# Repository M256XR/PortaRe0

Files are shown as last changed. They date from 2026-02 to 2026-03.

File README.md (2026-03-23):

# PortaRe0

Cubie A7Z SBCベースのクラムシェル型ポータブルPC（Cyberdeck）自作プロジェクト。

## 概要

| 項目 | 内容 |
|---|---|
| SBC | Cubie A7Z (Allwinner A733 / 8コア / WiFi6 / BT5.4) |
| ディスプレイ | 5.5" Sharp LS055R1SX04 (1440×2560 / MIPI DSI) |
| キーボード | カスタムPCB + Alps SKRPABE010 × 64キー / RP2040 / QMK |
| 入力 | 3DSスライドパッド（アナログスティック） |
| 電源 | LiPo 606090 (4200mAh) + BQ25895 充電IC + TPS61023 昇圧DC-DC ×2 |
| USBハブ | VL812 (USB 3.0 / 4ポート) |
| ストレージ | M.2 2230 NVMe SSD（PCIe Gen3 x1 / Cubie A7Z F0506-16-BGR経由） |
| オーディオ | MAX98357A × 2 (スピーカー I2S) / PCM5102A + TPA6132A2 (イヤホン DAC+アンプ) |
| MCU | RP2040 × 2（キーボード専用 / オーディオ専用） |
| PCB | 6層基板 / JLCPCB PCBA |
| 筐体 | 3Dプリンター自作（クラムシェル / 139×81mm） |

## 現在のフェーズ

**Phase 3: PCBレイアウト完了 → 発注準備完了（資金準備待ち）**

- [x] power シート（BQ25895 / TPS61023 ×2 / AP2112K）
- [x] usb_hub シート（VL812 / W25Q32 / J_EXT_C / J_EXT_A）
- [x] keyboard シート（RP2040 #1 / キーマトリクス / アナログスティック / LED）
- [x] audio シート（RP2040 #2 / MAX98357A ×2 / PCM5102A / TPA6132A2）
- [x] connectors シート（J_HDMI_CTRL / J_FAN）
- [x] hdmi_adapter シート（別基板 / Micro HDMI → FFC変換）
- [x] usb_adapter シート（別基板 / FPCスティフナー + USB-Cオス ×2）
- [x] m2_ssd シート（M.2 2230 NVMe / PCIe Gen3 x1 / RT9080 LDO）
- [x] ERC（HP系のみ残存 / 想定内）
- [x] ガーバー生成済み / CPL生成済み
- [ ] JLCPCB発注（資金準備後）

## ドキュメント

- [Claude/PROGRESS.md](./Claude/PROGRESS.md) - 現在の進捗・次のタスク
- [Claude/CLAUDE.md](./Claude/CLAUDE.md) - 仕様サマリ・セッション開始手順
- [Claude/specs/](./Claude/specs/) - ハードウェア詳細仕様（電源・キーボード・オーディオ・M.2）
- [bom/cyberdeck_bom.xlsx](./bom/cyberdeck_bom.xlsx) - BOM (Excel)
- [bom/cyberdeck_bom.csv](./bom/cyberdeck_bom.csv) - BOM (CSV)
- [keyboard/matrix.md](./keyboard/matrix.md) - キーマトリクス割り当て表
- [keyboard/info.json](./keyboard/info.json) - QMKレイアウト定義

## リポジトリ構成

```
kicad/PortaRe0/        KiCadプロジェクト（回路図・PCB）
kicad/PortaRe0_lib/    カスタムシンボル・フットプリント・3Dモデル
keyboard/              キーレイアウト・マトリクス定義・QMK設定
cad/                   筐体 3Dデータ（進行中）
docs/                  データシート
bom/                   BOM（xlsx / csv）
Claude/                設計ドキュメント・進捗ログ・セッションログ
```

## 主要部品 C番号一覧

| 部品 | 型番 | C番号 |
|---|---|---|
| 充電IC | BQ25895RTWR | C80200 |
| 昇圧DC-DC | TPS61023DRLR | C919459 |
| LDO 3.3V | AP2112K-3.3TRG1 | C51118 |
| USB HUBチップ | VL812-Q7 | C69417 |
| SPI Flash | W25Q32JVSSIQ | C82344 |
| MCU | RP2040 | C2040 |
| クリスタル（RP2040用 12MHz） | X322512MOB4SI | C70565 |
| クリスタル（VL812用 25MHz） | X322525MOB4SI | C9006 |
| I2Sアンプ | MAX98357AEWL+T | C2682619 |
| イヤホン用DAC | PCM5102APWR | C107671 |
| ヘッドフォンアンプ | TPA6132A2RTER | C69901 |
| USBパワースイッチ | TPS2042BDR | C138720 |
| USB ESD保護 | USBLC6-2SC6 | C7519 |
| キースイッチ | Alps SKRPABE010 | C115360 |
| ダイオード | 1N4148W | C2099 |
| MOSFET（レベル変換 / ファン制御） | BSS138 | C52895 |
| ショットキーダイオード（EN保護） | BAT54 | C466635 |
| FPCコネクタ（スティック用） | Molex 5034800440 | C3170007 |
| ZIF FPCコネクタ 24pin | FPC-05F-24PH20 | C2856805 |
| ZIF FPCコネクタ 16pin（PCIe） | FPC-05F-16PH20 | C2856801 |
| M.2ソケット（M-key 2230） | NASM0-S6701-TP40 | C367029 |
| LDO 3.3V（M.2用） | RT9080-33GJ5 | C841192 |
| USB-C レセプタクル（外部） | USB31-TYPE-C-FSABC | C2880583 |
| USB-A レセプタクル（外部） | HC-USB3.0-L168-WP | C7501850 |
| USB-C オス SMD（SBC接続） | 918-118A2021Y40000 | C168690 |

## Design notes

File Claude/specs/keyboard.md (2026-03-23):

# キーボード・入力・LED 詳細仕様

---

## キーボード・入力

- **RP2040 #1**（キーボード専用）C2040 / QMK対応
- スイッチ：Alps SKRPABE010（SMD タクタイル 4.2×3.2mm）× 62キー（C115360）+ 肩ボタン SKSCLDE010 × 2（C115362）= 計64キー / 手はんだ
- ダイオード：1N4148W（C2099）× 64個（キーマトリクス）
- アナログスティック：3DSスライドパッド / FPC 4ピン 1.0mmピッチ / VCC=3.3V直結OK
- FPCコネクタ：Molex 5034800440（C3170007）/ 4P 1.0mm ZIF ヒンジ式

### RP2040 #1 GPIO割り当て

| GPIO | 役割 |
|---|---|
| GP0〜GP8 | キーマトリクス COL（9本） |
| GP9〜GP16 | キーマトリクス ROW（8本） |
| GP17 | I2C_SCL（BQ25895） |
| GP18 | I2C_SDA（BQ25895） |
| GP19 | BQ_INT |
| GP20 | RP2040_EN（TPS61023 EN制御） |
| GP21 | LED_CHG（橙 / BQ25895 I2C読み） |
| GP22 | LED_FULL（緑 / BQ25895 I2C読み） |
| GP23 | LED_ACT（青 / OS動作表示） |
| GP24 | USB_VBUS_EN（TPS61023 #2 EN制御） |
| GP25 | SW_DET（電源ボタン検出 / 10kΩ分圧でVSYSを3.3V以下に変換） |
| GP26 | J_FAN PWM（BSS138 gate制御） |
| GP27（ADC1） | アナログスティック X |
| GP28（ADC2） | アナログスティック Y |
| GP29 | 予備 |

---

## LED

| LED | GPIO | C番号 | 色 | 役割 |
|-----|---|---|----|---|
| D1 | STAT直結 | C2286（KT-0603R） | 赤 | BQ25895 STAT端子直結 |
| D2 | GP23 | C19171394（YLED0603B） | 青 | LED_ACT（OS動作表示） |
| D3 | GP22 | C19273151（YLED0603G） | 緑 | LED_FULL（満充電） |
| D4 | GP21 | C19273153（YLED0603O） | 橙 | LED_CHG（充電中） |

- D2〜D4: Extended / 手はんだ対象
- 各LED: 330Ω直列抵抗 → GND / パッケージ: 0603

---

## キーマトリクス

- 構成：9COL × 8ROW / 計72セル（使用63 / 空き9）
- COL方向：縦 / ROW方向：横
- ダイオード向き：ROW → [>|] → SW → COL（カソードがSW側）
- 詳細：`keyboard/matrix.md`

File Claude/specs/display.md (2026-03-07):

# ディスプレイ・HDMIコントローラ基板 詳細仕様

---

## パネル

| 項目 | 仕様 |
|---|---|
| 型番 | Sharp LS055R1SX04（動作確認済み / session34） |
| サイズ | 5.5インチ |
| 解像度 | 1440 × 2560（縦向き） / PPI 約535 |
| 厚み | 約1.5mm（実測） |
| インターフェース | MIPI DSI 4レーン |
| 動作確認 | PC接続で正常表示確認済み（session34） |

---

## HDMIコントローラ基板

| 項目 | 仕様 |
|---|---|
### 付属ボード（動作確認済み）

| 項目 | 仕様 |
|---|---|
| 型番 | MIP-1000（Version 1.2） |
| 購入先 | AliExpress（LS055R1SX04とセット） |
| ブリッジチップ | TC358870XBG（Renesas / 旧Toshiba）/ HDMI 1.4 → MIPI DSI 4レーン |
| 映像入力 | HDMI（フルサイズ） |
| 給電 | Micro-B USB 5V |
| 対応解像度 | 1440×2560 固定（他解像度では正常動作しない） |
| リフレッシュレート | 1440×2560 @ 50Hz（60Hzは出力不可） |
| HDR | 非対応 |
| LED動作 | 映像検知時：青点滅 / 待機時：青ゆっくり点滅 / 映像出力時：緑点灯 |
| 明るさ調整 | ハードウェアボタン5〜6段階（明→暗→明のサイクル）/ RP2040制御不可 |
| リセットボタン | あり |
| スマホ接続 | 不可（解像度固定のため） |

### 組み込み候補ボード（VS-CXMIPI / Version 3.2）

| 項目 | 仕様 |
|---|---|
| 型番 | D000118-VS-CXMIPI-V1-50Hz（Version 3.2） |
| サイズ | 70 × 40 × 5mm（付属ボード65×65mmより小型） |
| ブリッジチップ | TC358870XBG（同じ） |
| 映像入力 | HDMI（フルサイズ） |
| 給電① | Mini USB 5V（給電専用・データラインなし） |
| 給電② | Micro USB 5V（給電専用・データラインなし） |
| 給電③ | **5V〜12V スルーホール（直はんだ可・組み込みに最適）** |
| MIPIコネクタ | 60pin ZIF（右上端） |
| テストポイント | RST / DA / CK / G / 3.3V / G / RX / TX / 5V |
| I2C | DA=SDA / CK=SCL（TC358870XBG設定用・RP2040制御の可能性あり） |
| UART | RX / TX（デバッグ用と推定） |
| サブMCU | N76E003A120（Nuvoton 8051コア）/ ボタン処理 + TC358870XBG初期化・輝度制御 |
| DA/CK | ICE_DAT/ICE_CLK（N76E003書き込み/デバッグピン）/ I2CではなくNuvoton専用 |
| RX/TX | UART 3.3Vロジック / 起動ログ・コマンド制御の可能性あり |
| 音声出力 | スピーカー + イヤホン出力あり |

---

## PortaRe0への組み込み方法

- HDMIコネクタを撤去し、24pin FPCコネクタを半田付け
- FFC経由でメインPCBの J_SBC_HDMI（C2856805）に接続
- Micro-B 5V給電 → FPC経由で5V_SYSから供給
- KiCad: hdmi_adapterシートで設計済み

---

## 注意事項

- スマホからのHDMI出力では正常表示不可（解像度固定のため）
- Cubie A7Zで1440×2560出力すれば問題なし
- VS-CXMIPI採用の場合、UART（RX/TX 3.3V）でコマンド制御できる可能性あり → 届いたらESP32-S3でTeraTerm接続してログ確認（ボーレート115200 or 9600）
- DA/CKはI2CではなくN76E003のICEデバッグピン（書き込み用）
- UART制御不可の場合はLEDドライバICのPWMピンを物理ハック（IC型番要確認）
- VS-CXMIPI採用の場合、5V〜12Vスルーホールから5V_SYS直接給電可能（Micro-Bコネクタ不要）
- 付属ボードを使う場合、明るさ調整ボタンを筐体外部に引き出す必要あり

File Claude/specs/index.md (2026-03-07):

# PortaRe0 ハードウェア仕様 索引

> 詳細仕様は各ファイルを参照。信頼優先順位: 原文ログ > specs/* > CLAUDE.md > PROGRESS.md

---

## 詳細ファイル一覧

| ファイル | 内容 |
|---|---|
| [power.md](./power.md) | 電源系・USBハブ・外部USBポート構成 |
| [keyboard.md](./keyboard.md) | キーボード・RP2040 #1 GPIO・アナログスティック・LED |
| [audio.md](./audio.md) | オーディオ・RP2040 #2 GPIO・信号フロー |
| [m2_ssd.md](./m2_ssd.md) | M.2 SSD・PCIe FPC接続・LDO |
| [display.md](./display.md) | ディスプレイ・HDMIコントローラ基板・組み込み方法 |

---

## コンポーネント概要

| カテゴリ | 部品 | 型番 / 備考 |
|---|---|---|
| SBC | Cubie A7Z | Allwinner A733 / 8コア / WiFi6 / BT5.4 |
| ディスプレイ | Sharp LS055R1SX04 | 5.5" / 1440×2560 / MIPI DSI 4レーン |
| 充電IC | BQ25895RTWR | C80200 / USB PD / バッテリー保護内蔵 |
| 昇圧DC-DC | TPS61023DRLR ×2 | C919459 / 5V_SYS / USB_5V_SYS |
| LDO 3.3V | AP2112K-3.3TRG1 | C51118 / RP2040用 |
| バッテリー | LiPo 606090 | 4200mAh / 3.7V |
| バッテリーコネクタ | BM06B-ACHFKS-GACN-ETF | JST ACH 6pin / 実装高1.43mm / 7.5A / DigiKey別途購入・手はんだ |
| USBハブ | VL812-Q7 | C69417 / USB3.0 4ポート |
| MCU | RP2040 ×2 | C2040 / #1=キーボード / #2=オーディオ |
| キースイッチ | Alps SKRPABE010 | C115360 / 63キー |
| アナログスティック | 3DSスライドパッド | FPC 4ピン 1.0mmピッチ |
| I2Sアンプ | MAX98357AEWL+T ×2 | C2682619 / スピーカー用 |
| イヤホンDAC | PCM5102APWR | C107671 |
| HPアンプ | TPA6132A2RTER | C69901 |
| M.2ソケット | NASM0-S6701-TP40 | C367029 / M-key / 2230 |
| M.2 LDO | RT9080-33GJ5 | C841192 / 3V3_M2レール |

---

## 筐体仕様

| 項目 | 仕様 |
|---|---|
| フォームファクタ | クラムシェル（ヒンジ構造） |
| ボトム外形 | 139 × 81 mm |
| PCBボード | 135 × 77 mm（各辺2mmクリアランス） |
| 素材 | 3Dプリンター（FDM or SLA） |
| ディスプレイ向き | 縦向きパネルを縦で使用 |

---

## PCB仕様

| 項目 | 仕様 |
|---|---|
| 層数 | 6層 |
| スタックアップ | F.Cu（COL+スイッチ）/ In1（GND）/ In2（IC配線+ROW）/ In3（電源ゾーン+IC配線）/ In4（GND）/ B.Cu（IC実装+IC配線+高速差動ペア） |
| 製造 | JLCPCB（PCBA込み） |
| HDMI 差動ペア | 90Ω / 等長配線 |
| USB3.0 SS 差動ペア | 90Ω |
| PCIe Gen3 差動ペア（M.2） | 90Ω / 等長配線 |

---

## 冷却

- 方式：パッシブ（ヒートパイプ + 小型ヒートシンク）
- ヒートパイプ：3mm厚フラット銅製 / SoC → 90度曲げ → バッテリー上端の隙間（幅16mm）を通過
- ヒートシンク：14×9×4mm 程度 × 4個
- ファン：RP2040 #1 GP26（FAN_PWM）→ BSS138 → J6（2pin JST PH）

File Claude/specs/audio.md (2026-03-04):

# オーディオ 詳細仕様

---

## 構成部品

- **RP2040 #2**（オーディオ専用）C2040 / VL812 DP4経由
- **MAX98357AEWL+T × 2**（C2682619）スピーカー用ステレオI2Sアンプ
- **PCM5102APWR**（C107671）イヤホン用ステレオDAC / TSSOP-20
- **TPA6132A2RTER**（C69901）イヤホン用ヘッドフォンアンプ / WQFN-16
- スピーカー：Nintendo Switch互換品 8Ω 20×14×4mm × 2個（L/R）
- イヤホンジャック：PJ-307C（C16684 / TH 5pin）

### イヤホンジャック ピン配置

| ピン | 接続 | 備考 |
|---|---|---|
| Pin1 | GND | Sleeve |
| Pin2 | HP_L | L Tip |
| Pin3 | NC | L SW（Pin2ペア） |
| Pin4 | HP_DET（GP6 + 100kΩ pull-up） | 未挿入=LOW / 挿入=HIGH |
| Pin5 | HP_R | R Ring |

---

## RP2040 #2 GPIO割り当て

| GPIO | 役割 |
|---|---|
| GP0 | I2S BCLK |
| GP1 | I2S LRCLK |
| GP2 | I2S SDIN |
| GP3 | SD_MODE制御（MAX98357A × 2 / U8=直結=Left / U15=220kΩ直列=Right） |
| GP4 | XSMT（PCM5102A ミュート制御） |
| GP5 | HP_EN（TPA6132A2 Enable） |
| GP6 | HP_DET（イヤホン挿入検出） |
| GP7〜GP29 | 予備 |

---

## 信号フロー

```
Cubie A7Z USB → VL812 DP4 → RP2040 #2（USB Audio）
RP2040 #2 I2S ─┬─→ MAX98357A × 2 → スピーカー L/R
                └─→ PCM5102A（DAC）→ TPA6132A2 → 3.5mmジャック
GP3: スピーカーON/OFF（SD_MODE）
GP4: DAC ミュート（XSMT）
GP5: HPアンプ Enable
GP6: 挿入検出 → GP3/GP4/GP5をソフト制御
```

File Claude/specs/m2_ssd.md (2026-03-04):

# M.2 SSD 詳細仕様

---

## 構成

- **M.2ソケット**: NASM0-S6701-TP40（C367029）M-key / 2230対応
- **PCIeインターフェース**: Cubie A7Z F0506-16-BGR（16pin 0.5mm FPC / RPi5互換）→ PCIe Gen3 x1
- **FPCコネクタ**: FPC-05F-16PH20（C2856801）16pin 0.5mm ZIF
- **電源**: RT9080-33GJ5（C841192）600mA LDO / 5V_SYS → 3V3_M2（AP2112K とは別レール）

---

## FPC → M.2 ピン接続

| FPC Pin | 信号 | 接続 | M.2 Pin |
|---|---|---|---|
| Pin2 | PCIE_TX_P | → 100nF → | Pin43 (PERp0) |
| Pin3 | PCIE_TX_N | → 100nF → | Pin41 (PERn0) |
| Pin5 | PCIE_RX_P | 直結 | Pin49 (PETp0) |
| Pin6 | PCIE_RX_N | 直結 | Pin47 (PETn0) |
| Pin8 | PCIE_REFCLK_P | 直結 | Pin55 (REFCLKP) |
| Pin9 | PCIE_REFCLK_N | 直結 | Pin53 (REFCLKN) |
| Pin11 | PCIE_PERST_N | 直結 | Pin50 (PERST#) |
| Pin12 | PCIE_CLKREQ_N | + 10kΩ → 3V3_M2 | Pin52 (CLKREQ#) |
| Pin13 | PCIE_WAKE_N | + 10kΩ → 3V3_M2 | Pin54 (PEWAKE#) |

- 3V3_M2 → M.2 Pin: 2, 4, 12, 14, 16, 18, 70, 72, 74
- M.2 Pin 42/44/46/48/56 = NC（SATAピン / PCIe x1では未使用）

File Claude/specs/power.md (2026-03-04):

# 電源・USBハブ 詳細仕様

---

## 電源系

| 部品 | 型番 | C番号 | 役割 |
|---|---|---|---|
| 充電IC | BQ25895RTWR | C80200 | USB PD充電 / バッテリー保護内蔵 |
| 昇圧DC-DC #1 | TPS61023DRLR | C919459 | LiPo → 5V_SYS（システム用） |
| 昇圧DC-DC #2 | TPS61023DRLR | C919459 | LiPo → USB_5V_SYS（外部USBポートVBUS専用） |
| LDO | AP2112K-3.3TRG1 | C51118 | 5V → 3.3V（RP2040用） |
| バッテリー | LiPo 606090 | — | 4200mAh / 3.7V |

### 電源フロー

```
USB-C (充電) → BQ25895 → LiPo 4.2V
LiPo SYS出力 → TPS61023 #1 → 5V_SYS → Cubie A7Z / VL812 / HDMIコントローラ基板
LiPo SYS出力 → TPS61023 #2 → USB_5V_SYS → 外部USBポートVBUS（RP2040 #1 GP24でEN制御）
5V_SYS → AP2112K → 3.3V（RP2040用）
5V_SYS → RT9080 → 3V3_M2（M.2 SSD用）
```

> 注意: BQ25895 SYSラインは最大5〜6A → PCBパターン極太必須

### 電源スイッチ

- 起動：モーメンタリボタン（SKSCLBE010 C115361）→ TPS61023 EN ピン High
- 通常OFF：SBC GPIO → EN Low（shutdown フック）
- 緊急キル：MSK12C02（C431540）スライドSW → EN 強制 Low

---

## USBハブ（VL812）

- **VL812-Q7**（QFN-76-EP 9x9）C69417
- 外付け：W25Q32JVSSIQ SPI Flash（C82344）/ 25MHz水晶 X322525MOB4SI（C9006）/ SSREXT 6.04kΩ

### USB接続構成

```
Cubie A7Z USB-C (USB3.0) → VL812 upstream
VL812 downstream 1 → 外部USB-C レセプタクル（TPS2042BDR / USBLC6-2SC6）
VL812 downstream 2 → 外部USB-A レセプタクル（TPS2042BDR / USBLC6-2SC6）
VL812 downstream 3 → RP2040 #1（キーボード）
VL812 downstream 4 → RP2040 #2（オーディオ）
Cubie A7Z USB-C (USB2.0) → BQ25895（充電入力 / 刻印:PWR）
Cubie A7Z Micro HDMI → HDMIコントローラ基板
```

### 外部USBポート電源構成

- TPS2042BDR（C138720）: VL812 /USBHPE制御 / /USBHOC過電流検知
- USBLC6-2SC6（C7519）: Port1/2各1個 ESD保護
- 外部VBUS専用 TPS61023 #2（USB_5V_SYS）: RP2040 #1 GP24で制御
- 注意: 外部USBポートはデータ転送・小型デバイス用（HDD等大電流機器は非推奨）

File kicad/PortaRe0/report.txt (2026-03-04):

情報: シンボル 'C1:Capacitor_SMD:C_0603_1608Metric' を処理中です。
情報: シンボル 'C2:Capacitor_SMD:C_0603_1608Metric' を処理中です。
情報: シンボル 'C3:Capacitor_SMD:C_0603_1608Metric' を処理中です。
情報: シンボル 'C4:Capacitor_SMD:C_0603_1608Metric' を処理中です。
情報: シンボル 'C5:Capacitor_SMD:C_0603_1608Metric' を処理中です。
情報: シンボル 'C6:Capacitor_SMD:C_0603_1608Metric' を処理中です。
情報: シンボル 'C7:Capacitor_SMD:C_0603_1608Metric' を処理中です。
情報: シンボル 'C8:Capacitor_SMD:C_0603_1608Metric' を処理中です。
情報: シンボル 'C9:Capacitor_SMD:C_0603_1608Metric' を処理中です。
情報: シンボル 'C10:Capacitor_SMD:C_0603_1608Metric' を処理中です。
情報: シンボル 'C11:Capacitor_SMD:C_0603_1608Metric' を処理中です。
情報: シンボル 'C12:Capacitor_SMD:C_0603_1608Metric' を処理中です。
情報: シンボル 'C13:Capacitor_SMD:C_0603_1608Metric' を処理中です。
情報: シンボル 'C14:Capacitor_SMD:C_0603_1608Metric' を処理中です。
情報: シンボル 'C15:Capacitor_SMD:C_0603_1608Metric' を処理中です。
情報: シンボル 'C16:Capacitor_SMD:C_0603_1608Metric' を処理中です。
情報: シンボル 'C17:Capacitor_SMD:C_0603_1608Metric' を処理中です。
情報: シンボル 'C18:Capacitor_SMD:C_0603_1608Metric' を処理中です。
情報: シンボル 'C19:Capacitor_SMD:C_0603_1608Metric' を処理中です。
情報: シンボル 'C20:Capacitor_SMD:C_0603_1608Metric' を処理中です。
情報: シンボル 'C21:Capacitor_SMD:C_0603_1608Metric' を処理中です。
情報: シンボル 'C22:Capacitor_SMD:C_0603_1608Metric' を処理中です。
情報: シンボル 'C23:Capacitor_SMD:C_0603_1608Metric' を処理中です。
情報: シンボル 'C24:Capacitor_SMD:C_0603_1608Metric' を処理中です。
情報: シンボル 'C25:Capacitor_SMD:C_0603_1608Metric' を処理中です。
情報: シンボル 'C26:Capacitor_SMD:C_0603_1608Metric' を処理中です。
情報: シンボル 'C27:Capacitor_SMD:C_0603_1608Metric' を処理中です。
情報: シンボル 'C28:Capacitor_SMD:C_0603_1608Metric' を処理中です。
情報: シンボル 'C29:Capacitor_SMD:C_0603_1608Metric' を処理中です。
情報: シンボル 'C30:Capacitor_SMD:C_0603_1608Metric' を処理中です。
情報: シンボル 'C31:Capacitor_SMD:C_0603_1608Metric' を処理中です。
情報: シンボル 'C32:Capacitor_SMD:C_0603_1608Metric' を処理中です。
情報: シンボル 'C33:Capacitor_SMD:C_0603_1608Metric' を処理中です。
情報: シンボル 'C34:Capacitor_SMD:C_0603_1608Metric' を処理中です。
情報: シンボル 'C36:Capacitor_SMD:C_0603_1608Metric' を処理中です。
情報: シンボル 'C38:Capacitor_SMD:C_0603_1608Metric' を処理中です。
情報: シンボル 'C41:Capacitor_SMD:C_0603_1608Metric' を処理中です。
情報: シンボル 'C42:Capacitor_SMD:C_0603_1608Metric' を処理中です。
情報: シンボル 'C44:Capacitor_SMD:C_0603_1608Metric' を処理中です。
情報: シンボル 'C46:Capacitor_SMD:C_0603_1608Metric' を処理中です。
情報: シンボル 'C47:Capacitor_SMD:C_0603_1608Metric' を処理中です。
情報: シンボル 'C48:Capacitor_SMD:C_0603_1608Metric' を処理中です。
情報: シンボル 'C49:Capacitor_SMD:C_0603_1608Metric' を処理中です。
情報: シンボル 'C50:Capacitor_SMD:C_0603_1608Metric' を処理中です。
情報: シンボル 'C51:Capacitor_SMD:C_0603_1608Metric' を処理中です。
情報: シンボル 'C52:Capacitor_SMD:C_0603_1608Metric' を処理中です。
情報: シンボル 'C53:Capacitor_SMD:C_0603_1608Metric' を処理中です。
情報: シンボル 'C54:Capacitor_SMD:C_0603_1608Metric' を処理中です。
情報: シンボル 'C55:Capacitor_SMD:C_0603_1608Metric' を処理中です。
情報: シンボル 'C56:Capacitor_SMD:C_0603_1608Metric' を処理中です。
情報: シンボル 'C57:Capacitor_SMD:C_0603_1608Metric' を処理中です。
情報: シンボル 'C58:Capacitor_SMD:C_0603_1608Metric' を処理中です。
情報: シンボル 'C59:Capacitor_SMD:C_0603_1608Metric' を処理中です。
情報: シンボル 'C60:Capacitor_SMD:C_0603_1608Metric' を処理中です。
情報: シンボル 'C61:Capacitor_SMD:C_0603_1608Metric' を処理中です。
情報: シンボル 'C62:Capacitor_SMD:C_0603_1608Metric' を処理中です。
情報: シンボル 'C63:Capacitor_SMD:C_0603_1608Metric' を処理中です。
情報: シンボル 'C64:Capacitor_SMD:C_0603_1608Metric' を処理中です。
情報: シンボル 'C65:Capacitor_SMD:C_0603_1608Metric' を処理中です。
情報: シンボル 'C66:Capacitor_SMD:C_0603_1608Metric' を処理中です。
情報: シンボル 'C67:Capacitor_SMD:C_0603_1608Metric' を処理中です。
情報: シンボル 'C68:Capacitor_SMD:C_0603_1608Metric' を処理中です。
情報: シンボル 'C69:Capacitor_SMD:C_0603_1608Metric' を処理中です。
情報: シンボル 'C70:Capacitor_SMD:C_0603_1608Metric' を処理中です。
情報: シンボル 'C71:Capacitor_SMD:C_0603_1608Metric' を処理中です。
情報: シンボル 'C72:Capacitor_SMD:C_0603_1608Metric' を処理中です。
情報: シンボル 'C73:Capacitor_SMD:C_0603_1608Metric' を処理中です。
情報: シンボル 'C74:Capacitor_SMD:C_0603_1608Metric' を処理中です。
情報: シンボル 'C75:Capacitor_SMD:C_0603_1608Metric' を処理中です。
情報: シンボル 'C76:Capacitor_SMD:C_0603_1608Metric' を処理中です。
情報: シンボル 'C77:Capacitor_SMD:C_0603_1608Metric' を処理中です。
情報: シンボル 'C78:Capacitor_SMD:C_0603_1608Metric' を処理中です。
情報: シンボル 'C79:Capacitor_SMD:C_0603_1608Metric' を処理中です。
情報: シンボル 'C80:Capacitor_SMD:C_0603_1608Metric' を処理中です。
情報: シンボル 'C81:Capacitor_SMD:C_0603_1608Metric' を処理中です。
情報: シンボル 'C82:Capacitor_SMD:C_0603_1608Metric' を処理中です。
情報: シンボル 'C83:Capacitor_SMD:C_0603_1608Metric' を処理中です。
情報: シンボル 'C84:Capacitor_SMD:C_0603_1608Metric' を処理中です。
情報: シンボル 'C85:Capacitor_SMD:C_0603_1608Metric' を処理中です。
情報: シンボル 'C86:Capacitor_SMD:C_0603_1608Metric' を処理中です。
情報: シンボル 'C87:Capacitor_SMD:C_0603_1608Metric' を処理中です。
情報: シンボル 'C88:Capacitor_SMD:C_0603_1608Metric' を処理中です。
情報: シンボル 'C89:Capacitor_SMD:C_0603_1608Metric' を処理中です。
情報: シンボル 'C90:Capacitor_SMD:C_0603_1608Metric' を処理中です。
情報: シンボル 'C91:Capacitor_SMD:C_0603_1608Metric' を処理中です。
情報: シンボル 'C92:Capacitor_SMD:C_0603_1608Metric' を処理中です。
情報: シンボル 'C93:Capacitor_SMD:C_0603_1608Metric' を処理中です。
情報: シンボル 'C94:Capacitor_SMD:C_0603_1608Metric' を処理中です。
情報: シンボル 'C95:Capacitor_SMD:C_0603_1608Metric' を処理中です。
情報: シンボル 'C96:Capacitor_SMD:C_0603_1608Metric' を処理中です。
情報: シンボル 'C97:Capacitor_SMD:C_0603_1608Metric' を処理中です。
情報: シンボル 'C98:Capacitor_SMD:C_0603_1608Metric' を処理中です。
情報: シンボル 'C99:Capacitor_SMD:C_0603_1608Metric' を処理中です。
情報: シンボル 'C100:Capacitor_SMD:C_0603_1608Metric' を処理中です。
情報: シンボル 'C101:Capacitor_SMD:C_0603_1608Metric' を処理中です。
情報: シンボル 'C102:Capacitor_SMD:C_0603_1608Metric' を処理中です。
情報: シンボル 'C103:Capacitor_SMD:C_0603_1608Metric' を処理中です。
情報: シンボル 'C104:Capacitor_SMD:C_0603_1608Metric' を処理中です。
情報: シンボル 'C105:Capacitor_SMD:C_0603_1608Metric' を処理中です。
情報: シンボル 'C106:Capacitor_SMD:C_0603_1608Metric' を処理中です。
情報: シンボル 'C107:Capacitor_Tantalum_SMD:CP_EIA-3528-21_Kemet-B_HandSolder' を処理中です。
情報: シンボル 'C108:Capacitor_Tantalum_SMD:CP_EIA-3528-21_Kemet-B_HandSolder' を処理中です。
情報: シンボル 'C109:Capacitor_SMD:C_0603_1608Metric' を処理中です。
情報: シンボル 'C110:Capacitor_SMD:C_0603_1608Metric' を処理中です。
情報: シンボル 'C111:Capacitor_SMD:C_0603_1608Metric' を処理中です。
情報: シンボル 'C112:Capacitor_SMD:C_0603_1608Metric' を処理中です。
情報: シンボル 'C113:Capacitor_SMD:C_0603_1608Metric' を処理中です。
情報: シンボル 'C114:Capacitor_SMD:C_0603_1608Metric' を処理中です。
情報: シンボル 'C115:Capacitor_SMD:C_0603_1608Metric' を処理中です。
情報: シンボル 'C116:Capacitor_SMD:C_0603_1608Metric' を処理中です。
情報: シンボル 'C117:Capacitor_SMD:C_0603_1608Metric' を処理中です。
情報: シンボル 'C118:Capacitor_SMD:C_0603_1608Metric' を処理中です。
情報: シンボル 'C119:Capacitor_SMD:C_0603_1608Metric' を処理中です。
情報: シンボル 'CN1:PortaRe0:CONN-SMD_67P-P0.50-V_NXSM0-S67XX-XX40' を処理中です。
情報: シンボル 'D1:LED_SMD:LED_0603_1608Metric' を処理中です。
情報: シンボル 'D2:LED_SMD:LED_0603_1608Metric' を処理中です。
情報: シンボル 'D3:LED_SMD:LED_0603_1608Metric' を処理中です。
情報: シンボル 'D4:LED_SMD:LED_0603_1608Metric' を処理中です。
情報: シンボル 'D5:PortaRe0:SOT-23-6_L2.9-W1.6-P0.95-LS2.8-BL' を処理中です。
情報: シンボル 'D6:PortaRe0:SOT-23-6_L2.9-W1.6-P0.95-LS2.8-BL' を処理中です。
情報: シンボル 'D7:PortaRe0:SOT-23-3_L2.9-W1.4-P1.90-LS2.6-BR' を処理中です。
情報: シンボル 'D8:PortaRe0:SOT-23-3_L2.9-W1.4-P1.90-LS2.6-BR' を処理中です。
情報: シンボル 'D9:PortaRe0:SOD-123_L2.8-W1.8-LS3.7-RD' を処理中です。
情報: シンボル 'FPC1:PortaRe0:FPC-SMD_24P-P0.50_FPC-05F-24PH20' を処理中です。
情報: シンボル 'FPC2:PortaRe0:FPC-SMD_24P-P0.50_FPC-05F-24PH20' を処理中です。
情報: シンボル 'FPC4:PortaRe0:FPC-SMD_24P-P0.50_FPC-05F-24PH20' を処理中です。
情報: シンボル 'FPC5:PortaRe0:FPC-SMD_24P-P0.50_FPC-05F-24PH20' を処理中です。
情報: シンボル 'FPC6:PortaRe0:FPC-SMD_16P-P0.50_FPC-05F-16PH20' を処理中です。
情報: シンボル 'J1:PortaRe0:FPC-SMD_5034800400' を処理中です。
情報: シンボル 'Y2:PortaRe0:CRYSTAL-SMD_4P-L3.2-W2.5-BL' を処理中です。
情報: シンボル 'Y4:PortaRe0:CRYSTAL-SMD_4P-L3.2-W2.5-BL' を処理中です。
情報: シンボル 'J2:PortaRe0:CONN-TH_S2B-PH-K-S-LF-SN' を処理中です。
情報: シンボル 'J3:PortaRe0:CONN-TH_S2B-PH-K-S-LF-SN' を処理中です。
情報: シンボル 'J4:PortaRe0:CONN-TH_S8B-PH-K-S-LF-SN' を処理中です。
情報: シンボル 'J6:PortaRe0:CONN-TH_S2B-PH-K-S-LF-SN' を処理中です。
情報: シンボル 'J9:PortaRe0:AUDIO-TH_PJ307C' を処理中です。
情報: シンボル 'K_SW1:PortaRe0:KEY-SMD_4P-SKSCLXX010' を処理中です。
情報: シンボル 'K_SW2:PortaRe0:KEY-SMD_4P-SKSCLXX010' を処理中です。
情報: シンボル 'K_SW3:PortaRe0:KEY-SMD_4P-L4.2-W3.2-P2.20-LS4.6' を処理中です。
情報: シンボル 'K_SW4:PortaRe0:KEY-SMD_4P-L4.2-W3.2-P2.20-LS4.6' を処理中です。
情報: シンボル 'K_SW5:PortaRe0:KEY-SMD_4P-L4.2-W3.2-P2.20-LS4.6' を処理中です。
情報: シンボル 'K_SW6:PortaRe0:KEY-SMD_4P-L4.2-W3.2-P2.20-LS4.6' を処理中です。
情報: シンボル 'K_SW7:PortaRe0:KEY-SMD_4P-L4.2-W3.2-P2.20-LS4.6' を処理中です。
情報: シンボル 'K_SW8:PortaRe0:KEY-SMD_4P-L4.2-W3.2-P2.20-LS4.6' を処理中です。
情報: シンボル 'K_SW9:PortaRe0:KEY-SMD_4P-L4.2-W3.2-P2.20-LS4.6' を処理中です。
情報: シンボル 'K_SW10:PortaRe0:KEY-SMD_4P-L4.2-W3.2-P2.20-LS4.6' を処理中です。
情報: シンボル 'K_SW11:PortaRe0:KEY-SMD_4P-L4.2-W3.2-P2.20-LS4.6' を処理中です。
情報: シンボル 'K_SW12:PortaRe0:KEY-SMD_4P-L4.2-W3.2-P2.20-LS4.6' を処理中です。
情報: シンボル 'K_SW13:PortaRe0:KEY-SMD_4P-L4.2-W3.2-P2.20-LS4.6' を処理中です。
情報: シンボル 'K_SW14:PortaRe0:KEY-SMD_4P-L4.2-W3.2-P2.20-LS4.6' を処理中です。
情報: シンボル 'K_SW15:PortaRe0:KEY-SMD_4P-L4.2-W3.2-P2.20-LS4.6' を処理中です。
情報: シンボル 'K_SW16:PortaRe0:KEY-SMD_4P-L4.2-W3.2-P2.20-LS4.6' を処理中です。
情報: シンボル 'K_SW17:PortaRe0:KEY-SMD_4P-L4.2-W3.2-P2.20-LS4.6' を処理中です。
情報: シンボル 'K_SW18:PortaRe0:KEY-SMD_4P-L4.2-W3.2-P2.20-LS4.6' を処理中です。
情報: シンボル 'K_SW19:PortaRe0:KEY-SMD_4P-L4.2-W3.2-P2.20-LS4.6' を処理中です。
情報: シンボル 'K_SW20:PortaRe0:KEY-SMD_4P-L4.2-W3.2-P2.20-LS4.6' を処理中です。
情報: シンボル 'K_SW21:PortaRe0:KEY-SMD_4P-L4.2-W3.2-P2.20-LS4.6' を処理中です。
情報: シンボル 'K_SW22:PortaRe0:KEY-SMD_4P-L4.2-W3.2-P2.20-LS4.6' を処理中です。
情報: シンボル 'K_SW23:PortaRe0:KEY-SMD_4P-L4.2-W3.2-P2.20-LS4.6' を処理中です。
情報: シンボル 'K_SW24:PortaRe0:KEY-SMD_4P-L4.2-W3.2-P2.20-LS4.6' を処理中です。
情報: シンボル 'K_SW25:PortaRe0:KEY-SMD_4P-L4.2-W3.2-P2.20-LS4.6' を処理中です。
情報: シンボル 'K_SW26:PortaRe0:KEY-SMD_4P-L4.2-W3.2-P2.20-LS4.6' を処理中です。
情報: シンボル 'K_SW27:PortaRe0:KEY-SMD_4P-L4.2-W3.2-P2.20-LS4.6' を処理中です。
情報: シンボル 'K_SW28:PortaRe0:KEY-SMD_4P-L4.2-W3.2-P2.20-LS4.6' を処理中です。
情報: シンボル 'K_SW29:PortaRe0:KEY-SMD_4P-L4.2-W3.2-P2.20-LS4.6' を処理中です。
情報: シンボル 'K_SW30:PortaRe0:KEY-SMD_4P-L4.2-W3.2-P2.20-LS4.6' を処理中です。
情報: シンボル 'K_SW31:PortaRe0:KEY-SMD_4P-L4.2-W3.2-P2.20-LS4.6' を処理中です。
情報: シンボル 'K_SW32:PortaRe0:KEY-SMD_4P-L4.2-W3.2-P2.20-LS4.6' を処理中です。
情報: シンボル 'K_SW33:PortaRe0:KEY-SMD_4P-L4.2-W3.2-P2.20-LS4.6' を処理中です。
情報: シンボル 'K_SW34:PortaRe0:KEY-SMD_4P-L4.2-W3.2-P2.20-LS4.6' を処理中です。
情報: シンボル 'K_SW35:PortaRe0:KEY-SMD_4P-L4.2-W3.2-P2.20-LS4.6' を処理中です。
情報: シンボル 'K_SW36:PortaRe0:KEY-SMD_4P-L4.2-W3.2-P2.20-LS4.6' を処理中です。
情報: シンボル 'K_SW37:PortaRe0:KEY-SMD_4P-L4.2-W3.2-P2.20-LS4.6' を処理中です。
情報: シンボル 'K_SW38:PortaRe0:KEY-SMD_4P-L4.2-W3.2-P2.20-LS4.6' を処理中です。
情報: シンボル 'K_SW39:PortaRe0:KEY-SMD_4P-L4.2-W3.2-P2.20-LS4.6' を処理中です。
情報: シンボル 'K_SW40:PortaRe0:KEY-SMD_4P-L4.2-W3.2-P2.20-LS4.6' を処理中です。
情報: シンボル 'K_SW41:PortaRe0:KEY-SMD_4P-L4.2-W3.2-P2.20-LS4.6' を処理中です。
情報: シンボル 'K_SW42:PortaRe0:KEY-SMD_4P-L4.2-W3.2-P2.20-LS4.6' を処理中です。
情報: シンボル 'K_SW43:PortaRe0:KEY-SMD_4P-L4.2-W3.2-P2.20-LS4.6' を処理中です。
情報: シンボル 'K_SW44:PortaRe0:KEY-SMD_4P-L4.2-W3.2-P2.20-LS4.6' を処理中です。
情報: シンボル 'K_SW45:PortaRe0:KEY-SMD_4P-L4.2-W3.2-P2.20-LS4.6' を処理中です。
情報: シンボル 'K_SW46:PortaRe0:KEY-SMD_4P-L4.2-W3.2-P2.20-LS4.6' を処理中です。
情報: シンボル 'K_SW47:PortaRe0:KEY-SMD_4P-L4.2-W3.2-P2.20-LS4.6' を処理中です。
情報: シンボル 'K_SW48:PortaRe0:KEY-SMD_4P-L4.2-W3.2-P2.20-LS4.6' を処理中です。
情報: シンボル 'K_SW49:PortaRe0:KEY-SMD_4P-L4.2-W3.2-P2.20-LS4.6' を処理中です。
情報: シンボル 'K_SW50:PortaRe0:KEY-SMD_4P-L4.2-W3.2-P2.20-LS4.6' を処理中です。
情報: シンボル 'K_SW51:PortaRe0:KEY-SMD_4P-L4.2-W3.2-P2.20-LS4.6' を処理中です。
情報: シンボル 'K_SW52:PortaRe0:KEY-SMD_4P-L4.2-W3.2-P2.20-LS4.6' を処理中です。
情報: シンボル 'K_SW53:PortaRe0:KEY-SMD_4P-L4.2-W3.2-P2.20-LS4.6' を処理中です。
情報: シンボル 'K_SW54:PortaRe0:KEY-SMD_4P-L4.2-W3.2-P2.20-LS4.6' を処理中です。
情報: シンボル 'K_SW55:PortaRe0:KEY-SMD_4P-L4.2-W3.2-P2.20-LS4.6' を処理中です。
情報: シンボル 'K_SW56:PortaRe0:KEY-SMD_4P-L4.2-W3.2-P2.20-LS4.6' を処理中です。
情報: シンボル 'K_SW57:PortaRe0:KEY-SMD_4P-L4.2-W3.2-P2.20-LS4.6' を処理中です。
情報: シンボル 'K_SW58:PortaRe0:KEY-SMD_4P-L4.2-W3.2-P2.20-LS4.6' を処理中です。
情報: シンボル 'K_SW59:PortaRe0:KEY-SMD_4P-L4.2-W3.2-P2.20-LS4.6' を処理中です。
情報: シンボル 'K_SW60:PortaRe0:KEY-SMD_4P-L4.2-W3.2-P2.20-LS4.6' を処理中です。
情報: シンボル 'K_SW61:PortaRe0:KEY-SMD_4P-L4.2-W3.2-P2.20-LS4.6' を処理中です。
情報: シンボル 'K_SW62:PortaRe0:KEY-SMD_4P-L4.2-W3.2-P2.20-LS4.6' を処理中です。
情報: シンボル 'K_SW63:PortaRe0:KEY-SMD_4P-L4.2-W3.2-P2.20-LS4.6' を処理中です。
情報: シンボル 'K_SW64:PortaRe0:KEY-SMD_4P-L4.2-W3.2-P2.20-LS4.6' を処理中です。
情報: シンボル 'K_SW65:PortaRe0:KEY-SMD_4P-L4.2-W3.2-P2.20-LS4.6' を処理中です。
情報: シンボル 'L1:PortaRe0:IND-SMD_L4.4-W4.2' を処理中です。
情報: シンボル 'L2:PortaRe0:IND-SMD_L3.2-W2.5_CKST322512-2.2UH' を処理中です。
情報: シンボル 'L3:PortaRe0:IND-SMD_L4.7-W4.2' を処理中です。
情報: シンボル 'L4:PortaRe0:IND-SMD_L3.2-W2.5_CKST322512-2.2UH' を処理中です。
情報: シンボル 'Q1:PortaRe0:SOT-23-3_L2.9-W1.6-P1.90-LS2.8-BR' を処理中です。
情報: シンボル 'R1:Resistor_SMD:R_0603_1608Metric' を処理中です。
情報: シンボル 'R2:Resistor_SMD:R_0603_1608Metric' を処理中です。
情報: シンボル 'R3:Resistor_SMD:R_0603_1608Metric' を処理中です。
情報: シンボル 'R4:Resistor_SMD:R_0603_1608Metric' を処理中です。
情報: シンボル 'R5:Resistor_SMD:R_0603_1608Metric' を処理中です。
情報: シンボル 'R6:Resistor_SMD:R_0603_1608Metric' を処理中です。
情報: シンボル 'R7:Resistor_SMD:R_0603_1608Metric' を処理中です。
情報: シンボル 'R8:Resistor_SMD:R_0603_1608Metric' を処理中です。
情報: シンボル 'R9:Resistor_SMD:R_0603_1608Metric' を処理中です。
情報: シンボル 'R10:Resistor_SMD:R_0603_1608Metric' を処理中です。
情報: シンボル 'R11:Resistor_SMD:R_0603_1608Metric' を処理中です。
情報: シンボル 'R12:Resistor_SMD:R_0603_1608Metric' を処理中です。
情報: シンボル 'R13:Resistor_SMD:R_0603_1608Metric' を処理中です。
情報: シンボル 'R14:Resistor_SMD:R_0603_1608Metric' を処理中です。
情報: シンボル 'R15:Resistor_SMD:R_0603_1608Metric' を処理中です。
情報: シンボル 'R16:Resistor_SMD:R_0603_1608Metric' を処理中です。
情報: シンボル 'R17:Resistor_SMD:R_0603_1608Metric' を処理中です。
情報: シンボル 'R18:Resistor_SMD:R_0603_1608Metric' を処理中です。
情報: シンボル 'R19:Resistor_SMD:R_0603_1608Metric' を処理中です。
情報: シンボル 'R20:Resistor_SMD:R_0603_1608Metric' を処理中です。
情報: シンボル 'R21:Resistor_SMD:R_0603_1608Metric' を処理中です。
情報: シンボル 'R22:Resistor_SMD:R_0603_1608Metric' を処理中です。
情報: シンボル 'R23:Resistor_SMD:R_0603_1608Metric' を処理中です。
情報: シンボル 'R24:Resistor_SMD:R_0603_1608Metric' を処理中です。
情報: シンボル 'R25:Resistor_SMD:R_0603_1608Metric' を処理中です。
情報: シンボル 'R26:Resistor_SMD:R_0603_1608Metric' を処理中です。
情報: シンボル 'R27:Resistor_SMD:R_0603_1608Metric' を処理中です。
情報: シンボル 'R28:Resistor_SMD:R_0603_1608Metric' を処理中です。
情報: シンボル 'R29:Resistor_SMD:R_0603_1608Metric' を処理中です。
情報: シンボル 'R30:Resistor_SMD:R_0603_1608Metric' を処理中です。
情報: シンボル 'R31:Resistor_SMD:R_0603_1608Metric' を処理中です。
情報: シンボル 'R32:Resistor_SMD:R_0603_1608Metric' を処理中です。
情報: シンボル 'R33:Resistor_SMD:R_0603_1608Metric' を処理中です。
情報: シンボル 'R34:Resistor_SMD:R_0603_1608Metric' を処理中です。
情報: シンボル 'R35:Resistor_SMD:R_0603_1608Metric' を処理中です。
情報: シンボル 'R36:Resistor_SMD:R_0603_1608Metric' を処理中です。
情報: シンボル 'R37:Resistor_SMD:R_0603_1608Metric' を処理中です。
情報: シンボル 'R38:Resistor_SMD:R_0603_1608Metric' を処理中です。
情報: シンボル 'R39:Resistor_SMD:R_0603_1608Metric' を処理中です。
情報: シンボル 'R40:Resistor_SMD:R_0603_1608Metric' を処理中です。
情報: シンボル 'R41:Resistor_SMD:R_0603_1608Metric' を処理中です。
情報: シンボル 'R42:Resistor_SMD:R_0603_1608Metric' を処理中です。
情報: シンボル 'R43:Resistor_SMD:R_0603_1608Metric' を処理中です。
情報: シンボル 'R44:Resistor_SMD:R_0603_1608Metric' を処理中です。
情報: シンボル 'R45:Resistor_SMD:R_0603_1608Metric' を処理中です。
情報: シンボル 'R46:Resistor_SMD:R_0603_1608Metric' を処理中です。
情報: シンボル 'R47:Resistor_SMD:R_0603_1608Metric' を処理中です。
情報: シンボル 'R48:Resistor_SMD:R_0603_1608Metric' を処理中です。
情報: シンボル 'R49:Resistor_SMD:R_0603_1608Metric' を処理中です。
情報: シンボル 'R50:Resistor_SMD:R_0603_1608Metric' を処理中です。
情報: シンボル 'R51:Resistor_SMD:R_0603_1608Metric' を処理中です。
情報: シンボル 'R52:Resistor_SMD:R_0603_1608Metric' を処理中です。
情報: シンボル 'R53:Resistor_SMD:R_0603_1608Metric' を処理中です。
情報: シンボル 'R54:Resistor_SMD:R_0603_1608Metric' を処理中です。
情報: シンボル 'R55:Resistor_SMD:R_0603_1608Metric' を処理中です。
情報: シンボル 'R56:Resistor_SMD:R_0603_1608Metric' を処理中です。
情報: シンボル 'R57:Resistor_SMD:R_0603_1608Metric' を処理中です。
情報: シンボル 'R58:Resistor_SMD:R_0603_1608Metric' を処理中です。
情報: シンボル 'R59:Resistor_SMD:R_0603_1608Metric' を処理中です。
情報: シンボル 'R60:Resistor_SMD:R_0603_1608Metric' を処理中です。
情報: シンボル 'R61:Resistor_SMD:R_0603_1608Metric' を処理中です。
情報: シンボル 'R62:Resistor_SMD:R_0603_1608Metric' を処理中です。
情報: シンボル 'R63:Resistor_SMD:R_0603_1608Metric' を処理中です。
情報: シンボル 'R64:Resistor_SMD:R_0603_1608Metric' を処理中です。
情報: シンボル 'RP2040#1:PortaRe0:SOIC-8_L5.3-W5.3-P1.27-LS8.0-BL' を処理中です。
情報: シンボル 'RP2040#2:PortaRe0:SOIC-8_L5.3-W5.3-P1.27-LS8.0-BL' を処理中です。
情報: シンボル 'SW1:PortaRe0:KEY-SMD_4P-SKSCLXX010' を処理中です。
情報: シンボル 'SW_D44:PortaRe0:SOD-123_L2.8-W1.8-LS3.7-RD' を処理中です。
情報: シンボル 'SW2:PortaRe0:SW-TH_MSK12C02' を処理中です。
情報: シンボル 'SW_D1:PortaRe0:SOD-123_L2.8-W1.8-LS3.7-RD' を処理中です。
情報: シンボル 'SW_D2:PortaRe0:SOD-123_L2.8-W1.8-LS3.7-RD' を処理中です。
情報: シンボル 'SW_D3:PortaRe0:SOD-123_L2.8-W1.8-LS3.7-RD' を処理中です。
情報: シンボル 'SW_D4:PortaRe0:SOD-123_L2.8-W1.8-LS3.7-RD' を処理中です。
情報: シンボル 'SW_D5:PortaRe0:SOD-123_L2.8-W1.8-LS3.7-RD' を処理中です。
情報: シンボル 'SW_D6:PortaRe0:SOD-123_L2.8-W1.8-LS3.7-RD' を処理中です。
情報: シンボル 'SW_D7:PortaRe0:SOD-123_L2.8-W1.8-LS3.7-RD' を処理中です。
情報: シンボル 'SW_D8:PortaRe0:SOD-123_L2.8-W1.8-LS3.7-RD' を処理中です。
情報: シンボル 'SW_D9:PortaRe0:SOD-123_L2.8-W1.8-LS3.7-RD' を処理中です。
情報: シンボル 'SW_D10:PortaRe0:SOD-123_L2.8-W1.8-LS3.7-RD' を処理中です。
情報: シンボル 'SW_D11:PortaRe0:SOD-123_L2.8-W1.8-LS3.7-RD' を処理中です。
情報: シンボル 'SW_D12:PortaRe0:SOD-123_L2.8-W1.8-LS3.7-RD' を処理中です。
情報: シンボル 'SW_D13:PortaRe0:SOD-123_L2.8-W1.8-LS3.7-RD' を処理中です。
情報: シンボル 'SW_D14:PortaRe0:SOD-123_L2.8-W1.8-LS3.7-RD' を処理中です。
情報: シンボル 'SW_D15:PortaRe0:SOD-123_L2.8-W1.8-LS3.7-RD' を処理中です。
情報: シンボル 'SW_D16:PortaRe0:SOD-123_L2.8-W1.8-LS3.7-RD' を処理中です。
情報: シンボル 'SW_D17:PortaRe0:SOD-123_L2.8-W1.8-LS3.7-RD' を処理中です。
情報: シンボル 'SW_D18:PortaRe0:SOD-123_L2.8-W1.8-LS3.7-RD' を処理中です。
情報: シンボル 'SW_D19:PortaRe0:SOD-123_L2.8-W1.8-LS3.7-RD' を処理中です。
情報: シンボル 'SW_D20:PortaRe0:SOD-123_L2.8-W1.8-LS3.7-RD' を処理中です。
情報: シンボル 'SW_D21:PortaRe0:SOD-123_L2.8-W1.8-LS3.7-RD' を処理中です。
情報: シンボル 'SW_D22:PortaRe0:SOD-123_L2.8-W1.8-LS3.7-RD' を処理中です。
情報: シンボル 'SW_D23:PortaRe0:SOD-123_L2.8-W1.8-LS3.7-RD' を処理中です。
情報: シンボル 'SW_D24:PortaRe0:SOD-123_L2.8-W1.8-LS3.7-RD' を処理中です。
情報: シンボル 'SW_D25:PortaRe0:SOD-123_L2.8-W1.8-LS3.7-RD' を処理中です。
情報: シンボル 'SW_D26:PortaRe0:SOD-123_L2.8-W1.8-LS3.7-RD' を処理中です。
情報: シンボル 'SW_D27:PortaRe0:SOD-123_L2.8-W1.8-LS3.7-RD' を処理中です。
情報: シンボル 'SW_D28:PortaRe0:SOD-123_L2.8-W1.8-LS3.7-RD' を処理中です。
情報: シンボル 'SW_D29:PortaRe0:SOD-123_L2.8-W1.8-LS3.7-RD' を処理中です。
情報: シンボル 'SW_D30:PortaRe0:SOD-123_L2.8-W1.8-LS3.7-RD' を処理中です。
情報: シンボル 'SW_D31:PortaRe0:SOD-123_L2.8-W1.8-LS3.7-RD' を処理中です。
情報: シンボル 'SW_D32:PortaRe0:SOD-123_L2.8-W1.8-LS3.7-RD' を処理中です。
情報: シンボル 'SW_D33:PortaRe0:SOD-123_L2.8-W1.8-LS3.7-RD' を処理中です。
情報: シンボル 'SW_D34:PortaRe0:SOD-123_L2.8-W1.8-LS3.7-RD' を処理中です。
情報: シンボル 'SW_D35:PortaRe0:SOD-123_L2.8-W1.8-LS3.7-RD' を処理中です。
情報: シンボル 'SW_D36:PortaRe0:SOD-123_L2.8-W1.8-LS3.7-RD' を処理中です。
情報: シンボル 'SW_D37:PortaRe0:SOD-123_L2.8-W1.8-LS3.7-RD' を処理中です。
情報: シンボル 'SW_D38:PortaRe0:SOD-123_L2.8-W1.8-LS3.7-RD' を処理中です。
情報: シンボル 'SW_D39:PortaRe0:SOD-123_L2.8-W1.8-LS3.7-RD' を処理中です。
情報: シンボル 'SW_D40:PortaRe0:SOD-123_L2.8-W1.8-LS3.7-RD' を処理中です。
情報: シンボル 'SW_D41:PortaRe0:SOD-123_L2.8-W1.8-LS3.7-RD' を処理中です。
情報: シンボル 'SW_D42:PortaRe0:SOD-123_L2.8-W1.8-LS3.7-RD' を処理中です。
情報: シンボル 'SW_D43:PortaRe0:SOD-123_L2.8-W1.8-LS3.7-RD' を処理中です。
情報: 合計警告数: 10、エラー数: 2.
情報: シンボル 'SW_D45:PortaRe0:SOD-123_L2.8-W1.8-LS3.7-RD' を処理中です。
情報: シンボル 'SW_D46:PortaRe0:SOD-123_L2.8-W1.8-LS3.7-RD' を処理中です。
情報: シンボル 'SW_D47:PortaRe0:SOD-123_L2.8-W1.8-LS3.7-RD' を処理中です。
情報: シンボル 'SW_D48:PortaRe0:SOD-123_L2.8-W1.8-LS3.7-RD' を処理中です。
情報: シンボル 'SW_D49:PortaRe0:SOD-123_L2.8-W1.8-LS3.7-RD' を処理中です。
情報: シンボル 'SW_D50:PortaRe0:SOD-123_L2.8-W1.8-LS3.7-RD' を処理中です。
情報: シンボル 'SW_D51:PortaRe0:SOD-123_L2.8-W1.8-LS3.7-RD' を処理中です。
情報: シンボル 'SW_D52:PortaRe0:SOD-123_L2.8-W1.8-LS3.7-RD' を処理中です。
情報: シンボル 'SW_D53:PortaRe0:SOD-123_L2.8-W1.8-LS3.7-RD' を処理中です。
情報: シンボル 'SW_D54:PortaRe0:SOD-123_L2.8-W1.8-LS3.7-RD' を処理中です。
情報: シンボル 'SW_D55:PortaRe0:SOD-123_L2.8-W1.8-LS3.7-RD' を処理中です。
情報: シンボル 'SW_D56:PortaRe0:SOD-123_L2.8-W1.8-LS3.7-RD' を処理中です。
情報: シンボル 'SW_D57:PortaRe0:SOD-123_L2.8-W1.8-LS3.7-RD' を処理中です。
情報: シンボル 'SW_D58:PortaRe0:SOD-123_L2.8-W1.8-LS3.7-RD' を処理中です。
情報: シンボル 'SW_D59:PortaRe0:SOD-123_L2.8-W1.8-LS3.7-RD' を処理中です。
情報: シンボル 'SW_D60:PortaRe0:SOD-123_L2.8-W1.8-LS3.7-RD' を処理中です。
情報: シンボル 'SW_D61:PortaRe0:SOD-123_L2.8-W1.8-LS3.7-RD' を処理中です。
情報: シンボル 'SW_D62:PortaRe0:SOD-123_L2.8-W1.8-LS3.7-RD' を処理中です。
情報: シンボル 'SW_D63:PortaRe0:SOD-123_L2.8-W1.8-LS3.7-RD' を処理中です。
情報: シンボル 'U1:PortaRe0:QFN-24_L4.0-W4.0-P0.50-TL-EP2.7' を処理中です。
情報: シンボル 'U2:PortaRe0:SOT-563_L1.6-W1.2-P0.50-LS1.6-BR' を処理中です。
情報: シンボル 'U3:PortaRe0:SOT-25-5_L2.9-W1.6-P0.95-LS2.8-BL' を処理中です。
情報: シンボル 'U4:PortaRe0:QFN-76_L9.0-W9.0-P0.40-BL-EP' を処理中です。
情報: シンボル 'U5:PortaRe0:SOIC-8_L5.3-W5.3-P1.27-LS8.0-BL' を処理中です。
情報: シンボル 'U6:PortaRe0:LQFN-56_L7.0-W7.0-P0.4-EP' を処理中です。
情報: シンボル 'U7:PortaRe0:SOT-563_L1.6-W1.2-P0.50-LS1.6-BR' を処理中です。
情報: シンボル 'U8:PortaRe0:USB-C-SMD_USB31-TYPE-C-FSABC' を処理中です。
情報: シンボル 'U9:PortaRe0:WLP-9_L1.4-W1.3-P0.40-R3-C3-BR' を処理中です。
情報: シンボル 'U10:PortaRe0:SOIC-8_L4.9-W3.9-P1.27-LS6.0-BL' を処理中です。
情報: シンボル 'U11:PortaRe0:LQFN-56_L7.0-W7.0-P0.4-EP' を処理中です。
情報: シンボル 'U12:PortaRe0:USB-TH_USB3.0-A' を処理中です。
情報: シンボル 'U13:PortaRe0:TSSOP-20_L6.5-W4.4-P0.65-LS6.4-BL' を処理中です。
情報: シンボル 'U14:PortaRe0:WQFN-16_L3.0-W3.0-P0.50-TL-EP1.6' を処理中です。
情報: シンボル 'U15:PortaRe0:WLP-9_L1.4-W1.3-P0.40-R3-C3-BR' を処理中です。
情報: シンボル 'U16:PortaRe0:TSOT-23-5_L2.9-W1.6-P0.95-LS2.8-BL' を処理中です。
情報: シンボル 'USBC1:PortaRe0:USB-C_SMD-TYPE-C-31-M-12_1' を処理中です。
情報: シンボル 'Y1:PortaRe0:CRYSTAL-SMD_4P-L3.2-W2.5-BL' を処理中です。

警告: コンポーネント J1 パッド 6 に対するネットが見つかりません（ピン 6 がシンボルにありません）。
警告: コンポーネント J1 パッド 5 に対するネットが見つかりません（ピン 5 がシンボルにありません）。
警告: コンポーネント U9 パッド A1 に対するネットが見つかりません（ピン A1 がシンボルにありません）。
警告: コンポーネント U15 パッド A1 に対するネットが見つかりません（ピン A1 がシンボルにありません）。
警告: コンポーネント K_SW64 パッド 4 に対するネットが見つかりません（ピン 4 がシンボルにありません）。
警告: コンポーネント SW1 パッド 4 に対するネットが見つかりません（ピン 4 がシンボルにありません）。
警告: コンポーネント K_SW64 パッド 3 に対するネットが見つかりません（ピン 3 がシンボルにありません）。
警告: コンポーネント K_SW65 パッド 3 に対するネットが見つかりません（ピン 3 がシンボルにありません）。
警告: コンポーネント K_SW65 パッド 4 に対するネットが見つかりません（ピン 4 がシンボルにありません）。
警告: コンポーネント SW1 パッド 3 に対するネットが見つかりません（ピン 3 がシンボルにありません）。
エラー: U9 パッド 1 が PortaRe0:WLP-9_L1.4-W1.3-P0.40-R3-C3-BR に見つかりません。
エラー: U15 パッド 1 が PortaRe0:WLP-9_L1.4-W1.3-P0.40-R3-C3-BR に見つかりません。

情報: 合計警告数: 10、エラー数: 2.

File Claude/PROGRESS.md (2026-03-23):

# PortaRe0 進捗ログ

## 現在のフェーズ
**Phase 3: PCBレイアウト完了 → 発注準備完了（資金準備待ち）**

## 現在の作業箇所
- **次のタスク**: JLCPCBにてPCBA見積もり確認（サーバーエラーで未確認）→ 発注
  - hdmi_adapter・usb_adapterのガーバー生成はまだ
  - Session41現在: 肩ボタン配置・配線・DRC完了 / ガーバー・CPL生成完了 / BOM確定
  - Session40現在: メインPCB完了・hdmi_adapter完了・usb_adapter（FPC基板）完了
  - Session39現在: MAX98357A I2S・BOOTSELスイッチ・M.2 PCIe配線完了
  - Session38現在: 電源幹線・HUB系・HDMI・USB・SPI Flash・RP2040 Flash・TPS2042・LED配線完了
  - J7/J8（usb_adapter FPCエッジ）: PCBエッジ設計・コンポーネント不要（変更なし）
  - Session33での主な確定事項:
    - J4（バッテリー）: BM06B-ACHFKS-GACN-ETF（JST ACH 6pin）/ 実装高1.43mm / 幅9.1mm / VBAT×3+GND×3 / 7.5A容量
      - DigiKey別途購入・手はんだ / シンボル+フットプリントをPortaRe0ライブラリに追加済み
      - バッテリー側: ACHFR-06V-H + SACHF-003GAC-P0.2×6 / リード線AWG #28に交換必要
      - KiCad J4シンボル差し替え・Pin1-3=VBAT / Pin4-6=GND
    - pcb_layout_notes.txt 新規作成（配置方針・発熱量・近接配置ペア・電源フロー）
    - specs/index.md PCB層数を6層に更新
  - Session32での主な作業: ドキュメント構成整理（下記参照）
  - Session31での主な確定事項:
    - SW2（キルスイッチ）: MSK12C02（C431540）EN制御方式 / KiCad配線完了
    - J9（ヘッドフォンジャック）: PJ-307C（C16684）/ KiCad配線完了 / 100kΩ pull-up追加
    - BOM Y4フットプリント修正: CONN-TH_B2B-PH-K-S → CRYSTAL-SMD_4P-L3.2-W2.5-BL
- KiCad 修正済み（session24-27で実施）:
  - BQ25895: C5(4.7nF→4.7µF) / CE(3V3→GND) / QON(GND→NC)
  - TPS61023: R_TOP(910kΩ→750kΩ, 5.1V出力) / SW2をVSYS直列に移動 / usb_hubのSW4削除
  - AP2112K: バイパスキャップ1µF→10µF
  - VL812: W25Q32 /CS GNDプルダウン→3V3_HUBプルアップ修正
  - RP2040 #1/#2: クリスタルシンボル GND23→GND24 修正 / GP24・GP25接続追加
  - PCM5102A: バイパスキャップ全修正（CAPP/CAPM→2.2µF / VNEG/AVDD/DVDD/CPVDD/LDOO→10µF）
  - TPA6132A2: 入力ピン接続逆転修正（INL+/INR+→GND / INL−/INR−へ信号） / ACカップリング2.2µF+470Ω+2.2nF追加 / G0=+3V3(0dBゲイン) / HPVDD→2.2µF / VDD→100nF+2.2µF

---

## フェーズ完了状況

### Phase 1: 部品選定 ✅ 完了
- 主要IC 全部の JLCPCB 在庫確認済み
- BOMファイル確定: `bom/cyberdeck_bom.xlsx` / `bom/cyberdeck_bom.csv`
- GitHubリポジトリ作成: https://github.com/M256XR/PortaRe0
- KiCadプロジェクト・ライブラリ設定済み
- easyeda2kicad で全ICのシンボル/フットプリント取得済み（`kicad/PortaRe0_lib/`）

### Phase 2: 回路設計 🔄 進行中
- [x] KiCadプロジェクト作成、階層シート構成（power / usb_hub / keyboard / audio）
- [x] BQ25895 powerシート完成・修正済み（TS分圧固定 / インダクタ1.5µH / 全ピン配線済み）
- [x] TPS61023 回路（EN回路・モーメンタリボタン含む）・修正済み
- [x] AP2112K 回路（5V→3.3V / 常時ON）
- [x] VL812 usb_hub シート（W25Q32 SPI Flash / 25MHz水晶 / デカップリング全完）
- [x] RP2040 keyboard シート完成
  - RP2040本体・電源デカップリング・クリスタル・QSPI Flash・USB・SWD
  - キーマトリクス 63キー（9COL×8ROW / Net Label）
  - 3DSスライドパッド（Molex 5034800440 FPCコネクタ / GP27,GP28）
  - LED × 3（GP21=CHG橙 / GP22=FULL緑 / GP23=ACT緑 / 330Ω）
- [x] audio シート（RP2040 #2 + MAX98357A×2 + PCM5102A + TPA6132A2構成）
  - PJ-307C（C16684 / TH）確定・KiCad配線完了（Pin1=GND / Pin2=HP_L / Pin4=HP_DET+100kΩpull-up / Pin5=HP_R）
- [x] power シートにJ_BAT（汎用2pin）・J_USB_PWR（TYPE-C-31-M-12）追加完了
  - J_BAT: Conn_01x02プレースホルダー / Pin1=+BATT / Pin2=GND
  - J_USB_PWR: VBUS/GND/CC1-CC2(5.1kΩ→GND)/DP1-DN1-DP2-DN2(USB_DP/USB_DM)/SBU=NC/EH=GND
  - ENノード修正: BAT54(D1)をSW→EN間に追加 / PW_SW_DET分圧をD1のSW側に移動（RP2040_EN干渉防止 + τ167ms→1秒改善）
- [x] usb_hub シートに J_EXT_C・J_EXT_A 追加完了 → usb_hub シート完成
  - J_EXT_C: USB31-TYPE-C-FSABC（C2880583）/ CC1/CC2=56kΩ Rp / SS両サイド直結
  - J_EXT_A: HC-USB3.0-L168-WP（C7501850）/ USB3.0 SS対応 / 右角TH
- [x] usb_adapter シート新設（session22）
  - [x] J_SBC_USB1/J_SBC_USB2をconnectorsから移動
  - [x] FPCテール直挿し方式採用（中間コネクタなし）
  - [x] FPC 24pin ピン割り当て確定（差動ペア間GND配置）
  - [x] connectorsシートにC2856805（ZIF）×2追加
  - [x] ERC再実行 → HP系のみ（想定内）
- [x] connectors シート完成（session21）
  - [x] J_HDMI_CTRL: C2856805（24pin 0.5mm FPC）配置・配線完了
  - [x] J_SBC_USB1: C168690（USB-Cオス Vertical SMD）配置・配線完了
  - [x] J_SBC_USB2: C168690（USB-Cオス Vertical SMD）配置・配線完了
  - [x] J_SBC_HDMI: C2856805（24pin / Pin1-19=HDMI信号 / Pin20-21=GND / Pin22-24=NC）配置完了
  - [x] J_FAN: Conn_01x02 + BSS138 + 1kΩ + 10kΩ + 1N4148W / FAN_PWM Global Label
- [x] hdmi_adapter シート新設（別基板・session21）
  - J_MICROHDMI: Conn_02x08（20pin / HDMI信号14本+GND×2+NC×4）
  - FFC側: C2856805（24pin / J_SBC_HDMIと同Net Label）
  - Micro HDMIベアコネクタ → ジャンパワイヤー → 変換基板 → FFC → メインPCB
- [x] m2_ssd シート新設（session31）
  - [x] FPC-05F-16PH20（C2856801）16pin ZIF + RT9080（C841192）LDO + NASM0-S6701-TP40（C367029）M.2ソケット
  - [x] FPC→M.2 全ピン接続確定（TX AC結合100nF / RX直結 / REFCLK直結 / PERST#/CLKREQ#/WAKE#）
  - [x] 3V3_M2レール（5V_SYS→RT9080→M.2 3.3Vピン群）
- [x] 全シートERC実施・主要エラー対処完了（session21）
  - SWCLK/SWDIO × 4 → No Connect（SWD未使用）
  - VL812: SSTX3/SSRX3/SSTX4/SSRX4 → No Connect（RP2040はUSB2.0のみ）
  - VL812: COREPWRDN/TESTEN → GND / SMDAT/SMCLK → 4.7kΩプルアップ→3V3_HUB / EP → GND / DC10FB → 10µF+100nF
  - HP_DET/HP_L/HP_R → No Connect（イヤホンジャック未確定）
  - USB2_DP1_DP 双方向誤報 → ERC除外

### Phase 3: PCBレイアウト ← 次のフェーズ
### Phase 4: 試作・検証 ⏳ 未着手
### Phase 5: 筐体設計・組み立て ⏳ 未着手

---

## 未解決の TBD 事項

| 項目 | 解決タイミング |
|---|---|
| インダクタ値 | ✅ 確定（L1=C408335 / L2,L4=C3002557 / L3=C19274352） |
| VL812用 25MHz水晶 C番号 | ✅ C9006確定（負荷C=18pF×2） |
| FPCケーブル長さ（SBC接続用 30ピン 0.5mmピッチ） | 筐体CAD後 |
| キルスイッチ型番 | ✅ 確定（C431540 MSK12C02 / EN制御方式・KiCad完了） |
| モーメンタリスイッチ型番 | ✅ 確定（C115361 SKSCLBE010 / session29確定） |
| LED C番号（緑・橙） | connectors/audioシート時 |
| イヤホンジャック型番 | ✅ 確定（C16684 PJ-307C / TH 5pin / KiCad完了） |
| キーキャップ型番 | スイッチ嵌合確認後 |
| ヒンジ機構 | 筐体CAD後 |
| RTCバッテリー有無 | A7Z実機届いたら確認 |
| ヒートパイプ取り回し経路 | 筐体CAD後 |
| WiFiアンテナ配置 | 筐体CAD後 |

---

## 参照回路図・リファレンス

| 用途 | 資料名 | URL |
|---|---|-----|
| VL812 実装例（usb_hubシート検証に使用） | DragonBoard 820c Schematics | https://www.96boards.org/documentation/consumer/dragonboard/dragonboard820c/hardware-docs/files/db820c-schematics.pdf |

---

## 購入済み・発注済み

- Cubie A7Z 8GB → AliExpress 注文済み ✅
- LS055R1SX04 + HDMIコントローラ基板セット → AliExpress 注文済み ✅
- LiPo 606090（4200mAh）→ 要発注（6060100から変更）
- VS-CXMIPI-V1（D000118-VS-CXMIPI-V1-50Hz）→ AliExpress 注文済み ✅（5,731円 / UART輝度制御確認用）
- フラットヒートパイプ 3mm厚 → AliExpress 注文済み ✅
- 3DSスライドパッド → 別途購入予定

## 購入待ちリスト

- 3DSスライドパッド（AliExpress or 中古）
- 秋月 マイクロスピーカー 8Ω 23×16×4.6mm（P-12494 or P-12495）
- FPCケーブル 30ピン 0.5mmピッチ（筐体CAD後に長さ確定）
- 小型ヒートシンク 14×9×4mm程度 × 4個

---

## 直近の決定事項ログ

### 2026-03-23（session41）
- 肩ボタン（K_SW1/K_SW2）配置・配線・DRC完了（ROW0-COL0 / ROW0-COL8）
- キースイッチ変更: SKRPAKE010(C19724062) → **SKRPABE010(C115360)** / 62個 / 手はんだ
- 肩ボタン2種類購入して実機で選ぶ方針: SKSCLDE010(163gf・C115362) / SKSCLBE010(224gf・C115361)
- キー数確定: **64キー**（通常62 + 肩2 / Win=ROW7-COL7含む）/ ダイオード65個（64+FAN1）
- BOM更新: cyberdeck_bom.csv反映済み / specs/keyboard.md更新済み
- ガーバー生成完了: `gerber/`（6層・ENIG）
- CPL生成完了: `pos/PortaRe0-all-pos.csv`
- JLCPCB価格確認:
  - 基板単体5枚: **13,000円**（0.2/0.35mmビア・ENIG・6層）
  - デフォルト(0.3/0.4mm)なら7,000円だが0.2/0.35mmビアを526個中266個使用のため変更困難
  - PCBAはJLCPCBサーバーエラーで見積もり未確認（後日）
- Extended/在庫状況確認:
  - VL812(C69417) / M.2ソケット(C367029): 在庫ゼロ → プレオーダーで対応可
  - LED橙(C19273153): JLCPCBパーツライブラリ未確認 → 手はんだなので実害なし
  - BasicはAP2112K/RP2040/C9006/KT-0603Rの4点のみ・他全Extended
- **残り**: hdmi_adapter・usb_adapterのガーバー生成 / PCBAの見積もり → 発注（資金準備後）

### 2026-03-17〜18（session40）
- メインPCB DRC完了・各種制約値をJLCPCBスペックに合わせて修正
  - Defaultネットクラス: クリアランス0.1mm / ビアサイズ0.35mm / ビア穴0.2mm
  - 最小アニュラー幅0.075mm / 最小スルーホール0.2mm / 基板端クリアランス0.25mm
  - EPサーマルビア追加（各IC）/ スポーク最小数1に変更
- キーマトリクス（63キー）配線完了（肩ボタン2個のみ未配線・筐体CAD後）
  - 配線層: F.Cu/In2/In3混在（全体に広がるため層を選ばず使用）
- GNDベタ・Teardrops完了
- hdmi_adapter 新規プロジェクト作成・PCBレイアウト完了
  - 2層基板（Micro HDMIオス + 24pin FFCコネクタのみ）
- usb_adapter FPC基板 新規プロジェクト作成・PCBレイアウト完了
  - JLCPCBフレキシブル基板で発注予定
  - FPCエッジパッドフットプリント: mikeWShef/Kicad_FPC_board_ends から FPC-24P-0.5mm.kicad_mod を取得
  - スティフナー: USB-Cコネクタ部分・FPCエッジ挿入部分に必要（発注時に手動指定）
  - DRC設定: クリアランス0.1mm / アニュラー0.18mm / ビアドリル0.2mm・外径0.56mm / 基板端0.2mm
- software/ フォルダ作成（Claude/・スクリプト・PROGRESS.md等）
- **残り**: 肩ボタン（筐体CAD後）→ JLCPCB発注

### 2026-03-15（session39）
- MAX98357A I2S配線完了（BCLK/LRCLK/SDIN/SD_MODE）
  - B.CuはM.2 PCIeで塞がれており、In2経由（via→In2→via）でM.2エリアを通過
  - U15(R)→U9(L)のL字デイジーチェーン（RP2040 #2が右寄り・L/Rが下左右）
  - SD_MODE: U15エリアで220kΩ経由（Rch）とU9への直結（Lch）に分岐
- RP2040 BOOTSELスイッチ配置・配線完了（#1/#2両方）
  - QSPI_SS信号は低速なので30〜40mm離れた配置でも問題なし
  - #1はバッテリー裏を避けてアクセスしやすい場所に配置
- M.2 PCIe FPC配線完了
  - ACカップリング100nFはFPCコネクタ側（送信元近く）に配置
  - ペア内等長のみ必要・ペア間長さ違いはCDRで吸収されるためOK
- FPC全ピン逆順の懸念確認
  - PCIe FPC: 電源はPCB内（RT9080）生成のためピン逆順でも壊れない・最悪リンク不可のみ
  - HDMI FPC: 実機のHDMIコントローラ基板のHDMIコネクタを外してFPC化するため、はんだ付け時にピン順を合わせれば問題なし
- **残り**: キーマトリクス（63キー）・GNDベタ・Teardrops

### 2026-03-13（session38）
- ルーティング大幅進捗（電源幹線〜USB差動ペアまで完了）
- 電源ルーティング方針: 5V_SYS/VSYS/BATTはIn3ベタ+ビア / B.Cuトレース最小化
  - ビア6個並列でVSYS層間接続（6個×0.3mmドリル≒6A対応）
  - パッド根元0.3mm短区間は許容・Teardrops後で一括補強
- USB-C SS配線: TH側ピンが物理的障害で15mmスタブになるためSMD側のみ接続・TH側NC
  - USB3.0はケーブル挿し方向によりUSB2.0フォールバックあり（許容）
- HDMI（In2）・USB3.0 SS（In2）・USB2.0 HS差動ペアルーターで配線
  - SCL/SDAはI2C（差動ペアではない）→ 個別トレースで配線
  - ACカップリングキャップ前後でネット名変わる箇所は手動2本引き
- VL812 SPI Flash: In3電源ベタ隙間を通して配線・等長11〜12mm・誤差1mm
- RP2040 QSPI Flash: 等長11〜12mm・誤差1mm以内
- TPS2042配線: HUB_1V2をベタ化してIn3スペース確保→大回りルートで完了
- ビアサイズ: JLCPCBスペック確認（最小ドリル0.15mm/外径0.25mm・推奨ドリル0.2mm/外径0.35mm）
- 信号線トレース幅: 0.2mm（JLCPCBルール最小0.1mm）
- **残り**: 電源系IC細かい配線・オーディオ系・RP2040信号線・キーマトリクス・GNDベタ・Teardrops

## JLCPCB C番号確定リスト

### IC・半導体

| 部品 | 型番 | C番号 |
|---|---|---|
| 充電IC | BQ25895RTWR | C80200 |
| 昇圧DC-DC | TPS61023DRLR | C919459 |
| LDO 3.3V | AP2112K-3.3TRG1 | C51118 |
| M.2 LDO | RT9080-33GJ5 | C841192 |
| USB HUBチップ | VL812-Q7 | C69417 |
| SPI Flash | W25Q32JVSSIQ | C82344 |
| キーボードMCU | RP2040 | C2040 |
| I2Sアンプ | MAX98357AEWL+T | C2682619 |
| イヤホン用DAC | PCM5102APWR | C107671 |
| ヘッドフォンアンプ | TPA6132A2RTER | C69901 |
| USBパワースイッチ | TPS2042BDR | C138720 |
| USB ESD保護 | USBLC6-2SC6 | C7519 |
| MOSFET（FAN/audio） | BSS138 | C52895 |
| Schottkyダイオード（電源保護） | BAT54 | C466635 |
| ダイオード（キーマトリクス） | 1N4148W | C2099 |

### 水晶・インダクタ

| 部品 | 型番 | C番号 |
|---|---|---|
| クリスタル（RP2040用） | X322512MOB4SI | C70565 |
| クリスタル（VL812用） | X322525MOB4SI | C9006 |
| インダクタ L1（BQ25895 2.2µH） | MWSA0402S-2R2MT | C408335 |
| インダクタ L2/L4（TPS61023 1µH） | CKST322512 | C3002557 |
| インダクタ L3（VL812 10µH） | CYA0420 | C19274352 |

### スイッチ・LED

| 部品 | 型番 | C番号 |
|---|---|---|
| キースイッチ（63キー） | Alps SKRPAKE010 | C19724062 |
| タクトSW（電源ボタン/肩ボタン×2） | Alps SKSCLDE010 | C115362 |
| キルスイッチ | MSK12C02 | C431540 |
| LED 赤（STAT直結） | KT-0603R | C2286 |
| LED 青（LED_ACT） | YLED0603B | C19171394 |
| LED 緑（LED_FULL） | YLED0603G | C19273151 |
| LED 橙（LED_CHG） | YLED0603O | C19273153 |

### コネクタ

| 部品 | 型番 | C番号 |
|---|---|---|
| バッテリーコネクタ J4（JST ACH 6pin / VBAT×3+GND×3） | BM06B-ACHFKS-GACN-ETF | DigiKey別途購入 |
| スピーカー/FAN J2/J3/J6（2pin JST PH） | B2B-PH-K-S | C131337 |
| イヤホンジャック J9 | PJ-307C | C16684 |
| M.2ソケット | NASM0-S6701-TP40 | C367029 |
| FPCコネクタ 24pin ZIF（HDMI/SBC用） | FPC-05F-24PH20 | C2856805 |
| FPCコネクタ 16pin ZIF（M.2用） | FPC-05F-16PH20 | C2856801 |
| FPCコネクタ 4pin ZIF（スティック用） | Molex 5034800440 | C3170007 |
| USB-Cオス Vertical（SBC接続） | 918-118A2021Y40000 | C168690 |
| 外部USB-C レセプタクル | USB31-TYPE-C-FSABC | C2880583 |
| 外部USB-A レセプタクル | HC-USB3.0-L168-WP | C7501850 |

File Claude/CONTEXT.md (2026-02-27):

# PortaRe0 Claude コンテキストファイル

Claudeがこのプロジェクトを引き継ぐ際に最初に読むファイル。

---

## セッション開始時の手順

1. **GitHubから差分確認** - 別PCでの作業が入っている可能性があるため必ず確認
   ```
   git fetch && git status
   ```

2. **このファイル（CONTEXT.md）** - 全体像・読み込み順の把握

3. **PROGRESS.md** - 現在どこまで進んでいるか・次のタスク・最新の決定事項

4. **Claude.md** - 確定済み仕様の詳細（信頼の源泉）

5. **chat_logs/原文/index.md** - 疑問が生じたら索引で原文の場所を特定

6. **chat_logs/原文/SessionXX.txt** - 索引で場所を特定してから該当部分を読む

> **重要**: 仕様の正確性は Claude.md > PROGRESS.md > 原文 の順で信頼すること。
> PROJECT_PLAN.md は初期計画書（凍結）なので参照のみ・仕様変更の追跡には使わないこと。
> chat_logs/要約_archive/ は廃止済み。どうしても必要な場合のみ参照し、原文を優先すること。

---

## プロジェクト概要

Cubie A7Z SBCベースのクラムシェル型ポータブルPC（Cyberdeck）自作プロジェクト。

- オーナー：M256XR
- GitHubリポジトリ：https://github.com/M256XR/PortaRe0
- ローカルパス：D:\Projects\PortaRe0\
- KiCadプロジェクト：D:\Projects\PortaRe0\kicad\PortaRe0\

---

## ファイル構成と役割

| ファイル | 役割 | 更新タイミング |
|---|---|---|
| Claude.md | 確定済み仕様の真実（最優先） | 仕様変更のたびに更新 |
| PROGRESS.md | 進捗・直近の決定事項ログ | セッションごとに更新 |
| CONTEXT.md | このファイル・案内のみ | 運用方式変更時のみ |
| PROJECT_PLAN.md | 初期計画書（凍結・参照のみ） | 更新しない |
| chat_logs/原文/index.md | 原文ログの索引 | 原文ファイル追加時に更新 |
| chat_logs/原文/SessionXX.txt | セッション原文ログ | セッション終了後に手動保存 |
| chat_logs/要約_archive/ | 旧要約（廃止） | 参照しない |

---

## 原文ログの保存ルール

- ファイル名形式：`YYYY-MM-DD_SessionNN.txt`
- 保存先：`chat_logs/原文/`
- 内容：チャットの原文をそのまま保存（要約・加工しない）
- 索引追記：`chat_logs/原文/index.md` のセッション別・トピック別に追記する

---

## 作業スタイルの注意点

- KiCadの回路図作業はClaude Codeでの直接操作不可。コマンドや手順を示す形でサポート
- easyeda2kicadはコマンドラインで動く（Claude Codeから実行可能）
- BOM更新・計算・ドキュメント生成はClaude Codeで自動化できる
- チャット内容は手動で chat_logs/原文/ に保存する運用

---

## 各フェーズの担当ツール目安

| 作業 | ツール |
|---|---|
| 回路図作成・PCBレイアウト | KiCad（手動） |
| ライブラリ取得（easyeda2kicad） | Claude Code / ターミナル |
| BOM更新・整合チェック | 手動　Claude Code |
| インダクタ値計算・電源計算 | Claude（チャット） |
| データシート調査 | Claude（チャット）/ Gemini|
| 筐体モデリング | Fusion 360 |
| PROGRESS.md・Claude.md更新 | Claude Code or 手動 |

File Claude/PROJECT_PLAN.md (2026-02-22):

# Cyberdeck プロジェクト計画書
Cubie A7Z ベース モバイルコンピューター
作成日: 2026-02-19

> **⚠️ このファイルは初期計画書（凍結）です。**
> 仕様変更・最新の決定事項は **Claude.md** および **PROGRESS.md** を参照してください。
> このファイルは経緯確認用として保存しており、内容は session04 時点のままです。

---

## 1. プロジェクト概要

Cubie A7Z SBCをベースに、5.5インチディスプレイ・フルキーボード・バッテリーを搭載したクラムシェル型のポータブルコンピューター（Cyberdeck）を自作する。PCBはJLCPCBで製造・実装（PCBA）し、筐体は3Dプリンターで自作する。

| 項目 | 内容 |
|---|---|
| コンセプト | クラムシェル型ポータブルPC（Cyberdeckスタイル） |
| メインSBC | Cubie A7Z（Allwinner A733 / 8コア / 3TOPS NPU） |
| ディスプレイ | 5.5" Sharp LS055R1SX04（1440×2560） |
| キーボード | カスタムPCB + Alps SMDスイッチ 60キー |
| 筐体 | 3Dプリンター自作（クラムシェル・ヒンジ構造） |
| PCB製造 | JLCPCB（4層基板 + PCBA） |

---

## 2. 確定済みコンポーネント

### 2.1 主要IC・モジュール

| カテゴリ | 部品名 | 型番 | JLCPCB C番号 | 備考 |
|---|---|---|---|---|
| SBC | Cubie A7Z | Cubie A7Z | — | メインコンピュータ / Micro HDMI + USB-C出力 |
| ディスプレイ | LCDパネル | LS055R1SX04 | — | 5.5" 1440x2560 / 縦向きパネル |
| ディスプレイ | HDMIコントローラ基板 | 汎用品 | — | HDMI → MIPI DSI変換 |
| 充電管理 | 充電IC | BQ25895RTWR | C80200 | USB PD対応 / バッテリー保護内蔵 |
| 電源変換 | 昇圧DC-DC | TPS61023DRLR | C919459 | LiPo 3.7V → 5V / 最大3.7A |
| 電源変換 | LDO 3.3V | AP2112K-3.3TRG1 | C51118 | 5V → 3.3V（RP2040用） |
| USBハブ | USB 3.0 HUBチップ | VL812-Q7 | C69417 | 1 upstream / 4 downstream |
| USBハブ | SPI Flash | W25Q32JVSSIQ | C82344 | VL812用ファームウェア |
| キーボードMCU | マイコン | RP2040 | C2040 | QMK対応 / ADCでアナログスティック |
| キーボードMCU | SPI Flash | W25Q32JVSSIQ | C82344 | RP2040用プログラム保存（QSPI接続・必須） |
| キーボードMCU | クリスタル | X322512MOB4SI | C70565 | 12MHz 12pF ±10ppm SMD3225-4P / 外付けC 15pF×2 |
| キースイッチ | SMDタクタイル | Alps SKRPABE010 | — | 66キー + ショルダー2個 ※マトリクスに含む |
| ダイオード | スイッチングダイオード | 1N4148W | C2099 | 66個（キーマトリクス用） |
| オーディオ | I2Sアンプ | MAX98357AEWL+T | C2682619 | ×2（ステレオ） |
| バッテリー | LiPoセル | 6060100 | — | 約3500mAh / 3.7V |
| 汎用MOSFET | Nch MOSFET | BSS138 | C52895 | レベルシフト等 |

### 2.2 電源ライン構成

電源フロー:
```
USB-C (充電) → BQ25895 → LiPo 4.2V
LiPo SYS出力 (3.7〜4.2V) → TPS61023 → 5V
5V → AP2112K → 3.3V（RP2040用）
5V → Cubie A7Z / VL812 / HDMIコントローラ基板
```

| 段階 | 入力 | 出力 | 担当部品 |
|---|---|---|---|
| 充電 | USB-C (5V PD) | LiPo充電 4.2V | BQ25895 |
| 昇圧 | LiPo SYS出力 3.7〜4.2V | 5V（システム電源） | TPS61023 |
| 降圧（3.3V） | 5V | 3.3V（RP2040用） | AP2112K |
| バッテリー保護 | — | 過充電・過放電・過電流保護 | BQ25895内蔵（BMSモジュール不要） |

電源スイッチ:
- 起動：モーメンタリボタン → TPS61023 EN ピン High
- 通常OFF：SBC GPIO → EN Low（shutdown フック）
- 緊急キル：ロック式スイッチ → EN 強制 Low

### 2.3 USBポート割り当て

| SBC側ポート | 接続先 | 用途 |
|---|---|---|
| USB-C (USB 3.0) | VL812 (upstream) | USBハブ経由で3系統に分岐 |
| USB-C (USB 2.0) | BQ25895 | 充電入力ポート（刻印:PWR） |
| Micro HDMI | HDMIコントローラ基板 | ディスプレイ信号 |
| VL812 downstream 1 | 外部USB-Cレセプタクル | データポート（刻印:DATA） |
| VL812 downstream 2 | 外部USB-Aレセプタクル | 汎用USBポート |
| VL812 downstream 3 | RP2040 | キーボード接続 |

### 2.4 オーディオ

- MAX98357AEWL+T × 2（ステレオ構成）
- スピーカー：秋月 マイクロスピーカー 8Ω 23×16×4.6mm × 1個（片チャンネル）
- イヤホンジャック：3.5mm TRRS SMT（挿入時スピーカーミュート）
- I2S接続：Cubie A7Z GPIO → ジャンパ3本（BCLK / LRCLK / SDIN）

### 2.5 LED

| LED | 制御 | 役割 |
|-----|---|---|
| 電源LED（緑） | TPS61023 出力（5V） | 電源ON中点灯 |
| 充電中LED（橙） | RP2040（BQ25895 I2C読み） | 充電中点灯 |
| 充電完了LED（緑） | RP2040（BQ25895 I2C読み） | 満充電点灯 |
| ACT LED | RP2040（USB経由でSBCから制御） | OS動作表示 |

### 2.6 冷却

- 方式：パッシブ（ヒートパイプ + 小型ヒートシンク）
- ヒートパイプ：3mm厚フラット銅製、SoC → 90度曲げ → バッテリー上端の隙間（幅16mm）を通過
- ヒートシンク：14×9×4mm 程度 × 4個（サーマルパッドで密着）
- ファン：スペース確保のみ（Cubie A7Z 内蔵ファンコネクタ経由で後付け可）

---

## 3. 設計上の決定事項

### 3.1 PCB構成

- メインキーボードPCB：4層基板（信号 / GND / 電源 / 信号）
- サブ基板（SBC接続用）：メインPCBのスロット穴に垂直挿入する形式
- 実装：JLCPCB PCBAを活用（QFNパッケージICはPCBA必須）
- HDMI差動ペア：90Ω / 等長配線
- USB3.0 SS差動ペア：90Ω

### 3.2 筐体

- クラムシェル構造（ボトム：SBC・バッテリー収納 / リッド：ディスプレイ収納）
- 素材：3Dプリンター（FDM or SLA）で自作
- ボトム外形目安：139×81mm
- ヒンジ：3Dプリント or 市販品流用（要検討）

### 3.3 入力デバイス

- キースイッチ：Alps SKRPABE010（SMD タクタイル 4.2×3.2mm）× 63キー（C115360）
- アナログスティック：3DSスライドパッド（カーソル操作用）/ FPC 4ピン 1.0mmピッチ / VCC=3.3V直結OK
- FPCコネクタ：Molex 5034800440（C3170007）/ 4P 1.0mm ZIF ヒンジ式
- ショルダーボタン：SKRPABE010 × 2（L/Rボタン）※マトリクスに含む

### 3.4 キーレイアウト（KLE形式）

```
["Left",{x:13},"Right"],
["esc","1","2","3","4","5","6","7","8","9","0","-","^","\\","BS"],
[{w:1.5},"h/z","Q","W","E","R","T","Y","U","I","O","P","@","[",{x:0.25,a:7,w:1.25,h:2,w2:1.5,h2:1,x2:-0.25},""],
[{a:4,w:1.75},"Tab","A","S","D","F","G","H","J","K","L",";",":","]"],
[{w:2},"Shift","Z","X","C","V","B","N","M",",",".","/","\\",{w:2},"RShift"],
[{x:4.5,w:4.5},"Space",{x:0.5},"Back","Next",{x:0.5},"Ctrl","Fn","Alt"]
```

- 合計66キー / 9×8マトリクス（COL9本 + ROW8本 = 17本）

### 3.5 RP2040 GPIO割り当て

| 用途 | GPIO | 本数 |
|---|---|---|
| キーマトリクス COL | GP0〜GP8 | 9本 |
| キーマトリクス ROW | GP9〜GP16 | 8本 |
| I2C SCL（BQ25895） | GP17 | 1本 |
| I2C SDA（BQ25895） | GP18 | 1本 |
| BQ_INT | GP19 | 1本 |
| RP2040_EN | GP20 | 1本 |
| I2S BCLK | GP21 | 1本 |
| I2S LRCLK | GP22 | 1本 |
| I2S SDIN | GP23 | 1本 |
| LED_CHG（充電中・橙） | GP24 | 1本 |
| LED_FULL（充電完了・緑） | GP25 | 1本 |
| LED_ACT（ACT） | GP26（ADC0兼用） | 1本 |
| アナログスティック X | GP27（ADC1） | 1本 |
| アナログスティック Y | GP28（ADC2） | 1本 |
| 予備 | GP29（ADC3） | 1本 |
| **合計** | | **29本（30本中）** |

### 3.6 RP2040 クリスタル

| 項目 | 値 |
|---|----|
| 型番 | X322512MOB4SI（C70565） |
| 周波数 | 12MHz |
| 負荷容量 | 12pF |
| 精度 | ±10ppm |
| パッケージ | SMD3225-4P |
| 外付けC | 15pF × 2（XIN/XOUT各1個） |
| 接続 | XIN(Pin20) / XOUT(Pin21) |

### 3.7 RP2040 外部SPI Flash接続

RP2040は内蔵Flashを持たないため、外部W25Q32（QSPI接続）が必須。

| W25Q32ピン | RP2040ピン | 処理 |
|---|---|---|
| 1 /CS | QSPI_SS (Pin56) | 10kΩ → +3V3 プルアップ |
| 2 DO (IO1) | QSPI_SD1 (Pin55) | 直結 |
| 3 /WP (IO2) | QSPI_SD2 (Pin54) | 直結（Quad SPI時はIO2として使用） |
| 4 GND | GND | GND |
| 5 DI (IO0) | QSPI_SD0 (Pin53) | 直結 |
| 6 CLK | QSPI_SCLK (Pin52) | 直結 |
| 7 /HOLD (IO3) | QSPI_SD3 (Pin51) | 直結（Quad SPI時はIO3として使用） |
| 8 VCC | +3V3 | 100nF デカップリング |

※VL812用W25Q32とは別部品（合計2個必要）

---

## 4. 実装難易度評価

| 部品 | 難易度 | 理由 | 対策 |
|---|---|---|---|
| BQ25895 | 高 | QFN 24ピン・露出パッド | JLCPCB PCBA必須 |
| VL812 | 高 | QFN 76ピン・9×9mm | JLCPCB PCBA必須 |
| RP2040 | 中〜高 | QFN 56ピン | JLCPCB PCBA |
| HDMI差動ペア配線 | 高 | 90Ω差動・等長配線が必要 | KiCad 4層構成で対応 |
| USB 3.0 SS配線 | 中〜高 | VL812〜SBC間 90Ω差動 | 同上 |
| TPS61023 | 低〜中 | SOT563 6ピン・外付け部品少ない | PCBAで対応 |

---

## 5. 未決事項（TBD）

| 項目 | 現状 | 決定に必要なこと |
|---|---|---|
| インダクタ（BQ25895用） | TBD | スイッチング周波数・電流値から計算 |
| インダクタ（TPS61023用） | 1µH前後 | JLCPCB在庫確認 |
| FPCコネクタ/ケーブル | ピン数・長さ未定 | HDMIコントローラ基板のコネクタ仕様確認 |
| キルスイッチ型番 | TBD | KiCad フットプリント決める時 |
| アナログスティック最終選定 | **3DSスライドパッド確定** | FPCコネクタ C3170007（Molex 5034800440）/ VCC=3.3V直結確定 |
| キーキャップ | 薄型対応品 | スイッチとの嵌合確認 |
| ヒンジ機構 | 3Dプリント or 市販品 | 筐体設計と並行検討 |
| RTCバッテリー有無 | 未確認 | A7Z実機届いたら確認 |
| ヒートパイプ取り回し経路 | 未確認 | 筐体CAD後 |
| WiFiアンテナ配置 | 未確認 | 筐体CAD後 |

---

## 6. 今後の進め方

### Phase 1：部品選定 ✅ 完了
- 主要IC 全部の JLCPCB 在庫確認済み
- BOMファイル確定: `bom/cyberdeck_bom.xlsx`
- GitHubリポジトリ作成: https://github.com/M256XR/PortaRe0
- KiCadプロジェクト・ライブラリ設定済み

### Phase 2：回路設計 🔄 進行中
- KiCad 階層シート構成：メイン + power / usb_hub / keyboard / audio
- [ ] BQ25895 powerシート完成（TS修正 + 右側・上側ピン）
- [ ] TPS61023 昇圧回路（インダクタ値計算が必要）
- [ ] AP2112K LDO 回路
- [ ] VL812 usb_hub シート
- [ ] RP2040 keyboard シート
- [ ] MAX98357A × 2 audio シート
- [ ] コネクタ類（SBC接続・外部ポート・FPC 30ピン）

### Phase 3：PCBレイアウト ⏳ 未着手
- 4層スタックアップの設定（信号・GND・電源・信号）
- HDMI差動ペアの等長配線（90Ω）
- USB 3.0 SuperSpeed差動ペアの配線（90Ω）
- 電源プレーンの整備・デカップリングコンデンサ配置
- サブ基板のスロット穴とカードエッジ設計

### Phase 4：試作・検証 ⏳ 未着手
- JLCPCBへ発注（PCBA込み）
- 電源系の動作確認（BQ25895 → TPS61023 → 5V）
- SBC起動確認・ディスプレイ表示確認
- キーボード・USB HUBの動作確認

### Phase 5：筐体設計・組み立て ⏳ 未着手
- PCB寸法確定後にFusion 360 or OpenSCADで筐体モデリング
- 3Dプリント・試作フィット確認
- ヒンジ・ボタン・コネクタ穴の調整
- 最終組み立て

---

## 7. 参考情報

| 部品 | 型番 | 参考先 |
|---|---|---|
| SBC | Cubie A7Z | Radxa 公式 |
| 充電IC | BQ25895 | Texas Instruments |
| 昇圧DC-DC | TPS61023 | Texas Instruments |
| USBハブ | VL812-Q7 | VIA Labs |
| キーボードMCU | RP2040 | Raspberry Pi / QMK |
| PCB製造 | — | JLCPCB (jlcpcb.com) |

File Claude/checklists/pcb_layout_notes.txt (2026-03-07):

================================================================================
PortaRe0 PCBレイアウト 配置・配線メモ
作成日: 2026-03-06
================================================================================

================================================================================
層構成（6層確定）
================================================================================

F.Cu  : COL線 + キースイッチ（表面全体）→ IC配線NG
In1   : GND ベタ（配線なし・ビア貫通のみ）
In2   : ROW線 + IC配線 1層目 + USB3.0 SS差動ペア + HDMI差動ペア
In3   : 電源ゾーン（VSYS/5V_SYS/3V3 ゾーン分割）+ IC配線 2層目（隙間）
In4   : GND ベタ（配線なし・B.Cuの参照面）
B.Cu  : IC実装面 + IC配線 + PCIe Gen3差動ペア（右上エリア限定・IC少）

※ In3は電源ゾーン銅塗りつつ隙間に信号を通す共用層
※ USB3.0 SS・HDMIをIn2に逃がした理由: B.CuはIC密集でインピーダンス管理困難
※ PCIeはM.2ソケット+FPCコネクタのみで周辺IC少 → B.Cuでも問題なし
※ In2はIn1 GNDが直上参照面 / B.CuはIn4 GNDが直上参照面（両層ともインピーダンス制御成立）

================================================================================
大まかな配置方針
================================================================================

[上端エッジ]
  肩L | SW1(PowerSW) | J4(Battery) | J_USB_PWR | SW2(KillSW)
  | J_EXT_A(USB-A) | J_EXT_C(USB-C ext) | J9(AudioJack) | 肩R
  ※ J_HDMI_CTRL はF.Cu表側（HDMIコントローラ基板が表側に来るため）

[左上エリア]
  BQ25895(U1) + L1 + TPS61023 #1(U2) + L2 + AP2112K(U3)
  → VSYS極太パターンを最短に
  → J_USB_PWRの真下付近

[右上エリア]
  TPS61023 #2(U7) + L4（J_EXT_C/A の近く）
  M.2ソケット(CN1) 横向き配置 + RT9080(U16) + FPC6(SBC_PCIE)
  → PCIe FFC 10cm以内で接続可能（Gen3 x1 は10cmで問題なし）

[上中央エリア]
  FPC類（FPC2:J_SBC_HDMI / FPC4:J_SBC_USB_2.0 / FPC5:J_SBC_USB_3.1）
  → バッテリー上エリア・発熱ほぼゼロなので問題なし

[中央エリア]
  VL812(U4) + W25Q32(U5) + TPS2042BDR(U10) + USBLC6×2(D5/D6)
  RP2040 #1(U6) → キーマトリクス中心付近（中央やや左寄り）
  RP2040 #2(U11) → 右寄り（オーディオICと近く）

[右側エリア]
  PCM5102A(U13) + TPA6132A2(U14) ← 近接配置
  RP2040 #2(U11) + W25Q32(QSPI Flash)

[右下エリア]
  MAX98357A L/R(U9/U15) → J2/J3スピーカーコネクタの近く
  アナログスティック(Stick1)

[左下エリア]
  バッテリー（606090 / 90mm×60mm）
  J4(Battery) は上端に配置・左端をケーブルが縦走

================================================================================
発熱量まとめ（バッテリー上配置可否）
================================================================================

--- バッテリー上NG（0.5W以上 または 高電流経路） ---

部品          発熱概算   理由
----------    --------   ----------------------------------------
BQ25895(U1)   0.5〜1W    充電時スイッチング損失（効率92%、5V×2A入力）
TPS61023 #1   0.3〜0.5W  昇圧スイッチング損失
L1(2.2µH)     0.23W      I²×DCR = (2A)²×0.058Ω
L2(1µH) #1    0.42W      I²×DCR = (3.75A)²×0.030Ω
VL812(U4)     0.5〜1W    USB3.0ハブ動作時

--- 許容範囲（バッテリー上OK） ---

部品              発熱概算    備考
--------------    --------    ----------------------------------------
AP2112K(U3)       0.34W       (5-3.3V)×200mA・ギリギリ許容
TPS61023 #2       0.05W       軽負荷（外部USB小型デバイス想定）
L4(1µH) #2        0.02W       軽負荷
L3(10µH) VL812用  0.07W       1.2V出力側電流が小さい
RP2040 ×2         各0.1〜0.2W アイドル時低消費
オーディオIC群     合計0.2〜0.3W PCM5102A/TPA6132A2/MAX98357A
抵抗・コンデンサ  極小         問題なし

--- バッテリー熱保護対策 ---
1. カプトンテープ（ポリイミド）をバッテリー表面に貼る（熱伝導率0.12W/mK）
2. エアギャップ確保（スタンドオフで1〜2mm）
3. BQ25895/TPS61023 #1/L1/L2 をバッテリーエリア外（左上端）に固定

================================================================================
近接配置が必要な部品ペア
================================================================================

--- 最短必須（数mm以内） ---

ペア                                  理由
------------------------------------  ----------------------------------------
L1 ↔ BQ25895 [SWピン]                スイッチングノードのループ最小化（EMI対策）
L2 ↔ TPS61023 #1 [SWピン]           同上
L4 ↔ TPS61023 #2 [SWピン]           同上
L3 ↔ VL812 [LXピン]                 同上
Y1(25MHz) ↔ VL812                   発振ループ面積最小化
Y2/Y4(12MHz) ↔ RP2040 #1/#2         同上
クリスタル負荷キャップ ↔ クリスタル   発振ループに入らないよう直近に
W25Q32(U5) ↔ VL812                  SPI高速配線
W25Q32(QSPI) ↔ RP2040 #1/#2         QSPI高速配線（各RP2040用Flash）
デカップリングキャップ ↔ 各IC電源ピン  電源ピンの真横0.5〜1mm以内

--- 近い方がいい（1cm以内目安） ---

ペア                          理由
----------------------------  ----------------------------------------
USBLC6(D5) ↔ J_EXT_C         ESD保護はコネクタ入口直後
USBLC6(D6) ↔ J_EXT_A         同上
TPS2042BDR(U10) ↔ VL812(U4)  USBHPE/USBHOC制御線を短く
PCM5102A(U13) ↔ TPA6132A2(U14) アナログ音声信号を短く
MAX98357A(U9/U15) ↔ J2/J3    スピーカー出力電流を短い経路で
SSREXT抵抗(R18) ↔ VL812 Pin1  アナログ基準抵抗
RT9080(U16) ↔ CN1(M.2ソケット) 3V3_M2配線を短く

--- 高速差動ペア（別途等長配線ルール適用） ---

信号           規格    層       インピーダンス
-----------    ------  ------   --------------
USB3.0 SS      5Gbps   B.Cu     90Ω差動
HDMI           1.65G   B.Cu     90Ω差動・等長
PCIe Gen3 x1   8Gbps   B.Cu     85〜90Ω差動・等長
               ↑ いずれもIn4 GNDを参照面とする

================================================================================
IC間距離目安（JLCPCBルール: 最小トレース0.1mm/クリアランス0.1mm）
================================================================================

VL812（QFN-76 / 0.4mmピッチ）周囲  : 4〜5mm確保推奨
RP2040（QFN-56 / 0.4mmピッチ）周囲 : 3〜4mm確保推奨
小型IC同士                          : 3mm程度
デカップリングキャップのみ           : 0.5〜1mm（IC電源ピン直近）

================================================================================
電源フロー（左→右）
================================================================================

バッテリー(左下) → J4(左上) → BQ25895(U1) → TPS61023 #1(U2)
                                              → 5V_SYS(In3プレーン) ──→ VL812(中央)
                                              → 3V3(AP2112K U3)  ──→ RP2040×2
                                              → 3V3_M2(RT9080 U16) → M.2(右上)
                             ↘ TPS61023 #2(U7) → USB_5V_SYS → J_EXT_C/A(右上)

================================================================================

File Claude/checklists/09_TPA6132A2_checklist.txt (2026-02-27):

================================================================================
TPA6132A2RTER  ヘッドフォンアンプ チェックシート
データシート: https://www.ti.com/lit/ds/symlink/tpa6132a2.pdf
JLCPCB C番号: C69901
パッケージ: WQFN-16 (2mm × 2mm)
シート: audio.kicad_sch / U14
================================================================================

■ TPA6132A2 ピン配置 (WQFN-16):
  Pin 1:  INL−   — L チャンネル 反転入力
  Pin 2:  INL+   — L チャンネル 非反転入力
  Pin 3:  INR+   — R チャンネル 非反転入力
  Pin 4:  INR−   — R チャンネル 反転入力
  Pin 5:  OUTR   — R チャンネル 出力
  Pin 6:  G0     — ゲイン設定ビット 0
  Pin 7:  G1     — ゲイン設定ビット 1
  Pin 8:  HPVSS  — チャージポンプ出力 (負電圧)
  Pin 9:  CPN    — チャージポンプ − キャップ端子
  Pin 10: PGND   — パワーグランド
  Pin 11: CPP    — チャージポンプ + キャップ端子
  Pin 12: HPVDD  — ヘッドフォン供給電圧 (チャージポンプ出力)
  Pin 13: EN     — イネーブル (アクティブ High)
  Pin 14: VDD    — 電源 (1.8〜5.5V)
  Pin 15: SGND   — シグナルグランド
  Pin 16: OUTL   — L チャンネル出力
  EP:     露出パッド → SGND or PGND

■ ゲイン設定 (G0/G1):
  G0=0, G1=0: 6dB  (GND, GND)
  G0=1, G1=0: 12dB (VDD, GND)
  G0=0, G1=1: 18dB (GND, VDD) ← デフォルト
  G0=1, G1=1: 24dB (VDD, VDD)
  ※ フローティングは NG。必ず GND か VDD に接続。

━━━━━━━━━━━━━━━━━━━━━━━━━━━━━━━━━━━━━━━━━━━━━━━━━━
PIN CHECK
━━━━━━━━━━━━━━━━━━━━━━━━━━━━━━━━━━━━━━━━━━━━━━━━━━

[ok] Pin 1 : INL− (L 反転入力) ← シングルエンド信号入力ピン
    正しい接続: HP_OUTL → 2.2µF(ACカップリング) → 470Ω → INL−
               INL− と GND 間に 2.2nF (EMIフィルタ LPF fc≈154kHz)
    修正済み ✅

[ok] Pin 2 : INL+ (L 非反転入力) ← シングルエンド時はGND
    正しい接続: GND
    注意: データシート明記「Connect to ground for single-ended input applications」
    修正済み ✅

[ok] Pin 3 : INR+ (R 非反転入力) ← シングルエンド時はGND
    正しい接続: GND
    注意: データシート明記「Connect to ground for single-ended input applications」
    修正済み ✅

[ok] Pin 4 : INR− (R 反転入力) ← シングルエンド信号入力ピン
    正しい接続: HP_OUTR → 2.2µF(ACカップリング) → 470Ω → INR−
               INR− と GND 間に 2.2nF (EMIフィルタ)
    修正済み ✅

[ok ] Pin 5 : OUTR (R 出力)
    期待: HP_R ネット → 3.5mm ジャック R 端子
    確認: HPジャック未定

[ok] Pin 6 : G0 (ゲインビット 0)
    接続: +3V3 (修正済み: GND→+3V3)
    ゲイン設定: G0=VDD, G1=GND → 0dB
    修正済み ✅

[ok] Pin 7 : G1 (ゲインビット 1)
    接続: GND
    ゲイン設定: G0=VDD, G1=GND → 0dB ✅

⚠️ Pin 8 : HPVSS (チャージポンプ出力 ≈ −VDD)
    期待: 1µF キャップ → PGND (session11 で修正済み)
    注意: HPVSS は出力。直接 GND に接続してはいけない!
          GND 直結だとチャージポンプが機能せず、ヘッドフォン出力に DC オフセットが発生。
    ⚠️ 要確認: HPVSS が 1µF キャップ経由で GND に接続されているか?
               直接 GND に接続されていないか?
    現在の接続: 1µF->GND
    確認: ________

[ok ] Pin 9 : CPN (チャージポンプ − キャップ)
    期待: Pin 11 (CPP) との間に 1µF キャップ接続
          TI 推奨: 1µF セラミック (フライングキャップ)
    現在値: ________
    確認: ________

[ok ] Pin 10 : PGND
    期待: GNDPWR に接続
    確認: ________

[ok ] Pin 11 : CPP (チャージポンプ + キャップ)
    期待: Pin 9 (CPN) との間に 1µF キャップ (C79/C95 等)
    現在値: ________
    確認: ________

[ok] Pin 12 : HPVDD (チャージポンプ正電圧出力)
    正しい接続: 2.2µF → GND のみ (VDD接続NG / "Do not connect to VDD")
    修正済み: 100nF → 2.2µF ✅

[ok ] Pin 13 : EN (イネーブル)
    期待: HP_EN ネット → RP2040 #2 GP5
          GP5 HIGH = ヘッドフォンアンプ ON
          GP5 LOW  = シャットダウン
    確認: ________

[ok] Pin 14 : VDD (電源)
    接続: +3V3 + 100nF + 2.2µF → GND
    修正済み: 100nF → 100nF + 2.2µF追加 ✅

[ok ] Pin 15 : SGND (シグナルグランド)
    期待: GND/AGND に接続
    確認: ________

[ok ] Pin 16 : OUTL (L 出力)
    期待: HP_L ネット → 3.5mm ジャック L 端子
    確認: ________

[ok ] EP (露出パッド)
    期待: GNDPWR に接続 (サーマルビア推奨)
    確認: ________

━━━━━━━━━━━━━━━━━━━━━━━━━━━━━━━━━━━━━━━━━━━━━━━━━━
イヤホンジャック接続 (HP_L, HP_R, HP_DET)
━━━━━━━━━━━━━━━━━━━━━━━━━━━━━━━━━━━━━━━━━━━━━━━━━━

注意: イヤホンジャックの型番は TBD のため現在 No Connect (HP_L/HP_R/HP_DET)
      ERC では HP 系は「想定内の未接続」として処理済み。

[ok ] HP_L (OUTL): イヤホンジャック L 端子 (型番確定後に配線)
[ok ] HP_R (OUTR): イヤホンジャック R 端子
[ok ] HP_DET (RP2040 #2 GP6): イヤホン挿入検出スイッチ
    挿入時: スイッチが閉じて GP6 → GND (またはプルアップ解除)
    検出後: GP3(SD_MODE) LOW でスピーカーミュート、GP5(HP_EN) HIGH でアンプ ON
[ok ] イヤホン GND 端子: アンプの SGND に接続 (ステレオジャックの共通 GND)

━━━━━━━━━━━━━━━━━━━━━━━━━━━━━━━━━━━━━━━━━━━━━━━━━━
全体動作フロー確認
━━━━━━━━━━━━━━━━━━━━━━━━━━━━━━━━━━━━━━━━━━━━━━━━━━

通常動作 (スピーカーのみ):
  GP3=High (SD_MODE) → スピーカー ON
  GP5=Low (HP_EN) → TPA6132A2 OFF
  GP4=High (XSMT) → PCM5102A ミュート解除

イヤホン挿入時:
  GP6 がトリガー (HP_DET) → RP2040 検出
  GP3=Low → スピーカー OFF
  GP5=High → TPA6132A2 ON
  GP4=High → PCM5102A ミュート解除

備考:
________________________________________________________________________________
________________________________________________________________________________

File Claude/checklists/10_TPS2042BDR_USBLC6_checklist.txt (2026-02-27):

================================================================================
TPS2042BDR  USB パワースイッチ / USBLC6-2SC6  ESD 保護 チェックシート
TPS2042: C138720  /  USBLC6: C7519
シート: usb_hub.kicad_sch
================================================================================

■ TPS2042BDR 概要:
  デュアルチャンネル USB パワースイッチ (0.5A/ch)
  入力: USB_5V_SYS (TPS61023 #2 出力)
  出力: 外部 USB-C / USB-A ポートの VBUS
  制御: VL812 /USBHPE (アクティブ Low)
  過電流フラグ: /OCx → VL812 /USBHOC# フィードバック

■ USBLC6-2SC6 概要:
  USB ESD 保護ダイオード (USB2.0 / USB3.0 対応)
  低容量 (0.35pF typ) で USB SS 差動ペアに適合

━━━━━━━━━━━━━━━━━━━━━━━━━━━━━━━━━━━━━━━━━━━━━━━━━━
TPS2042BDR 確認
━━━━━━━━━━━━━━━━━━━━━━━━━━━━━━━━━━━━━━━━━━━━━━━━━━

[ok ] VIN: USB_5V_SYS (TPS61023 #2 出力) に接続
    100nF バイパスキャップ → GND
    確認: ________

[ok ] OUT1: 外部 USB-C ポート (J_EXT_C) VBUS → USBLC6 経由
[ok ] OUT2: 外部 USB-A ポート (J_EXT_A) VBUS → USBLC6 経由
    確認: ________

[ok ] /EN1, /EN2 (アクティブ Low イネーブル):
    期待: VL812 /USBHPE 出力に接続
    確認: ________

[ok ] /OC1, /OC2 (過電流フラグ出力):
    期待: VL812 /USBHOC# に接続 + 10kΩ → 3V3_HUB (プルアップ)
    確認: ________

[ok ] GND: GND に接続
    確認: ________

━━━━━━━━━━━━━━━━━━━━━━━━━━━━━━━━━━━━━━━━━━━━━━━━━━
USBLC6-2SC6 ESD 保護確認
━━━━━━━━━━━━━━━━━━━━━━━━━━━━━━━━━━━━━━━━━━━━━━━━━━

配置: USB-C / USB-A コネクタ直後 (できるだけコネクタに近く配置)

[ok ] J_EXT_C 用 USBLC6:
    I/O1 → USB2.0 D+
    I/O2 → USB2.0 D-
    I/O3 → (必要に応じて SS 差動ペア保護)
    GND → GND
    確認: ________

[ok ] J_EXT_A 用 USBLC6:
    I/O1 → USB2.0 D+
    I/O2 → USB2.0 D-
    GND → GND
    確認: ________

[ok ] USBLC6 はコネクタと VL812 の間に配置されているか
    (VL812 → USBLC6 → コネクタ の順でなく、コネクタ側に近い方が効果的)
    確認: ________

━━━━━━━━━━━━━━━━━━━━━━━━━━━━━━━━━━━━━━━━━━━━━━━━━━
外部 USB-C コネクタ (J_EXT_C, C2880583)
━━━━━━━━━━━━━━━━━━━━━━━━━━━━━━━━━━━━━━━━━━━━━━━━━━

[ok ] VBUS (A4/B4/A9/B9): → TPS2042BDR OUT1 経由
[ok ] CC1/CC2: 56kΩ × 2 → VBUS (Rp = Default Current = ≈900mA アドバタイズ)
    注意: ホスト側なので Rp (プルアップ) を VBUS に接続
    現在値: ________
    確認: ________
[ok ] D+ / D- (A6/B6): USBLC6 経由 → VL812 DP1 USB2.0 DP/DM
[ok ] SS TX+ / SS TX- (A10/B10): VL812 DP1 SS TX
[ok ] SS RX+ / SS RX- (A3/B3): VL812 DP1 SS RX
[ok ] SBU1/SBU2: NC (USB DP/AltMode 未使用)
[ok ] SHELL: GND (シールド)

━━━━━━━━━━━━━━━━━━━━━━━━━━━━━━━━━━━━━━━━━━━━━━━━━━
外部 USB-A コネクタ (J_EXT_A, C7501850)
━━━━━━━━━━━━━━━━━━━━━━━━━━━━━━━━━━━━━━━━━━━━━━━━━━

[ok ] VBUS: → TPS2042BDR OUT2 経由
[ok ] D+ / D-: USBLC6 経由 → VL812 DP2 USB2.0 DP/DM
[ok ] SS+ / SS-: VL812 DP2 SS TX/RX
[ok ] SHELL: GND

備考:
________________________________________________________________________________
________________________________________________________________________________

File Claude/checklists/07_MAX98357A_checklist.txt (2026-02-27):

================================================================================
MAX98357AEWL+T  I2S スピーカーアンプ チェックシート (×2個)
データシート: https://www.analog.com/media/en/technical-documentation/data-sheets/MAX98357A-MAX98357B.pdf
JLCPCB C番号: C2682619
パッケージ: WLP-9 (1.5mm×1.7mm)
シート: audio.kicad_sch / U9 (Left, L ch), U15 (Right, R ch)
================================================================================

■ MAX98357A ピン配置 (WLP-9):
  A1: ~SD_MODE~ (シャットダウン/チャンネル選択)
  A2: VDD (電源)
  A3: OUTP (スピーカー+)
  B1: DIN (I2S データ入力)
  B2: GAIN_SLOT (ゲイン/タイムスロット設定)
  B3: OUTN (スピーカー−)
  C1: BCLK (I2S ビットクロック)
  C2: GND
  C3: LRCLK (I2S L/R クロック)

■ SD_MODE 設定値 (データシートより):
  フローティング: 左チャンネル出力 (Left)
  GND〜220kΩ経由VDD間の電圧: 右チャンネル出力 (Right) ← 典型値: 220kΩをGND側へ
  GND 直結: シャットダウン
  VDD 直結: シャットダウン

■ GAIN_SLOT 設定値:
  フローティング: 9dB ゲイン / スロット0
  GND 直結: 3dB ゲイン / スロット0
  VDD 直結: 12dB ゲイン / スロット0
  100kΩ → GND: 6dB ゲイン
  その他: データシート Table 2 参照

━━━━━━━━━━━━━━━━━━━━━━━━━━━━━━━━━━━━━━━━━━━━━━━━━━
U9 (Left Channel) 確認
━━━━━━━━━━━━━━━━━━━━━━━━━━━━━━━━━━━━━━━━━━━━━━━━━━

[? ] Pin A1 : ~SD_MODE~
    期待: GP3 (RP2040 #2) → SD_MODE ネット → A1
          U9 はフローティング経由 = 左チャンネル
          注意: SD_MODE が HIGH (VDD) だとシャットダウン!
    現在の接続: SD_MODE ネット → A1
    フローティングか、GND 経由かを確認: ________
    確認: ________

[ok ] Pin A2 : VDD
    期待: 5V_SYS (MAX98357A は 2.5〜5.5V 対応、5Vで使用)
    ⚠️ 要確認: 3.3V ではなく 5V_SYS に接続されているか
    バイパスキャップ: 100nF + 10µF → GNDPWR (ピン近傍)
    現在の電源接続: ________
    確認: ________

[ok ] Pin A3 / B3 : OUTP / OUTN (スピーカー差動出力)
    期待: SPK_L+ / SPK_L- ネット → スピーカー L チャンネル
    スピーカー: 8Ω (Nintendo Switch互換品 20×14×4mm)
    注意: OUTP/OUTN は BTL 差動出力。DC バイアスあり。
          スピーカーと直結 (結合コンデンサ不要)
    確認: ________

[ok ] Pin B1 / C1 / C3 : DIN / BCLK / LRCLK
    期待: I2S_SDIN / I2S_BCLK / I2S_LRCLK → RP2040 #2 GP2/GP0/GP1
    確認: ________

[? ] Pin B2 : GAIN_SLOT
    期待: 設定値を確認 (C番号 R36/R37 等が接続されているはず)
    現在の設定: 未接続  計算ゲイン: ________
    確認: ________

[ok ] Pin C2 : GND
    期待: GNDPWR (パワーグランド)
    確認: ________

━━━━━━━━━━━━━━━━━━━━━━━━━━━━━━━━━━━━━━━━━━━━━━━━━━
U15 (Right Channel) 確認
━━━━━━━━━━━━━━━━━━━━━━━━━━━━━━━━━━━━━━━━━━━━━━━━━━

[? ] Pin A1 : ~SD_MODE~
    期待: GP3 (RP2040 #2) → SD_MODE ネット → 220kΩ (R35) → A1
          220kΩ は SD_MODE ピンと GP3 の間に直列挿入
          → GP3 HIGH/フローティング時に SD_MODE ≈ 0V → Right ch
    ⚠️ 要確認: R35 (220kΩ) が SD_MODE ピンに接続されているか
               GAIN_SLOT ではなく SD_MODE ピンにあることを確認!
    現在の R35 接続先: SD_MODE
    確認: 抵抗値が間違っていないか

[ok ] Pin A2 : VDD
    期待: 5V_SYS + 100nF + 10µF バイパス
    確認: ________

[ok ] Pin A3 / B3 : OUTP / OUTN
    期待: SPK_R+ / SPK_R- → スピーカー R チャンネル
    確認: ________

[ok ] Pin B1 / C1 / C3 : DIN / BCLK / LRCLK
    期待: U9 と共有 (I2S_SDIN / I2S_BCLK / I2S_LRCLK)
    確認: ________

[? ] Pin B2 : GAIN_SLOT
    期待: 設定値確認
    現在の設定: 未接続  計算ゲイン: ________
    確認: ________

━━━━━━━━━━━━━━━━━━━━━━━━━━━━━━━━━━━━━━━━━━━━━━━━━━
共通確認
━━━━━━━━━━━━━━━━━━━━━━━━━━━━━━━━━━━━━━━━━━━━━━━━━━

[ok ] I2S バス: BCLK/LRCLK は U9 と U15 で共有 (並列接続)
[ok ] SDIN: U9 と U15 で共有 (同じ I2S データバス)
    注意: LRCLKの極性によりL/Rが自動割り当てされる
    SD_MODE が機能しているか + LRCLK がどちらの ch を先に出力するかが重要
[? ] SD_MODE GP3 が LOW の時: 両方シャットダウン?
    → GP3 は「スピーカー ON/OFF 制御」として使用。
       U9: SD_MODE = GP3 (フローティングに近い = Left)
       U15: SD_MODE = GP3 経由 220kΩ = Right
       GP3 LOW → U9: GND直結 = シャットダウン, U15: 220kΩ経由 ≈ GND = シャットダウン? → OK
[ok ] バイパスキャップが U9 と U15 それぞれに配置されているか
[ok ] スピーカー極性: OUTP=+, OUTN=- を一致させること (2個とも同じ向き)

備考:
________________________________________________________________________________
________________________________________________________________________________

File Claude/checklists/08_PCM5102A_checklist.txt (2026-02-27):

================================================================================
PCM5102APWR  イヤホン用ステレオ DAC チェックシート
データシート: https://www.ti.com/lit/ds/symlink/pcm5102a.pdf
JLCPCB C番号: C107671
パッケージ: TSSOP-20
シート: audio.kicad_sch / U13
================================================================================

■ PCM5102A ピン配置 (TSSOP-20):
  Pin 1:  CPVDD   — チャージポンプ VDD (= DVDD)
  Pin 2:  CAPP    — チャージポンプ + キャップ
  Pin 3:  CPGND   — チャージポンプ GND
  Pin 4:  CAPM    — チャージポンプ − キャップ
  Pin 5:  VNEG    — 負電圧出力 (チャージポンプ出力)
  Pin 6:  OUTL    — アナログ L チャンネル出力
  Pin 7:  OUTR    — アナログ R チャンネル出力
  Pin 8:  AVDD    — アナログ電源 (3.3V)
  Pin 9:  AGND    — アナログ GND
  Pin 10: DEMP    — デエンファシス制御
  Pin 11: FLT     — フィルタロールオフ選択
  Pin 12: SCK     — システムクロック (SCK-less モード時 GND or NC)
  Pin 13: BCK     — I2S ビットクロック
  Pin 14: DIN     — I2S データ入力
  Pin 15: LRCK    — I2S L/R クロック
  Pin 16: FMT     — データフォーマット選択
  Pin 17: XSMT    — ソフトミュート (LOW = ミュート)
  Pin 18: LDOO    — 内部 LDO 出力 (バイパスキャップのみ)
  Pin 19: DGND    — デジタル GND
  Pin 20: DVDD    — デジタル電源 (3.3V)

━━━━━━━━━━━━━━━━━━━━━━━━━━━━━━━━━━━━━━━━━━━━━━━━━━
PIN CHECK
━━━━━━━━━━━━━━━━━━━━━━━━━━━━━━━━━━━━━━━━━━━━━━━━━━

[ok ] Pin 1 : CPVDD
    期待: DVDD (3.3V) に接続、100nF バイパス → GND
    確認: 100nF + 10µF (MLCC) に変更済み

[ok ] Pin 2 : CAPP (チャージポンプ + キャップ)
    期待: Pin 4 (CAPM) との間に 100nF キャップ接続
          または 1µF キャップ (TI 推奨 100nF)
    現在値: 2.2µF (TI example に合わせて変更済み)
    確認: OK

[ok ] Pin 3 : CPGND
    期待: AGND に接続
    確認: ________

[ok ] Pin 4 : CAPM (チャージポンプ − キャップ)
    期待: Pin 2 (CAPP) との間に 100nF キャップ接続
    確認: 2.2µF (TI example に合わせて変更済み)

[ok ] Pin 5 : VNEG (負電圧出力 ≈ −3.3V)
    期待: 1µF バイパスキャップ → AGND
    注意: VNEG は出力。外部回路に接続する必要なし (バイパスのみ)
    現在値: 10µF (MLCC) に変更済み
    確認: OK

[ok ] Pin 6 : OUTL (左アナログ出力)
    期待: HP_OUTL ネット → TPA6132A2 INL+ (Pin 2)
    確認: ________

[ok ] Pin 7 : OUTR (右アナログ出力)
    期待: HP_OUTR ネット → TPA6132A2 INR+ (Pin 3)
    確認: ________

[ok ] Pin 8 : AVDD (アナログ電源)
    期待: +3V3 に接続
          100nF + 1µF バイパスキャップ → AGND
    確認: 100nF + 10µF (MLCC) に変更済み

[ok ] Pin 9 : AGND
    期待: AGND (アナログ GND)
    注意: PCB上でデジタルGNDと近くで合流させる (スター接続推奨)
    確認: ________

[ok ] Pin 10 : DEMP (デエンファシス)
    期待: GND に接続 (デエンファシス無効)
    確認: ________

[ok ] Pin 11 : FLT (フィルタロールオフ)
    期待: GND に接続 (Normal latency = 急峻ロールオフ)
    確認: ________

[ok ] Pin 12 : SCK (システムクロック)
    期待: GND に接続 (SCK-less モード)
          → PCM5102A は BCK/LRCK から内部クロック生成
    注意: フローティングは NG。SCK-less 時は GND に接続。
    確認: GND 接続済み (SCK-less モード)

[ok ] Pin 13 : BCK (I2S ビットクロック)
    期待: I2S_BCLK ネット → RP2040 #2 GP0
    確認: ________

[ok ] Pin 14 : DIN (I2S データ)
    期待: I2S_SDIN ネット → RP2040 #2 GP2
    確認: ________

[ok ] Pin 15 : LRCK (I2S L/R クロック)
    期待: I2S_LRCLK ネット → RP2040 #2 GP1
    確認: ________

[ok ] Pin 16 : FMT (フォーマット選択)
    期待: GND に接続 (I2S フォーマット)
    または: LRCK に接続 (Left-Justified フォーマット)
    現在の接続: GND
    確認: ________

[ok ] Pin 17 : XSMT (ソフトミュート)
    期待: XSMT ネット → RP2040 #2 GP4
          GP4 HIGH = 通常動作 (ミュート解除)
          GP4 LOW  = ミュート
    確認: ________

[ok ] Pin 18 : LDOO (内部 LDO 出力)
    期待: C94 = 1µF バイパスキャップ → GND (エージェント確認済み)
    注意: LDOO は出力。外部電源に接続不可。バイパスキャップのみ。
    C94値: 100nF + 10µF (MLCC) に変更済み
    確認: OK

[ok ] Pin 19 : DGND
    期待: GND (デジタルグランド)
    確認: ________

[ok ] Pin 20 : DVDD (デジタル電源)
    期待: +3V3 + 100nF バイパスキャップ → GND
    確認: 100nF + 10µF (MLCC) に変更済み

━━━━━━━━━━━━━━━━━━━━━━━━━━━━━━━━━━━━━━━━━━━━━━━━━━
追加確認
━━━━━━━━━━━━━━━━━━━━━━━━━━━━━━━━━━━━━━━━━━━━━━━━━━

[ok ] チャージポンプキャップ (CAPP-CAPM 間): 2.2µF (TI example に合わせて変更済み)
    値: 2.2µF
    確認: OK

[ok ] VNEG バイパス: 10µF (MLCC) → AGND に変更済み
    値: 10µF
    確認: OK

[ok ] 全バイパスキャップの AGND / DGND への配線が適切か
[ok ] AVDD と DVDD は同じ 3.3V 電源から取っているか (OK: 同電源でよい)
[ok ] PCM5102A OUTL/OUTR から TPA6132A2 への経路に余分な抵抗がないか
    (27Ω の入力直列抵抗は TPA6132A2 側 R40/R41)
[ok ] SCK が GND に接続されていることを必ず確認 → GND 接続済み

備考:
________________________________________________________________________________
________________________________________________________________________________

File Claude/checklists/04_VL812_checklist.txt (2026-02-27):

================================================================================
VL812-Q7  USB 3.0 Hub チェックシート
データシート: VL812 Application Note / DragonBoard 820c 参考回路
JLCPCB C番号: C69417
パッケージ: QFN-76-EP (9mm × 9mm)
シート: usb_hub.kicad_sch / U5
================================================================================

■ 参考設計決定事項 (PROGRESS.md session12より):
  - SSREXT: 6.04kΩ (200Ω は NG → DragonBoard 実績値に修正済み)
  - VBUSDET 分圧: 4.7kΩ + 10kΩ (約3.4V)
  - EXTPWRON: 3V3_HUB に 10kΩ プルアップのみ
  - RESET#: 1µF キャップ → GND + 100kΩ プルアップ → 3V3_HUB
  - SMDAT/SMCLK: 4.7kΩ プルアップ → 3V3_HUB
  - LX インダクタ (内部昇圧): 10µH (DragonBoard 実績値)
  - DC33FB: 4.7µF
  - DC12FB: 10µF + 100nF
  - 水晶: 25MHz, 負荷C = 18pF × 2 (C9006, CL=12pF → 外付け18pF×2)
  - VL812 DP3: RP2040 #1 (keyboard)
  - VL812 DP4: RP2040 #2 (audio)
  - COREPWRDN: GND
  - TESTEN: GND
  - USBHOC#: 10kΩ → 3V3_HUB

━━━━━━━━━━━━━━━━━━━━━━━━━━━━━━━━━━━━━━━━━━━━━━━━━━
主要ピン確認
━━━━━━━━━━━━━━━━━━━━━━━━━━━━━━━━━━━━━━━━━━━━━━━━━━

[ok ] SSREXT ピン
    期待: 6.04kΩ (±1%) → GND
    ⚠️ 200Ω は NG (既に修正済みのはず)
    現在値: ________
    確認: ________

[ok ] EXTPWRON ピン
    期待: 10kΩ プルアップ → 3V3_HUB
    注意: 3V3_HUB はキルスイッチ前の電源から取ること
    確認: ________

[? ] RESET# ピン (アクティムLow)
    期待: 100kΩ → 3V3_HUB (プルアップ) + 1µF → GND (RC 遅延)
    注意: パワーオン時に RC 遅延でリセット解除が行われる
    R値: 10k  C値: 1μ
    確認: 同時に100kでgndに落ちている

[? ] SMDAT / SMCLK (SMBus)
    期待: それぞれ 4.7kΩ → 3V3_HUB
    注意: VL812 の SMBus は設定読み込みに使用。未接続でも起動するが推奨配線
    確認: 10kで3v3にDragonと同じ

[ok ] COREPWRDN
    期待: GND に接続
    確認: ________

[ok ] TESTEN
    期待: GND に接続
    確認: ________

[ok ] USBHOC# (過電流検出フラグ)
    期待: 10kΩ → 3V3_HUB (プルアップ)
          TPS2042BDR の /OCx 出力と接続
    確認: ________

[ok ] USBHPE (USB ポート電源許可)
    期待: TPS2042BDR の /EN1, /EN2 に接続
    確認: ________

[ok ] VBUSDET (VBUS 検出)
    期待: 分圧回路 Upstream VBUS → 4.7kΩ → VBUSDET → 10kΩ → GND
          検出電圧 ≈ 3.4V (VL812 の検出閾値以上を確保)
    R1値: ________  R2値: ________
    確認: ________

━━━━━━━━━━━━━━━━━━━━━━━━━━━━━━━━━━━━━━━━━━━━━━━━━━
水晶 (Y1, 25MHz)  C番号: C9006
━━━━━━━━━━━━━━━━━━━━━━━━━━━━━━━━━━━━━━━━━━━━━━━━━━

[ok ] 水晶: X322525MOB4SI (25MHz, CL=12pF)
    期待周波数: 25.000 MHz
    確認: ________

ok[ ] 負荷キャップ CL1, CL2
    期待: それぞれ 18pF → GND
    注意: CL = (C1 × C2) / (C1 + C2) + Cstray ≈ 9pF + 3pF = 12pF ≒ CL(12pF) OK
    CL1値: ________  CL2値: ________
    確認: ________

[ok ] 水晶のシンボル: Crystal_GND24_Small (4端子、GNDピン2本がGNDに接続)
    確認: ________

━━━━━━━━━━━━━━━━━━━━━━━━━━━━━━━━━━━━━━━━━━━━━━━━━━
W25Q32JVSSIQ  SPI Flash (C82344)
━━━━━━━━━━━━━━━━━━━━━━━━━━━━━━━━━━━━━━━━━━━━━━━━━━

[? ] /CS (Pin 1): 10kΩ プルアップ → 3V3_HUB (アイドル時 CS HIGH を保持)
    確認: GNDにプルダウン

[ok ] DO/IO1 (Pin 2): VL812 の SPI MISO に接続
    確認: ________

[ok ] IO2 (Pin 3): 10kΩ → VCC (Write Protect, 通常 HIGH = WP 無効)
    確認: ________

[ok ] GND (Pin 4): GND に接続
    確認: ________

[ok ] DI/IO0 (Pin 5): VL812 の SPI MOSI に接続
    確認: ________

[ok ] CLK (Pin 6): VL812 の SPI CLK に接続
    確認: ________

⚠️ IO2 (Pin 3): 10kΩ → VCC (WP#, HIGH = 書き込み保護 無効)
    注意: エージェント解析で floating の可能性あり! フローティングは NG。
    現在の接続: 10k->3v3
    確認: ________

⚠️ IO3 (Pin 7): 10kΩ → VCC (HOLD#, HIGH = 通常動作)
    注意: エージェント解析で floating の可能性あり! フローティングは NG。
    現在の接続: 10k->3v3
    確認: ________

[ok ] VCC (Pin 8): 3V3_HUB + 100nF バイパスキャップ → GND
    確認: ________

━━━━━━━━━━━━━━━━━━━━━━━━━━━━━━━━━━━━━━━━━━━━━━━━━━
電源バイパスキャップ
━━━━━━━━━━━━━━━━━━━━━━━━━━━━━━━━━━━━━━━━━━━━━━━━━━

[ok ] DC33FB (3.3V コア電源): 4.7µF → GND
    値: ________
    確認: ________

[ok ] DC12FB (1.2V コア電源): 10µF + 100nF → GND
    値: ________
    確認: ________

[ok ] LX インダクタ (内部DC-DC用): 10µH
    値: ________
    確認: ________

[ok ] VBUS / VDD 各ピンのデカップリング
    期待: 各 VBUS ピンに 100nF 配置 (合計8ピン分)
    確認: ________

━━━━━━━━━━━━━━━━━━━━━━━━━━━━━━━━━━━━━━━━━━━━━━━━━━
⚠️ 重大確認: LX ピン / SSTX ピン (エージェント解析で未接続の疑い)
━━━━━━━━━━━━━━━━━━━━━━━━━━━━━━━━━━━━━━━━━━━━━━━━━━

⚠️ LX ピン (Pin 39) — 内部 1.2V 昇圧コンバータ スイッチングノード
    期待: L3 (10µH) のインダクタを LX と 1V2_HUB 出力の間に接続必須
    注意: LX が未接続だと内部1.2Vレギュレータが機能せず VL812 動作不可
    ⚠️ 解析では LX が floating として見えた → 手動で接続を確認すること
    現在の接続: 19μH->1v2
    確認: ________

⚠️ SSTX0+/− (Pins 22, 23) — Upstream SuperSpeed TX
    期待: USB3_UP_TX_P / USB3_UP_TX_N ネット → Cubie A7Z USB3.0
    注意: SSRX0 は接続確認できたが SSTX0 が floating の可能性あり
          SSTX0 未接続だと Upstream USB 3.0 (HOST→HUB) が機能しない
          (RX のみ接続 = USB3.0 のアップリンクが片方向のみ = 動作不可)
    ⚠️ 現在の接続を KiCad で確認: [22,23]->100nF->TX
    確認: ________

⚠️ SSTX1+/− (Pins 59, 60) — DP1 (外部USB-C) SuperSpeed TX
    期待: USB3_DP1_TX_P / USB3_DP1_TX_N → J_EXT_C
    注意: SSRX1 は接続確認済み。SSTX1 も接続が必要。
    ⚠️ 現在の接続: SSTX0と同じ
    確認: ________

⚠️ SSTX2+/− (Pins 66, 67) — DP2 (外部USB-A) SuperSpeed TX
    期待: USB3_DP2_TX_P / USB3_DP2_TX_N → J_EXT_A
    ⚠️ 現在の接続: SSTX0と同じ
    確認: ________

━━━━━━━━━━━━━━━━━━━━━━━━━━━━━━━━━━━━━━━━━━━━━━━━━━
USB 接続確認
━━━━━━━━━━━━━━━━━━━━━━━━━━━━━━━━━━━━━━━━━━━━━━━━━━

[ok ] Upstream (UP): Cubie A7Z USB3.0 (USB-C) → VL812
    SSRX0+/− (確認済) + SSTX0+/− (要確認) + USB2_UP_DP/DM (確認済)
[ok ] DP1 (Downstream 1): → J_EXT_C (外部USB-C) via TPS2042BDR / USBLC6
    USB2_DP1+/− + USB3_DP1_RX+/− (確認済) + SSTX1+/− (要確認)
[ok ] DP2 (Downstream 2): → J_EXT_A (外部USB-A) via TPS2042BDR / USBLC6
    USB2_DP2+/− + USB3_DP2_RX+/− (確認済) + SSTX2+/− (要確認)
[ok ] DP3 (Downstream 3): → RP2040 #1 USB2_RP_DP / USB2_RP_DM (USB2.0のみ)
[ok ] DP4 (Downstream 4): → RP2040 #2 USB2_RP_DP2 / USB2_RP_DM2 (USB2.0のみ)
[ok ] DP3/DP4: SSTX3/SSRX3/SSTX4/SSRX4 → No Connect (ERC 済み) ✓

[ok ] CC RP 抵抗 (外部USB-C ホスト側): 56kΩ × 2 (CC1/CC2 → VBUS_EXT)
    値: ________
    確認: ________

備考:
________________________________________________________________________________
________________________________________________________________________________

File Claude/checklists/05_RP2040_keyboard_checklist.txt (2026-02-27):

================================================================================
RP2040  キーボード専用 (#1) チェックシート
データシート: https://datasheets.raspberrypi.com/rp2040/rp2040-datasheet.pdf
JLCPCB C番号: C2040
パッケージ: LQFN-56 (7mm × 7mm)
シート: keyboard.kicad_sch / U6
================================================================================

■ 参考設計 (PROGRESS.md / Claude.md):
  USB: VL812 DP3 → RP2040 #1 (USB2.0)
  クリスタル: X322512MOB4SI (C70565), 12MHz, CL=12pF, 外付け15pF×2

━━━━━━━━━━━━━━━━━━━━━━━━━━━━━━━━━━━━━━━━━━━━━━━━━━
⚠️ GPIO 割り当て 確認 (最優先)
━━━━━━━━━━━━━━━━━━━━━━━━━━━━━━━━━━━━━━━━━━━━━━━━━━

以下は Claude.md の仕様。実際のシート配線と一致しているか確認すること。
エージェントが解析した結果と Claude.md に差異が見られた。要確認。

| GPIO | Claude.md 仕様 | 実際の接続 | 一致? |
|---|---|---|---|
| GP0  | COL0 (キーマトリクス) | ________ | [ok ] |
| GP1  | COL1 | ________ | [ok ] |
| GP2  | COL2 | ________ | [ok ] |
| GP3  | COL3 | ________ | [ok ] |
| GP4  | COL4 | ________ | [ok ] |
| GP5  | COL5 | ________ | [ok ] |
| GP6  | COL6 | ________ | [ok ] |
| GP7  | COL7 | ________ | [ok ] |
| GP8  | COL8 | ________ | [ok ] |
| GP9  | ROW0 | ________ | [ok ] |
| GP10 | ROW1 | ________ | [ok ] |
| GP11 | ROW2 | ________ | [ok ] |
| GP12 | ROW3 | ________ | [ok ] |
| GP13 | ROW4 | ________ | [ok ] |
| GP14 | ROW5 | ________ | [ok ] |
| GP15 | ROW6 | ________ | [ok ] |
| GP16 | ROW7 | ________ | [ok ] |
| GP17 | I2C_SCL (BQ25895) | ________ | [ok ] |
| GP18 | I2C_SDA (BQ25895) | ________ | [ok ] |
| GP19 | BQ_INT | ________ | [ ok] |
| GP20 | RP2040_EN (TPS61023 EN) | ________ | [ok ] |
| GP21 | LED_CHG (橙) | ________ | [ok ] |
| GP22 | LED_FULL (緑)  | ________ | [ok ] |
| GP23 | LED_ACT (緑) | ________ | [ok ] |
| GP24 | USB_VBUS_EN (TPS61023 #2 EN) | 前回セッションにて未修正 | [? ] |
| GP25 | SW_DET (電源ボタン検出) | 未接続 | [? ] |
| GP26 | J_FAN PWM (FAN_PWM) | ________ | [ok ] |
| GP27 | アナログスティック X (ADC1) | ________ | [ok ] |
| GP28 | アナログスティック Y (ADC2) | ________ | [ok ] |
| GP29 | 予備 | ________ | [ok ] |

━━━━━━━━━━━━━━━━━━━━━━━━━━━━━━━━━━━━━━━━━━━━━━━━━━
電源デカップリング
━━━━━━━━━━━━━━━━━━━━━━━━━━━━━━━━━━━━━━━━━━━━━━━━━━

RP2040 は DVDD, IOVDD, USB_VDD 等に複数の電源ピンあり。
各電源ピンの近傍に 100nF を配置する必要がある。

[ok ] IOVDD (3.3V) ピン: 各ピンに 100nF バイパスキャップ配置
    IOVDD ピン数: ________  使用バイパスキャップ総数: ________
    確認: ________

[ok ] DVDD (1.1V 内部 LDO 出力): 100nF バイパスキャップ配置
    VREG_VIN: 3.3V から内部 LDO へ (100nF バイパス)
    VREG_VOUT: 内部 LDO 出力 ≈1.1V (100nF バイパス, RP2040 外側)
    確認: ________

[ok ] USB_VDD: 3.3V + 100nF バイパス
    確認: ________

[ok ] ADC_AVDD: 3.3V + 100nF バイパス (アナログ電源)
    確認: ________

━━━━━━━━━━━━━━━━━━━━━━━━━━━━━━━━━━━━━━━━━━━━━━━━━━
クリスタル (Y2, 12MHz)  C70565
━━━━━━━━━━━━━━━━━━━━━━━━━━━━━━━━━━━━━━━━━━━━━━━━━━

[? ] Y2: X322512MOB4SI (12MHz, CL=12pF, SMD3225-4P)
    確認: シンボルが間違っている可能性あり

[ok ] 負荷キャップ C65, C68: それぞれ 15pF → GND
    検証: CL実効 = (15 × 15) / (15 + 15) + Cstray ≈ 7.5 + 3-4pF ≈ 11-12pF ≒ OK
    C65値: ________  C68値: ________
    確認: ________

[ok ] クリスタル接続: XIN (RP2040 pin 20) と XOUT (pin 21) に接続
    確認: ________

━━━━━━━━━━━━━━━━━━━━━━━━━━━━━━━━━━━━━━━━━━━━━━━━━━
QSPI Flash W25Q32JVSSIQ (C82344)
━━━━━━━━━━━━━━━━━━━━━━━━━━━━━━━━━━━━━━━━━━━━━━━━━━

[ok ] QSPI_SS (/CS): RP2040 QSPI_SS → W25Q32 /CS (Pin 1)
    プルアップ: 10kΩ → 3.3V (起動前の CS HIGH 維持)
    確認: ________

[ok ] QSPI_SD0 (IO0/DI): RP2040 QSPI_SD0 ↔ W25Q32 DI/IO0 (Pin 5)
[ok ] QSPI_SD1 (IO1/DO): RP2040 QSPI_SD1 ↔ W25Q32 DO/IO1 (Pin 2)
[ok ] QSPI_SD2 (IO2/WP#): RP2040 QSPI_SD2 ↔ W25Q32 IO2 (Pin 3)
[ok ] QSPI_SD3 (IO3/HOLD#): RP2040 QSPI_SD3 ↔ W25Q32 IO3 (Pin 7)
[ok ] QSPI_SCLK: RP2040 QSPI_SCLK ↔ W25Q32 CLK (Pin 6)
[ok ] W25Q32 VCC (Pin 8): 3.3V + 100nF バイパス
[ok ] W25Q32 GND (Pin 4): GND
    確認: ________

━━━━━━━━━━━━━━━━━━━━━━━━━━━━━━━━━━━━━━━━━━━━━━━━━━
USB 接続
━━━━━━━━━━━━━━━━━━━━━━━━━━━━━━━━━━━━━━━━━━━━━━━━━━

[ok ] USB_DP (pin 47): USB2_RP_DP ネット → VL812 DP3
    直列抵抗 R27=27Ω: USB_DP → R27 → VL812
    確認: ________

[? ] USB_DM (pin 46): USB2_RP_DM ネット → VL812 DP3
    直列抵抗 R28=27Ω: USB_DM → R28 → VL812
    ⚠️ 注意: RP2040 は内部に 27Ω 直列抵抗を内蔵している。
       外部 27Ω を追加すると合計 ≈54Ω となり USB 規格(45Ω)を超過する。
       Raspberry Pi Pico の回路図では外部抵抗なし。
       → 外部 27Ω は削除した方が安全かもしれない。要検討。
    現状: R27/R28 = 27
    確認: ________

━━━━━━━━━━━━━━━━━━━━━━━━━━━━━━━━━━━━━━━━━━━━━━━━━━
RUN ピン (リセット)
━━━━━━━━━━━━━━━━━━━━━━━━━━━━━━━━━━━━━━━━━━━━━━━━━━

[ok ] RUN ピン (pin 30): 10kΩ プルアップ → 3.3V
    注意: RUN が LOW になると RP2040 はリセット。フローティング NG。
    プルアップ値: ________
    確認: ________

━━━━━━━━━━━━━━━━━━━━━━━━━━━━━━━━━━━━━━━━━━━━━━━━━━
SWD (デバッグ)
━━━━━━━━━━━━━━━━━━━━━━━━━━━━━━━━━━━━━━━━━━━━━━━━━━

[ok ] SWCLK, SWDIO: No Connect (SWD 未使用として ERC 対処済み)
    確認: ________

[ok ] TESTEN ピン: GND に接続
    確認: ________

━━━━━━━━━━━━━━━━━━━━━━━━━━━━━━━━━━━━━━━━━━━━━━━━━━
キーマトリクス
━━━━━━━━━━━━━━━━━━━━━━━━━━━━━━━━━━━━━━━━━━━━━━━━━━

[ok ] キー数: 63個 (K_SW1 〜 K_SW63)
[ok ] ダイオード数: 63個 (1N4148W, SOD-323)
[ok ] ダイオード方向: カソード → COL 側 (アノード → SW → ROW 側)
    注意: COL が出力 (High/Low), ROW が入力 (Pull-up してスキャン)
    ダイオード方向確認: ________
[ok ] COL9本 × ROW8本 = 72 マトリクス → 63キー配置で空き9セル存在
    → 空きセルのデフォルト状態確認不要 (実際のスイッチが接続されていないだけ)

━━━━━━━━━━━━━━━━━━━━━━━━━━━━━━━━━━━━━━━━━━━━━━━━━━
3DS アナログスティック FPC (J1, Molex 5034800440, C3170007)
━━━━━━━━━━━━━━━━━━━━━━━━━━━━━━━━━━━━━━━━━━━━━━━━━━

[? ] Pin 1: VCC → +3V3 (RP2040 IOVDD と同電圧で OK)
[ok ] Pin 2: X 軸 → STICK_X → GP27 (ADC1)
[? ] Pin 3: Y 軸 → STICK_Y → GP28 (ADC2)
[? ] Pin 4: GND
    確認: gnd x 3v3 yになっているはず

━━━━━━━━━━━━━━━━━━━━━━━━━━━━━━━━━━━━━━━━━━━━━━━━━━
LED 回路 (GP21, GP22, GP23)
━━━━━━━━━━━━━━━━━━━━━━━━━━━━━━━━━━━━━━━━━━━━━━━━━━

[ ] LED_CHG (橙): GPIO → 330Ω → LED アノード → LED カソード → GND
    抵抗値: ________
    確認: ________

[ ] LED_FULL (緑): GPIO → 330Ω → LED アノード → LED カソード → GND
    抵抗値: ________
    確認: ________

[ ] LED_ACT (緑): GPIO → 330Ω → LED アノード → LED カソード → GND
    抵抗値: ________
    確認: ________

注意: LED C番号 (緑・橙) は TBD のまま。PCBレイアウト前に確定必要。

━━━━━━━━━━━━━━━━━━━━━━━━━━━━━━━━━━━━━━━━━━━━━━━━━━
I2C + 電源ボタン 検出
━━━━━━━━━━━━━━━━━━━━━━━━━━━━━━━━━━━━━━━━━━━━━━━━━━

[ ] I2C_SCL (GP17): R26=10kΩ → 3.3V (プルアップ) 確認
[ ] I2C_SDA (GP18): R29=10kΩ → 3.3V (プルアップ) 確認
[ ] BQ_INT (GP19): BQ25895 INTピン → 10kΩ → 3.3V、GP19 に接続
[ ] SW_DET (GP25): 電源ボタン検出
    回路: VSYS → 10kΩ → SW1_OUT → 10kΩ → GND → GP25 (分圧で約2.1V → 3.3V 入力OK)
    注意: VSYS(4.2V) を直接 GPIO に入れると破損。分圧で 3.3V 以下にすること。
    現在の分圧比: ________
    確認: ________

備考:
________________________________________________________________________________
________________________________________________________________________________

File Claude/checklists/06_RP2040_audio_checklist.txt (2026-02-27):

================================================================================
RP2040  オーディオ専用 (#2) チェックシート
JLCPCB C番号: C2040
パッケージ: LQFN-56
シート: audio.kicad_sch / U11
================================================================================

■ 参考情報:
  USB: VL812 DP4 → RP2040 #2 (USB2.0 Audio)
  クリスタル: Y3 = 12MHz (C74/C75 = 15pF×2)
  エージェント解析: U11, Crystal=Y3, USB=USB2_RP_DP2/USB2_RP_DM2

━━━━━━━━━━━━━━━━━━━━━━━━━━━━━━━━━━━━━━━━━━━━━━━━━━
GPIO 割り当て確認
━━━━━━━━━━━━━━━━━━━━━━━━━━━━━━━━━━━━━━━━━━━━━━━━━━

| GPIO | 期待値 | 実際の接続 | 一致? |
|---|---|---|---|
| GP0  | I2S BCLK → I2S_BCLK ネット | ________ | [ok ] |
| GP1  | I2S LRCLK → I2S_LRCLK ネット | ________ | [ok ] |
| GP2  | I2S SDIN → I2S_SDIN ネット | ________ | [ok ] |
| GP3  | SD_MODE (MAX98357A スピーカー制御) | ________ | [ok ] |
| GP4  | XSMT (PCM5102A ミュート) | ________ | [ok ] |
| GP5  | HP_EN (TPA6132A2 Enable) | ________ | [ok ] |
| GP6  | HP_DET (イヤホン挿入検出) | ________ | [ok ] |
| GP7〜GP29 | 未使用/予備 | — | — |

━━━━━━━━━━━━━━━━━━━━━━━━━━━━━━━━━━━━━━━━━━━━━━━━━━
電源デカップリング
━━━━━━━━━━━━━━━━━━━━━━━━━━━━━━━━━━━━━━━━━━━━━━━━━━

(#1 と同じ構成)
[ok ] IOVDD 各ピン: 100nF バイパスキャップ
[ok ] VREG_VIN: 100nF バイパス
[ok ] VREG_VOUT: 100nF バイパス (≈1.1V)
[ok ] USB_VDD: 100nF バイパス
[ok ] ADC_AVDD: 100nF バイパス
    確認: ________

━━━━━━━━━━━━━━━━━━━━━━━━━━━━━━━━━━━━━━━━━━━━━━━━━━
クリスタル (Y3, 12MHz)
━━━━━━━━━━━━━━━━━━━━━━━━━━━━━━━━━━━━━━━━━━━━━━━━━━
修正済み
[ ] Y3 = 12MHz (X322512MOB4SI, CL=12pF)
[ ] C74 = 15pF → GND
[ ] C75 = 15pF → GND
    確認: ________

━━━━━━━━━━━━━━━━━━━━━━━━━━━━━━━━━━━━━━━━━━━━━━━━━━
QSPI Flash W25Q32 (RP2040 #2 用)
━━━━━━━━━━━━━━━━━━━━━━━━━━━━━━━━━━━━━━━━━━━━━━━━━━

[ ] QSPI_SS: 10kΩ プルアップ → 3.3V
[ ] QSPI_SD0〜SD3, SCLK: RP2040 QSPI ↔ W25Q32 接続
[ ] W25Q32 VCC: 3.3V + 100nF バイパス
    確認: ________

━━━━━━━━━━━━━━━━━━━━━━━━━━━━━━━━━━━━━━━━━━━━━━━━━━
USB 接続
━━━━━━━━━━━━━━━━━━━━━━━━━━━━━━━━━━━━━━━━━━━━━━━━━━
#1と同じく
[ ] USB_DP: USB2_RP_DP2 ネット → VL812 DP4
[ ] USB_DM: USB2_RP_DM2 ネット → VL812 DP4
    ⚠️ #1 と同様: 外部 27Ω 直列抵抗の有無を確認
       (RP2040 内蔵 27Ω + 外部 27Ω = 54Ω > USB規格 45Ω の恐れ)
    確認: ________

━━━━━━━━━━━━━━━━━━━━━━━━━━━━━━━━━━━━━━━━━━━━━━━━━━
RUN / TESTEN / SWD
━━━━━━━━━━━━━━━━━━━━━━━━━━━━━━━━━━━━━━━━━━━━━━━━━━
#1と同じ
[ ] RUN ピン: 10kΩ → 3.3V
[ ] TESTEN: GND
[ ] SWCLK/SWDIO: No Connect
    確認: ________

備考:
________________________________________________________________________________

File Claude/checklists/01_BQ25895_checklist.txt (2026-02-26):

================================================================================
BQ25895RTWR 充電IC チェックシート
データシート: https://www.ti.com/lit/ds/symlink/bq25895.pdf
JLCPCB C番号: C80200
パッケージ: QFN-24 (4mm × 4mm, 0.5mmピッチ)
シート: power.kicad_sch / U1
================================================================================

■ 参考設計決定事項 (PROGRESS.md session15より):
  - L1: SW → SYS 接続の NVDC トポロジー (L1接続変更 +BATT→SYS修正済み)
  - C5: 100nF → 4.7µF (REGN bypass) に変更済み
  - C6: 4.7µF → 10µF (PMID cap) に変更済み
  - SYS cap: 10µF追加 (合計20µF / TI推奨値)
  - TS: 分圧固定 (NTC不使用、温度センシング無効化)
  - STAT LED: 330Ω + LED (アノード=3V3, カソード=STATピン)
  - D1(STAT LED)極性修正済み

━━━━━━━━━━━━━━━━━━━━━━━━━━━━━━━━━━━━━━━━━━━━━━━━━━
PIN CHECK
━━━━━━━━━━━━━━━━━━━━━━━━━━━━━━━━━━━━━━━━━━━━━━━━━━

[ok] Pin 1 : VBUS
    期待: J_USB_PWR の VBUS に接続
          100nF + 1µF バイパスキャップ → AGND (ピン近傍に配置)
    確認: ________

[ok ] Pin 2 : D+ (USB_DP)
    期待: J_USB_PWR の DP1/DP2 → BQ25895 D+ (BC1.2充電検出用)
    確認: ________

[ok ] Pin 3 : D- (USB_DM)
    期待: J_USB_PWR の DN1/DN2 → BQ25895 D- (BC1.2充電検出用)
    確認: ________

[ok ] Pin 4 : STAT (充電ステータス、オープンドレイン出力)
    期待: 3V3 → R3(330Ω) → LED_CHG(アノード) → LED_CHG(カソード) → STATピン
          STAT は電流シンク (LOW=充電中で点灯)
    注意: STATピン自体はオープンドレイン。外部プルアップは R3+LED で兼用。
    確認: ________

[? ] Pin 5 : SCL (I2C クロック)
    期待: I2C_SCL ネット → RP2040 #1 GP17
          4.7kΩ プルアップ → 3.3V (keyboard シートに配置)
    確認: 10kΩでプルアップされている なおTIのデータシートのSystem Examplesは10kΩでプルアップ

[? ] Pin 6 : SDA (I2C データ)
    期待: I2C_SDA ネット → RP2040 #1 GP18
          4.7kΩ プルアップ → 3.3V (keyboard シートに配置)
    確認: 10kΩでプルアップされている なおTIのデータシートのSystem Examplesは10kΩでプルアップ

[ok ] Pin 7 : INT (割り込み出力、オープンドレイン)
    期待: BQ_INT ネット → RP2040 #1 GP19
          10kΩ プルアップ → 3.3V
    確認: ________

[ok ] Pin 8 : OTG (OTG 有効化)
    期待: OTG 未使用のため GND に接続 (またはNCで内部プルダウン)
    注意: フローティングにしないこと
    確認: ________

⚠️ Pin 9 : CE (充電許可、アクティブLow)
    エージェント解析結果: CE ピンが +3V3 に接続されている可能性
    ・CE = HIGH (+3V3) の場合: ハードウェア充電は無効化される
      → ただし I2C レジスタ (REG03 bit4=1) で充電 ON にすることは可能
    ・CE = LOW (GND) の場合: 常時ハードウェア充電許可

    どちらが意図か確認:
    [〇 ] GND 接続 (常時充電許可、I2C での OFF 制御は可能)
    [ ] +3V3 接続 (I2C での明示的な有効化が必要)
    ⚠️ CE が 3V3 の場合: 起動時に I2C で充電を有効にするコードが必要
    現在の接続: 3V3にプルアップされている TIのExamではHostにつながっているのみ
    確認: ________

[? ] Pin 10 : ILIM (入力電流制限設定)
    期待: 抵抗 → AGND (入力電流上限設定用)
          推奨値: 53.6kΩ (≈2A制限) または 40kΩ (≈2.5A制限)
          BQ25895 ILIM式: I_ILIM_HW = 1660 / R_ILIM[kΩ] [mA]
    現在の抵抗値: 270Ω  計算電流: ________
    確認: Tiのexamは260Ω
備考：TIのDescription
Input current limit Input. ILIM pin sets the maximum input current and can be used to monitor input current
ILIM pin sets the maximum input current limit by regulating the ILIM voltage at 0.8 V. A resistor is connected
from ILIM pin to ground to set the maximum limit as IINMAX = KILIM/RILIM . The actual input current limit is the
lower limit set by ILIM pin (when EN_ILIM bit is high) or IIINLIM register bits. Input current limit of less than 500
mA is not support on ILIM pin.
ILIM pin can also be used to monitor input current when the voltage is below 0.8V. The input current is
proportional to the voltage on ILIM pin and can be calculated by IIN = (KILIM x VILIM) / (RILIM x 0.8)
The ILIM pin function can be disabled when EN_ILIM bit is 0.

[? ] Pin 11 : TS (温度センシング)
    期待: 分圧固定で温度OK範囲を維持
          推奨回路: REGN(4.5V) → 5.23kΩ → TS → 3kΩ → AGND
          (V_TS ≈ 0.37×VREGN = 正常温度範囲内)
          または REGN → 2kΩ → TS → 2kΩ → GND (V_TS = 0.5×VREGN)
    現在の接続: 10kΩと10kΩの接続
    注意: REGN を使う場合、REGNのバイパスキャップが先に決まること
    確認: TIのexamは10kΩずつの分圧

[? ] Pin 12 : QON (シップモード制御、アクティブLow)
    期待: 10kΩ プルアップ → REGN または 3.3V (シップモード無効)
          またはNCでもよい (内部プルアップあり)
    確認: TiのexamはGNDに落ちている

[ok ] Pin 13-14 : BAT (バッテリー接続)
    期待: +BATT ネット → バッテリー正極 (J_BAT Pin1)
          10µF バイパスキャップ → PGND
    注意: 2本のピン両方が接続されていること
    確認: 最大5Aが流れる部分なので複数pinに分けなくても大丈夫か

[ok ] Pin 15-16 : SYS (システム出力)
    期待: VSYS/5V_SYS ネット → TPS61023 #1/#2 の VIN
          合計 20µF バイパスキャップ → PGND (TI推奨)
    注意: 2本のピン両方が接続されていること
          SYS ライン最大 5〜6A → PCB パターン極太必須
    確認: 100nFのコンデンサーもついている

[ok ] Pin 17-18 : PGND (パワーグランド)
    期待: GNDPWR/PGND プレーンに接続
          2本のピン両方が接続されていること
    確認: ________

[ok ] Pin 19-20 : SW (スイッチングノード)
    期待: インダクタ L1 の一端に接続
          L1 他端 → SYS (NVDC トポロジー)
          L1 値: 2.2µH, 電流定格 ≥4A, DCR 低め推奨
    注意: SW ノードには AC バイパスキャップ不要 (スイッチングノード!)
    確認: ________

[? ] Pin 21 : BTST (ブートストラップ)
    期待: 100nF キャップ → SW (BTST と SW を 100nF で接続)
    確認: TIのexamは47nF

⚠️ Pin 22 : REGN (内部 LDO 出力 ≈4.5V)
    期待: 4.7µF バイパスキャップ → GND のみ!
    注意: REGN は BQ25895 内部の LDO 出力。外部電源(3.3V等)に接続してはいけない。
          外部電源に接続するとデバイス破損の恐れがある。
    ⚠️ 要確認: REGN が 3.3V や 5V 電源ネットに接続されていないこと!
    ⚠️ 要確認: C5 の値が 4.7µF であること (4.7nF は NG)
    現在の接続: 特に問題なし  C5値: 4.7nF
    確認: コンデンサーの値が低すぎる修正必須

[? ] Pin 23 : PMID (内部 MOSFET 中間ノード)
    期待: 4.7µF バイパスキャップ → AGND
    ⚠️ C6 が 10µF であること確認 (PROGRESS.md で 4.7µF→10µF に修正)
    C6値: 10µF
    確認: 10or4.7? TIのexamはOTGを使う影響か60µF

[ok ] Pin 24 : DSEL (USB データ送受信方向選択)
    期待: GND (標準 USB BC1.2 検出モード)
          または REGN に接続 (CDP/DCP 優先モード)
    確認: GNDに落ちている

[ok ] EP (露出パッド)
    期待: PGND (パワーグランド) に接続
          サーマルビア推奨
    確認: ________

━━━━━━━━━━━━━━━━━━━━━━━━━━━━━━━━━━━━━━━━━━━━━━━━━━
バイパスキャップ まとめ確認
━━━━━━━━━━━━━━━━━━━━━━━━━━━━━━━━━━━━━━━━━━━━━━━━━━

[? ] VBUS バイパス: 100nF + 1µF → AGND   値: 10µF+100nF
[ok ] PMID バイパス (C6): 10µF → AGND     値: ________
[NG ] REGN バイパス (C5): 4.7µF → GND    値: 4.7nF ⚠️ 4.7nFは NG!
[? ] SYS バイパス: 合計 20µF → PGND     値: 追加で100nF
[? ] BAT バイパス: 10µF → PGND          値: 追加で100nF
[ok ] BTST キャップ: 100nF (SW-BTST間)   値: ________

━━━━━━━━━━━━━━━━━━━━━━━━━━━━━━━━━━━━━━━━━━━━━━━━━━
その他確認
━━━━━━━━━━━━━━━━━━━━━━━━━━━━━━━━━━━━━━━━━━━━━━━━━━

[? ] I2C_SCL/SDA プルアップ: 4.7kΩ → 3.3V (keyboard シートに配置か確認)
[ok ] BQ_INT プルアップ: 10kΩ → 3.3V
[ok ] STAT LED 接続方向: アノード側→3V3→R3(330Ω)、カソード→STATピン
[? ] TS 分圧固定値: 正常温度範囲内に設定されているか
    (V_TS / V_REGN が 0.19 〜 0.60 の範囲内であること)
[ok ] J_BAT コネクタ: Pin1=+BATT, Pin2=GND (極性間違いは危険!)

備考:
________________________________________________________________________________
________________________________________________________________________________

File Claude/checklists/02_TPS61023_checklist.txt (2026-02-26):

================================================================================
TPS61023DRLR 昇圧DC-DC チェックシート (×2個)
データシート: https://www.ti.com/lit/ds/symlink/tps61023.pdf
JLCPCB C番号: C919459
パッケージ: SOT-563 (6ピン, 1.6mm×1.2mm)
シート: power.kicad_sch / U2 (#1: 5V_SYS用), U3 (#2: USB_5V_SYS用)
================================================================================

■ TPS61023 ピン配置 (SOT-563):
  Pin 1: GND
  Pin 2: SW (スイッチングノード)
  Pin 3: FB (フィードバック)
  Pin 4: VIN (入力)
  Pin 5: EN (イネーブル, アクティブHigh)
  Pin 6: PS/SYNC (パワーセーブ/同期)

■ 5V出力設定用 FB 抵抗値:
  Vout = 0.5 × (1 + R_TOP / R_BOT)
  5V = 0.5 × (1 + R_TOP / R_BOT)  →  R_TOP / R_BOT = 9
  推奨: R_BOT = 100kΩ, R_TOP = 910kΩ  (R9 = 910kΩ は power シートで確認済み)

━━━━━━━━━━━━━━━━━━━━━━━━━━━━━━━━━━━━━━━━━━━━━━━━━━
TPS61023 #1 (U2) — 5V_SYS 出力 (Cubie A7Z / VL812 / HDMI コントローラ)
━━━━━━━━━━━━━━━━━━━━━━━━━━━━━━━━━━━━━━━━━━━━━━━━━━

[ok ] Pin 1 : GND
    期待: GND/GNDPWR プレーンに接続
    確認: ________

[? ] Pin 2 : SW (スイッチングノード)
    期待: インダクタ L2 の一端
          L2 他端 → 5V_SYS 出力
    インダクタ値: 1µH (推奨: 1µH, 電流定格 ≥2A, DCR低め)
    注意: TPS61023 のインダクタは 1µH 推奨 (BQ25895 用の 2.2µH とは別)
    確認: TIデータシートではVSYS(VINにつながっている)、現在の回路図もそうなっている

[ ] Pin 3 : FB (フィードバック)
    期待: FB に R_TOP (910kΩ) と R_BOT (100kΩ) の分圧接続
          R_TOP: FB → 5V_SYS 出力
          R_BOT: FB → GND
          → Vout = 0.5 × (1 + 910k/100k) = 5.05V ≒ 5V ✓
    R_TOP値: 910k  R_BOT値: 100k
    計算出力電圧: ________
    確認: TI ExamはR_TOPが732k

[? ] Pin 4 : VIN
    期待: VSYS (+BATT ≈ 3.7〜4.2V) に接続
          100nF バイパスキャップ → GND (VIN 近傍)
    確認: 100nF+10µF

[ok ] Pin 5 : EN (イネーブル)
    期待: BAT54 ダイオード経由で GP20 (RP2040_EN) に接続
          BAT54: アノード→GP20, カソード→ENノード
          ENノード: 10µF キャップ → GND (τ = RC ≈ 1秒 の起動ラッチ)
          モーメンタリボタン SW1: ENノード → 3V3または+BATT 経由 (押したとき HIGH)
          キルスイッチ SW2: EN → GND 経由 (緊急停止)
    ⚠️ 要確認: BAT54 の向き (アノード→GP20側, カソード→EN側)
    ⚠️ 要確認: ENノードの 10µF キャップが接続されているか
    確認: Enable logic input. Logic high voltage enables the device. Logic low voltage disables the
device and turns it into shutdown mode.

[?????????? ] Pin 6 : PS/SYNC
    期待: GND に接続 (パワーセーブ PFM モード)
          または VIN に接続 (強制 PWM モード、EMI 低減)
    現在の接続: ________
    確認: Pin6はVOUT PS/SYNCは存在しない

[ok ] 出力バイパスキャップ (5V_SYS)
    期待: 10µF (セラミック) → GND (出力ノード近傍)
    値: 22µF+100nF
    確認: ________

━━━━━━━━━━━━━━━━━━━━━━━━━━━━━━━━━━━━━━━━━━━━━━━━━━
TPS61023 #2 (U3) — USB_5V_SYS 出力 (外部USBポート VBUS専用)
━━━━━━━━━━━━━━━━━━━━━━━━━━━━━━━━━━━━━━━━━━━━━━━━━━

#1同様

[ ] Pin 1 : GND
    期待: GND/GNDPWR プレーンに接続
    確認: ________

[ ] Pin 2 : SW
    期待: インダクタ L3 の一端 → USB_5V_SYS 出力
    インダクタ値: ________ (推奨: 1µH, ≥2A)
    確認: ________

[ ] Pin 3 : FB
    期待: #1 と同じ分圧回路 (910kΩ / 100kΩ で 5V 設定)
    R_TOP値: ________  R_BOT値: ________
    確認: ________

[ ] Pin 4 : VIN
    期待: VSYS に接続 + 100nF バイパスキャップ
    確認: ________

[ ] Pin 5 : EN (イネーブル)
    期待: USB_VBUS_EN ネット → RP2040 #1 GP24 で制御
          GP24 HIGH = USB ポートに電源供給
          GP24 LOW  = USB ポート電源オフ
    注意: GP24 は 3.3V 出力。TPS61023 EN の VIH(min) = 1.1V → OK
    確認: ________

[ ] Pin 6 : PS/SYNC
    期待: GND (PFM モード)
    確認: ________

[ ] 出力バイパスキャップ (USB_5V_SYS)
    期待: 10µF (セラミック) → GND
    値: ________
    確認: ________

━━━━━━━━━━━━━━━━━━━━━━━━━━━━━━━━━━━━━━━━━━━━━━━━━━
共通確認事項
━━━━━━━━━━━━━━━━━━━━━━━━━━━━━━━━━━━━━━━━━━━━━━━━━━

[? ] VIN バイパスキャップ: U2, U3 それぞれ 100nF → GND
[ok ] SW ノードに AC バイパスキャップが接続されていない (スイッチングノードなので不要)
[ok ] FB ピンに直接電源やGNDが接続されていない (分圧のみ)
[ok ] VSYS ネット配線: BQ25895 SYS → TPS61023 #1/#2 VIN 経路が正しいか
[? ] キルスイッチ SW2 の接続先確認
    - SPDT: SW2のスロー側 (C端子) → EN ノード
             SW2のNA端子 → GND (キル状態)
             SW2のNB端子 → NC または 上位接続

電源スイッチ回路全体の動作確認:
  [ok ] SW1 押下: EN HIGH → TPS61023 起動 → 3V3 生成 → RP2040 起動
  [ok ] SW1 離す: ENノード の 10µF キャップが電荷保持 → RP2040 が GP20 で EN を HIGH 維持
  [ok ] RP2040 GP20 LOW: EN LOW → TPS61023 停止 (通常 shutdown)
  [? ] SW2 キル: EN 強制 GND → TPS61023 即時停止

備考:
キルスイッチはVSYS自体を物理的に遮断するもの
KillSWとEN_SWが#1と#2でそれぞれ存在する共通化する必要あり

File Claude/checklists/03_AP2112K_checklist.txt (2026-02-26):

================================================================================
AP2112K-3.3TRG1  3.3V LDO チェックシート
データシート: https://www.diodes.com/assets/Datasheets/AP2112.pdf
JLCPCB C番号: C51118
パッケージ: SOT-25-5 (5ピン)
シート: power.kicad_sch / U4
================================================================================

■ AP2112K ピン配置 (SOT-25-5):
  Pin 1: GND
  Pin 2: VOUT (出力)
  Pin 3: EN (イネーブル, アクティブHigh, CMOS)
  Pin 4: NC または SNS (固定電圧版では NC でよい)
  Pin 5: VIN (入力)

■ 仕様:
  入力電圧: 2.0V ~ 6.0V
  出力電圧: 3.3V 固定 (AP2112K-3.3 版)
  最大出力電流: 600mA
  ドロップアウト電圧: 250mV typ @ 600mA
  EN 閾値: VIH=1.6V (min), VIL=0.4V (max)

■ 電流計算:
  消費先: RP2040 #1 + #2 (各~45mA typ, max~120mA)
          LED ×3 (各~3mA @ 330Ω / 3.3V-Vf)
          アナログスティック (~2mA)
          PCM5102A (~8mA), TPA6132A2 (~10mA typ)
  合計 max ≈ 300mA 程度 → 600mA 定格で余裕あり

━━━━━━━━━━━━━━━━━━━━━━━━━━━━━━━━━━━━━━━━━━━━━━━━━━
PIN CHECK
━━━━━━━━━━━━━━━━━━━━━━━━━━━━━━━━━━━━━━━━━━━━━━━━━━

[ok ] Pin 1 : VOUT
    期待: +3V3 ネットに接続
          出力バイパスキャップ 1µF (以上) → GND
    注意: データシートでは VOUT に 1µF 以上必要。10µF でも可。
    バイパス値: 10µF
    確認: ________

[ok ] Pin 2 : GND
    期待: GND プレーンに接続
    確認: 

[ok ] Pin 3 : EN (イネーブル)
    期待: 常時 ON = 5V_SYS または VIN に直接接続 (またはプルアップのみ)
          または 10kΩ → VIN (プルアップで常時 ON)
    注意: フローティングにしない。VIN 直結で常時 ON が最も単純。
    現在の接続: 5V_SYS
    確認: ________

[ok ] Pin 4 : NC
    期待: 未接続 (固定電圧版 AP2112K-3.3 では SNS は VOUT に内部接続済み)
    確認: ________

[ok ] Pin 5 : VIN
    期待: 5V_SYS に接続
          入力バイパスキャップ 1µF → GND (VIN ピン近傍)
    注意: 5V_SYS がない状態では LDO は動作しない。
          TPS61023 #1 が起動した後に 3.3V が生成される。
    バイパス値: 10µF
    確認: ________

━━━━━━━━━━━━━━━━━━━━━━━━━━━━━━━━━━━━━━━━━━━━━━━━━━
全体確認
━━━━━━━━━━━━━━━━━━━━━━━━━━━━━━━━━━━━━━━━━━━━━━━━━━

[ok ] VIN = 5V_SYS → VOUT = +3V3 の電源フロー確認
[ok ] EN ピンが適切にプルアップされている (フローティング NG)
[ok ] 入力・出力バイパスキャップが両方配置されている
[ok ] VOUT (+3V3) はどのネットに接続されているか確認
    接続先: RP2040 #1 / #2 VDD, PCM5102A VCC/VDD, TPA6132A2 VDD,
            BQ25895 の I2C プルアップ, 各種ロジック電源

備考:
+3V3は未確認各ICセクションで確認

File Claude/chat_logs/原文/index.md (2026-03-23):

# PortaRe0 原文チャットログ索引

> 参照形式: SセッションNN LおよそN行目（例: S07 L180）
> ファイル: chat_logs/原文/YYYY-MM-DD_SessionNN.txt
> Session08・Session09は原文ファイルなし（session10内・要約_archive内で内容確認可能）

---

## セッション別索引

### Session01 (2026-02-19) - 2026-02-19_Session01.txt
- L1: プロジェクト概要・クラムシェル型Cyberdeckの構想開始
- L50: Cubie A7Z SBC選定・スペック確認
- L100: ディスプレイ選定（LS055R1SX04 5.5インチ）
- L200: 電源設計・BQ25895充電IC選定
- L300: USBポート割り当て（USB-C USB3.0→ハブ、USB-C USB2.0→充電、Micro HDMI→ディスプレイ）
- L400: VL812 USBハブチップ選定
- L500: 筐体フォームファクタ検討（クラムシェル・ボトム139×81mm）
- L700: キーボードスイッチ選定（Alps SKRPABE010）・アナログスティック検討
- L900: RP2040選定（QMK対応）
- L1100: PCB構成（4層・JLCPCB PCBA）
- L1300: バッテリー選定（LiPo 6060100 / 3500mAh）
- L1500: サブ基板設計（メイン基板スロット穴への垂直挿入方式）
- L1647: コの字構造・PCB to PCB接続方式の確定
- L1800: パッシブ冷却方針（ヒートパイプ＋小型ヒートシンク）

### Session02 (2026-02-19) - 2026-02-19_Session02.txt
- L1: スピーカー選定（秋月 23×16mm 8Ω）・MAX98357Aモノラル→ステレオ変更
- L90: MAX98357A × 2（ステレオ構成）確定
- L150: I2S SD_MODEピンのL/R切り替え方法最初の議論
- L350: AliExpress購入リスト整理（Cubie A7Z・LiPo・ヒートパイプ等）
- L500: 冷却設計（ヒートパイプ経路・ヒートシンク配置）
- L600: BQ25895周辺回路の設計開始・datasheet確認

### Session03 (2026-02-19) - 2026-02-19_Session03.txt
- L1: 前セッション継続確認・KiCad BQ25895配置から再開
- L26: BQ25895ピン配置・全ピン接続指示（VBUS/D+/D-/SCL/SDA/INT/OTG/CE/ILIM/TS/QON）
- L64: STATピン・LEDおよびプルアップ接続
- L87: TS（Pin11）→ REGN分圧方式（10kΩ×2）に修正
- L109: KiCadネットラベル・グローバルラベルの使い分け説明
- L165: TS処理の最終確定：REGN→R6(10kΩ)→TS→R7(10kΩ)→GND
- L198: BQ25895 TSピン接続方法の最終決定

### Session04 (2026-02-19) - 2026-02-19_Session04.txt
- L1: プロジェクト計画書（PROJECT_PLAN.md）保存・電源フロー確定
- L85: BQ25895右側ピン（BAT/SYS/PGND/PAD）接続
- L133: BQ25895上側ピン（SW/BTST/REGN/PMID/DSEL）接続・インダクタ1.5µH
- L165: BQ25895 インダクタ値1.5µH（スイッチング周波数1.5MHz時）確定
- L190: TS分圧接続の最終確定（REGN→R6→TS→R7→GND）
- L260: BQ25895完成・グローバルラベル（I2C_SCL/I2C_SDA）確定
- L400: I2CバスはRP2040経由でBQ25895を読む設計確認
- L500: GNDPWRと通常GNDの使い分け・一点接続

### Session05 (2026-02-20) - 2026-02-20_Session05.txt
- L1: 別PCからpull・power/usb_hubシート完成の状態から継続
- L65: BQ25895 SCL/SDA・USB_DP/USB_DM のグローバルラベル化
- L100: connectors.kicad_schシート新設の決定
- L168: パワーシンボル名（5V_SYS/VSYS）カスタム作成
- L264: +3V3パワーシンボル統一（AP2112K VOUT = +3V3）
- L308: キルスイッチ設計（BQ25895とTPS61023の間・SPDT・充電継続可能）
- L345: 電源フロー確定：+BATT→BQ25895→VSYS→キルスイッチ→TPS61023/AP2112K
- L435: powerシート完了確認・TPS61023 ENピン（モーメンタリ起動）設計
- L500: TPS61023 FB分圧（R9=910kΩ/R10=100kΩ → 5.05V）・インダクタ1µH
- L660: GPIO足りるか確認開始
- L688: KLEレイアウト初回（60キー版）・9×8マトリクス（17本）確定
- L772: ショルダーボタン・Back/Next/RShift追加（66キー版）
- L838: RP2040 GPIO割り当て確定版（GP0-GP28、29本使用）
- L875: keyboard-layout.json保存

### Session06 (2026-02-20) - 2026-02-20_Session06.txt
※Session05と同内容・別デバイスから同じ状態で開始した重複セッション
- L65: BQ25895 SCL/SDA グローバルラベル化
- L168: 5V_SYS/VSYS カスタムパワーシンボル作成
- L308: キルスイッチ設計（SPDT・VSYS後段配置）
- L500: Geminiによる回路図レビュー（TPS61023/AP2112K/BQ25895）
- L549: キルスイッチ位置・AP2112K VIN接続先の確認
- L906: VL812 usb_hubシート作業開始
- L1013: VL812 電源ピン・デカップリング・SPI Flash・ストラップ全配線手順
- L1049: SSREXT→200Ω(1%)確定
- L1051: VBUSDET当初設計（5V_SYS直結・後に修正）
- L1059: EXTPWRON分圧値（22kΩ+47kΩ → 3.41V・後に簡略化）
- L1086: カスタムパワーシンボル（+3V3_HUB/+1V2_HUB）作成
- L1187: Pin40 NC確定
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

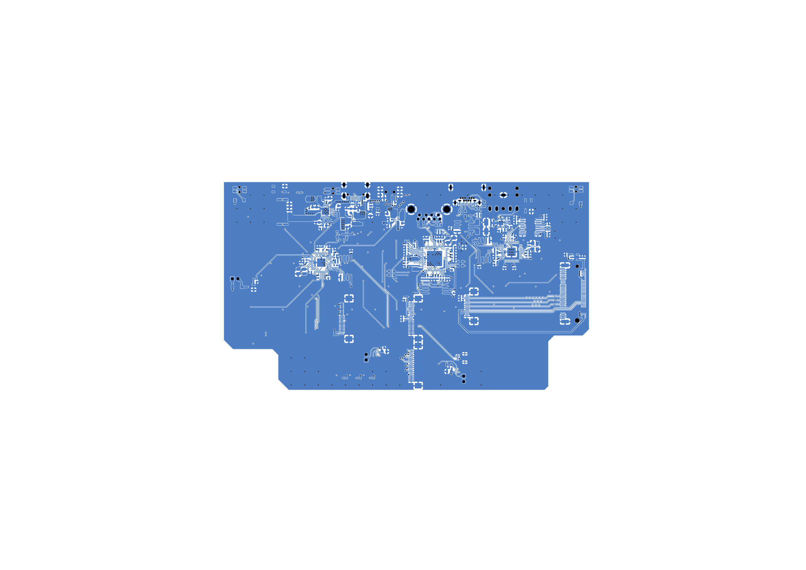
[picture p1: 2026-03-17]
kicad/PortaRe0/main.png

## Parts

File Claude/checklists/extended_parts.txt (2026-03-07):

================================================================================
PortaRe0 Extended / 手はんだ部品リスト
更新日: 2026-03-05
================================================================================

方針:
- Basic部品: JLCPCBのPCBAに任せる
- Extended部品: 自前で手はんだ（PCBA外注コスト削減）
- TH/特殊部品: 手はんだ確定

================================================================================
【A】手はんだ確定（PCBA対象外）
================================================================================

--- LED (0603) ---
C19171394  YLED0603B  青LED  ×1  LED_ACT（GP23）           Extended
C19273151  YLED0603G  緑LED  ×1  LED_FULL（GP22）           Extended
C19273153  YLED0603O  橙LED  ×1  LED_CHG（GP21）           Extended

--- スイッチ ---
C115361    SKSCLBE010  横押しSMD  ×3  電源ボタン×1 + 肩ボタン×2  Extended

--- スルーホール部品 ---
C16684     PJ-307C    イヤホンジャック 3.5mm  ×1  TH 5pin
C157915    S8B-PH-K-S-LF-SN  バッテリーコネクタ  ×1  水平型 JST PH 8pin TH

================================================================================
【B】Extended（PCBA可だが $3/種 追加料金）→ 手はんだで節約候補
================================================================================

--- 抵抗 (0603) ---
C137753    27Ω        ×4   RP2040 USB D+/D- 終端
C141680    6.04kΩ     ×1   VL812 SSREXT
C144680    22kΩ       ×2   CC Rp（J_SBC_USB2 CC1/CC2）
C863934    750kΩ      ×2   TPS61023 R_TOP（5.1V出力設定）

--- コンデンサ ---
C156458    150µF 6.3V タンタルポリマー 3528  ×2  VL812 C107/C108

--- インダクタ（要確認：おそらくExtended）---
C408335    2.2µH Sunlord MWSA0402S-2R2MT  ×1  L1 BQ25895用   要JLCPCB確認
C3002557   1µH   CENKER CKST322512        ×2  L2,L4 TPS61023用 要JLCPCB確認
C19274352  10µH  SHOU HAN CYA0420         ×1  L3 VL812用     要JLCPCB確認

================================================================================
【C】IC類（Extended確定 / JLCPCB PCBA対象 / 2026-03-08確認済み）
================================================================================

C番号     型番              役割             数  在庫       備考
--------  ----------------  ---------------  --  ---------  --------------------
C919459   TPS61023DRLR      昇圧DC-DC        ×2  18,758     Extended
C69417    VL812-Q7          USB Hubチップ    ×1  0          Extended・要Pre-order
C2682619  MAX98357AEWL+T    I2Sアンプ        ×2  7,114      Extended
C69901    TPA6132A2RTER     HPアンプ         ×1  504        Extended
C138720   TPS2042BDR        USBパワースイッチ ×1  1,214      Extended
C3170007  Molex 5034800440  FPCコネクタ      ×1  893        Extended
C431540   MSK12C02          スライドSW       ×1  149,059    Extended

================================================================================
【D】Basic確認済み（PCBA任せ）
================================================================================

C80200     BQ25895RTWR       充電IC
C51118     AP2112K-3.3TRG1   LDO
C82344     W25Q32JVSSIQ      SPI Flash ×2
C2040      RP2040            MCU ×2
C70565     X322512MOB4SI     12MHz水晶 ×2
C9006      X322525MOB4SI     25MHz水晶 ×1
C7519      USBLC6-2SC6       ESD保護 ×2
C52895     BSS138            MOSFET
C2099      1N4148W           ダイオード ×64
C2286      KT-0603R          赤LED ×1
C466635    BAT54             ショットキー ×1
C23138     330Ω              LED抵抗 等（各種Basic抵抗）

================================================================================
備考
================================================================================
- 【C】のIC類はJLCPCBの部品検索でBasic/Extendedを要確認
- Extendedは1種類$3追加なので、手はんだで対応できるなら除外を検討
- インダクタは大電流品のためJLCPCB在庫・対応可否を要確認
================================================================================

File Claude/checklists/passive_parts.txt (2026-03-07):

================================================================================
PortaRe0 パッシブ部品 C番号リスト
作成日: 2026-02-28
================================================================================

【パッケージ方針】
- 抵抗: 0402（全値）
- コンデンサ（~4.7µF）: 0402
- コンデンサ 10µF以上: 0603維持（耐圧・容量の都合）
- コンデンサ 22µF: 0603
- コンデンサ 150µF: 3528 タンタルポリマー

================================================================================
抵抗（Basic=0402 / Extended=0603 / ±1% / 100mW）※ 2026-03-08 更新
================================================================================

値          C番号     Basic/Extended  パッケージ  備考
----------  --------  --------------  ----------  ----------------------------------------
27Ω         C137753   Extended        0603        RP2040 USB D+/D- 終端（4本）★手はんだ
100Ω        C25076    Basic           0402        R34(keyboard), R38(audio)
270Ω        C22966    Basic           0603        BQ25895 ILIM（0402はExtendedのため0603維持）
330Ω        C25104    Basic           0402        LED直列抵抗（3本）
470Ω        C25117    Basic           0402        TPA6132A2 EMIフィルタ（2本）
1kΩ         C11702    Basic           0402        BSS138 gate（FAN/audio 計3本）
4.7kΩ       C25900    Basic           0402        VL812 SMDAT/SMCLK プルアップ（2本）
5.1kΩ       C25905    Basic           0402        CC1/CC2 Rd（J_USB_PWR / J_SBC_USB1 計4本）
6.04kΩ      C141680   Extended        0603        VL812 SSREXT（1本）★手はんだ
10kΩ        C25744    Basic           0402        プルアップ/プルダウン多数
22kΩ        C25768    Basic           0402        CC Rp（J_SBC_USB2 CC1/CC2 計2本）
56kΩ        C23206    Basic           0603        J_EXT_C CC1/CC2 Rp（2本）（0402はExtendedのため0603維持）
100kΩ       C25741    Basic           0402        VL812 RESET#プルダウン、TPS61023 R_BOT等
220kΩ       C22961    Basic           0603        MAX98357A SD_MODE Right ch（1本）（0402はExtendedのため0603維持）
750kΩ       C863934   Extended        0603        TPS61023 R_TOP（5.1V設定 / 計2本）★手はんだ

================================================================================
コンデンサ（0402 / ~4.7µF）※ 2026-03-08 0603→0402 変更
================================================================================

値          C番号     Basic/Extended  備考
----------  --------  --------------  ----------------------------------------
15pF C0G    C1548     Basic           RP2040 クリスタル負荷C（4本）
18pF C0G    C1549     Basic           VL812 クリスタル負荷C（2本）
100nF X7R   C307331   Basic           デカップリング（最多・全シート）
1µF X5R     C52923    Basic           各種デカップリング
2.2µF X5R   C12530    Basic           PCM5102A CAPP/CAPM / TPA6132A2 各種
4.7µF X5R   C23733    Basic           BQ25895 REGN（C5）等

================================================================================
コンデンサ（0603 / 10µF以上）※ 耐圧・容量の都合で0603維持
================================================================================

値          C番号     Basic/Extended  パッケージ  備考
----------  --------  --------------  ----------  ----------------------------------------
10µF 6.3V   C15525    Basic           0402        3.3Vライン用（C12,C16,C18,C19,C21,C93,C99,C111,C115,C116）
10µF 25V    C96446    Basic           0603        5V/VSYS/BATTライン・C6（PMID）統一（C1,C3,C6,C8,C13,C70,C73,C102,C109,C110,C113）
22µF        C59461    Basic           0603        TPS61023入出力バルク等

================================================================================
インダクタ
================================================================================

値      C番号     Idc   Isat  DCR    パッケージ  備考
------  --------  ----  ----  -----  ----------  ----------------------------------------
2.2µH   C408335   4.5A  5A    58mΩ   4.4×4.2mm   L1: BQ25895用 / Sunlord MWSA0402S-2R2MT
1µH     C3002557  5A    5.7A  30mΩ   1210        L2,L4: TPS61023用×2 / CENKER CKST322512
10µH    C19274352 1.6A  2A    294mΩ  4.7×4.2mm   L3: VL812内部DC-DC用 / SHOU HAN CYA0420

================================================================================
LED（0603）
================================================================================

部品  色  C番号     型番        Vf          備考
----  --  --------  ----------  ----------  ----------------------------------------
D1    赤  C2286     KT-0603R    2.4V        BQ25895 STAT直結（充電中点灯）Basic
D2    青  C19171394 YLED0603B   2.6〜3.2V   LED_ACT（GP23 / OS動作）Extended
D3    緑  C19273151 YLED0603G   2.7〜3.2V   LED_FULL（GP22 / 満充電）Extended
D4    橙  C19273153 YLED0603O   1.8〜2.4V   LED_CHG（GP21 / 充電中）Extended

※ 青・緑は 3.3V/330Ω で ~1.5mA（暗めだが視認可能）
※ Extended LEDは自前購入・手はんだ予定（JLCPCB PCBA外）

================================================================================
特殊（0603以外）
================================================================================

値              C番号     パッケージ          Basic/Extended  備考
--------------  --------  ------------------  --------------  ----------------
150µF 6.3V      C156458   3528 タンタルポリマー  Extended        usb_hub C107/C108

================================================================================
Extended部品（手はんだ / PCBA対象外）
================================================================================
★手はんだ確定:
- C137753: 27Ω 0603
- C141680: 6.04kΩ 0603
- C863934: 750kΩ 0603
- C156458: 150µF タンタル
※ LED（C19171394/C19273151/C19273153）は手はんだ予定なのでPCBA対象外

※ 270Ω・56kΩ・220kΩ: 0402はExtendedだが0603はBasic → 0603のままPCBA任せ
※ 22kΩ: 0603はExtendedだが0402はBasic → 0402でPCBA任せ

================================================================================
スイッチ
================================================================================

部品      C番号     型番          仕様                        備考
--------  --------  ------------  --------------------------  ----------------------------------------
SW1       C115361   SKSCLBE010    SPST / 横押し / 2.24N       電源ボタン（側面）/ Extended / 手はんだ
肩L,肩R   C115361   SKSCLBE010    SPST / 横押し / 2.24N       ROW0 COL0/COL8 / keyboard matrix
SW2       未定      -             SPDT / ロック式 / 5A+        VSYS物理カット / スルーホール / 筐体設計後

★ KiCad要作業:
  - keyboard.kicad_sch: 肩ボタン2個のフットプリントを SKRPABE010 → SKSCLBE010 に変更
  - power.kicad_sch: SW1のフットプリントを SKSCLBE010 に設定

================================================================================
コネクタ（JST PH 2.0mm）
================================================================================

部品          C番号     型番              ピン数  仕様
------------  --------  ----------------  ------  ----------------------------------------
J4（バッテリ）  -         BM06B-ACHFKS-GACN-ETF  6pin    VBAT×3 / GND×3 / 7.5A / JST ACH SMT / 実装高1.43mm / 幅9.1mm
                           ※基板側 PCBヘッダー : BM06B-ACHFKS-GACN-ETF  $0.95（DigiKey 在庫9,492 / 手はんだ）
                           ※バッテリー側ハウジング: ACHFR-06V-H           $0.26（DigiKey 在庫2,963）
                           ※コンタクト          : SACHF-003GAC-P0.2      $0.12×6本（DigiKey 在庫72,930）
                           ※フットプリント: ネット上にあり（自作不要）
                           ※バッテリー側リード線: AWG #28に交換必要
J2/J3（SPK）   C131337   B2B-PH-K-S        2pin    各スピーカー×2個 / SMD垂直
J6（FAN）      C131337   B2B-PH-K-S        2pin    FAN 2線（5V+GND）/ SMD垂直

バッテリー側: リード線をPHR-8ハウジング + SPH-002T-P0.5Sコンタクトに後付け

================================================================================
要対応・未解決事項
================================================================================

1. ✅ BQ25895 PMID キャップ（C6）→ 解決済み（2026-03-02）
   - Value: 10µF 25V（power.kicad_sch 変更済み）
   - C番号: C91606（Murata GRM188R61E106MA73D / 10µF X5R 25V 0603 / 在庫70万）
   - ※ C19702（10V品）は他の10µFに引き続き使用、C6のみC91606

2. ✅ TPA6132A2 EMIフィルタ 2.2nF キャップ → 解決済み（2026-03-02）
   - audio.kicad_sch に追加済み（R8/R54出力→GND 各1本 計2本）
   - C番号: C1604（FH 0603B222K500NT / 2.2nF X7R 50V 0603 Basic）

3. ✅ usb_hub 10pF キャップ → 削除済み（2026-02-28）
   - C27,C29,C31,C33,C35,C37,C39,C40,C43,C45 を削除
   - 100nFが同一ネットに既存のため不要と判断

================================================================================

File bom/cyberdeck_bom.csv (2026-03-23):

カテゴリ | 用途 | 部品名 | 型番 | JLCPCB C番号 | 数量 | 備考
SBC | メインコンピュータ | Cubie A7Z | Cubie A7Z | — | 1 | Allwinner A733 / 8コア / WiFi6 / BT5.4 / 別途購入（AliExpress）
ディスプレイ | LCDパネル | Sharp 5.5インチ液晶 | LS055R1SX04 | — | 1 | 1440x2560 / MIPI DSI 4レーン / 別途購入（AliExpress）
ディスプレイ | HDMIコントローラ基板 | HDMI→MIPI DSI変換基板 | VS-CXMIPI-V1 | — | 1 | 別途購入（AliExpress）
電源 | 充電IC | BQ25895RTWR | BQ25895RTWR | C80200 | 1 | USB PD対応 / バッテリー保護内蔵 / QFN-24
電源 | 昇圧DC-DC | TPS61023DRLR | TPS61023DRLR | C919459 | 2 | #1=5V_SYS / #2=USB_5V_SYS
電源 | LDO 3.3V | AP2112K-3.3TRG1 | AP2112K-3.3TRG1 | C51118 | 1 | 5V → 3.3V / 600mA / RP2040用
電源 | M.2 LDO | RT9080-33GJ5 | RT9080-33GJ5 | C841192 | 1 | 5V → 3.3V / M.2 SSD用
電源 | USBパワースイッチ | TPS2042BDR | TPS2042BDR | C138720 | 1 | HUB downstream電源制御
電源 | Schottkyダイオード | BAT54 | BAT54 | C466635 | 1 | 電源保護（ENライン）
電源 | インダクタ L1（BQ25895用） | MWSA0402S-2R2MT | MWSA0402S-2R2MT | C408335 | 1 | 2.2µH / スイッチング用
電源 | インダクタ L2/L4（TPS61023用） | CKST322512 | CKST322512 | C3002557 | 2 | 1µH / 各TPS61023用
電源 | インダクタ L3（VL812用） | CYA0420 | CYA0420 | C19274352 | 1 | 10µH / VL812電源用
電源 | バッテリー | LiPo 606090 | 606090 | — | 1 | 4200mAh / 3.7V / 要発注
電源 | バッテリーコネクタ | JST ACH 6pin | BM06B-ACHFKS-GACN-ETF | DigiKey別途購入 | 1 | VBAT×3+GND×3 / 実装高1.43mm / 手はんだ
電源 | 電源ボタン | Alps SKSCLDE010 | SKSCLDE010 | C115362 | 1 | モーメンタリ / 手はんだ
電源 | キルスイッチ | MSK12C02 | MSK12C02 | C431540 | 1 | EN制御方式 / 手はんだ
USBハブ | USB 3.0 HUBチップ | VL812-Q7 | VL812-Q7 | C69417 | 1 | QFN-76-EP 9x9mm
USBハブ | SPI Flash（VL812用） | W25Q32JVSSIQ | W25Q32JVSSIQ | C82344 | 1 | VL812ファームウェア用
USBハブ | クリスタル（VL812用） | X322525MOB4SI | X322525MOB4SI | C9006 | 1 | 25MHz / 負荷容量18pF / SMD3225-4P
USBハブ | USB ESD保護 | USBLC6-2SC6 | USBLC6-2SC6 | C7519 | 2 | USB-C ESD保護
MCU | キーボード/オーディオMCU | RP2040 | RP2040 | C2040 | 2 | #1=キーボード / #2=オーディオ / QFN-56
MCU | SPI Flash（RP2040用） | W25Q32JVSSIQ | W25Q32JVSSIQ | C82344 | 2 | 各RP2040のQSPIフラッシュ
MCU | クリスタル（RP2040用） | X322512MOB4SI | X322512MOB4SI | C70565 | 2 | 12MHz / 負荷容量15pF / 各RP2040用
キースイッチ | SMDタクタイルスイッチ | Alps SKRPABE010 | SKRPABE010 | C115360 | 62 | 62キー（肩ボタン除く）/ 4.2×3.2mm SMD / 手はんだ
キースイッチ | 肩ボタン | Alps SKSCLDE010 | SKSCLDE010 | C115362 | 2 | L/R肩ボタン / サイドプッシュ / 手はんだ
ダイオード | スイッチングダイオード | 1N4148W | 1N4148W | C2099 | 65 | 64=キーマトリクス / 1=J_FAN フライバック保護
入力 | アナログスティック | 3DSスライドパッド | — | — | 1 | FPC 4ピン 1.0mmピッチ / 別途購入
入力 | FPCコネクタ（スティック用） | Molex 5034800440 | 5034800440 | C3170007 | 1 | 4P 1.0mmピッチ ZIF ヒンジ式
オーディオ | I2Sアンプ | MAX98357AEWL+T | MAX98357AEWL+T | C2682619 | 2 | ステレオ構成（L/R）/ I2S入力
オーディオ | イヤホン用DAC | PCM5102APWR | PCM5102APWR | C107671 | 1 | I2S DAC
オーディオ | ヘッドフォンアンプ | TPA6132A2RTER | TPA6132A2RTER | C69901 | 1 | ヘッドフォン出力
オーディオ | イヤホンジャック | PJ-307C | PJ-307C | C16684 | 1 | 5pin TH / 手はんだ
オーディオ | スピーカー | マイクロスピーカー 8Ω | 秋月P-12494 or P-12495 | — | 1 | 23×16×4.6mm / 別途購入（秋月）
M.2 SSD | M.2ソケット | NASM0-S6701-TP40 | NASM0-S6701-TP40 | C367029 | 1 | M-key / 2230
M.2 SSD | FPCコネクタ（M.2用） | FPC-05F-16PH20 | FPC-05F-16PH20 | C2856801 | 1 | 16pin ZIF
汎用 | NchMOSFET | BSS138 | BSS138 | C52895 | 適宜 | FAN制御・オーディオ等
LED | STAT LED（赤） | KT-0603R | KT-0603R | C2286 | 1 | BQ25895 STAT端子直結
LED | ACT LED（青） | YLED0603B | YLED0603B | C19171394 | 1 | GP23 / OS動作表示 / 手はんだ
LED | 充電完了LED（緑） | YLED0603G | YLED0603G | C19273151 | 1 | GP22 / 満充電 / 手はんだ
LED | 充電中LED（橙） | YLED0603O | YLED0603O | C19273153 | 1 | GP21 / 充電中 / 手はんだ
コネクタ | スピーカー/FANコネクタ | B2B-PH-K-S | B2B-PH-K-S | C131337 | 3 | J2/J3（スピーカーL/R）/ J6（FAN）
コネクタ | HDMI/SBC用FPCコネクタ | FPC-05F-24PH20 | FPC-05F-24PH20 | C2856805 | 4 | 24pin ZIF / J_HDMI_CTRL/J_SBC_HDMI + usb_adapter接続×2
コネクタ | SBC接続 USB-Cオス | 918-118A2021Y40000 | 918-118A2021Y40000 | C168690 | 2 | USB-C Vertical SMD / J_SBC_USB1/2
コネクタ | 外部USB-Cレセプタクル | USB31-TYPE-C-FSABC | USB31-TYPE-C-FSABC | C2880583 | 1 | CC1/CC2=56kΩ Rp / SS両サイド直結
コネクタ | 外部USB-Aレセプタクル | HC-USB3.0-L168-WP | HC-USB3.0-L168-WP | C7501850 | 1 | USB3.0 SS対応
冷却 | フラットヒートパイプ | 3mm厚フラット銅製 | — | — | 1 | 別途購入（AliExpress）
冷却 | ヒートシンク | 小型ヒートシンク | — | — | 4 | 14×9×4mm程度 / 別途購入
パッシブ | コンデンサ・抵抗 各種 | — | — | — | 多数 | 回路設計に従い適宜

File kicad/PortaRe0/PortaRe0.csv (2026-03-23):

Reference | Qty | Value | DNP | Exclude from BOM | Exclude from Board | Footprint | Datasheet
C65,C68,C74,C75 | 4 | 15pF |  |  |  | Capacitor_SMD:C_0402_1005Metric | ~
C100,C101 | 2 | 18pF |  |  |  | Capacitor_SMD:C_0402_1005Metric | ~
C118,C119 | 2 | 2.2nF |  |  |  | Capacitor_SMD:C_0402_1005Metric | ~
C2,C4,C7,C9,C11,C14,C15,C17,C20,C22,C23,C24,C25,C26,C27,C28,C30,C31,C32,C33,C34,C36,C38,C41,C42,C44,C46,C47,C49,C50,C51,C52,C53,C54,C55,C56,C57,C58,C59,C61,C62,C63,C64,C66,C69,C71,C72,C76,C77,C78,C80,C81,C82,C83,C84,C85,C86,C87,C88,C89,C90,C91,C97,C103,C105,C106,C112,C114 | 68 | 100nF |  |  |  | Capacitor_SMD:C_0402_1005Metric | ~
C29,C60,C67,C79,C94,C95,C98 | 7 | 1μF |  |  |  | Capacitor_SMD:C_0402_1005Metric | ~
L1 | 1 | 2.2μH |  |  |  | PortaRe0:IND-SMD_L4.4-W4.2 | ~
C92,C96,C117 | 3 | 2.2μF |  |  |  | Capacitor_SMD:C_0402_1005Metric | ~
C5,C48 | 2 | 4.7μF |  |  |  | Capacitor_SMD:C_0402_1005Metric | ~
C1,C3,C8,C13,C70,C73,C102,C109,C110,C113 | 10 | 10μF |  |  |  | Capacitor_SMD:C_0603_1608Metric | ~
C12,C16,C18,C19,C21,C93,C99,C111,C115,C116 | 10 | 10μF |  |  |  | Capacitor_SMD:C_0402_1005Metric | ~
L3 | 1 | 10μH |  |  |  | PortaRe0:IND-SMD_L4.7-W4.2 | ~
C10,C104 | 2 | 22μF |  |  |  | Capacitor_SMD:C_0603_1608Metric | ~
C107,C108 | 2 | 150μF |  |  |  | Capacitor_Tantalum_SMD:CP_EIA-3528-21_Kemet-B_HandSolder | ~
R30,R37,R56 | 3 | 1kΩ |  |  |  | Resistor_SMD:R_0402_1005Metric | ~
R46,R58,R59 | 3 | 4.7kΩ |  |  |  | Resistor_SMD:R_0402_1005Metric | ~
R48,R49,R52,R60 | 4 | 5.1kΩ |  |  |  | Resistor_SMD:R_0402_1005Metric | ~
R18 | 1 | 6.04kΩ |  |  |  | Resistor_SMD:R_0603_1608Metric | ~
R1,R2,R4,R6,R7,R12,R14,R16,R17,R19,R20,R21,R25,R26,R29,R36,R39,R42,R47,R53,R55,R57,R61,R62,R64 | 25 | 10kΩ |  |  |  | Resistor_SMD:R_0402_1005Metric | ~
R27,R28,R40,R41 | 4 | 27Ω |  |  |  | Resistor_SMD:R_0603_1608Metric | ~
R50,R51 | 2 | 56kΩ |  |  |  | Resistor_SMD:R_0603_1608Metric | ~
R10,R11,R13,R15,R22,R23,R24,R43,R44,R63 | 10 | 100kΩ |  |  |  | Resistor_SMD:R_0402_1005Metric | ~
R34,R38 | 2 | 100Ω |  |  |  | Resistor_SMD:R_0402_1005Metric | ~
R35 | 1 | 220kΩ |  |  |  | Resistor_SMD:R_0603_1608Metric | ~
R5 | 1 | 270Ω |  |  |  | Resistor_SMD:R_0603_1608Metric | ~
R3,R31,R32,R33 | 4 | 330Ω |  |  |  | Resistor_SMD:R_0402_1005Metric | ~
R8,R54 | 2 | 470Ω |  |  |  | Resistor_SMD:R_0402_1005Metric | ~
R9,R45 | 2 | 750kΩ |  |  |  | Resistor_SMD:R_0603_1608Metric | ~
Stick1 | 1 | 5034800440 |  |  |  | PortaRe0:FPC-SMD_5034800400
C6 | 1 | 10μF 25V |  |  |  | Capacitor_SMD:C_0603_1608Metric | ~
D9,SW_D1,SW_D2,SW_D3,SW_D4,SW_D5,SW_D6,SW_D7,SW_D8,SW_D9,SW_D10,SW_D11,SW_D12,SW_D13,SW_D14,SW_D15,SW_D16,SW_D17,SW_D18,SW_D19,SW_D20,SW_D21,SW_D22,SW_D23,SW_D24,SW_D25,SW_D26,SW_D27,SW_D28,SW_D29,SW_D30,SW_D31,SW_D32,SW_D33,SW_D34,SW_D35,SW_D36,SW_D37,SW_D38,SW_D39,SW_D40,SW_D41,SW_D42,SW_D43,SW_D44,SW_D45,SW_D46,SW_D47,SW_D48,SW_D49,SW_D50,SW_D51,SW_D52,SW_D53,SW_D54,SW_D55,SW_D56,SW_D57,SW_D58,SW_D59,SW_D60,SW_D61,SW_D62,SW_D63,SW_D64 | 65 | 1N4148W |  |  |  | PortaRe0:SOD-123_L2.8-W1.8-LS3.7-RD | https://lcsc.com/product-detail/Switching-Diode_1N4148W-T4_C2099.html,~
L2,L4 | 2 | 1µH / 3A |  |  |  | PortaRe0:IND-SMD_L3.2-W2.5_CKST322512-2.2UH | ~
U3 | 1 | AP2112K-3.3TRG1 |  |  |  | PortaRe0:SOT-25-5_L2.9-W1.6-P0.95-LS2.8-BL | https://lcsc.com/product-detail/Low-Dropout-Regulators-LDO_DIODES_AP2112K-3-3TRG1_AP2112K-3-3TRG1_C51118.html
D7,D8 | 2 | BAT54 |  |  |  | PortaRe0:SOT-23-3_L2.9-W1.4-P1.90-LS2.6-BR | https://lcsc.com/product-detail/Schottky-Barrier-Diodes-SBD_High-Diode-BAT54_C466635.html
J1 | 1 | Battery |  |  |  | PortaRe0:CONN_BM06B-ACHFKS-GACN-ETF_JST | BM06B-ACHFKS-GACN-ETFLFSN
B_SW1,B_SW2 | 2 | BOOTSEL_SW |  |  |  | PortaRe0:KEY-SMD_4P-L4.2-W3.2-P2.20-LS4.6 | https://lcsc.com/product-detail/Tactile-Switches_ALPS_SKRPABE010_3-2-4-2-2-5-1-57N_C115360.html
U1 | 1 | BQ25895RTWR |  |  |  | PortaRe0:QFN-24_L4.0-W4.0-P0.50-TL-EP2.7 | https://lcsc.com/product-detail/PMIC-Battery-Management_TI_BQ25895RTWR_BQ25895RTWR_C80200.html
Q1 | 1 | BSS138 |  |  |  | PortaRe0:SOT-23-3_L2.9-W1.6-P1.90-LS2.8-BR | https://lcsc.com/product-detail/MOSFET_FAIRCHILD_BSS138_BSS138_C52895.html
Y1 | 1 | C9006 |  |  |  | PortaRe0:CRYSTAL-SMD_4P-L3.2-W2.5-BL | ~
Y2,Y4 | 2 | C70565 |  |  |  | PortaRe0:CRYSTAL-SMD_4P-L3.2-W2.5-BL | ~
J6 | 1 | Fan |  |  |  | PortaRe0:CONN-TH_S2B-PH-K-S-LF-SN | ~
J8 | 1 | FPC_USB_2.0 |  |  | 基板から除外 | PortaRe0:FPC-24P-0.5mm | ~
J7 | 1 | FPC_USB_3.1 |  |  | 基板から除外 |  | ~
U12 | 1 | HC-USB3.0-L168-WP |  |  |  | PortaRe0:USB-TH_USB3.0-A
J5 | 1 | HDMI_Jamp |  |  | 基板から除外 | Connector_PinHeader_2.00mm:PinHeader_2x08_P2.00mm_Vertical | ~
FPC1 | 1 | J_HDMI_CTRL |  |  |  | PortaRe0:FPC-SMD_24P-P0.50_FPC-05F-24PH20
FPC3 | 1 | J_MICROHDMI |  |  | 基板から除外 | PortaRe0:FPC-SMD_24P-P0.50_FPC-05F-24PH20
FPC2 | 1 | J_SBC_HDMI |  |  |  | PortaRe0:FPC-SMD_24P-P0.50_FPC-05F-24PH20
USBC2 | 1 | J_SBC_USB1 |  |  | 基板から除外 | PortaRe0:USB-C-SMD_TYPE-C-USB-3 | https://lcsc.com/product-detail/USB-Type-C_TYPE-C-3-1-Male-head-3-High-temperature_C168690.html
USBC3 | 1 | J_SBC_USB2 |  |  | 基板から除外 | PortaRe0:USB-C-SMD_TYPE-C-USB-3 | https://lcsc.com/product-detail/USB-Type-C_TYPE-C-3-1-Male-head-3-High-temperature_C168690.html
FPC4 | 1 | J_SBC_USB_2.0 |  |  |  | PortaRe0:FPC-SMD_24P-P0.50_FPC-05F-24PH20
FPC5 | 1 | J_SBC_USB_3.1 |  |  |  | PortaRe0:FPC-SMD_24P-P0.50_FPC-05F-24PH20
USBC1 | 1 | J_USB_PWR |  |  |  | PortaRe0:USB-C_SMD-TYPE-C-31-M-12_1 | https://lcsc.com/product-detail/USB-Type-C_Korean-Hroparts-Elec-TYPE-C-31-M-12_C165948.html
K_SW1,K_SW2 | 2 | KeyBoard |  |  |  | PortaRe0:KEY-SMD_4P-SKSCLXX010 | https://lcsc.com/product-detail/Tactile-Switches_ALPS_SKSCLBE010_3-3-5-1-1-Side-press-1-6N_C115361.html
K_SW3,K_SW4,K_SW5,K_SW6,K_SW7,K_SW8,K_SW9,K_SW10,K_SW11,K_SW12,K_SW13,K_SW14,K_SW15,K_SW16,K_SW17,K_SW18,K_SW19,K_SW20,K_SW21,K_SW22,K_SW23,K_SW24,K_SW25,K_SW26,K_SW27,K_SW28,K_SW29,K_SW30,K_SW31,K_SW32,K_SW33,K_SW34,K_SW35,K_SW36,K_SW37,K_SW38,K_SW39,K_SW40,K_SW41,K_SW42,K_SW43,K_SW44,K_SW45,K_SW46,K_SW47,K_SW48,K_SW49,K_SW50,K_SW51,K_SW52,K_SW53,K_SW54,K_SW55,K_SW56,K_SW57,K_SW58,K_SW59,K_SW60,K_SW61,K_SW62,K_SW63,K_SW64 | 62 | KeyBoard |  |  |  | PortaRe0:KEY-SMD_4P-L4.2-W3.2-P2.20-LS4.6 | https://lcsc.com/product-detail/Tactile-Switches_ALPS_SKRPABE010_3-2-4-2-2-5-1-57N_C115360.html
SW2 | 1 | KillSW |  |  |  | PortaRe0:SW-TH_MSK12C02 | https://lcsc.com/product-detail/Toggle-Switches_SHOU-HAN-MSK12C02_C431540.html
D2 | 1 | LED_ACT |  |  |  | LED_SMD:LED_0603_1608Metric | ~
D4 | 1 | LED_CHG |  |  |  | LED_SMD:LED_0603_1608Metric | ~
D3 | 1 | LED_FULL |  |  |  | LED_SMD:LED_0603_1608Metric | ~
D1 | 1 | LED_Small |  |  |  | LED_SMD:LED_0603_1608Metric | ~
CN1 | 1 | M.2 |  |  |  | PortaRe0:CONN-SMD_67P-P0.50-V_NXSM0-S67XX-XX40 | https://lcsc.com/product-detail/Card-Edge-Connectors_Argosy-Research-Inc-NASM0-S6701-TP40_C367029.html
U9 | 1 | MAX98357AEWL+T_L |  |  |  | PortaRe0:WLP-9_L1.4-W1.3-P0.40-R3-C3-BR
U15 | 1 | MAX98357AEWL+T_R |  |  |  | PortaRe0:WLP-9_L1.4-W1.3-P0.40-R3-C3-BR
U13 | 1 | PCM5102APWR |  |  |  | PortaRe0:TSSOP-20_L6.5-W4.4-P0.65-LS6.4-BL | https://lcsc.com/product-detail/Audio-A-D-Converter-ICs_TI_PCM5102APWR_PCM5102APWR_C107671.html
J9 | 1 | PJ-307C |  |  |  | PortaRe0:AUDIO-TH_PJ307C | https://lcsc.com/product-detail/Audio-Connectors_Headphone-interface_C16684.html
U6 | 1 | RP2040#1 |  |  |  | PortaRe0:LQFN-56_L7.0-W7.0-P0.4-EP
U11 | 1 | RP2040#2 |  |  |  | PortaRe0:LQFN-56_L7.0-W7.0-P0.4-EP
U16 | 1 | RT9080-33GJ5 |  |  |  | PortaRe0:TSOT-23-5_L2.9-W1.6-P0.95-LS2.8-BL | https://lcsc.com/product-detail/Dropout-Regulators-LDO_Richtek-Tech-RT9080-33GJ5_C841192.html
FPC6 | 1 | SBC_PCIE |  |  |  | PortaRe0:FPC-SMD_16P-P0.50_FPC-05F-16PH20
J3 | 1 | SPK_L |  |  |  | PortaRe0:CONN-TH_S2B-PH-K-S-LF-SN | ~
J2 | 1 | SPK_R |  |  |  | PortaRe0:CONN-TH_S2B-PH-K-S-LF-SN | ~
SW1 | 1 | SW_START |  |  |  | PortaRe0:KEY-SMD_4P-SKSCLXX010 | https://lcsc.com/product-detail/Tactile-Switches_ALPS_SKSCLBE010_3-3-5-1-1-Side-press-1-6N_C115361.html
U14 | 1 | TPA6132A2RTER |  |  |  | PortaRe0:WQFN-16_L3.0-W3.0-P0.50-TL-EP1.6 | https://lcsc.com/product-detail/Audio-OpAmps_TI_TPA6132A2RTER_TPA6132A2RTER_C69901.html
U10 | 1 | TPS2042BDR |  |  |  | PortaRe0:SOIC-8_L4.9-W3.9-P1.27-LS6.0-BL | https://lcsc.com/product-detail/PMIC-Power-Distribution-Switches_TI_TPS2042BDR_TPS2042BDR_C138720.html
U2,U7 | 2 | TPS61023DRLR |  |  |  | PortaRe0:SOT-563_L1.6-W1.2-P0.50-LS1.6-BR
U8 | 1 | USB31-TYPE-C-FSABC |  |  |  | PortaRe0:USB-C-SMD_USB31-TYPE-C-FSABC
D6 | 1 | USB_HUB_A |  |  |  | PortaRe0:SOT-23-6_L2.9-W1.6-P0.95-LS2.8-BL | https://lcsc.com/product-detail/Diodes-ESD_STMicroelectronics_USBLC6-2SC6_USBLC6-2SC6_C7519.html
D5 | 1 | USB_HUB_C |  |  |  | PortaRe0:SOT-23-6_L2.9-W1.6-P0.95-LS2.8-BL | https://lcsc.com/product-detail/Diodes-ESD_STMicroelectronics_USBLC6-2SC6_USBLC6-2SC6_C7519.html
U4 | 1 | VL812 |  |  |  | PortaRe0:QFN-76_L9.0-W9.0-P0.40-BL-EP | https://lcsc.com/product-detail/USB_VL812-Q7_C69417.html
RP2040#1,RP2040#2,U5 | 3 | W25Q32JVSSIQ |  |  |  | PortaRe0:SOIC-8_L5.3-W5.3-P1.27-LS8.0-BL | https://lcsc.com/product-detail/FLASH_W25Q32JVSSIQ_C82344.html

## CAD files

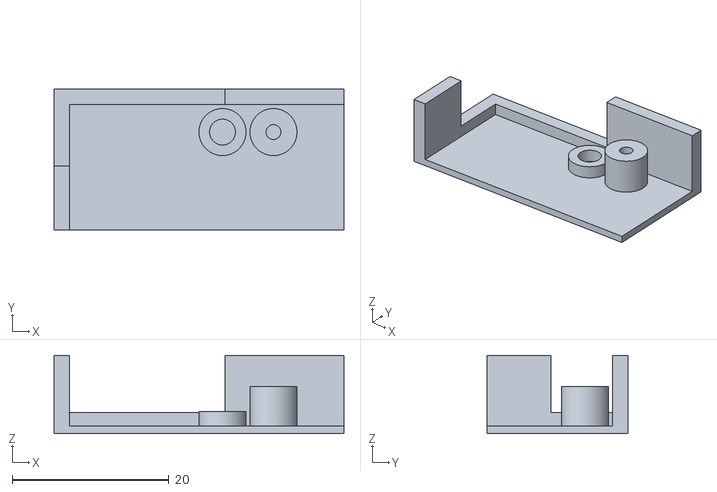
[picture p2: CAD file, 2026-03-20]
cad/stl/main1 (1).stl
37.0 x 18.0 x 10.0

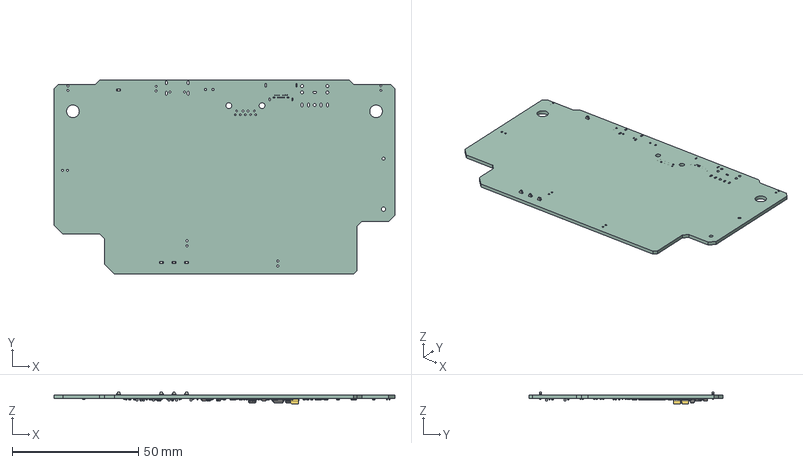
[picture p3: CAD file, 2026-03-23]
cad/PortaRe0_PCB.step
135.0 x 77.0 x 4.88 mm
LED_0603_1608Metric x 4
C_0402_1005Metric x 98
R_0402_1005Metric x 53
R_0603_1608Metric x 11
C_0603_1608Metric x 13
SOT-23-6_L2.9-W1.6-H1.5-LS2.8-P0.95 x 2
SOIC-8_L4.9-W3.9-H1.7-LS6.0-P1.27
CP_EIA-3528-21_Kemet-B x 2
PortaRe0_PCB

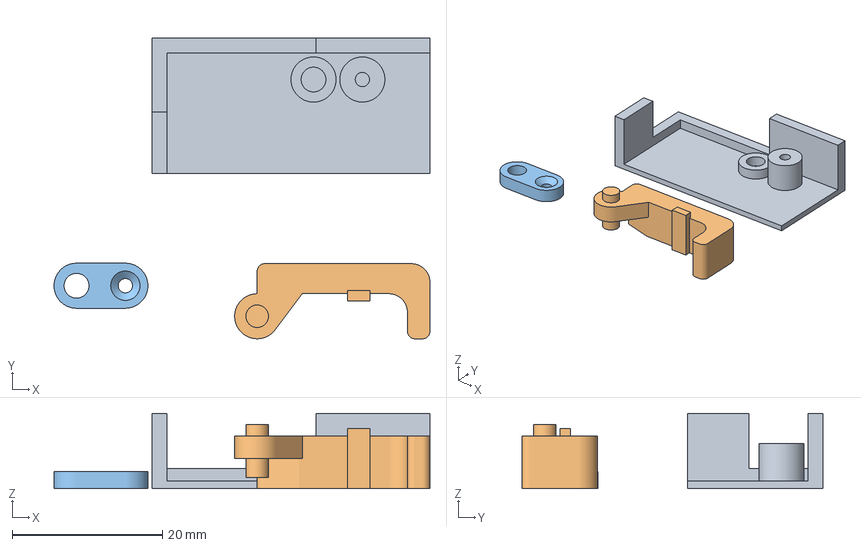
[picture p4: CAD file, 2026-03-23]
cad/stl/L.3mf
50.0 x 40.0 x 10.0 mm
main1 (1).stl
L.stl
ボディ11.stl

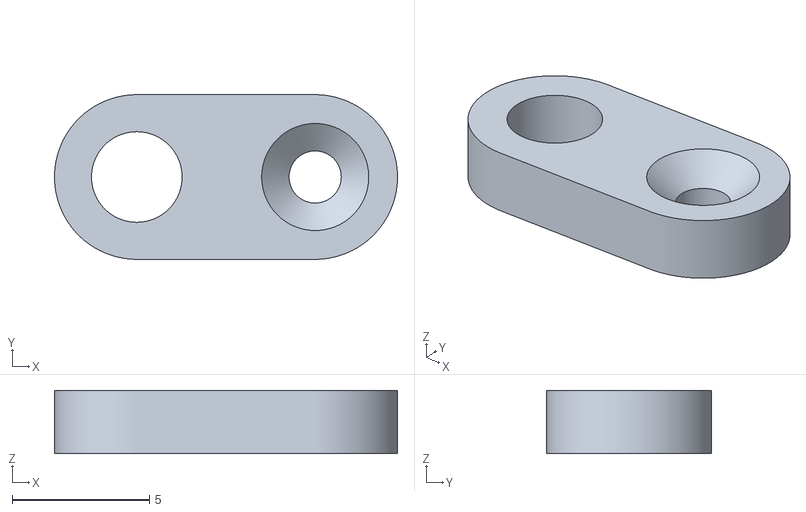
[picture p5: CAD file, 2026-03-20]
cad/stl/ボディ11.stl
12.5 x 6.00 x 2.30

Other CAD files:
kicad/PortaRe0/PortaRe0.step
cad/stl/L.stl
kicad/PortaRe0/PortaRe0.stl

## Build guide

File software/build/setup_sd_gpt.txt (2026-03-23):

rem PortaRe0 SD Card GPT Setup
rem Target: Disk 3 (PhysicalDrive3 / Generic STORAGE DEVICE USB Device ~119GB)
rem WARNING: All data on Disk 3 will be erased.

select disk 3
clean
convert gpt
create partition efi size=260
format fs=fat32 quick label="ESP"
assign letter=S
exit

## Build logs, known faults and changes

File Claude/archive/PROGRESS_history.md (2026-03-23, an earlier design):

# PROGRESS 決定事項ログ アーカイブ

### 2026-02-28（session28）
- パッシブ部品C番号を全確定 → `Claude/checklists/passive_parts.txt` 作成
  - 抵抗15種類（0603 ±1% 100mW）/ コンデンサ8種類（0603）/ 150µFタンタル1種類
  - Extended Parts: 5種類（27Ω/6.04kΩ/22kΩ/750kΩ/150µFタンタル）→ 追加料金$15
- usb_hub 10pFキャップ削除（KiCad済み）:
  - C27,C29,C31,C33,C35,C37,C39,C40,C43,C45（10本）削除
  - 3V3_HUB/1V2_HUBに100nFが同一ネットに既存のため不要と判断
- インダクタ3種類C番号確定（passive_parts.txtに記録）:
  - L1 (BQ25895 2.2µH): **C408335**（Sunlord MWSA0402S-2R2MT / Idc=4.5A / DCR=58mΩ / 4.4×4.2mm）
  - L2,L4 (TPS61023 1µH ×2): **C3002557**（CENKER CKST322512 / Idc=5A / DCR=30mΩ / 1210）
  - L3 (VL812 10µH): **C19274352**（SHOU HAN CYA0420 / Idc=1.6A / DCR=294mΩ / 4.7×4.2mm）
- 未対応確認事項（次セッションへ）:
  - TPA6132A2 EMIフィルタ 2.2nFキャップ: audio.kicad_sch に未追加（C1604 / INL−/INR−→GND 計2本）
  - BQ25895 C6（PMID）: 10V品 → 25V品への変更要検討
  - LED C番号（D1〜D4）・スイッチ型番（SW1/SW2）未確定

### 2026-02-27（session24）
- IC設計レビュー用チェックシート作成（`Claude/checklists/` 01〜10）
- BQ25895 修正（KiCad済み）:
  - C5: 4.7nF → **4.7µF**（REGN バイパス / 1000倍違いを修正）
  - CE: 3V3 → **GND**（常時充電許可 / I2C制御で無効化可能）
  - QON: GND → **NC**（内部プルアップでHIGH維持・GNDだとシップモードループ）
- TPS61023 修正（KiCad済み）:
  - VREF = 0.6V と判明（チェックシートの0.5Vは誤り）
  - R_TOP: 910kΩ → **750kΩ**（VOUT = 5.1V / VREF=0.6V × (1+7.5) = 5.1V）
  - SW2: ENピン制御 → **VSYS直列物理カット**（5A定格スイッチ必要）
  - usb_hub シートの SW4（#2用キルスイッチ）削除（VSYS共通カットで両方止まる）
- AP2112K: 全ピン問題なし / バイパスキャップ 1µF → **10µF**

### 2026-02-28（session27）
- チェックシート照合 09_TPA6132A2 完了（修正多数）:
  - 入力ピン接続が逆だった → INL−/INR−が信号入力（データシート明記）/ INL+/INR+→GND
  - ACカップリングコンデンサ追加: 2.2µF（ポップノイズ防止）
  - EMIフィルタ追加: 470Ω直列 + 2.2nF(INL−/INR−→GND) → fc≈154kHz
  - G0: GND→+3V3（ゲイン: −6dB→0dB）
  - HPVDD: チャージポンプ出力ピン（VDD接続NG）→ 2.2µFのみ（100nFから変更）
  - VDD: 100nF→100nF+2.2µF追加
  - EP（露出パッド）: GNDPWR接続（VDDへの接続はデータシートで明示NG）
- チェックシート照合 10_TPS2042BDR_USBLC6 完了: 全ピン問題なし
- **IC設計レビュー（チェックシート照合）全10IC完了 → Phase 3 PCBレイアウトへ**

### 2026-02-27（session26）
- チェックシート照合 08_PCM5102A 完了
  - SCK(Pin12): GND接続確認（SCK-lessモード）
  - バイパスキャップ値修正（KiCad済み）:
    - CAPP/CAPM(Pin2/4): 1µF → **2.2µF**（TI example準拠）
    - VNEG(Pin5): 1µF → **10µF** (MLCC)
    - AVDD(Pin8): 100nF+1µF → 100nF+**10µF** (MLCC)
    - DVDD(Pin20): 100nF → 100nF+**10µF** (MLCC) 追加
    - CPVDD(Pin1): 100nF → 100nF+**10µF** (MLCC) 追加
    - LDOO(Pin18): 1µF → 100nF+**10µF** (MLCC)
  - 音質劣化への影響: ほぼ聴こえない範囲（SNR差5〜10dB程度・聴覚限界以下）

### 2026-02-27（session25）
- チェックシート照合 04〜07 完了
  - 04_VL812: W25Q32 /CS GNDプルダウン→3V3_HUBプルアップ修正 / RESET# DragonBoard準拠確認 / LX 10µH確認 / SSTX 100nF ACカップリング正常
  - 05_RP2040_kbd: クリスタルシンボル GND23→GND24修正 / GP24・GP25接続追加 / USB 27Ω外付け正しい（データシート「必須」と明記）/ 3DS VCC 3.3V OK確認
  - 06_RP2040_audio: #1と同じ修正適用 / GPIO GP0〜GP6全OK
  - 07_MAX98357A: SD_MODE回路正常確認（U9=直結=Left / U15=220kΩ直列=Right/RSMALL）/ GAIN_SLOT浮き=9dB OK
- 3DSサークルパッド実物ピン配置確認: Pin1=GND / Pin2=X / Pin3=VCC(1.8V→3.3V使用) / Pin4=Y

### 2026-02-26（session23）
- usb_adapterシート新設（hdmi_adapterと同じ方針）
  - J_SBC_USB1/J_SBC_USB2をconnectorsシートから移動
  - FPCテール直挿し方式採用（中間コネクタなし → スティフナー側にコネクタ不要）
  - FPC 24pinピン割り当て確定（差動ペア間GND配置）
    - USB3.0用: GND/TX+/TX-/GND/RX+/RX-/GND/D+/D-/GND/VBUS/CC1/CC2/GND×11
    - USB2.0用: GND/VBUS/GND/CC1/CC2/GND×19
  - connectorsシートにC2856805（24pin ZIF）×2追加
  - CC抵抗（USB3用5.1kΩ・USB2用22kΩ）はメインPCB側に実装
  - ERC再実行: HP系のみ残存（想定内・イヤホンジャック未確定）
- BQ25895インダクタ値: TI System Examples参考に2.2µHへ変更検討中（C番号はJLCPCB確認後）
- データシート照合は次回セッション（大画面環境）で実施予定

### 2026-02-25（session21）
- J_SBC_HDMI方針最終確定: Micro HDMIベアコネクタ → ジャンパワイヤー → 自作変換基板（hdmi_adapter）→ FFC → ZIF（メインPCB）
  - FFC: C2856805（24pin 0.5mm）をJ_HDMI_CTRLと共通化
  - J_MICROHDMI: Conn_02x08（20pin / GNDまとめて2pin / NC×4）
  - hdmi_adapterを別基板として独立シート新設
- J_FAN: F16FB（SUNON 16×16×4.5mm 5V 0.04A ブロワー型 $8.76）選定確定
  - 回路: GP26(FAN_PWM) → 1kΩ → BSS138 gate / 10kΩプルダウン / 1N4148Wフライバック
  - connectorsシートに配置完了
- GP26割り当て: FAN_PWMとしてGlobal Label追加（keyboardシート・connectorsシート）
- 全シートERC実施・対処完了（詳細はフェーズ完了状況参照）

### 2026-02-25（session20）
- 別PCからgit pull（session19の変更取得）・Claude.mdロール追加コミット
- J_HDMI_CTRL 配置・配線完了
  - ピン順修正: Pin20-21=GND×2（バッファ）/ Pin22-24=5V_SYS×3（EMI低減のためGNDをHDMI信号と電源の間に配置）
- J_SBC_USB1（C168690 USB3.0）配置・配線完了
  - A7Z直結のためTX/RX逆転: A2/B2→USB3_UP_RX_P / A10/B10→USB3_UP_TX_N等
  - CC1/CC2: 5.1kΩ→GND（Rd / UFP識別）
  - VBUS（A4/B4/A9/B9）→USB2_UP_VBUS（VBUSDET分圧へ）
- J_SBC_USB2（C168690 USB2.0）配置・配線完了
  - VBUS→5V_SYS（A7Zへ給電）/ CC1/CC2: 22kΩ→5V_SYS（Rp 3A / DFP/SRC）
  - D+/D- = NC（データ不要 / USB_DP/USB_DMはBQ25895の充電検出用であり無関係）
- J_FAN設計方針確定: RP2040 #1 GP26 → BSS138 gate → ファンGND / 5V_SYS→ファンVCC
- J_SBC_HDMI方針転換: FPVケーブル水平型（出っ張り2cm）は14mmスペースに収まらず断念
  → Micro HDMIケーブル自作用端子（オス+20pin FFC変換）手はんだ方式に決定

### 2026-02-24（session19）
- バッテリー変更: 6060100(5000mAh) → **606090(4200mAh)**
  - サイズ: 6×60×100mm → 6×60×90mm（10mm短縮）
  - SBCポート周辺の空き: 4.3mm → +10mm = 約14mmに改善
  - 稼働時間: 通常使用(8W)で約1.6時間（差分24分・許容範囲）
- J_SBC接続方針確定（FPC2本構成）
  - J_SBC_HDMI: 市販FPVケーブル（Micro HDMIオス+FFC）→テスターでPIN調査→ZIFコネクタ
  - J_SBC_USB: FPCスティフナー + USB-Cオス Vertical SMD（C168690）×2
  - ストラドルコネクタ: PCB厚制約あり・今回は不採用
  - USB-Cオス Vertical SMD（918-118A2021Y40000 / C168690 / USB3.1 / 24P）採用確定
    - Clamping plate不要・スティフナー厚自由・USB 3.0 SuperSpeed対応
    - KiCadライブラリ取得済み（シンボル: TYPE-C 3.1_C168690 / フットプリント: USB-C-SMD_TYPE-C-USB-3）
- extract_session.py のJSONLパスをLinux環境に対応（自動検出に修正）
- 調査待ち: 手持ちFPVケーブルの出っ張り寸法実測・Micro HDMI ZIFコネクタ選定

### 2026-02-24（session18）
- connectors シート設計方針確定
  - J_HDMI_CTRL: 24pin FPC 0.5mm（C2856805 XUNPU FPC-05F-24PH20）に決定
    - Pin1-19: HDMI Type A 19信号（Pin18=+5V for HPD）
    - Pin20-22: 5V_SYS×3（並列 / HDMIコントローラメイン電源）
    - Pin23-24: GND×2
    - HDMIコントローラ基板のHDMI端子（標準タイプ）・Micro-USB端子を外してFPC変換
    - easyeda2kicadでC2856805ライブラリ取得済み
  - SBC接続方式: サブ基板→FPCに変更
    - Cubie A7Zの全ポート（Micro HDMI・USB3.0・USB2.0）は同じ面に集中していることを確認
    - FPCスティフナーにMicro HDMIオス + USB-Cオス×2を直付けする方針
    - 信号構成: Micro HDMI 19本 + USB3.0 SS + USB2.0 + CC + GND = 約40pin FPC
    - PCBマウントオス型コネクタ（Micro HDMI男/USB-C男）はLCSCになし
    - AliExpress/Alibaba経由で調達・手はんだ実装の方針
  - J_SBC_PWR/J_SBC_USB3: USB-C女（USB31-TYPE-C-FSABC）は内部接続に不適と判明
  - J_FAN: Cubie A7Z直結のためメインPCBには不要の可能性あり

### 2026-02-23（session17）
- usb_hub シート完成
  - J_EXT_C: USB31-TYPE-C-FSABC（C2880583）配置・接続完了
    - VBUS×4 → USB1_VBUS / CC1/CC2 → 56kΩ Rp → USB1_VBUS（ホスト側）
    - DP1/DP2・DN1/DN2 A/B両側束ね → USBLC6経由 → USB2_DP1_DP/DM
    - SS A/B両サイド直結（muxなし）→ USB3_DP1_TX/RX
    - SBU=NC / SHELL=GND
  - J_EXT_A: HC-USB3.0-L168-WP（C7501850）配置・接続完了
    - Vbus→USB2_VBUS / D+/D-→USBLC6経由 / SS→USB3_DP2_TX/RX / SHELL=GND
  - コネクタ選定変更: 在庫なし(C319140)→C2880583 / 横向き(C7501850)に変更
  - CC Rp 56kΩ × 2 追加（Default Current / ~900mA アドバタイズ）

### 2026-02-23（session15）
- powerシートのGemini AI評価9点を実スキーマと照合して検証
  - 正真の問題: Point4(D1極性逆)・Point6(SW1→GPIO電圧)・Point9(L1→BAT→SYS誤り)・C5/C6/SYS cap不足
  - Gemini誤報: Point1(TS→REGN正しい)・Point3(ILIM誤認)・Point5(TPS61023 FB計算誤り)・Point8(誤認)
- **powerシート修正完了:**
  - L1接続変更: +BATT → VSYS（NVDC正しいトポロジー）
  - D1極性修正: rotation 180° → 0°（アノード→+3V3/R3、カソード→STAT）
  - R3変更: 10kΩ → 330Ω（LED輝度改善）
  - SW1/RP2040_EN保護回路追加: BAT54ダイオード(C466635)をGP20→ENノード間に挿入
  - ENノードに10µFキャップ追加（起動ラッチ用 τ=1s）
  - SW_DET回路追加: SW1出力→10kΩ分圧→GP25（電源ボタン長押し/短押し検出用）
  - C5変更: 100nF → 4.7µF（REGN cap）
  - C6変更: 4.7µF → 10µF（PMID cap）
  - SYS capに10µF追加（合計20µF / TI推奨値）
- GP25割り当て変更: 予備 → SW_DET（10kΩ分圧でVSYS→2.1V変換）
- BAT54（C466635, SOT-23）をBOMに追加
- ファームウェア設計方針: 短押し=スリープ、長押し=シャットダウン、超長押し=緊急停止

### 2026-02-22（session14）
- Claude Code CLI移行後の最初の動作確認セッション
- PowerShell `Start-Transcript` は Claude Code TUI の出力を取れないことを確認・廃止
- `launch_claude_utf16.ps1` / `chat_logs/raw/` を `.gitignore` に追加
- `Claude/extract_session.py` を新規作成: `~/.claude/projects/` の JSONL → 読みやすい原文テキストに変換
  - ユーザー発言（str）と Claude テキスト応答のみ抽出、tool_result / thinking / tool_use は除外
  - `chat_logs/原文/SessionNN.txt` に自動採番して保存
  - Windows / Linux 両対応
- セッション終了処理の手順1に `python Claude/extract_session.py` を追加（Claude.md 更新済み）
- 今後はターミナルで `claude` を直接起動するだけでOK（ラッパースクリプト不要）

### 2026-02-22（session13）
- Claude Desktop → Claude Code CLI移行の検討・方針決定
- launch_claude.ps1（Windows用）作成: セッション番号自動採番＋Start-Transcriptでチャット原文を自動保存
- launch_claude.sh（Linux用）作成: scriptコマンドで同様のログ取得
- launch_claude.ps1 / launch_claude.sh を .gitignore に追加（git push対象外）
- Claude.mdに「終了処理して」コマンドのセクションを追加（PROGRESS.md更新→index.md更新→git commitを自動化）
- index.mdにSession13を追記・ファイル名 `New session.txt` → `2026-02-22_Session13.txt` にリネーム

### 2026-02-22（session12）
- DragonBoard 820c公式回路図（VL812採用）との照合によりusb_hubシートを修正・検証完了
- SSREXT: 200Ω → **6.04kΩ ±1%**（DragonBoard/VL805/VL815/VL817全て6.04kΩ）
- VBUSDET分圧: 56kΩ+100kΩ → **4.7kΩ+10kΩ**（約3.4V）
- EXTPWRON: +3V3 → **3V3_HUB** に修正（キルスイッチ前の電源から取る）
- RESET#: 100nF → **1µF** に変更 / **100kΩ→GND** 追加
- LX インダクタ: 4.7µH → **10µH**（DragonBoard実績値）
- 水晶シンボル: Device:Crystal_Small（2端子）→ **Device:Crystal_GND24_Small**（4端子）に変更
- 以下はDragonBoardと一致確認済み ✅
  - 水晶負荷C 18pF×2 / DC33FB 4.7µF / DC12FB 10µF+100nF / USBHOC# 10kΩ→3V3_HUB

### 2026-02-22（session11）
- 外部USBポート電源・保護回路確定
  - TPS2042BDR（C138720）: VL812 /USBHPE制御のパワースイッチ（Active-Low）
  - USBLC6-2SC6（C7519）: Port1/2各1個ESD保護
  - TPS61023 #2追加: 外部USBポートVBUS専用昇圧（USB_5V_SYS）
  - RP2040 #1 GP24 → USB_VBUS_EN（TPS61023 #2 EN制御）
  - 注意: 外部USBポートは小型デバイス用（HDD等大電流機器非推奨）
  - 注意: BQ25895 SYSライン最大5〜6A → PCBパターン極太必須
- VL812 downstream割り当て確定
  - Port1 → USB-C外部（TPS2042BDR / USBLC6-2SC6）
  - Port2 → USB-A外部（TPS2042BDR / USBLC6-2SC6）
  - Port3 → RP2040 #1
  - Port4 → RP2040 #2
- VBUSDET修正方針: Upstream VBUSから56kΩ+100kΩ分圧（約3.2V）
- EXTPWRON修正方針: 3V3_HUBへ10kΩプルアップのみ
- MAX98357A SD_MODE修正: U8（Right ch）に220kΩ直列追加
- TPA6132A2 HPVSS修正: GND直結→1µFコンデンサ経由
- LED回路修正: 向きと接続方式修正済み
- RP2040 #1/#2 TESTEN→GND接続修正

### 2026-02-21（session10）
- RP2040を#1（キーボード）/ #2（オーディオ）の2個構成に変更
  - USB Audio + HID Compositeの実装難易度が高いため分離
  - VL812 DP4（空きポート）にRP2040 #2を接続
- LED：個別LED×3のまま変更なし（GP21=CHG橙 / GP22=FULL緑 / GP23=ACT緑 / 330Ω）
- イヤホン構成確定：PCM5102APWR（C107671）+ TPA6132A2RTER（C69901）
  - PCM5102A: I2S→ステレオアナログDAC
  - TPA6132A2: ヘッドフォンアンプ（Enable端子でRP2040制御）
- スピーカー変更：秋月品 → Nintendo Switch互換品 8Ω 20×14×4mm × 2個（L/R独立）
- GPIO再割り当て：
  - RP2040 #1: GP21=LED_CHG / GP22=LED_FULL / GP23=LED_ACT、GP24=USB_VBUS_EN、GP25〜26=予備
  - RP2040 #2: GP0=BCLK, GP1=LRCLK, GP2=SDIN, GP3=SD_MODE, GP4=XSMT, GP5=HP_EN, GP6=HP_DET

### 2026-02-21（session09）
- キー数確定: 63キー（KLEパースにより確定 / 従来の66は誤り）
- ダイオード数確定: 63個
- アナログスティック確定: 3DSスライドパッド / FPC 4ピン 1.0mmピッチ
- FPCコネクタ確定: Molex 5034800440（C3170007）/ 4P 1.0mm ZIF / VCC=3.3V直結OK
- キーマトリクス物理配置ベース割り当て確定（keyboard/matrix.md）
- QMK info.json作成（keyboard/info.json）
- ダイオード向き: ROW→[>|]→SW→COL（カソードがSW側）
- keyboard.kicad_sch: RP2040完全完成

### 2026-02-21（session08）
- RP2040外部SPI Flash（W25Q32）必須と確認・BOM追加（VL812用と合わせて計2個）
- RP2040用W25Q32接続方法確定（QSPI 4ビット / /CS 10kΩプルアップのみ）
- LED割り当て詳細確定：GP24=LED_CHG(橙) / GP25=LED_FULL(緑) / GP26=LED_ACT
- クリスタル確定：X322512MOB4SI（C70565）/ 12MHz / 12pF / SMD3225-4P / 外付けC 15pF×2

### 2026-02-21（session07）
- キルスイッチ：VSYS→SW→TPS61023/AP2112K VIN に配置確定
- キーレイアウト確定（63キー / 9×8マトリクス）
- RP2040 GPIO割り当て確定（29本/30本）
- パワーシンボル：VSYS / 5V_SYS / +BATT をカスタムパワーシンボルで作成確定
- VL812 usb_hub シート完成

### 2026-02-19〜20
- 主要IC全部のJLCPCB C番号確定（下記参照）

---

### 2026-03-02（session29）
- LED C番号確定（passive_parts.txtに追記）:
  - D1（赤/BQ25895 STAT直結）: **C2286**（KT-0603R / Basic）
  - D2（青/LED_ACT GP23）: **C19171394**（YLED0603B / Extended / 手はんだ）
  - D3（緑/LED_FULL GP22）: **C19273151**（YLED0603G / Extended / 手はんだ）
  - D4（橙/LED_CHG GP21）: **C19273153**（YLED0603O / Extended / 手はんだ）
- タクトスイッチ確定: 肩ボタン（Left/Right）・SW1（電源ボタン）すべて側面押しに変更
  - **C115361**（Alps SKSCLBE010 / 横押しSMD / 3.6×3.5mm / 2.24N）に統一
  - 旧: SKRPABE010（上押し）→ 新: SKSCLBE010（横押し）
  - KiCad要作業: keyboard.kicad_schの肩ボタン2個 + power.kicad_schのSW1 フットプリント変更
  - SW2（キルスイッチ / VSYS物理カット / 5A+スルーホール）: 筐体設計後に確定
- TPA6132A2 EMIフィルタ 2.2nFキャップ追加: **audio.kicad_sch完了**（R8/R54出力→GND / C番号C1604）
- BQ25895 C6（PMID）電圧変更: **power.kicad_sch完了**（10µF 25V / C番号C91606 / Murata GRM188R61E106MA73D）
  - C19702（10V品）は他の10µFに引き続き使用、C6のみC91606

### 2026-03-02（session30）
- フットプリント割り当て調査・確定:
  - easyeda2kicad取得: C115361(SKSCLBE010) / C115360(SKRPABE010) / C9006 / C70565 / C408335 / C3002557 / C19274352 / C157974 / C131337
  - 全シート316個のフットプリント割り当て完了（SW2・J7/J8のみTBD）
  - DNS問題(/etc/hostsにeasyeda.com追加で解決)
- コネクタ確定:
  - J4（バッテリー）: C157974（B8B-PH-K-S / JST PH 8pin / VBAT×4+GND×4）
  - J2/J3（スピーカー）・J6（FAN）: C131337（B2B-PH-K-S / JST PH 2pin）
  - J5（hdmi_adapter）: PinHeader_2x08_P2.00mm_Vertical（ジャンパワイヤー受けパッド）
- Claude.md冷却セクション更新: ファンはRP2040 #1 GP26→BSS138制御（A7Z内蔵コネクタ不使用）
- passive_parts.txtにコネクタセクション追加
- 4層基板の構造・差動ペアとキーマトリクスの干渉対策を検討

### 2026-03-03（session31）
- M.2 SSD追加設計:
  - Cubie A7Z PCIe Gen3 x1 / F0506-16-BGR（16pin 0.5mm FPC / RPi5互換）
  - M.2 2230 NVMe採用 / ソケット: NASM0-S6701-TP40（C367029）
  - FPCコネクタ: FPC-05F-16PH20（C2856801）/ LDO: RT9080-33GJ5（C841192）
  - m2_ssdシート新設・全ピン接続確定・ライブラリ取得済み
  - 注意: M.2 Pin42/44/46/48/56 = NC（SATAピン / PCIe x1では未使用）
- キルスイッチ確定: MSK12C02（C431540）EN制御方式
  - 当初: DMP3010LK3-13（TO-252 P-ch MOSFET）でVSYS直列カット → 発熱問題（1.6W@8A）で断念
  - 変更: MSK12C02でTPS61023 EN pin直接制御（COM→ENノード / NO→GND）
  - MOSFETは不要（ENピンはµA級 → 発熱ゼロ）
  - GP20→10kΩ→BAT54→ENノード の既存保護回路はそのまま流用
  - KiCad power.kicad_sch: SW2配線完了
- バッテリーコネクタ確定: S8B-PH-K-S-LF-SN（C157915）水平型8pin JST PH
  - B8B-PH-K-S（垂直）からS8B-PH-K-S（水平・サイドエントリー）に変更
  - フットプリント: PortaRe0:CONN-TH_S8B-PH-K-S-LF-SN
- ヘッドフォンジャック確定: PJ-307C（C16684）TH 5pin
  - PJ-393-8P（SMD Extended 8pin）から変更（ExtendedかつSMDで不利）
  - ピン配置（データシート確認）:
    - Pin1=GND(Sleeve) / Pin2=L Tip / Pin3=L SW(Pin2ペア) / Pin4=R SW(Pin5ペア) / Pin5=R Ring
  - 接続: Pin1→GND / Pin2→HP_L / Pin3→NC / Pin4→HP_DET(GP6+100kΩpull-up) / Pin5→HP_R
  - HP_DET動作: プラグ未挿入=Pin4-Pin5導通→LOW / 挿入=Pin4開放+pull-up→HIGH
  - KiCad audio.kicad_sch: 配線完了
- 新規ライブラリ取得（easyeda2kicad）:
  - C431540（MSK12C02 スライドスイッチ）/ C157915（S8B-PH-K-S-LF-SN）
  - C16684（PJ-307C）/ C154730（DMP3010LK3-13 / 未使用）
- BOM確認・修正:
  - Y4フットプリント誤り修正（CONN-TH_B2B-PH-K-S → CRYSTAL-SMD_4P-L3.2-W2.5-BL）
  - J7/J8フットプリント空欄: 意図的（PCBエッジ設計・コンポーネント不要）
- **Phase 2 回路設計 全シート完了 → Phase 3 PCBレイアウトへ**

### 2026-03-04（session32）
- ドキュメント構成を整理・スリム化:
  - CONTEXT.md → `archive/` に移動（廃止）
  - CLAUDE.md 冒頭にセッション開始手順を統合（CONTEXT.md参照不要に）
  - CLOSING.md 新規作成（終了処理手順を独立ファイルに）
  - CLAUDE.md のハードウェア仕様を `specs/` に分割
    - specs/index.md（コンポーネント一覧・筐体・PCB仕様）
    - specs/power.md / keyboard.md / audio.md / m2_ssd.md
  - CLAUDE.md: 10.4KB → 2.3KB に削減
  - 信頼優先順位変更: 原文ログ > specs/* > CLAUDE.md > PROGRESS.md
  - PROJECT_PLAN.md・要約_archive/ → `archive/` に移動（ユーザーが手動）
- session_close.py 新規作成（`Claude/session_close.py`）
  - PROGRESS.md の古いセッションログを `archive/PROGRESS_history.md` に自動移動（直近4件残す）
  - git add -A + commit + push を自動実行
  - 使い方: `python Claude/session_close.py "コミットメッセージ"`
- 終了処理フロー確定:
  1. `python Claude/extract_session.py`（原文保存）
  2. Claude: PROGRESS.md・index.md 更新
  3. Claude: README等確認・更新
  4. `python Claude/session_close.py "..."`（archive + git）

### 2026-03-06（session34）
- LS055R1SX04 + MIP-1000 動作確認（PC接続で正常表示 / スマホは解像度固定のため不可）
- MIP-1000確定: STM32（VID_0483/PID_5750 HID）+ N76E003A120 + LP3320B6F（LEDドライバ）
  - LP3320B6F: ENピンPWM調光対応（1%〜100%）/ ただし実装断念（XIAO ESP32-S3破損）
  - 明るさ: 手動6段階・バウンス式（6→5→...→1→2→...→6）・電源オフ後値保持
  - **確定: 明るさ調整は手動運用（RP2040制御不要）**
  - 明るさ調整ボタンはヒンジ経由で下筐体に信号線1本引き出し予定（GNDは下筐体から取る）
- VS-CXMIPI-V1（D000118-VS-CXMIPI-V1-50Hz）購入（5,731円）
  - 届いたらUART（RX/TX 3.3V / N76E003A120）で輝度制御コマンド確認予定
- 受動部品 0603→0402 化（スペース節約）
  - 抵抗: Basic品は全0402化 / Extended品（27Ω/6.04kΩ/750kΩ）は0603維持
  - 特例: 270Ω/56kΩ/220kΩは0402がExtended→0603 Basicのまま
  - コンデンサ 〜4.7µF: 0402化（100nF=C307331 / 1µF=C52923 / 2.2µF=C12530 / 4.7µF=C23733）
  - コンデンサ 10µF: 3.3Vライン→C15525(0402 6.3V) / 5V/VSYS/BATT/PMID→C96446(0603 25V)
  - コンデンサ 22µF（C59461 / 0603）・150µF（C156458 タンタル）: 0603維持
  - KiCadフットプリント修正完了（C6 10µF 25V → 0603 / C104 22µF → 0603）
  - passive_parts.txt・extended_parts.txt 更新済み
- PCBレイアウト: 受動部品以外の配置ほぼ確定（受動部品配置中）
- display.md 新規作成・specs/index.md 更新（LS055R1SX04 / MIP-1000 / VS-CXMIPI-V1 仕様）
- pcb_layout_notes.txt 更新: USB3.0 SS・HDMIをIn2へ移動 / PCIeのみB.Cuに残す

### 2026-03-09（session35）
- TPS61023 FB R_TOP（750kΩ）の接続先ミス確認: `5V_SYS` → `HUB_5V` に修正必要
  - FBピンは出力電圧フィードバック用 → R_TOP上側はTPS61023出力（HUB_5V）に接続すべき
- M.2ソケット（NASM0-S6701-TP40）下クリアランス: **1.1mm**
  - 0402部品（実装高~0.5mm）のみ配置可 / 0603はギリギリ / SOT-23系は厳しい
- PCBレイアウト: 受動部品配置が進行中

### 2026-03-10（session36）
- VL812周辺の受動部品配置方針確定:
  - L3（インダクタ）: VL812から4mm → OK
  - W25Q32 SPI最遠パッド: 6〜7mm → OK
  - SMDAT/SMCLK 4.7kΩ: 5〜6mm → I2C低速なのでOK
  - 水晶（C9006）負荷キャップ（18pF×2）: 水晶の外側→VL812とのXIN/XOUT間に修正済み
  - VBUSDET分圧: 低速アナログなので数mm〜10mm許容
- デカップリングキャップ距離の原則: 1mm以内が理想、2mmまで許容
- PCBレイアウト: 受動部品配置継続中

### 2026-03-12（session37）
- 部品配置完了・ルーティング開始
- RP2040水晶: 3mm以内 → OK / QSPI Flash: 10mm以内 → OK / VL812水晶: 3mm以内 → OK
- ルーティング推奨順: GNDベタ → 電源幹線 → 電源プレーン → スイッチングノード → 高速差動ペア → IC間信号 → 一般信号
- FPC給電（SBCへの電源供給）ピン割り当て修正:
  - SBC給電FPC（24pin）: Pin1〜10=5V / Pin11〜22=GND / Pin23=CC1 / Pin24=CC2
  - CC Rp抵抗: 22kΩ → **10kΩ**に変更（Cubie A7Z 5V/2A → 3A広告が安全）
  - UP_VBUS（SBC→VL812 upstream）: 1pinでOK（検出用のみ）
  - HDMIコントローラ給電FPC: Pin20〜21=GND / Pin22〜24=5V（3pin・1A対応）
  - HDMI 5V（Pin18）: 基板側5V_SYSから供給でOK（DDC/HPD用・50mA以下）
- トレース幅目安: 一般信号0.1〜0.15mm / 3.3V/5V 0.3〜0.5mm / VSYS/5V_SYS 1.5〜2.0mm以上
- デカップリングキャップ距離: 1mm以内理想・2mmまで許容（前回確認）
- GNDベタ: KiCad Fill Zone（Net=GND / Solid / Direct connect）でOK
- B.Cu電源ルーティング: J4（バッテリー）〜BQ25895間は短距離・障害物なしのためB.Cuで直結OK
- パッド根元で0.5mm程度に細くなるのは短区間なら許容
- Teardrops: 全配線完了後にEdit→Teardrops...で一括適用推奨
- ビア vs マイクロビア: このプロジェクトは通常ビアのみ（マイクロビアはHDI基板が必要）

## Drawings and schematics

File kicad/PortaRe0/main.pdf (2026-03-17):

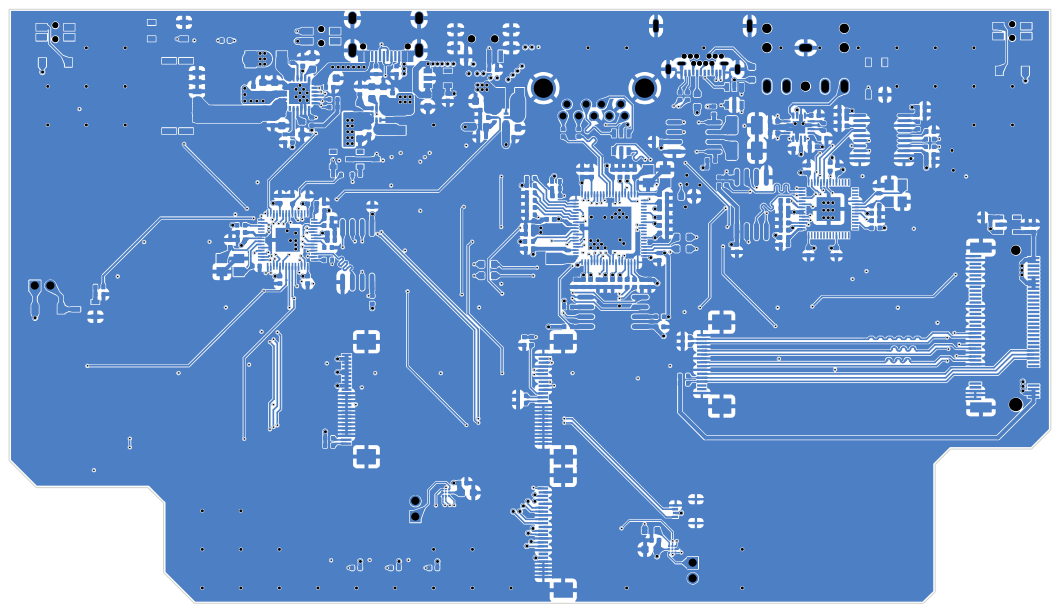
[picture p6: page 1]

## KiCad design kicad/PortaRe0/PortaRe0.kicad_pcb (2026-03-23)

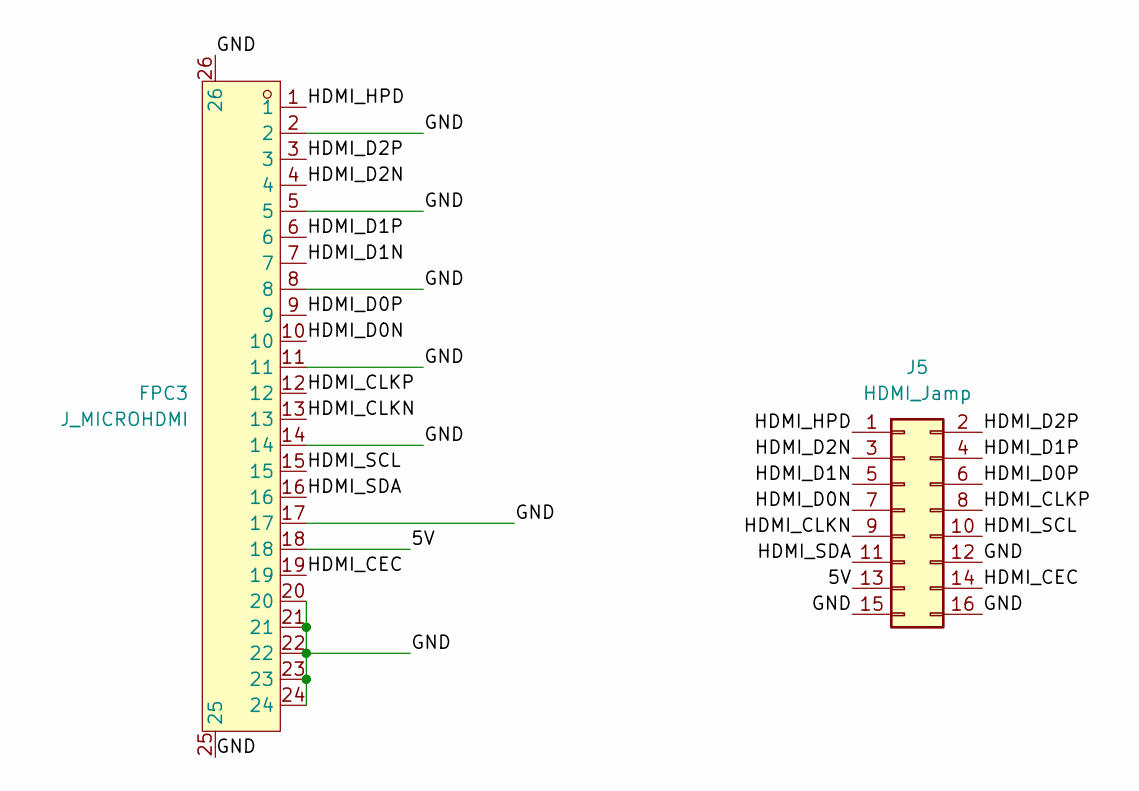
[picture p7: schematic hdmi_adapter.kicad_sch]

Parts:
FPC3: J_MICROHDMI; FPC-SMD_24P-P0.50_FPC-05F-24PH20; LCSC Part C2856805
J5: HDMI_Jamp; PinHeader_2x08_P2.00mm_Vertical

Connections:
unnamed: FPC3.1, J5.1
unnamed: FPC3.3, J5.2
unnamed: FPC3.4, J5.3
unnamed: FPC3.6, J5.4
unnamed: FPC3.7, J5.5
unnamed: FPC3.9, J5.6
unnamed: FPC3.10, J5.7
unnamed: FPC3.2, FPC3.5, FPC3.8, FPC3.11, FPC3.14, FPC3.17, FPC3.20, FPC3.21, FPC3.22, FPC3.23, FPC3.24, FPC3.25, FPC3.26, J5.12, J5.15, J5.16
unnamed: FPC3.12, J5.8
unnamed: FPC3.13, J5.9
unnamed: FPC3.15, J5.10
unnamed: FPC3.16, J5.11
unnamed: FPC3.18, J5.13
unnamed: FPC3.19, J5.14

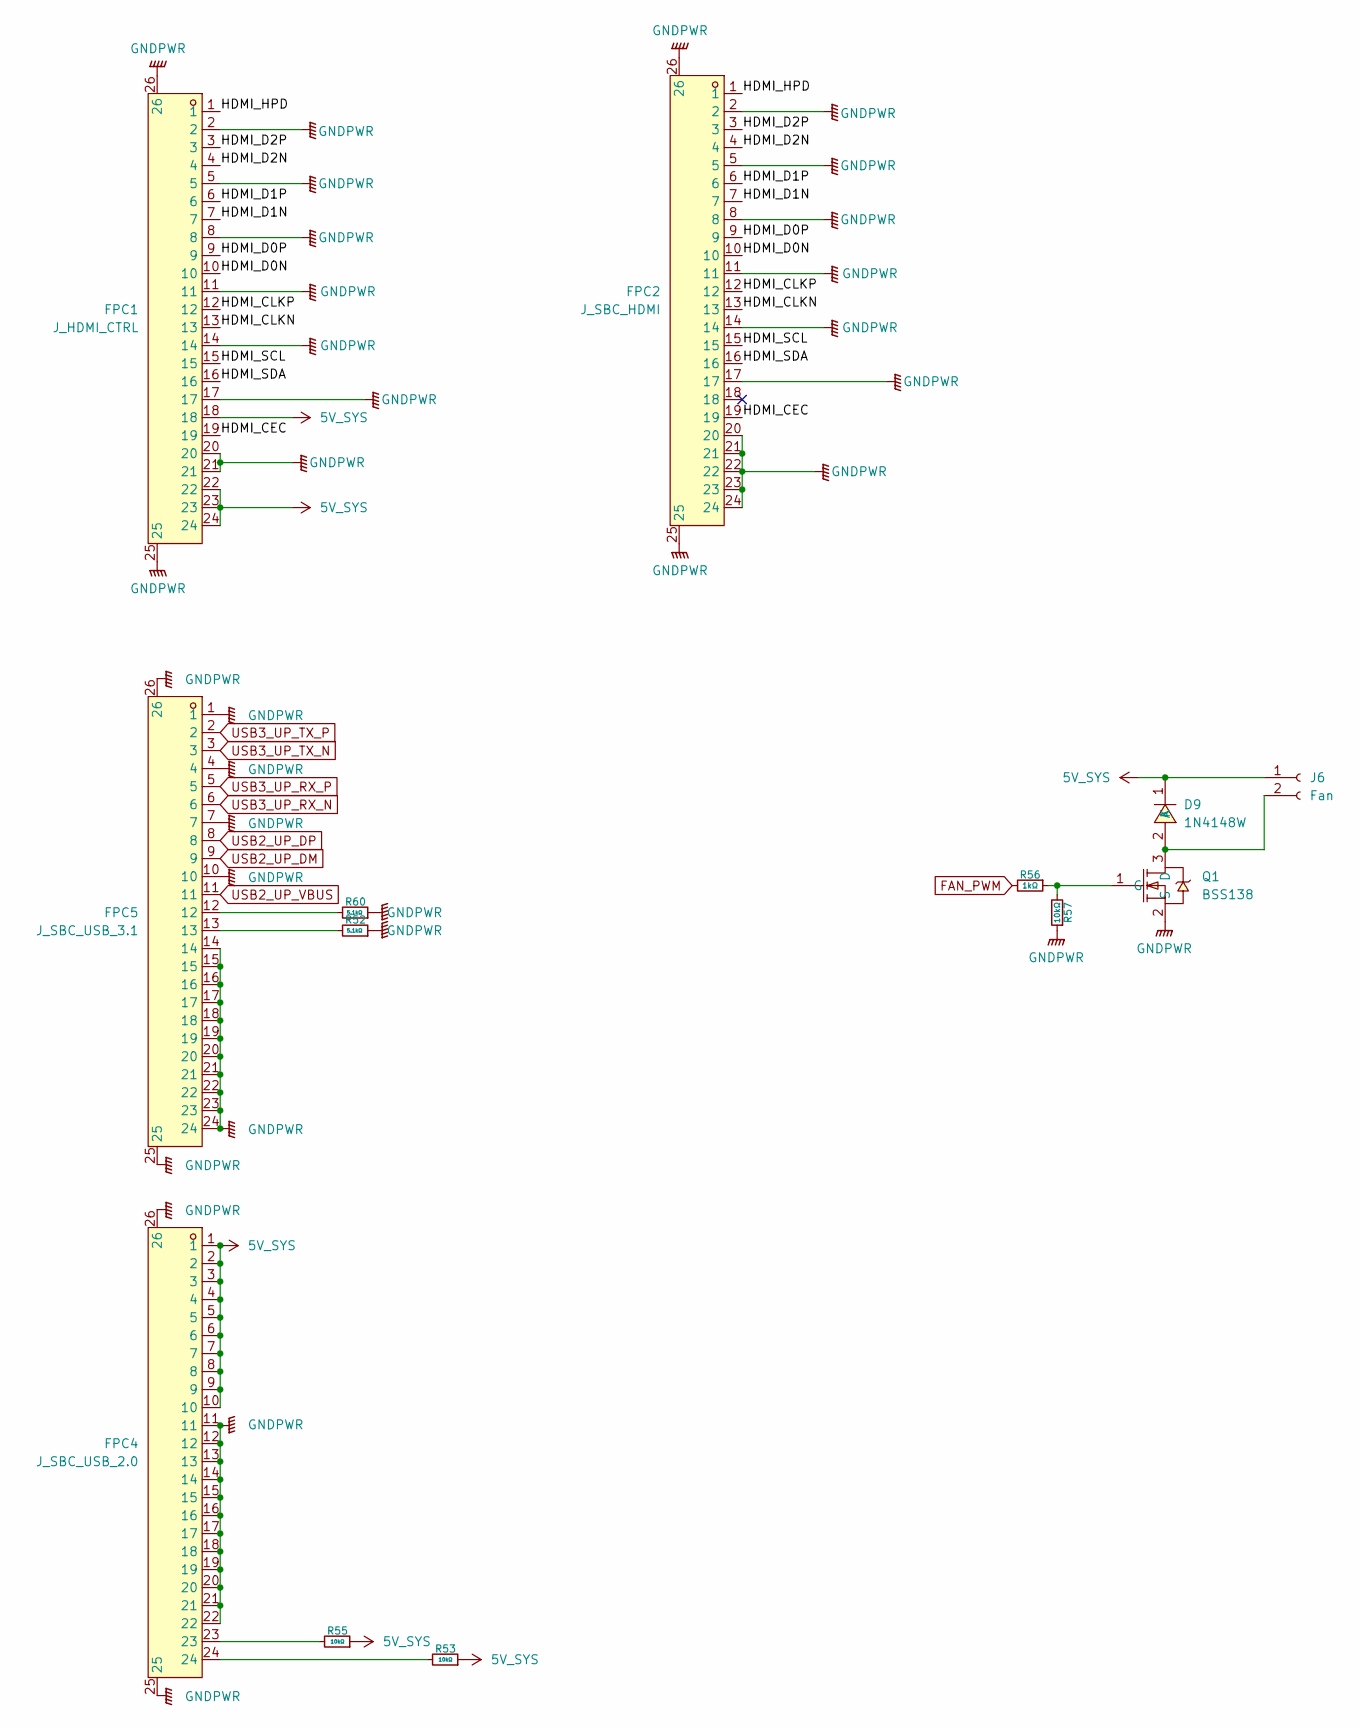
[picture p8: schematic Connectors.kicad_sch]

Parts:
D9: 1N4148W; SOD-123_L2.8-W1.8-LS3.7-RD; LCSC Part C2099
FPC1: J_HDMI_CTRL; FPC-SMD_24P-P0.50_FPC-05F-24PH20; LCSC Part C2856805
FPC2: J_SBC_HDMI; FPC-SMD_24P-P0.50_FPC-05F-24PH20; LCSC Part C2856805
FPC4: J_SBC_USB_2.0; FPC-SMD_24P-P0.50_FPC-05F-24PH20; LCSC Part C2856805
FPC5: J_SBC_USB_3.1; FPC-SMD_24P-P0.50_FPC-05F-24PH20; LCSC Part C2856805
J6: Fan; CONN-TH_S2B-PH-K-S-LF-SN
Q1: BSS138; SOT-23-3_L2.9-W1.6-P1.90-LS2.8-BR; LCSC Part C52895
R52, R60: 5.1kΩ; R_0402_1005Metric
R53, R55, R57: 10kΩ; R_0402_1005Metric
R56: 1kΩ; R_0402_1005Metric

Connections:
5V_SYS: D9.1 (K), FPC1.18, FPC1.22, FPC1.23, FPC1.24, FPC4.1, FPC4.2, FPC4.3, FPC4.4, FPC4.5, FPC4.6, FPC4.7, FPC4.8, FPC4.9, FPC4.10, J6.1, R53.1, R55.1; also elsewhere on the board
FAN_PWM: R56.2; also elsewhere on the board
GND: FPC1.2, FPC1.5, FPC1.8, FPC1.11, FPC1.14, FPC1.17, FPC1.20, FPC1.21, FPC1.25, FPC1.26, FPC2.2, FPC2.5, FPC2.8, FPC2.11, FPC2.14, FPC2.17, FPC2.20, FPC2.21, FPC2.22, FPC2.23, FPC2.24, FPC2.25, FPC2.26, FPC4.11, FPC4.12, FPC4.13, FPC4.14, FPC4.15, FPC4.16, FPC4.17, FPC4.18, FPC4.19, FPC4.20, FPC4.21, FPC4.22, FPC4.25, FPC4.26, FPC5.1, FPC5.4, FPC5.7, FPC5.10, FPC5.14, FPC5.15, FPC5.16, FPC5.17, FPC5.18, FPC5.19, FPC5.20, FPC5.21, FPC5.22, FPC5.23, FPC5.24, FPC5.25, FPC5.26, Q1.2 (S), R52.1, R57.1, R60.1; also elsewhere on the board
unnamed 109: D9.2 (A), J6.2, Q1.3 (D); also elsewhere on the board
unnamed: FPC1.1, FPC2.1
unnamed: FPC1.3, FPC2.3
unnamed: FPC1.4, FPC2.4
unnamed: FPC1.6, FPC2.6
unnamed: FPC1.7, FPC2.7
unnamed: FPC1.9, FPC2.9
unnamed: FPC1.10, FPC2.10
unnamed: FPC1.12, FPC2.12
unnamed: FPC1.13, FPC2.13
unnamed: FPC1.15, FPC2.15
unnamed: FPC1.16, FPC2.16
unnamed: FPC1.19, FPC2.19
unnamed 136: FPC4.23, R55.2; also elsewhere on the board
unnamed 137: FPC4.24, R53.2; also elsewhere on the board
unnamed 138: FPC5.12, R60.2; also elsewhere on the board
unnamed 139: FPC5.13, R52.2; also elsewhere on the board
unnamed: Q1.1 (G), R56.1, R57.2

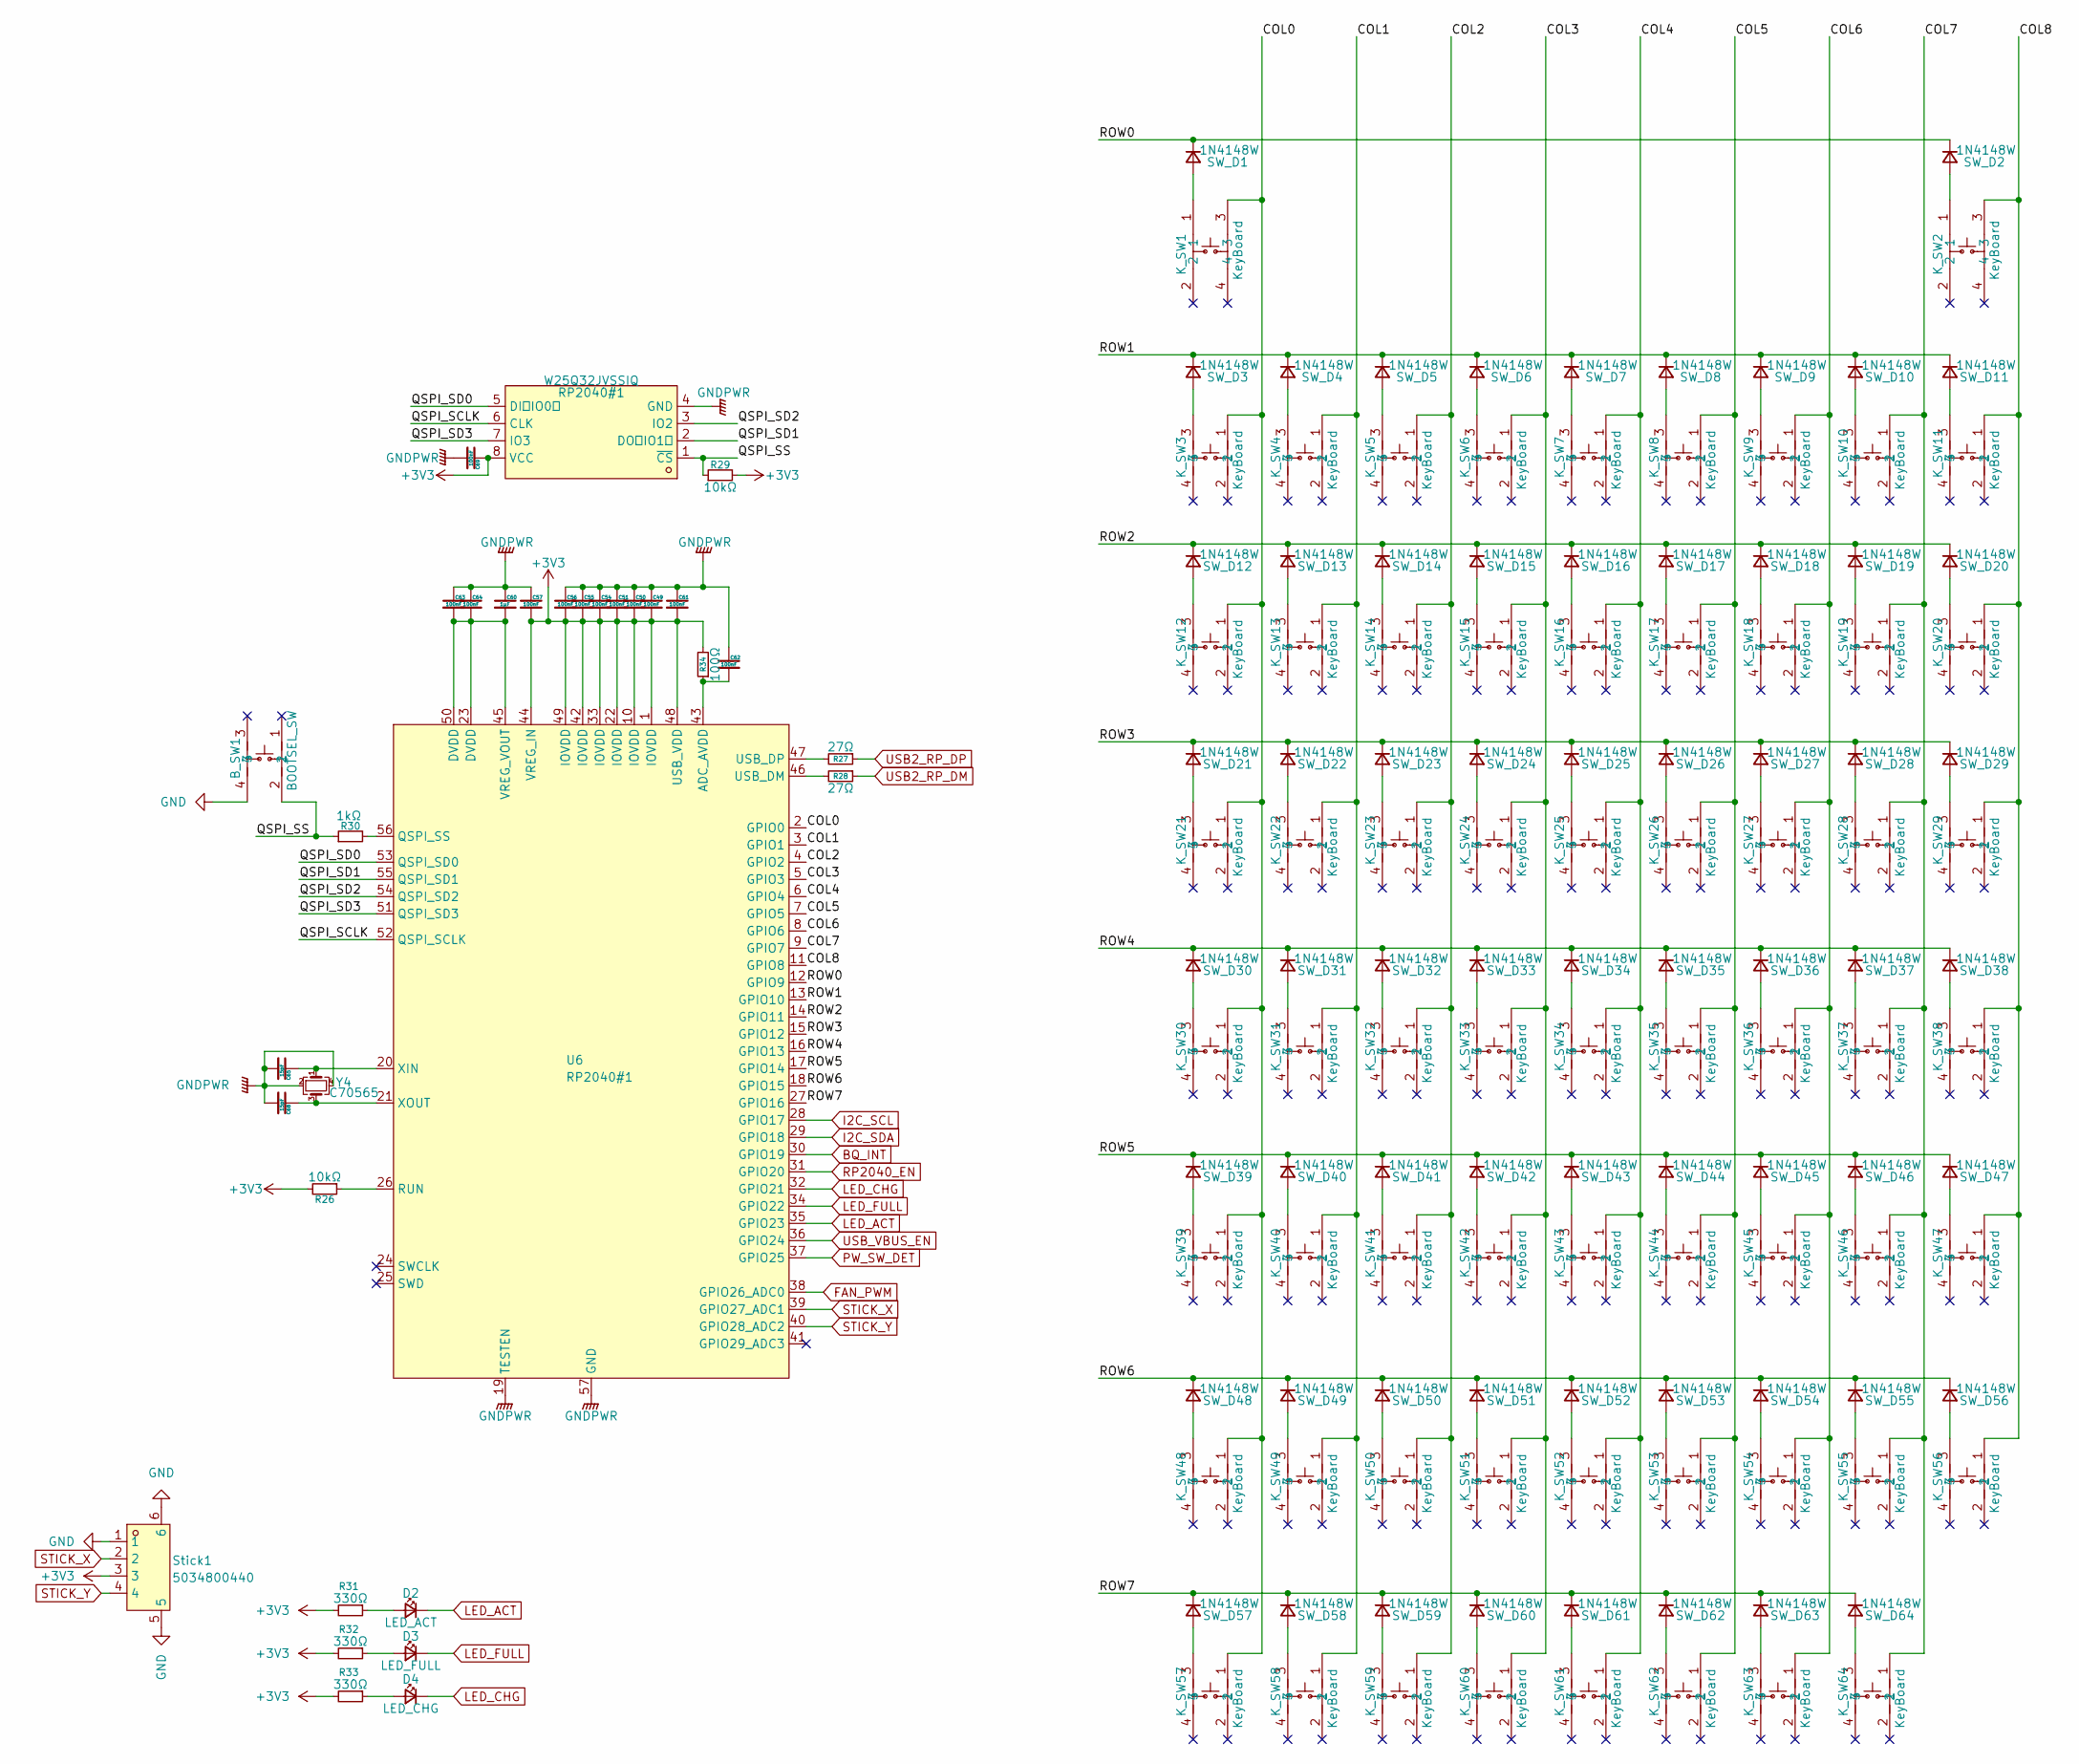
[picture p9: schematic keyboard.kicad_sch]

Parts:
B_SW1: BOOTSEL_SW; KEY-SMD_4P-L4.2-W3.2-P2.20-LS4.6; LCSC Part C115360
C49, C50, C51, C54, C55, C56, C57, C61, C62, C63, C64, C69: 100nF; C_0402_1005Metric
C60: 1μF; C_0402_1005Metric
C65, C68: 15pF; C_0402_1005Metric
D2: LED_ACT; LED_0603_1608Metric
D3: LED_FULL; LED_0603_1608Metric
D4: LED_CHG; LED_0603_1608Metric
K_SW1, K_SW2: KeyBoard; KEY-SMD_4P-SKSCLXX010; LCSC Part C115361
K_SW3, K_SW4, K_SW5, K_SW6, K_SW7, K_SW8, K_SW9, K_SW10, K_SW11, K_SW12, K_SW13, K_SW14, K_SW15, K_SW16, K_SW17, K_SW18, K_SW19, K_SW20, K_SW21, K_SW22, K_SW23, K_SW24, K_SW25, K_SW26, K_SW27, K_SW28, K_SW29, K_SW30, K_SW31, K_SW32, K_SW33, K_SW34, K_SW35, K_SW36, K_SW37, K_SW38, K_SW39, K_SW40, K_SW41, K_SW42, K_SW43, K_SW44, K_SW45, K_SW46, K_SW47, K_SW48, K_SW49, K_SW50, K_SW51, K_SW52, K_SW53, K_SW54, K_SW55, K_SW56, K_SW57, K_SW58, K_SW59, K_SW60, K_SW61, K_SW62, K_SW63, K_SW64: KeyBoard; KEY-SMD_4P-L4.2-W3.2-P2.20-LS4.6; LCSC Part C115360
R26, R29: 10kΩ; R_0402_1005Metric
R27, R28: 27Ω; R_0603_1608Metric
R30: 1kΩ; R_0402_1005Metric
R31, R32, R33: 330Ω; R_0402_1005Metric
R34: 100Ω; R_0402_1005Metric
RP2040#1: W25Q32JVSSIQ; SOIC-8_L5.3-W5.3-P1.27-LS8.0-BL; LCSC Part C82344
SW_D1, SW_D2, SW_D3, SW_D4, SW_D5, SW_D6, SW_D7, SW_D8, SW_D9, SW_D10, SW_D11, SW_D12, SW_D13, SW_D14, SW_D15, SW_D16, SW_D17, SW_D18, SW_D19, SW_D20, SW_D21, SW_D22, SW_D23, SW_D24, SW_D25, SW_D26, SW_D27, SW_D28, SW_D29, SW_D30, SW_D31, SW_D32, SW_D33, SW_D34, SW_D35, SW_D36, SW_D37, SW_D38, SW_D39, SW_D40, SW_D41, SW_D42, SW_D43, SW_D44, SW_D45, SW_D46, SW_D47, SW_D48, SW_D49, SW_D50, SW_D51, SW_D52, SW_D53, SW_D54, SW_D55, SW_D56, SW_D57, SW_D58, SW_D59, SW_D60, SW_D61, SW_D62, SW_D63, SW_D64: 1N4148W; SOD-123_L2.8-W1.8-LS3.7-RD
Stick1: 5034800440; FPC-SMD_5034800400; LCSC Part C3170007
U6: RP2040#1; LQFN-56_L7.0-W7.0-P0.4-EP; LCSC Part C2040
Y4: C70565; CRYSTAL-SMD_4P-L3.2-W2.5-BL

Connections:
+3V3: C49.2, C50.2, C51.2, C54.2, C55.2, C56.2, C57.2, C61.2, C69.1, R26.2, R29.2, R31.2, R32.2, R33.2, R34.2, RP2040#1.8 (VCC), Stick1.3, U6.1 (IOVDD), U6.10 (IOVDD), U6.22 (IOVDD), U6.33 (IOVDD), U6.42 (IOVDD), U6.44 (VREG_IN), U6.48 (USB_VDD), U6.49 (IOVDD); also elsewhere on the board
/keyboard/COL0: K_SW1.3, K_SW3.1, K_SW12.1, K_SW21.1, K_SW30.1, K_SW39.1, K_SW48.1, K_SW57.1, U6.2 (GPIO0)
/keyboard/COL1: K_SW4.1, K_SW13.1, K_SW22.1, K_SW31.1, K_SW40.1, K_SW49.1, K_SW58.1, U6.3 (GPIO1)
/keyboard/COL2: K_SW5.1, K_SW14.1, K_SW23.1, K_SW32.1, K_SW41.1, K_SW50.1, K_SW59.1, U6.4 (GPIO2)
/keyboard/COL3: K_SW6.1, K_SW15.1, K_SW24.1, K_SW33.1, K_SW42.1, K_SW51.1, K_SW60.1, U6.5 (GPIO3)
/keyboard/COL4: K_SW7.1, K_SW16.1, K_SW25.1, K_SW34.1, K_SW43.1, K_SW52.1, K_SW61.1, U6.6 (GPIO4)
/keyboard/COL5: K_SW8.1, K_SW17.1, K_SW26.1, K_SW35.1, K_SW44.1, K_SW53.1, K_SW62.1, U6.7 (GPIO5)
/keyboard/COL6: K_SW9.1, K_SW18.1, K_SW27.1, K_SW36.1, K_SW45.1, K_SW54.1, K_SW63.1, U6.8 (GPIO6)
/keyboard/COL7: K_SW10.1, K_SW19.1, K_SW28.1, K_SW37.1, K_SW46.1, K_SW55.1, K_SW64.1, U6.9 (GPIO7)
/keyboard/COL8: K_SW2.3, K_SW11.1, K_SW20.1, K_SW29.1, K_SW38.1, K_SW47.1, K_SW56.1, U6.11 (GPIO8)
/keyboard/QSPI_SCLK: RP2040#1.6 (CLK), U6.52 (QSPI_SCLK)
/keyboard/QSPI_SD0: RP2040#1.5 (DI（IO0）), U6.53 (QSPI_SD0)
/keyboard/QSPI_SD1: RP2040#1.2 (DO（IO1）), U6.55 (QSPI_SD1)
/keyboard/QSPI_SD2: RP2040#1.3 (IO2), U6.54 (QSPI_SD2)
/keyboard/QSPI_SD3: RP2040#1.7 (IO3), U6.51 (QSPI_SD3)
/keyboard/QSPI_SS: B_SW1.2, R29.1, R30.1, RP2040#1.1 (~CS)
/keyboard/ROW0: SW_D1.1 (K), SW_D2.1 (K), U6.12 (GPIO9)
/keyboard/ROW1: SW_D3.1 (K), SW_D4.1 (K), SW_D5.1 (K), SW_D6.1 (K), SW_D7.1 (K), SW_D8.1 (K), SW_D9.1 (K), SW_D10.1 (K), SW_D11.1 (K), U6.13 (GPIO10)
/keyboard/ROW2: SW_D12.1 (K), SW_D13.1 (K), SW_D14.1 (K), SW_D15.1 (K), SW_D16.1 (K), SW_D17.1 (K), SW_D18.1 (K), SW_D19.1 (K), SW_D20.1 (K), U6.14 (GPIO11)
/keyboard/ROW3: SW_D21.1 (K), SW_D22.1 (K), SW_D23.1 (K), SW_D24.1 (K), SW_D25.1 (K), SW_D26.1 (K), SW_D27.1 (K), SW_D28.1 (K), SW_D29.1 (K), U6.15 (GPIO12)
/keyboard/ROW4: SW_D30.1 (K), SW_D31.1 (K), SW_D32.1 (K), SW_D33.1 (K), SW_D34.1 (K), SW_D35.1 (K), SW_D36.1 (K), SW_D37.1 (K), SW_D38.1 (K), U6.16 (GPIO13)
/keyboard/ROW5: SW_D39.1 (K), SW_D40.1 (K), SW_D41.1 (K), SW_D42.1 (K), SW_D43.1 (K), SW_D44.1 (K), SW_D45.1 (K), SW_D46.1 (K), SW_D47.1 (K), U6.17 (GPIO14)
/keyboard/ROW6: SW_D48.1 (K), SW_D49.1 (K), SW_D50.1 (K), SW_D51.1 (K), SW_D52.1 (K), SW_D53.1 (K), SW_D54.1 (K), SW_D55.1 (K), SW_D56.1 (K), U6.18 (GPIO15)
/keyboard/ROW7: SW_D57.1 (K), SW_D58.1 (K), SW_D59.1 (K), SW_D60.1 (K), SW_D61.1 (K), SW_D62.1 (K), SW_D63.1 (K), SW_D64.1 (K), U6.27 (GPIO16)
BQ_INT: U6.30 (GPIO19); also elsewhere on the board
FAN_PWM: U6.38 (GPIO26_ADC0); also elsewhere on the board
GND: B_SW1.4, C49.1, C50.1, C51.1, C54.1, C55.1, C56.1, C57.1, C60.1, C61.1, C62.1, C63.1, C64.1, C65.2, C68.2, C69.2, RP2040#1.4 (GND), Stick1.1, Stick1.5, Stick1.6, U6.19 (TESTEN), U6.57 (GND), Y4.2, Y4.4; also elsewhere on the board
I2C_SCL: U6.28 (GPIO17); also elsewhere on the board
I2C_SDA: U6.29 (GPIO18); also elsewhere on the board
LED_ACT: D2.1 (K), U6.35 (GPIO23)
LED_CHG: D4.1 (K), U6.32 (GPIO21)
LED_FULL: D3.1 (K), U6.34 (GPIO22)
unnamed: D2.2 (A), R31.1
unnamed: D3.2 (A), R32.1
unnamed: D4.2 (A), R33.1
unnamed: K_SW1.1, SW_D1.2 (A)
unnamed: K_SW2.1, SW_D2.2 (A)
unnamed: K_SW3.3, SW_D3.2 (A)
unnamed: K_SW4.3, SW_D4.2 (A)
unnamed: K_SW5.3, SW_D5.2 (A)
unnamed: K_SW6.3, SW_D6.2 (A)
unnamed: K_SW7.3, SW_D7.2 (A)
unnamed: K_SW8.3, SW_D8.2 (A)
unnamed: K_SW9.3, SW_D9.2 (A)
unnamed: K_SW10.3, SW_D10.2 (A)
unnamed: K_SW11.3, SW_D11.2 (A)
unnamed: K_SW12.3, SW_D12.2 (A)
unnamed: K_SW13.3, SW_D13.2 (A)
unnamed: K_SW14.3, SW_D14.2 (A)
unnamed: K_SW15.3, SW_D15.2 (A)
unnamed: K_SW16.3, SW_D16.2 (A)
unnamed: K_SW17.3, SW_D17.2 (A)
unnamed: K_SW18.3, SW_D18.2 (A)
unnamed: K_SW19.3, SW_D19.2 (A)
unnamed: K_SW20.3, SW_D20.2 (A)
unnamed: K_SW21.3, SW_D21.2 (A)
unnamed: K_SW22.3, SW_D22.2 (A)
unnamed: K_SW23.3, SW_D23.2 (A)
unnamed: K_SW24.3, SW_D24.2 (A)
unnamed: K_SW25.3, SW_D25.2 (A)
unnamed: K_SW26.3, SW_D26.2 (A)
unnamed: K_SW27.3, SW_D27.2 (A)
unnamed: K_SW28.3, SW_D28.2 (A)
unnamed: K_SW29.3, SW_D29.2 (A)
unnamed: K_SW30.3, SW_D30.2 (A)
unnamed: K_SW31.3, SW_D31.2 (A)
unnamed: K_SW32.3, SW_D32.2 (A)
unnamed: K_SW33.3, SW_D33.2 (A)
unnamed: K_SW34.3, SW_D34.2 (A)
unnamed: K_SW35.3, SW_D35.2 (A)
unnamed: K_SW36.3, SW_D36.2 (A)
unnamed: K_SW37.3, SW_D37.2 (A)
unnamed: K_SW38.3, SW_D38.2 (A)
unnamed: K_SW39.3, SW_D39.2 (A)
unnamed: K_SW40.3, SW_D40.2 (A)
unnamed: K_SW41.3, SW_D41.2 (A)
unnamed: K_SW42.3, SW_D42.2 (A)
unnamed: K_SW43.3, SW_D43.2 (A)
unnamed: K_SW44.3, SW_D44.2 (A)
unnamed: K_SW45.3, SW_D45.2 (A)
unnamed: K_SW46.3, SW_D46.2 (A)
unnamed: K_SW47.3, SW_D47.2 (A)
unnamed: K_SW48.3, SW_D48.2 (A)
unnamed: K_SW49.3, SW_D49.2 (A)
unnamed: K_SW50.3, SW_D50.2 (A)
unnamed: K_SW51.3, SW_D51.2 (A)
unnamed: K_SW52.3, SW_D52.2 (A)
unnamed: K_SW53.3, SW_D53.2 (A)
unnamed: K_SW54.3, SW_D54.2 (A)
unnamed: K_SW55.3, SW_D55.2 (A)
unnamed: K_SW56.3, SW_D56.2 (A)
unnamed: K_SW57.3, SW_D57.2 (A)
unnamed: K_SW58.3, SW_D58.2 (A)
unnamed: K_SW59.3, SW_D59.2 (A)
unnamed: K_SW60.3, SW_D60.2 (A)
unnamed: K_SW61.3, SW_D61.2 (A)
unnamed: K_SW62.3, SW_D62.2 (A)
unnamed: K_SW63.3, SW_D63.2 (A)
unnamed: K_SW64.3, SW_D64.2 (A)
unnamed: C62.2, R34.1, U6.43 (ADC_AVDD)
unnamed: R30.2, U6.56 (QSPI_SS)
unnamed: R26.1, U6.26 (RUN)
unnamed: R28.2, U6.46 (USB_DM)
unnamed: R27.2, U6.47 (USB_DP)
unnamed: C60.2, C63.2, C64.2, U6.23 (DVDD), U6.45 (VREG_VOUT), U6.50 (DVDD)
unnamed: C65.1, U6.20 (XIN), Y4.1
unnamed: C68.1, U6.21 (XOUT), Y4.3
PW_SW_DET: U6.37 (GPIO25); also elsewhere on the board
RP2040_EN: U6.31 (GPIO20); also elsewhere on the board
STICK_X: Stick1.2, U6.39 (GPIO27_ADC1); also elsewhere on the board
STICK_Y: Stick1.4, U6.40 (GPIO28_ADC2); also elsewhere on the board
USB2_RP_DM: R28.1; also elsewhere on the board
USB2_RP_DP: R27.1; also elsewhere on the board
USB_VBUS_EN: U6.36 (GPIO24); also elsewhere on the board

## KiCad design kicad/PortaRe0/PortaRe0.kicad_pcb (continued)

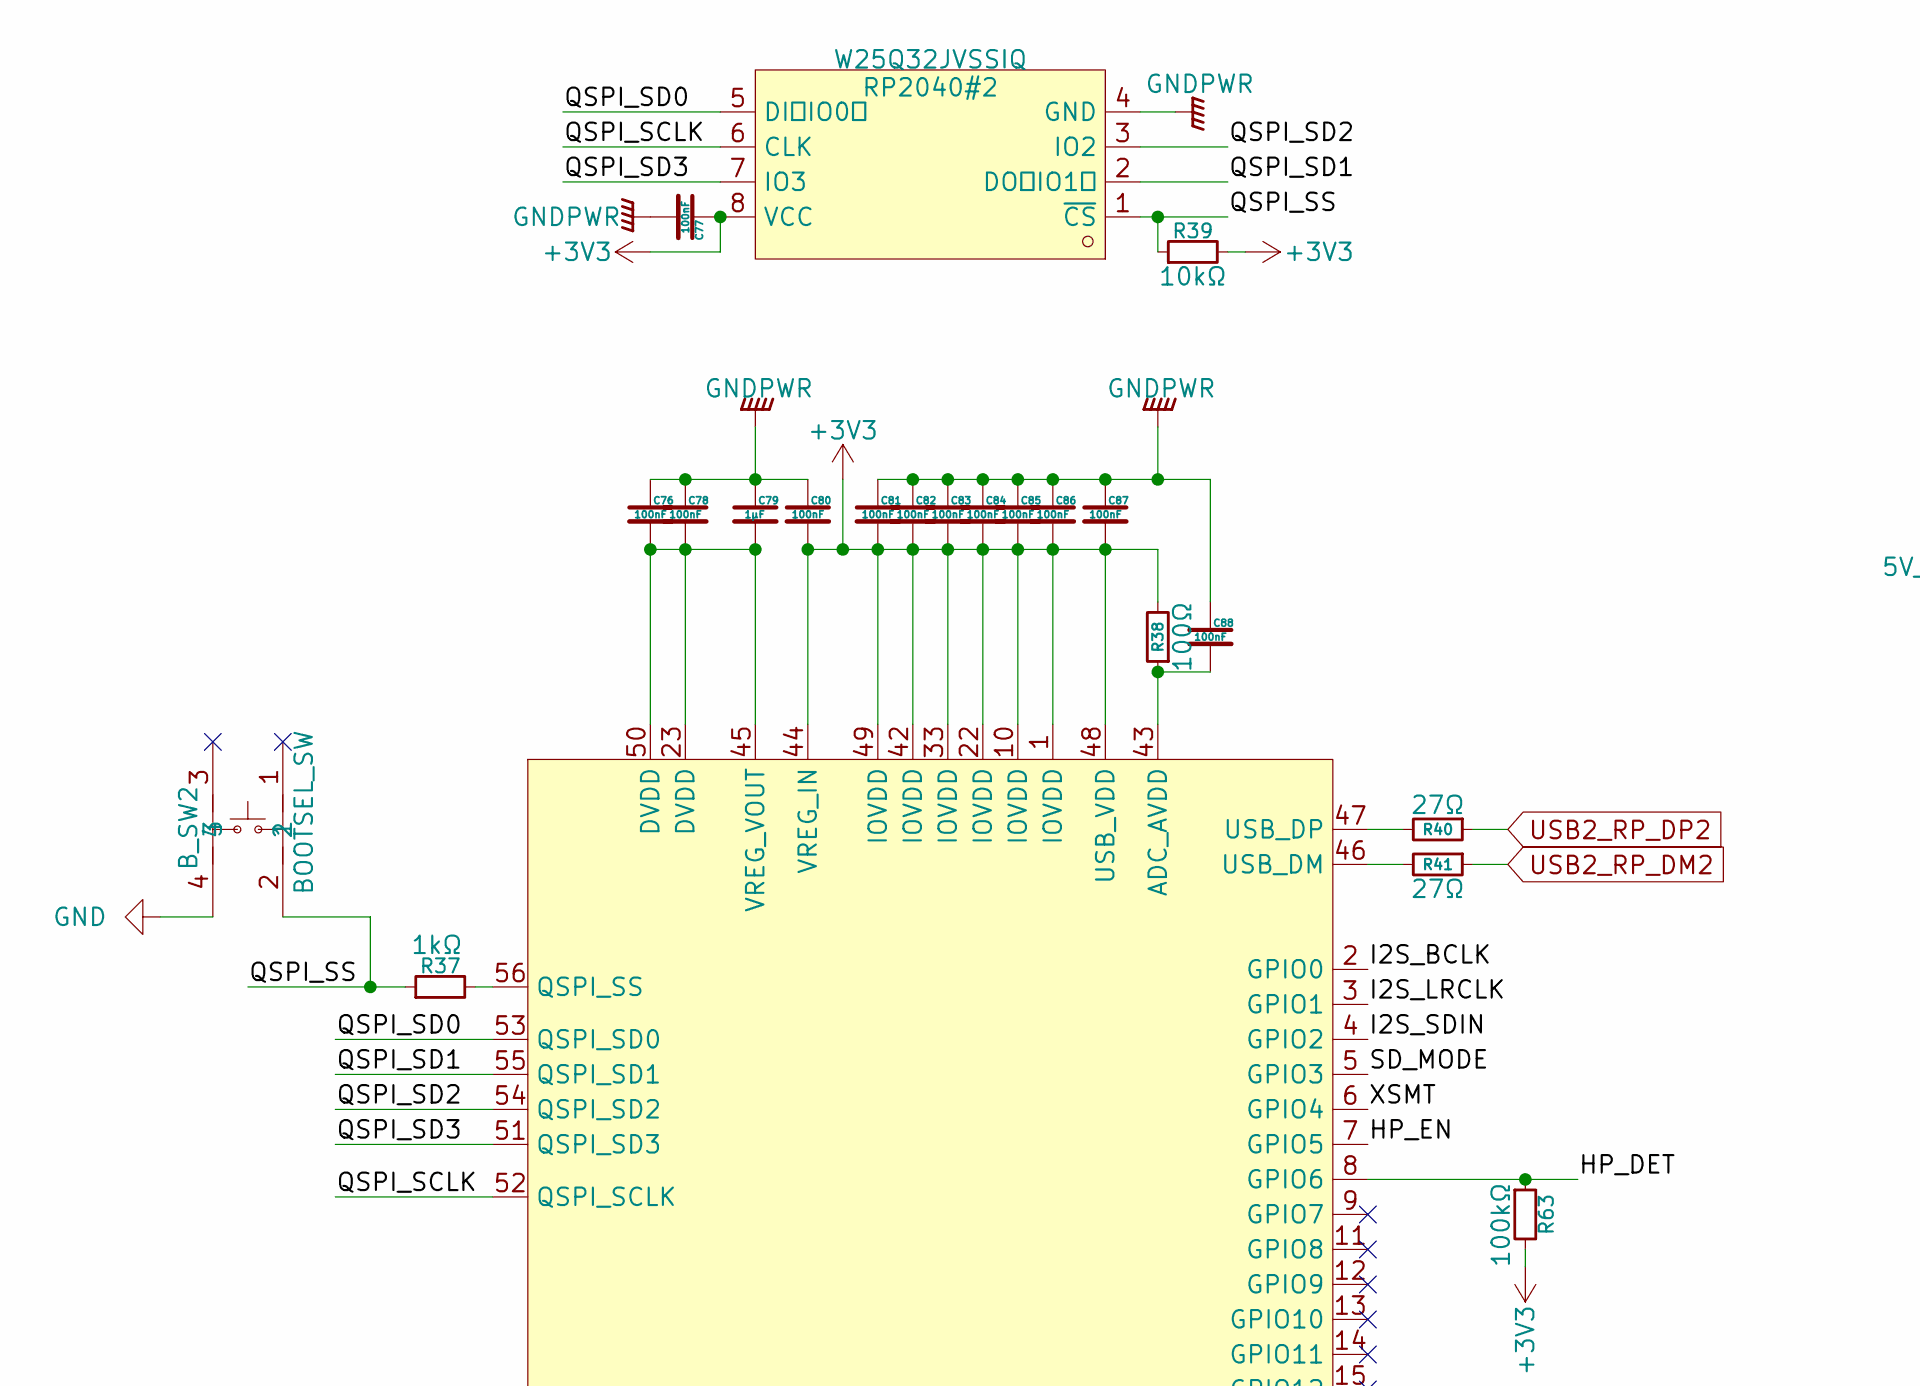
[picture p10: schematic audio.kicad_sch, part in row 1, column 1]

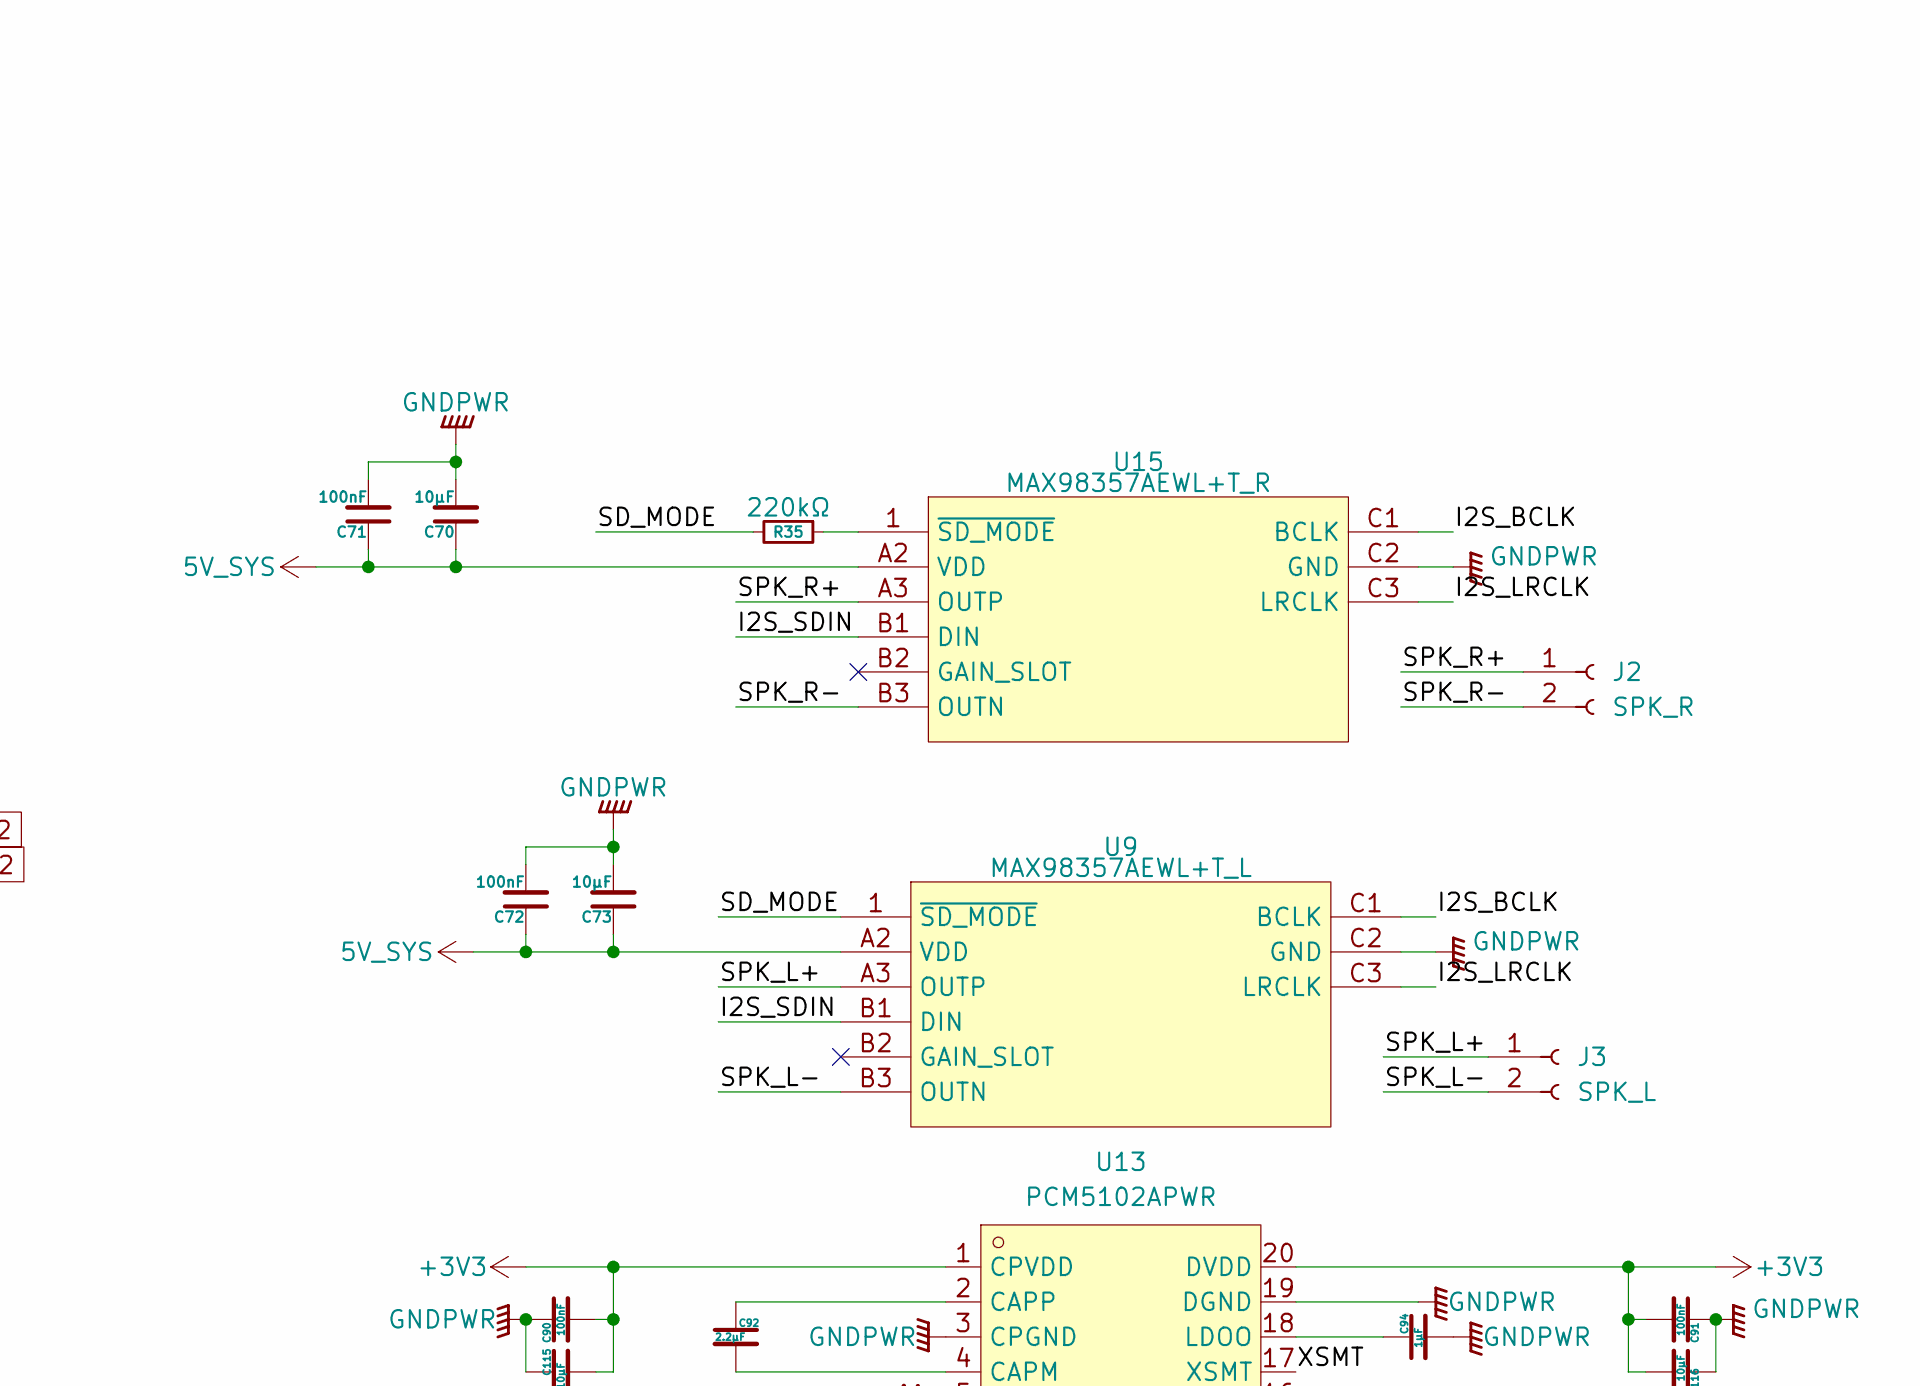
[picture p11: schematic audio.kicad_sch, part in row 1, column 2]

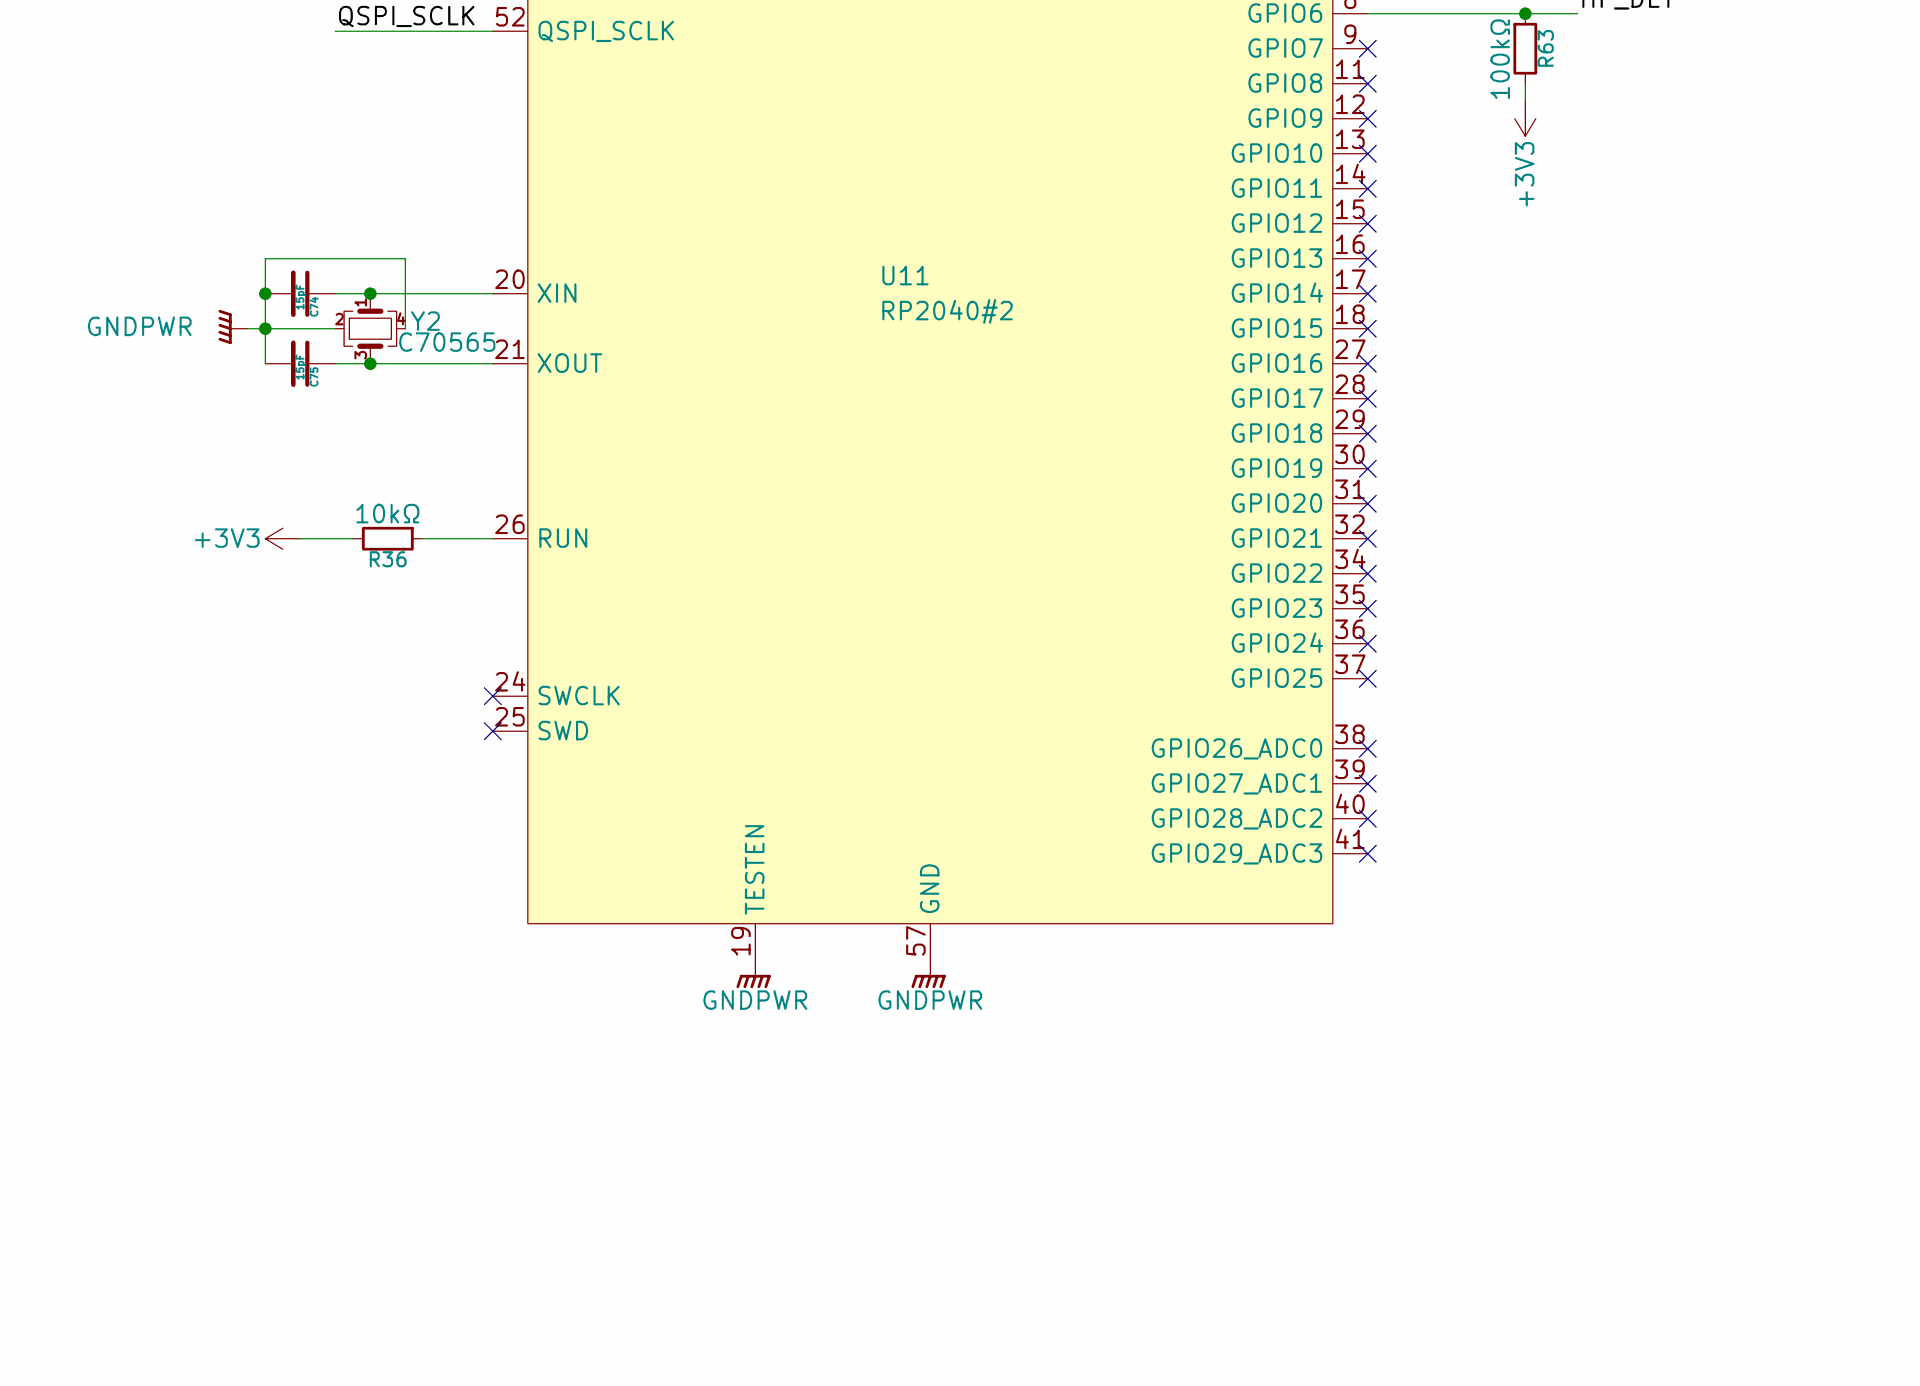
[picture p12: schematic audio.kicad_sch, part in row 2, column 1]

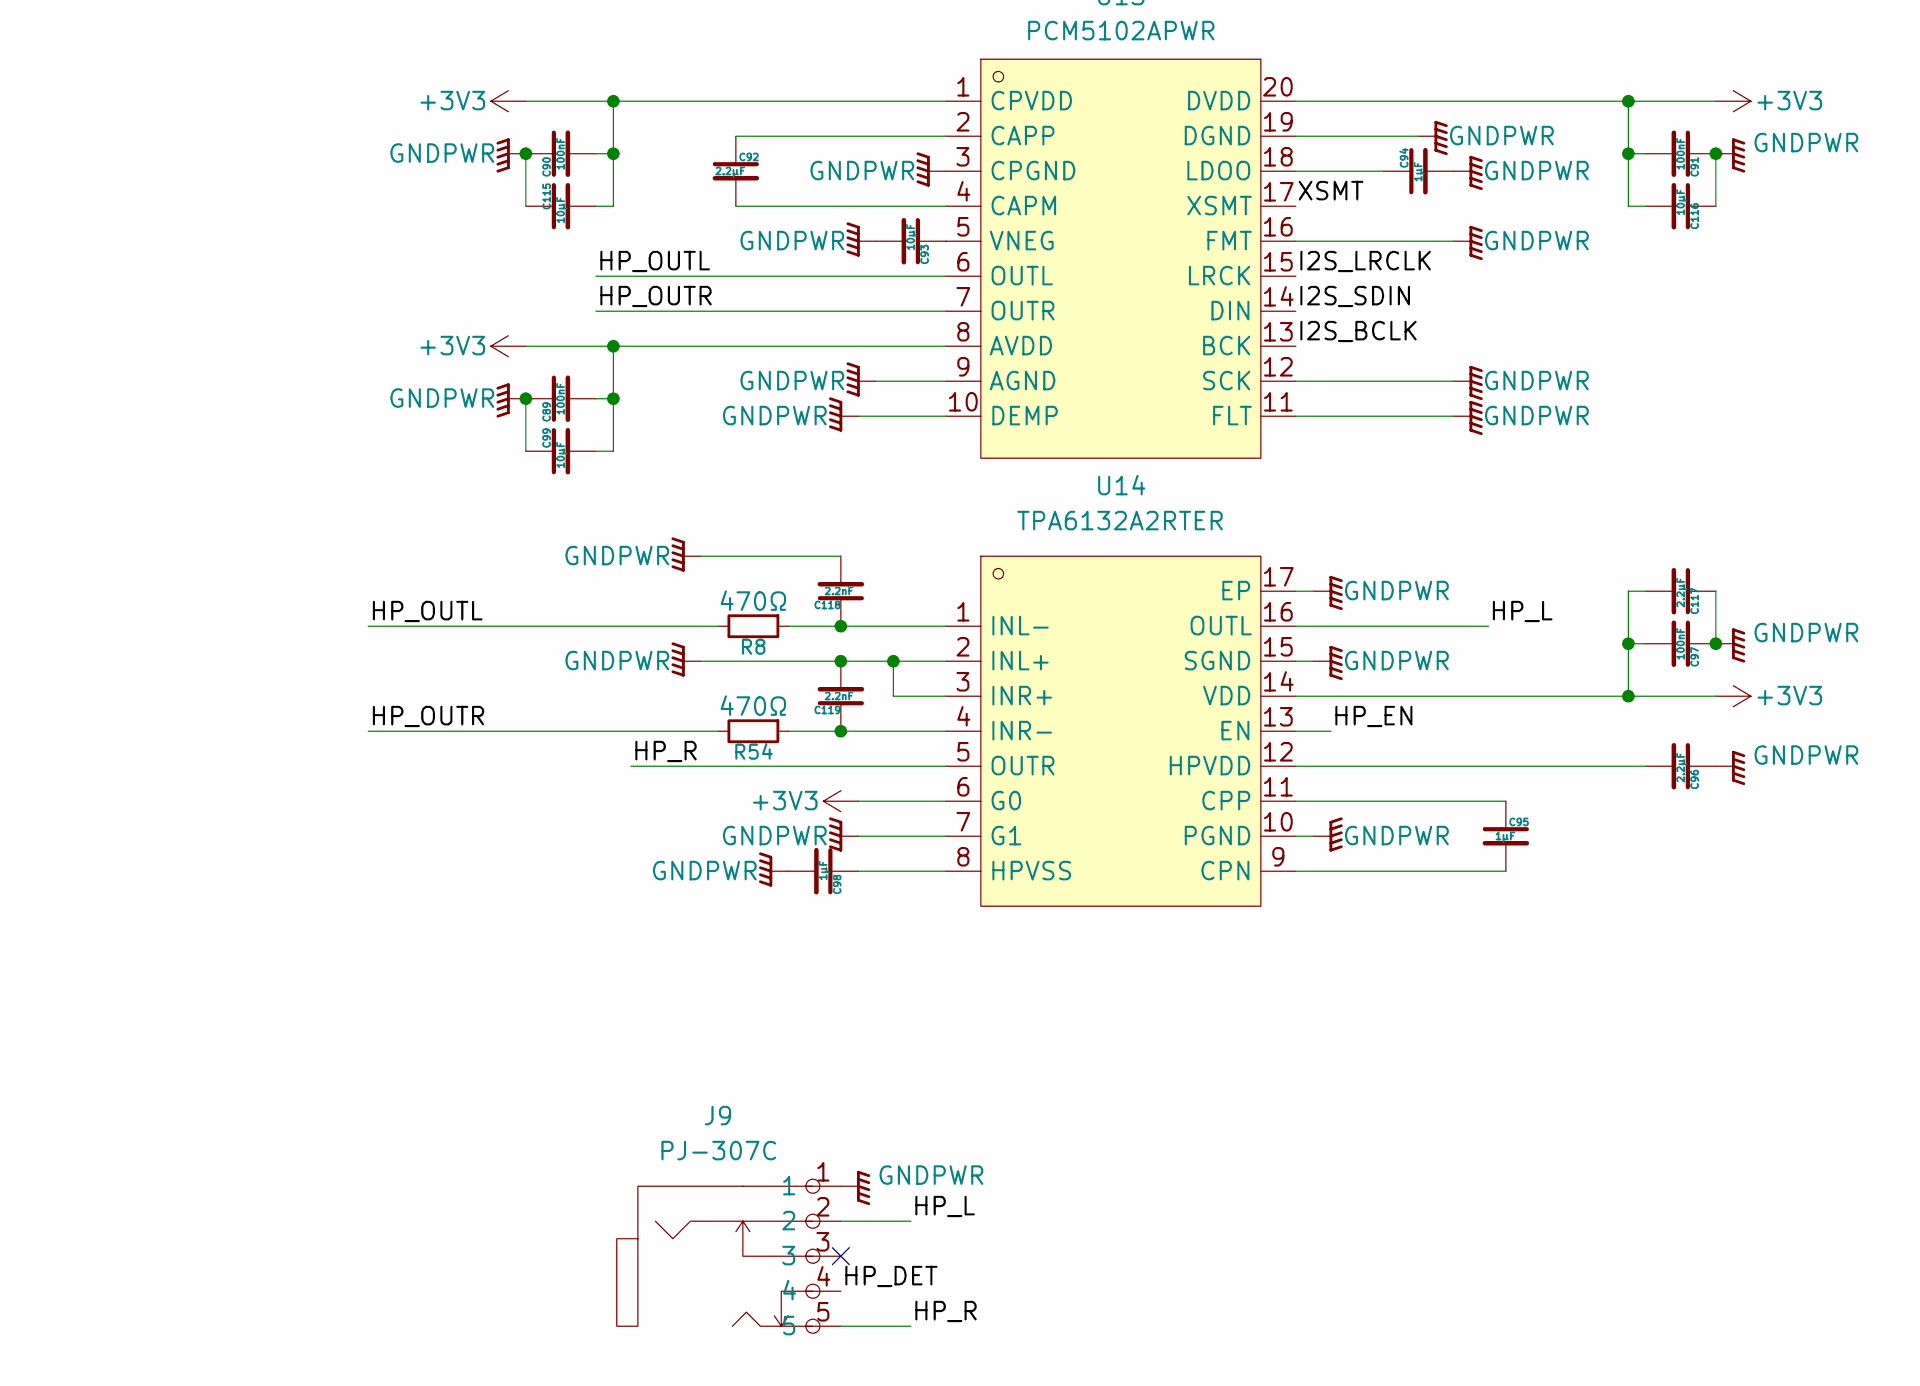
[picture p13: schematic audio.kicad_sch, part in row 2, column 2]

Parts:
B_SW2: BOOTSEL_SW; KEY-SMD_4P-L4.2-W3.2-P2.20-LS4.6; LCSC Part C115360
C70, C73: 10μF; C_0603_1608Metric
C71, C72, C76, C77, C78, C80, C81, C82, C83, C84, C85, C86, C87, C88, C89, C90, C91, C97: 100nF; C_0402_1005Metric
C74, C75: 15pF; C_0402_1005Metric
C79, C94, C95, C98: 1μF; C_0402_1005Metric
C92, C96, C117: 2.2μF; C_0402_1005Metric
C93, C99, C115, C116: 10μF; C_0402_1005Metric
C118, C119: 2.2nF; C_0402_1005Metric
J2: SPK_R; CONN-TH_S2B-PH-K-S-LF-SN
J3: SPK_L; CONN-TH_S2B-PH-K-S-LF-SN
J9: PJ-307C; AUDIO-TH_PJ307C; LCSC Part C16684
R8, R54: 470Ω; R_0402_1005Metric
R35: 220kΩ; R_0603_1608Metric
R36, R39: 10kΩ; R_0402_1005Metric
R37: 1kΩ; R_0402_1005Metric
R38: 100Ω; R_0402_1005Metric
R40, R41: 27Ω; R_0603_1608Metric
R63: 100kΩ; R_0402_1005Metric
RP2040#2: W25Q32JVSSIQ; SOIC-8_L5.3-W5.3-P1.27-LS8.0-BL; LCSC Part C82344
U9: MAX98357AEWL+T_L; WLP-9_L1.4-W1.3-P0.40-R3-C3-BR; LCSC Part C2682619
U11: RP2040#2; LQFN-56_L7.0-W7.0-P0.4-EP; LCSC Part C2040
U13: PCM5102APWR; TSSOP-20_L6.5-W4.4-P0.65-LS6.4-BL; LCSC Part C107671
U14: TPA6132A2RTER; WQFN-16_L3.0-W3.0-P0.50-TL-EP1.6; LCSC Part C69901
U15: MAX98357AEWL+T_R; WLP-9_L1.4-W1.3-P0.40-R3-C3-BR; LCSC Part C2682619
Y2: C70565; CRYSTAL-SMD_4P-L3.2-W2.5-BL

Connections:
5V_SYS: C70.1, C71.1, C72.1, C73.1, U9.A2 (VDD), U15.A2 (VDD); also elsewhere on the board
+3V3: C77.1, C80.2, C81.2, C82.2, C83.2, C84.2, C85.2, C86.2, C87.2, C89.2, C90.2, C91.2, C97.2, C99.2, C115.2, C116.2, C117.2, R36.2, R38.2, R39.2, R63.2, RP2040#2.8 (VCC), U11.1 (IOVDD), U11.10 (IOVDD), U11.22 (IOVDD), U11.33 (IOVDD), U11.42 (IOVDD), U11.44 (VREG_IN), U11.48 (USB_VDD), U11.49 (IOVDD), U13.1 (CPVDD), U13.8 (AVDD), U13.20 (DVDD), U14.6 (G0), U14.14 (VDD); also elsewhere on the board
/audio/HP_DET: J9.4, R63.1, U11.8 (GPIO6)
/audio/HP_EN: U11.7 (GPIO5), U14.13 (EN)
/audio/HP_L: J9.2, U14.16 (OUTL)
/audio/HP_OUTL: R8.2, U13.6 (OUTL)
/audio/HP_OUTR: R54.2, U13.7 (OUTR)
/audio/HP_R: J9.5, U14.5 (OUTR)
/audio/I2S_BCLK: U9.C1 (BCLK), U11.2 (GPIO0), U13.13 (BCK), U15.C1 (BCLK)
/audio/I2S_LRCLK: U9.C3 (LRCLK), U11.3 (GPIO1), U13.15 (LRCK), U15.C3 (LRCLK)
/audio/I2S_SDIN: U9.B1 (DIN), U11.4 (GPIO2), U13.14 (DIN), U15.B1 (DIN)
/audio/QSPI_SCLK: RP2040#2.6 (CLK), U11.52 (QSPI_SCLK)
/audio/QSPI_SD0: RP2040#2.5 (DI（IO0）), U11.53 (QSPI_SD0)
/audio/QSPI_SD1: RP2040#2.2 (DO（IO1）), U11.55 (QSPI_SD1)
/audio/QSPI_SD2: RP2040#2.3 (IO2), U11.54 (QSPI_SD2)
/audio/QSPI_SD3: RP2040#2.7 (IO3), U11.51 (QSPI_SD3)
/audio/QSPI_SS: B_SW2.2, R37.1, R39.1, RP2040#2.1 (~CS)
/audio/SD_MODE: R35.2, U9.1 (~SD_MODE), U11.5 (GPIO3)
/audio/SPK_L+: J3.1, U9.A3 (OUTP); also elsewhere on the board
/audio/SPK_L-: J3.2, U9.B3 (OUTN); also elsewhere on the board
/audio/SPK_R+: J2.1, U15.A3 (OUTP); also elsewhere on the board
/audio/SPK_R-: J2.2, U15.B3 (OUTN); also elsewhere on the board
/audio/XSMT: U11.6 (GPIO4), U13.17 (XSMT)
GND: B_SW2.4, C70.2, C71.2, C72.2, C73.2, C74.2, C75.2, C76.1, C77.2, C78.1, C79.1, C80.1, C81.1, C82.1, C83.1, C84.1, C85.1, C86.1, C87.1, C88.1, C89.1, C90.1, C91.1, C93.2, C94.2, C96.1, C97.1, C98.2, C99.1, C115.1, C116.1, C117.1, C118.2, C119.2, J9.1, RP2040#2.4 (GND), U9.C2 (GND), U11.19 (TESTEN), U11.57 (GND), U13.3 (CPGND), U13.9 (AGND), U13.10 (DEMP), U13.11 (FLT), U13.12 (SCK), U13.16 (FMT), U13.19 (DGND), U14.2 (INL+), U14.3 (INR+), U14.7 (G1), U14.10 (PGND), U14.15 (SGND), U14.17 (EP), U15.C2 (GND), Y2.2, Y2.4; also elsewhere on the board
unnamed: C88.2, R38.1, U11.43 (ADC_AVDD)
unnamed: R37.2, U11.56 (QSPI_SS)
unnamed: R36.1, U11.26 (RUN)
unnamed: R41.2, U11.46 (USB_DM)
unnamed: R40.2, U11.47 (USB_DP)
unnamed: C76.2, C78.2, C79.2, U11.23 (DVDD), U11.45 (VREG_VOUT), U11.50 (DVDD)
unnamed: C74.1, U11.20 (XIN), Y2.1
unnamed: C75.1, U11.21 (XOUT), Y2.3
unnamed: C92.2, U13.4 (CAPM)
unnamed: C92.1, U13.2 (CAPP)
unnamed: C94.1, U13.18 (LDOO)
unnamed: C93.1, U13.5 (VNEG)
unnamed: C95.2, U14.9 (CPN)
unnamed: C95.1, U14.11 (CPP)
unnamed: C96.2, U14.12 (HPVDD)
unnamed: C98.1, U14.8 (HPVSS)
unnamed: C118.1, R8.1, U14.1 (INL-)
unnamed: C119.1, R54.1, U14.4 (INR-)
unnamed: R35.1, U15.1 (~SD_MODE)
USB2_RP_DM2: R41.1; also elsewhere on the board
USB2_RP_DP2: R40.1; also elsewhere on the board

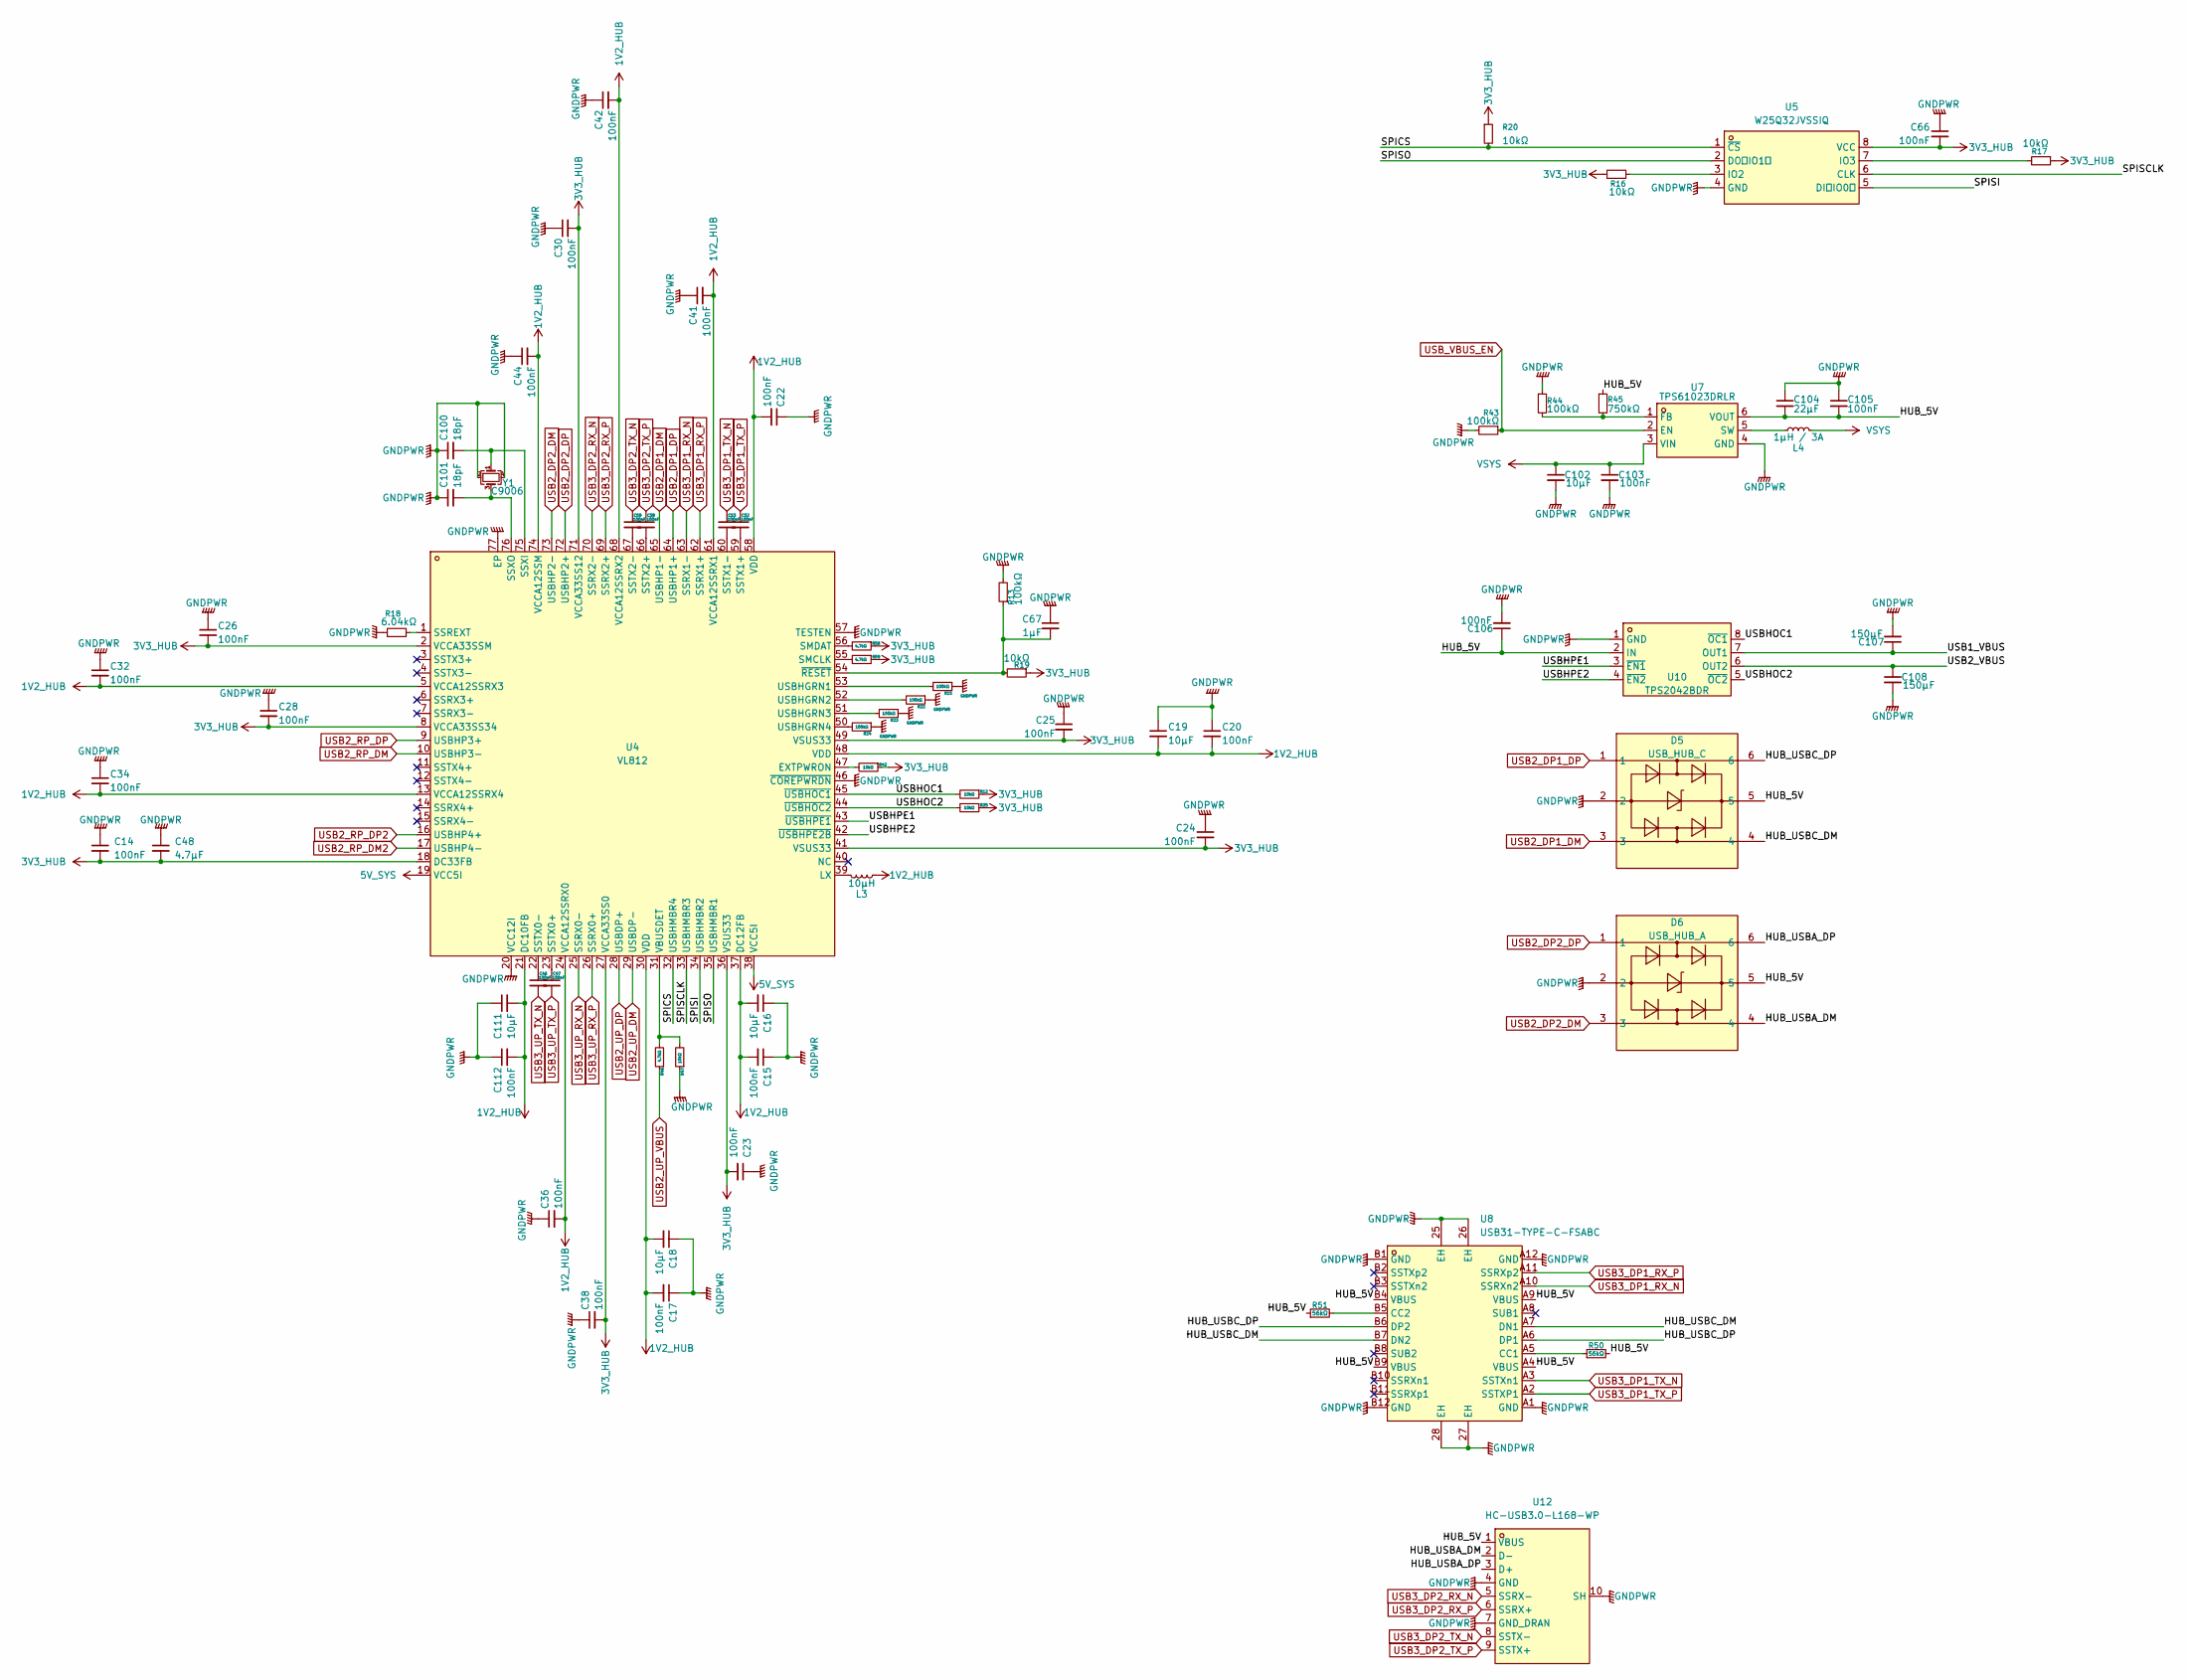
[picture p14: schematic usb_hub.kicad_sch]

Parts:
C14, C15, C17, C20, C22, C23, C24, C25, C26, C28, C30, C32, C34, C36, C38, C41, C42, C44, C46, C47, C52, C53, C58, C59, C66, C103, C105, C106, C112: 100nF; C_0402_1005Metric
C16, C18, C19, C111: 10μF; C_0402_1005Metric
C48: 4.7μF; C_0402_1005Metric
C67: 1μF; C_0402_1005Metric
C100, C101: 18pF; C_0402_1005Metric
C102: 10μF; C_0603_1608Metric
C104: 22μF; C_0603_1608Metric
C107, C108: 150μF; CP_EIA-3528-21_Kemet-B_HandSolder
D5: USB_HUB_C; SOT-23-6_L2.9-W1.6-P0.95-LS2.8-BL; LCSC Part C7519
D6: USB_HUB_A; SOT-23-6_L2.9-W1.6-P0.95-LS2.8-BL; LCSC Part C7519
L3: 10μH; IND-SMD_L4.7-W4.2
L4: 1µH / 3A; IND-SMD_L3.2-W2.5_CKST322512-2.2UH
R12, R16, R17, R19, R20, R25, R42, R47: 10kΩ; R_0402_1005Metric
R13, R15, R22, R23, R24, R43, R44: 100kΩ; R_0402_1005Metric
R18: 6.04kΩ; R_0603_1608Metric
R45: 750kΩ; R_0603_1608Metric
R46, R58, R59: 4.7kΩ; R_0402_1005Metric
R50, R51: 56kΩ; R_0603_1608Metric
U4: VL812; QFN-76_L9.0-W9.0-P0.40-BL-EP; LCSC Part C69417
U5: W25Q32JVSSIQ; SOIC-8_L5.3-W5.3-P1.27-LS8.0-BL; LCSC Part C82344
U7: TPS61023DRLR; SOT-563_L1.6-W1.2-P0.50-LS1.6-BR; LCSC Part C919459
U8: USB31-TYPE-C-FSABC; USB-C-SMD_USB31-TYPE-C-FSABC; LCSC Part C2880583
U10: TPS2042BDR; SOIC-8_L4.9-W3.9-P1.27-LS6.0-BL; LCSC Part C138720
U12: HC-USB3.0-L168-WP; USB-TH_USB3.0-A; LCSC Part C7501850
Y1: C9006; CRYSTAL-SMD_4P-L3.2-W2.5-BL

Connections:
1V2_HUB: C15.2, C16.2, C17.2, C18.2, C19.2, C20.2, C22.2, C32.2, C34.2, C36.2, C41.2, C42.2, C44.2, C111.2, C112.2, L3.1, U4.5 (VCCA12SSRX3), U4.13 (VCCA12SSRX4), U4.21 (DC10FB), U4.24 (VCCA12SSRX0), U4.30 (VDD), U4.37 (DC12FB), U4.48 (VDD), U4.58 (VDD), U4.61 (VCCA12SSRX1), U4.68 (VCCA12SSRX2), U4.74 (VCCA12SSM)
3V3_HUB: C14.2, C23.2, C24.2, C25.2, C26.2, C28.2, C30.2, C38.2, C48.2, C66.2, R12.1, R16.1, R17.1, R19.1, R20.1, R25.1, R42.1, R58.1, R59.1, U4.2 (VCCA33SSM), U4.8 (VCCA33SS34), U4.18 (DC33FB), U4.27 (VCCA33SS0), U4.36 (VSUS33), U4.41 (VSUS33), U4.49 (VSUS33), U4.71 (VCCA33SS12), U5.8 (VCC)
5V_SYS: U4.19 (VCC5I), U4.38 (VCC5I); also elsewhere on the board
/usb_hub/HUB_5V: C104.2, C105.2, C106.1, D5.5, D6.5, R45.1, R50.2, R51.1, U7.6 (VOUT), U8.A4 (VBUS), U8.A9 (VBUS), U8.B4 (VBUS), U8.B9 (VBUS), U10.2 (IN), U12.1 (VBUS)
/usb_hub/HUB_USBA_DM: D6.4, U12.2 (D-)
/usb_hub/HUB_USBA_DP: D6.6, U12.3 (D+)
/usb_hub/HUB_USBC_DM: D5.4, U8.A7 (DN1), U8.B7 (DN2)
/usb_hub/HUB_USBC_DP: D5.6, U8.A6 (DP1), U8.B6 (DP2)
/usb_hub/SPICS: R20.2, U4.32 (USBHMBR4), U5.1 (~CS)
/usb_hub/SPISCLK: U4.33 (USBHMBR3), U5.6 (CLK)
/usb_hub/SPISI: U4.34 (USBHMBR2), U5.5 (DI（IO0）)
/usb_hub/SPISO: U4.35 (USBHMBR1), U5.2 (DO（IO1）)
/usb_hub/USB1_VBUS: C107.1, U10.7 (OUT1)
/usb_hub/USB2_VBUS: C108.1, U10.6 (OUT2)
/usb_hub/USBHOC1: R12.2, U4.45 (~USBHOC1), U10.8 (~OC1)
/usb_hub/USBHOC2: R25.2, U4.44 (~USBHOC2), U10.5 (~OC2)
/usb_hub/USBHPE1: U4.43 (~USBHPE1), U10.3 (~EN1)
/usb_hub/USBHPE2: U4.42 (~USBHPE2B), U10.4 (~EN2)
GND: C14.1, C15.1, C16.1, C17.1, C18.1, C19.1, C20.1, C22.1, C23.1, C24.1, C25.1, C26.1, C28.1, C30.1, C32.1, C34.1, C36.1, C38.1, C41.1, C42.1, C44.1, C48.1, C66.1, C67.1, C100.1, C101.1, C102.2, C103.2, C104.1, C105.1, C106.2, C107.2, C108.2, C111.1, C112.1, D5.2, D6.2, R13.2, R15.1, R18.1, R22.1, R23.1, R24.1, R43.2, R44.1, R47.1, U4.20 (VCC12I), U4.46 (~COREPWRDN), U4.57 (TESTEN), U4.77 (EP), U5.4 (GND), U7.4 (GND), U8.25 (EH), U8.26 (EH), U8.27 (EH), U8.28 (EH), U8.A1 (GND), U8.A12 (GND), U8.B1 (GND), U8.B12 (GND), U10.1 (GND), U12.4 (GND), U12.7 (GND_DRAN), U12.10 (SH), Y1.2, Y1.4; also elsewhere on the board
unnamed: R42.2, U4.47 (EXTPWRON)
unnamed: L3.2, U4.39 (LX)
unnamed: R59.2, U4.55 (SMCLK)
unnamed: R58.2, U4.56 (SMDAT)
unnamed: R18.2, U4.1 (SSREXT)
unnamed: C47.1, U4.23 (SSTX0+)
unnamed: C46.1, U4.22 (SSTX0-)
unnamed: C52.2, U4.59 (SSTX1+)
unnamed: C53.2, U4.60 (SSTX1-)
unnamed: C58.2, U4.66 (SSTX2+)
unnamed: C59.2, U4.67 (SSTX2-)
unnamed: C100.2, U4.75 (SSXI), Y1.1
unnamed: C101.2, U4.76 (SSXO), Y1.3
unnamed: R15.2, U4.53 (USBHGRN1)
unnamed: R22.2, U4.52 (USBHGRN2)
unnamed: R23.2, U4.51 (USBHGRN3)
unnamed: R24.2, U4.50 (USBHGRN4)
unnamed: R46.2, R47.2, U4.31 (VBUSDET)
unnamed: C67.2, R13.1, R19.2, U4.54 (~RESET)
unnamed: R16.2, U5.3 (IO2)
unnamed: R17.2, U5.7 (IO3)
unnamed: R44.2, R45.2, U7.1 (FB)
unnamed: L4.1, U7.5 (SW)
unnamed: R50.1, U8.A5 (CC1)
unnamed: R51.2, U8.B5 (CC2)
USB2_DP1_DM: D5.3, U4.65 (USBHP1-)
USB2_DP1_DP: D5.1, U4.64 (USBHP1+)
USB2_DP2_DM: D6.3, U4.73 (USBHP2-)
USB2_DP2_DP: D6.1, U4.72 (USBHP2+)
USB2_RP_DM: U4.10 (USBHP3-); also elsewhere on the board
USB2_RP_DM2: U4.17 (USBHP4-); also elsewhere on the board
USB2_RP_DP: U4.9 (USBHP3+); also elsewhere on the board
USB2_RP_DP2: U4.16 (USBHP4+); also elsewhere on the board
USB2_UP_DM: U4.29 (USBDP-); also elsewhere on the board
USB2_UP_DP: U4.28 (USBDP+); also elsewhere on the board
USB2_UP_VBUS: R46.1; also elsewhere on the board
USB3_DP1_RX_N: U4.63 (SSRX1-), U8.A10 (SSRXn2)
USB3_DP1_RX_P: U4.62 (SSRX1+), U8.A11 (SSRXp2)
USB3_DP1_TX_N: C53.1, U8.A3 (SSTXn1)
USB3_DP1_TX_P: C52.1, U8.A2 (SSTXP1)
USB3_DP2_RX_N: U4.70 (SSRX2-), U12.5 (SSRX-)
USB3_DP2_RX_P: U4.69 (SSRX2+), U12.6 (SSRX+)
USB3_DP2_TX_N: C59.1, U12.8 (SSTX-)
USB3_DP2_TX_P: C58.1, U12.9 (SSTX+)
USB3_UP_RX_N: U4.25 (SSRX0-); also elsewhere on the board
USB3_UP_RX_P: U4.26 (SSRX0+); also elsewhere on the board
USB3_UP_TX_N: C46.2; also elsewhere on the board
USB3_UP_TX_P: C47.2; also elsewhere on the board
USB_VBUS_EN: R43.1, U7.2 (EN); also elsewhere on the board
VSYS: C102.1, C103.1, L4.2, U7.3 (VIN); also elsewhere on the board

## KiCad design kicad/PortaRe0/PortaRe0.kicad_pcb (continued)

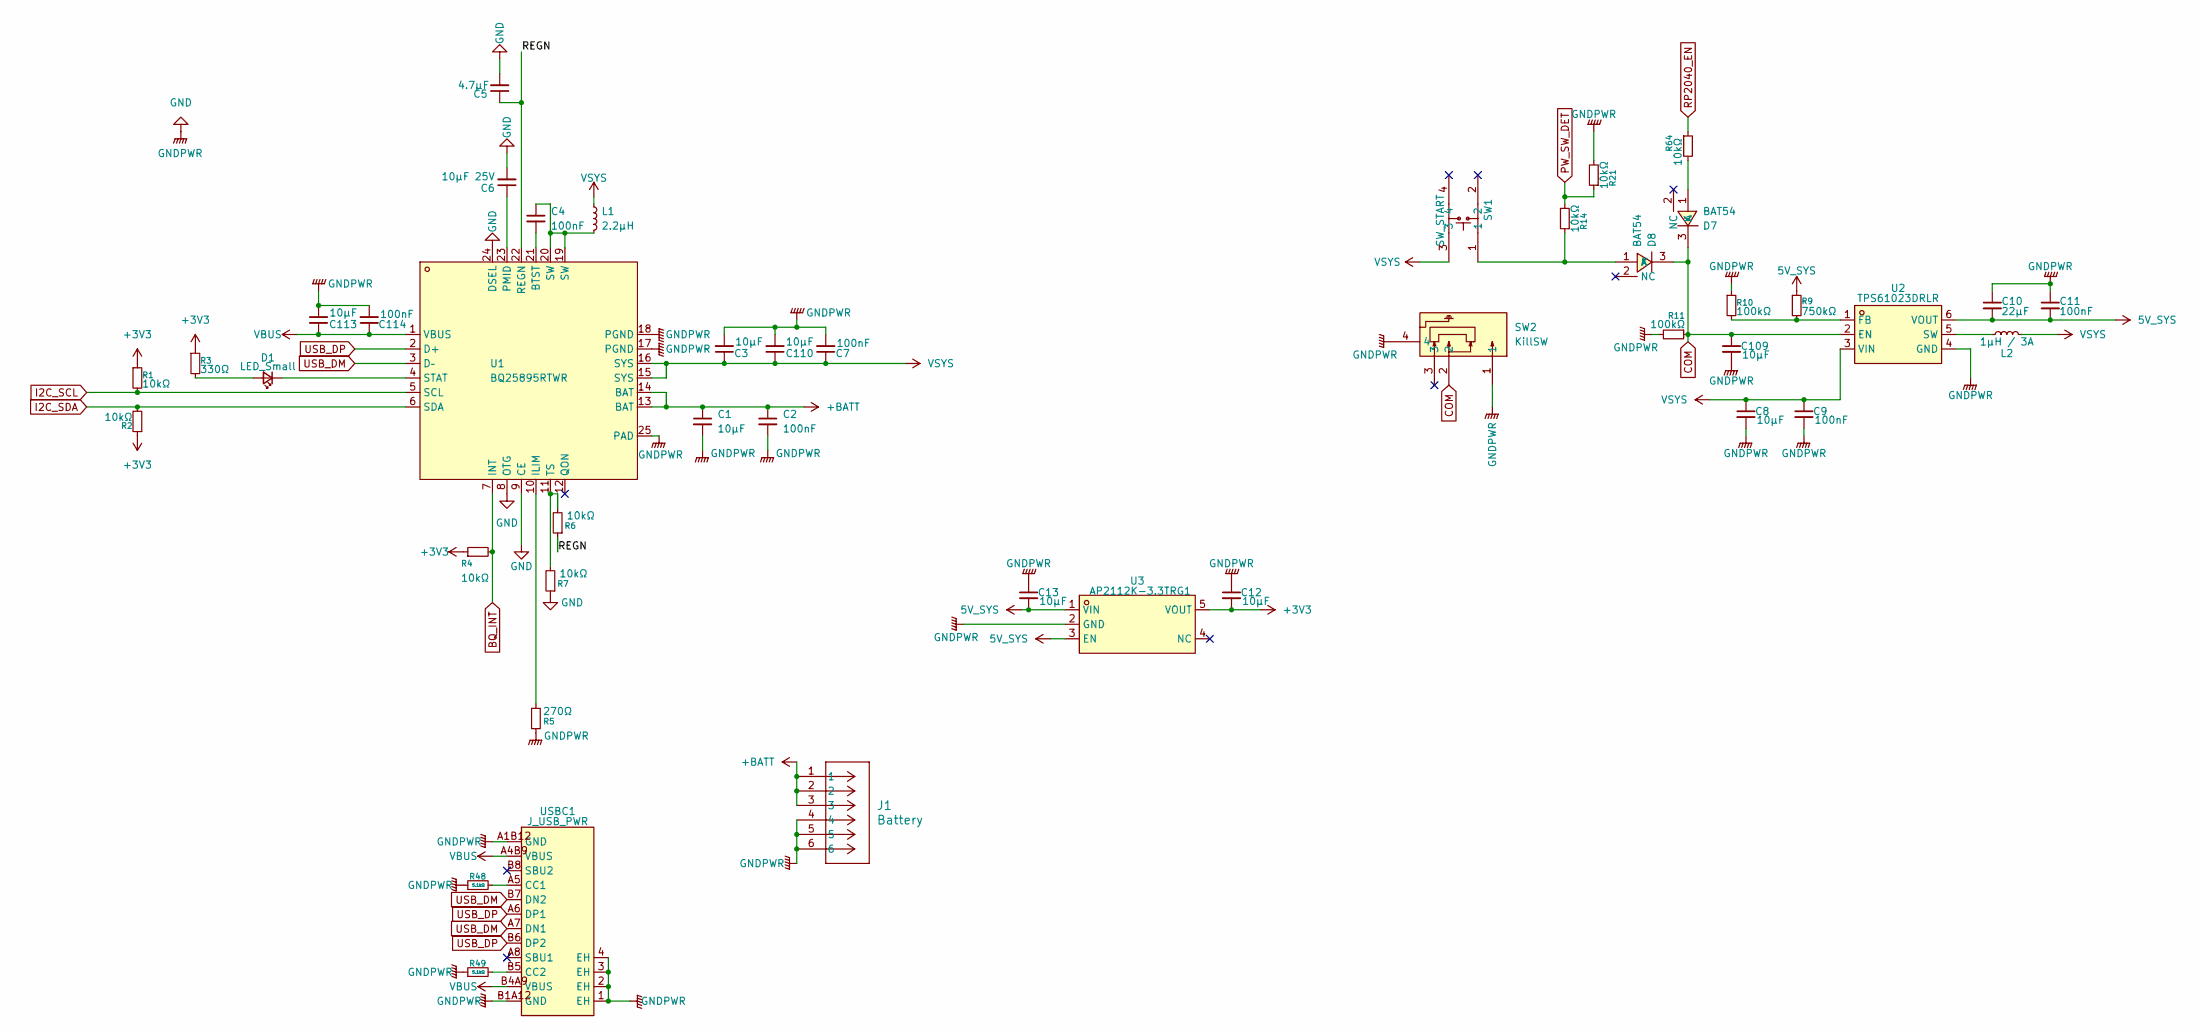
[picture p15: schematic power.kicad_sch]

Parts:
C1, C3, C8, C13, C109, C110, C113: 10μF; C_0603_1608Metric
C2, C4, C7, C9, C11, C114: 100nF; C_0402_1005Metric
C5: 4.7μF; C_0402_1005Metric
C6: 10μF 25V; C_0603_1608Metric
C10: 22μF; C_0603_1608Metric
C12: 10μF; C_0402_1005Metric
D1: LED_Small; LED_0603_1608Metric
D7, D8: BAT54; SOT-23-3_L2.9-W1.4-P1.90-LS2.6-BR; LCSC Part C466635
J1: Battery; CONN_BM06B-ACHFKS-GACN-ETF_JST
L1: 2.2μH; IND-SMD_L4.4-W4.2
L2: 1µH / 3A; IND-SMD_L3.2-W2.5_CKST322512-2.2UH
R1, R2, R4, R6, R7, R14, R21, R64: 10kΩ; R_0402_1005Metric
R3: 330Ω; R_0402_1005Metric
R5: 270Ω; R_0603_1608Metric
R9: 750kΩ; R_0603_1608Metric
R10, R11: 100kΩ; R_0402_1005Metric
R48, R49: 5.1kΩ; R_0402_1005Metric
SW1: SW_START; KEY-SMD_4P-SKSCLXX010; LCSC Part C115361
SW2: KillSW; SW-TH_MSK12C02; LCSC Part C431540
U1: BQ25895RTWR; QFN-24_L4.0-W4.0-P0.50-TL-EP2.7; LCSC Part C80200
U2: TPS61023DRLR; SOT-563_L1.6-W1.2-P0.50-LS1.6-BR; LCSC Part C919459
U3: AP2112K-3.3TRG1; SOT-25-5_L2.9-W1.6-P0.95-LS2.8-BL; LCSC Part C51118
USBC1: J_USB_PWR; USB-C_SMD-TYPE-C-31-M-12_1; LCSC Part C165948

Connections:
5V_SYS: C10.2, C11.2, C13.2, R9.1, U2.6 (VOUT), U3.1 (VIN), U3.3 (EN); also elsewhere on the board
+3V3: C12.2, R1.1, R2.1, R3.1, R4.1, U3.5 (VOUT); also elsewhere on the board
+BATT: C1.1, C2.1, J1.1, J1.2, J1.3, U1.13 (BAT), U1.14 (BAT)
/power/REGN: C5.1, R6.1, U1.22 (REGN)
BQ_INT: R4.2, U1.7 (INT); also elsewhere on the board
COM: C109.1, D7.3 (K), D8.3 (K), R11.1, SW2.2, U2.2 (EN)
GND: C1.2, C2.2, C3.2, C5.2, C6.2, C7.2, C8.2, C9.2, C10.1, C11.1, C12.1, C13.1, C109.2, C110.2, C113.2, C114.2, J1.4, J1.5, J1.6, R5.2, R7.1, R10.1, R11.2, R21.2, R48.1, R49.1, SW2.1, SW2.4, U1.8 (OTG), U1.9 (CE), U1.17 (PGND), U1.18 (PGND), U1.24 (DSEL), U1.25 (PAD), U2.4 (GND), U3.2 (GND), USBC1.1 (EH), USBC1.2 (EH), USBC1.3 (EH), USBC1.4 (EH), USBC1.A1B12 (GND), USBC1.B1A12 (GND); also elsewhere on the board
I2C_SCL: R1.2, U1.5 (SCL); also elsewhere on the board
I2C_SDA: R2.2, U1.6 (SDA); also elsewhere on the board
unnamed: C4.1, L1.2, U1.19 (SW), U1.20 (SW)
unnamed: D1.2 (A), R3.2
unnamed: D1.1 (K), U1.4 (STAT)
unnamed: D7.1 (A), R64.2
unnamed: D8.1 (A), R14.1, SW1.1
unnamed: C4.2, U1.21 (BTST)
unnamed: R5.1, U1.10 (ILIM)
unnamed: C6.1, U1.23 (PMID)
unnamed: R6.2, R7.2, U1.11 (TS)
unnamed: R9.2, R10.2, U2.1 (FB)
unnamed: L2.1, U2.5 (SW)
unnamed: R48.2, USBC1.A5 (CC1)
unnamed: R49.2, USBC1.B5 (CC2)
PW_SW_DET: R14.2, R21.1; also elsewhere on the board
RP2040_EN: R64.1; also elsewhere on the board
USB_DM: U1.3 (D–), USBC1.A7 (DN1), USBC1.B7 (DN2)
USB_DP: U1.2 (D+), USBC1.A6 (DP1), USBC1.B6 (DP2)
VBUS: C113.1, C114.1, U1.1 (VBUS), USBC1.A4B9 (VBUS), USBC1.B4A9 (VBUS)
VSYS: C3.1, C7.1, C8.1, C9.1, C110.1, L1.1, L2.2, SW1.3, U1.15 (SYS), U1.16 (SYS), U2.3 (VIN); also elsewhere on the board

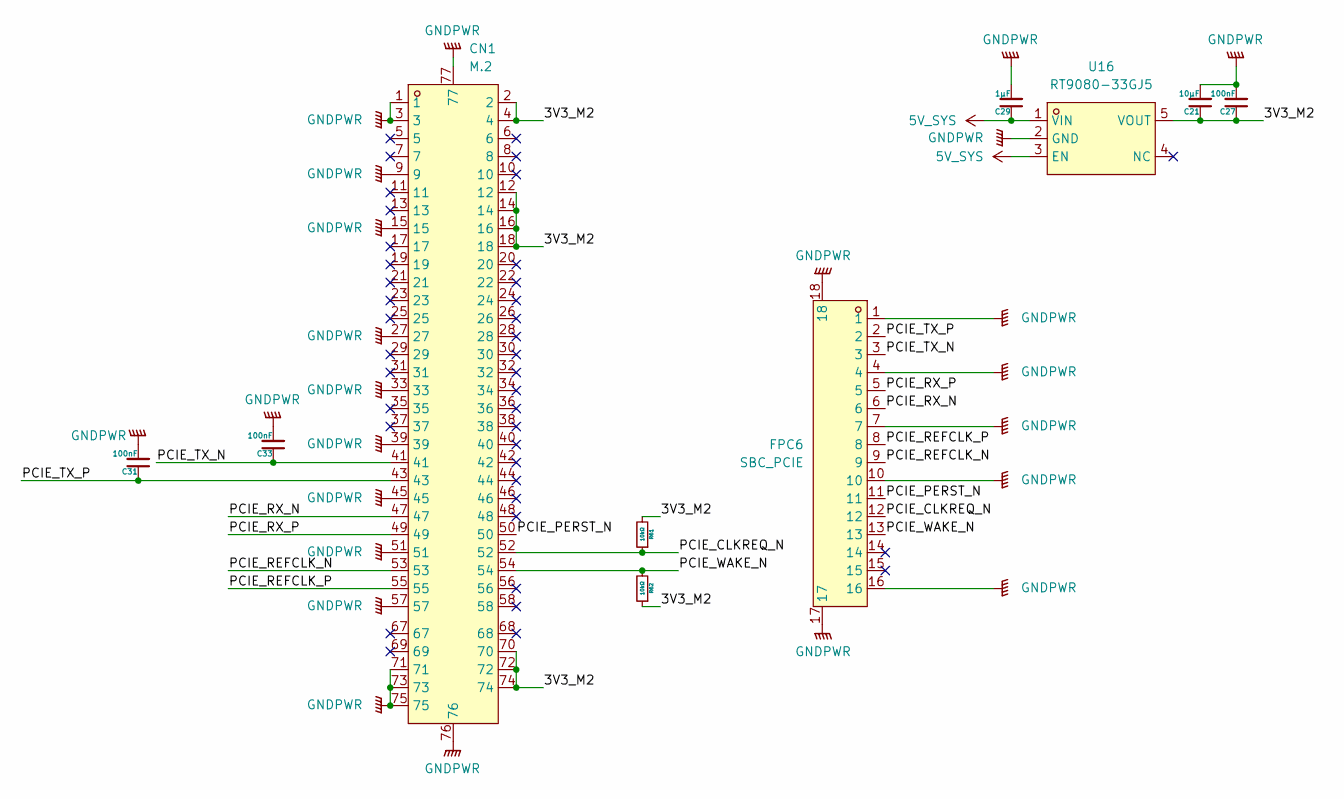
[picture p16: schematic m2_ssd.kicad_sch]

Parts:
C21: 10μF; C_0402_1005Metric
C27, C31, C33: 100nF; C_0402_1005Metric
C29: 1μF; C_0402_1005Metric
CN1: M.2; CONN-SMD_67P-P0.50-V_NXSM0-S67XX-XX40; LCSC Part C367029
FPC6: SBC_PCIE; FPC-SMD_16P-P0.50_FPC-05F-16PH20; LCSC Part C2856801
R61, R62: 10kΩ; R_0402_1005Metric
U16: RT9080-33GJ5; TSOT-23-5_L2.9-W1.6-P0.95-LS2.8-BL; LCSC Part C841192

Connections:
5V_SYS: C29.1, U16.1 (VIN), U16.3 (EN); also elsewhere on the board
/m2_ssd/3V3_M2: C21.1, C27.1, CN1.2, CN1.4, CN1.12, CN1.14, CN1.16, CN1.18, CN1.70, CN1.72, CN1.74, R61.2, R62.1, U16.5 (VOUT); also elsewhere on the board
/m2_ssd/PCIE_CLKREQ_N: CN1.52, FPC6.12, R61.1; also elsewhere on the board
/m2_ssd/PCIE_TX_N: C33.1, CN1.41, FPC6.3; also elsewhere on the board
/m2_ssd/PCIE_TX_P: C31.1, CN1.43, FPC6.2; also elsewhere on the board
/m2_ssd/PCIE_WAKE_N: CN1.54, FPC6.13, R62.2; also elsewhere on the board
GND: C21.2, C27.2, C29.2, C31.2, C33.2, CN1.1, CN1.3, CN1.9, CN1.15, CN1.27, CN1.33, CN1.39, CN1.45, CN1.51, CN1.57, CN1.71, CN1.73, CN1.75, CN1.76, CN1.77, FPC6.1, FPC6.4, FPC6.7, FPC6.10, FPC6.16, FPC6.17, FPC6.18, U16.2 (GND); also elsewhere on the board
unnamed: CN1.47, FPC6.6
unnamed: CN1.49, FPC6.5
unnamed: CN1.50, FPC6.11
unnamed: CN1.53, FPC6.9
unnamed: CN1.55, FPC6.8

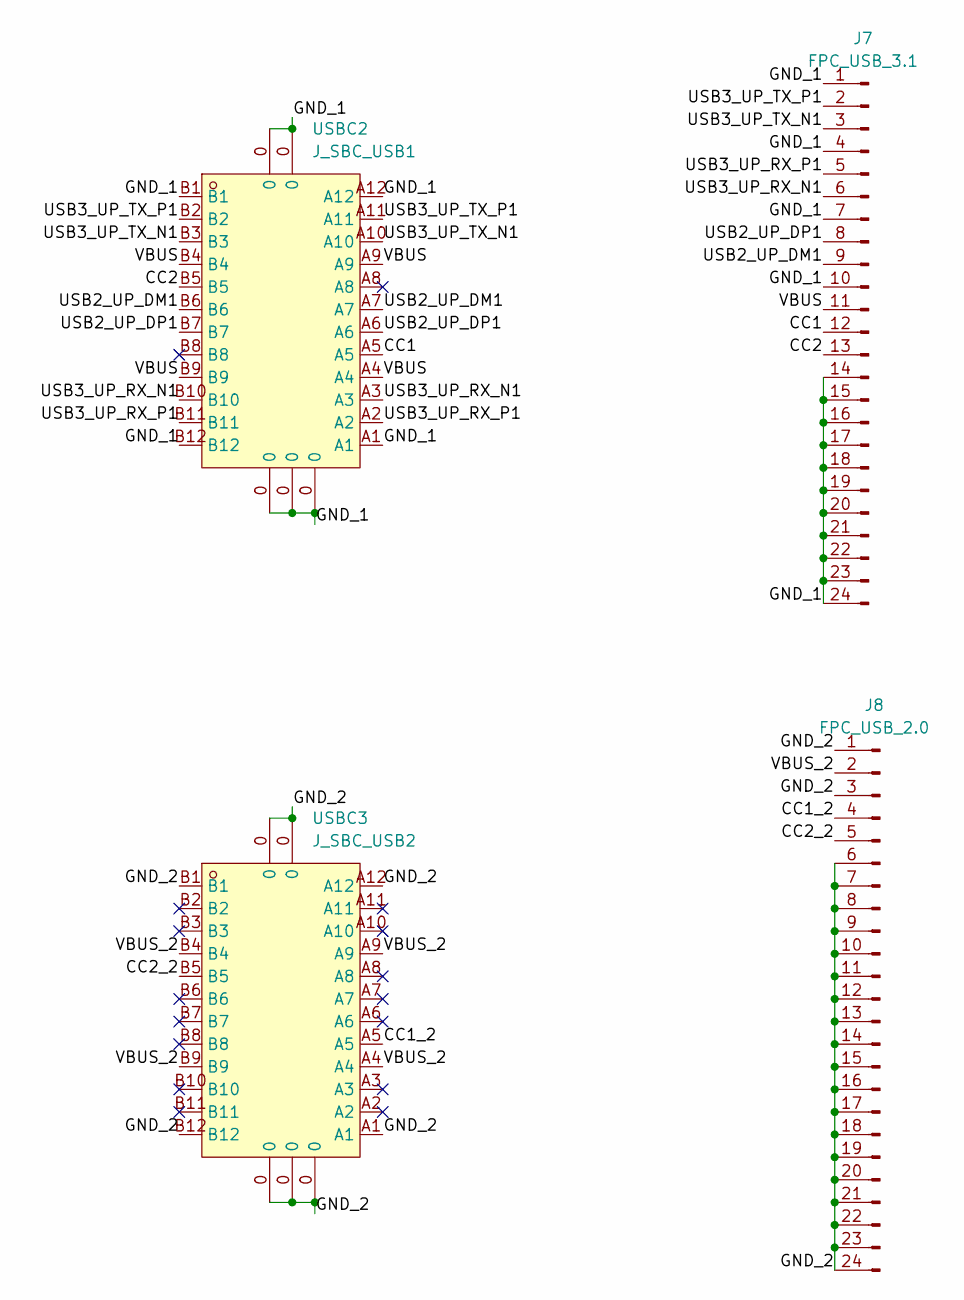
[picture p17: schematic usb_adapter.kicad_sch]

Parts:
J7: FPC_USB_3.1
J8: FPC_USB_2.0
USBC2: J_SBC_USB1; USB-C-SMD_TYPE-C-USB-3; LCSC Part C168690
USBC3: J_SBC_USB2; USB-C-SMD_TYPE-C-USB-3; LCSC Part C168690

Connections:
unnamed: J7.1, J7.4, J7.7, J7.10, J7.14, J7.15, J7.16, J7.17, J7.18, J7.19, J7.20, J7.21, J7.22, J7.23, J7.24, USBC2.0, USBC2.A1, USBC2.A12, USBC2.B1, USBC2.B12
unnamed: J7.2, USBC2.A11, USBC2.B2
unnamed: J7.3, USBC2.A10, USBC2.B3
unnamed: J7.5, USBC2.A2, USBC2.B11
unnamed: J7.6, USBC2.A3, USBC2.B10
unnamed: J7.8, USBC2.A6, USBC2.B7
unnamed: J7.9, USBC2.A7, USBC2.B6
unnamed: J7.11, USBC2.A4, USBC2.A9, USBC2.B4, USBC2.B9
unnamed: J7.12, USBC2.A5
unnamed: J7.13, USBC2.B5
unnamed: J8.1, J8.3, J8.6, J8.7, J8.8, J8.9, J8.10, J8.11, J8.12, J8.13, J8.14, J8.15, J8.16, J8.17, J8.18, J8.19, J8.20, J8.21, J8.22, J8.23, J8.24, USBC3.0, USBC3.A1, USBC3.A12, USBC3.B1, USBC3.B12
unnamed: J8.2, USBC3.A4, USBC3.A9, USBC3.B4, USBC3.B9
unnamed: J8.4, USBC3.A5
unnamed: J8.5, USBC3.B5

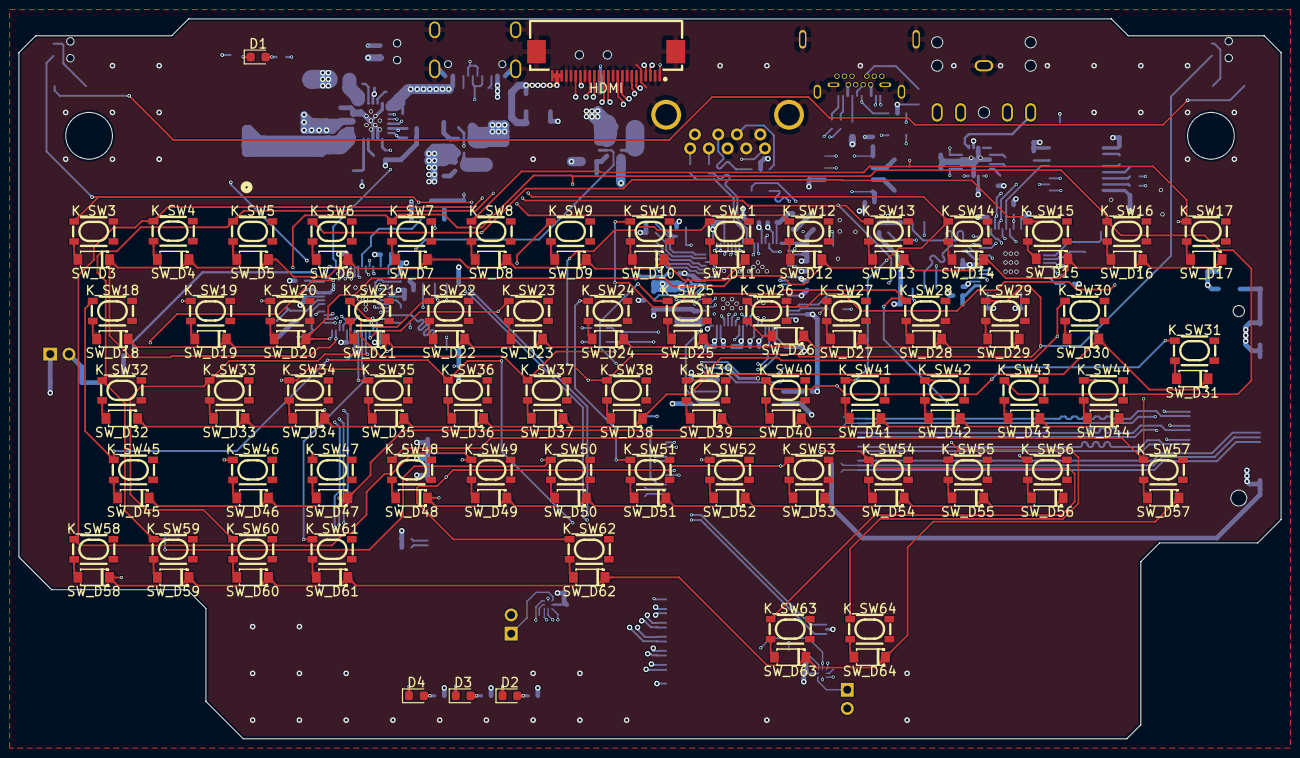
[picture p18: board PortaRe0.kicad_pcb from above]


Board: 6 copper layers, 135.0 x 77.0 mm, 357 parts (228 on the bottom side), 266 nets.

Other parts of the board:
Fan: Fan; CONN-TH_S2B-PH-K-S-LF-SN
HDMI: J_HDMI_CTRL; FPC-SMD_24P-P0.50_FPC-05F-24PH20
HDMI#2: J_SBC_HDMI; FPC-SMD_24P-P0.50_FPC-05F-24PH20
LSPK: SPK_L; CONN-TH_S2B-PH-K-S-LF-SN
M.2: M.2; CONN-SMD_67P-P0.50-V_NXSM0-S67XX-XX40
PCIE: SBC_PCIE; FPC-SMD_16P-P0.50_FPC-05F-16PH20
RSPK: SPK_R; CONN-TH_S2B-PH-K-S-LF-SN
Stick: 5034800440; FPC-SMD_5034800400
USB3.0: J_SBC_USB_3.1; FPC-SMD_24P-P0.50_FPC-05F-24PH20
USBPOW: J_SBC_USB_2.0; FPC-SMD_24P-P0.50_FPC-05F-24PH20

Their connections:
5V_SYS: Fan.1, HDMI.18, HDMI.22, HDMI.23, HDMI.24, USBPOW.1, USBPOW.2, USBPOW.3, USBPOW.4, USBPOW.5, USBPOW.6, USBPOW.7, USBPOW.8, USBPOW.9, USBPOW.10; also elsewhere on the board
+3V3: Stick.3; also elsewhere on the board
/Connectors/HDMI_CEC: HDMI.19, HDMI#2.19
/Connectors/HDMI_CLKN: HDMI.13, HDMI#2.13
/Connectors/HDMI_CLKP: HDMI.12, HDMI#2.12
/Connectors/HDMI_D0N: HDMI.10, HDMI#2.10
/Connectors/HDMI_D0P: HDMI.9, HDMI#2.9
/Connectors/HDMI_D1N: HDMI.7, HDMI#2.7
/Connectors/HDMI_D1P: HDMI.6, HDMI#2.6
/Connectors/HDMI_D2N: HDMI.4, HDMI#2.4
/Connectors/HDMI_D2P: HDMI.3, HDMI#2.3
/Connectors/HDMI_HPD: HDMI.1, HDMI#2.1
/Connectors/HDMI_SCL: HDMI.15, HDMI#2.15
/Connectors/HDMI_SDA: HDMI.16, HDMI#2.16
/audio/SPK_L+: LSPK.1; also elsewhere on the board
/audio/SPK_L-: LSPK.2; also elsewhere on the board
/audio/SPK_R+: RSPK.1; also elsewhere on the board
/audio/SPK_R-: RSPK.2; also elsewhere on the board
/m2_ssd/3V3_M2: M.2.2, M.2.4, M.2.12, M.2.14, M.2.16, M.2.18, M.2.70, M.2.72, M.2.74; also elsewhere on the board
/m2_ssd/PCIE_CLKREQ_N: M.2.52, PCIE.12; also elsewhere on the board
/m2_ssd/PCIE_PERST_N: M.2.50, PCIE.11
/m2_ssd/PCIE_REFCLK_N: M.2.53, PCIE.9
/m2_ssd/PCIE_REFCLK_P: M.2.55, PCIE.8
/m2_ssd/PCIE_RX_N: M.2.47, PCIE.6
/m2_ssd/PCIE_RX_P: M.2.49, PCIE.5
/m2_ssd/PCIE_TX_N: M.2.41, PCIE.3; also elsewhere on the board
/m2_ssd/PCIE_TX_P: M.2.43, PCIE.2; also elsewhere on the board
/m2_ssd/PCIE_WAKE_N: M.2.54, PCIE.13; also elsewhere on the board
GND: HDMI.2, HDMI.5, HDMI.8, HDMI.11, HDMI.14, HDMI.17, HDMI.20, HDMI.21, HDMI.25, HDMI.26, HDMI#2.2, HDMI#2.5, HDMI#2.8, HDMI#2.11, HDMI#2.14, HDMI#2.17, HDMI#2.20, HDMI#2.21, HDMI#2.22, HDMI#2.23, HDMI#2.24, HDMI#2.25, HDMI#2.26, M.2.1, M.2.3, M.2.9, M.2.15, M.2.27, M.2.33, M.2.39, M.2.45, M.2.51, M.2.57, M.2.71, M.2.73, M.2.75, M.2.76, M.2.77, PCIE.1, PCIE.4, PCIE.7, PCIE.10, PCIE.16, PCIE.17, PCIE.18, Stick.1, Stick.5, Stick.6, USB3.0.1, USB3.0.4, USB3.0.7, USB3.0.10, USB3.0.14, USB3.0.15, USB3.0.16, USB3.0.17, USB3.0.18, USB3.0.19, USB3.0.20, USB3.0.21, USB3.0.22, USB3.0.23, USB3.0.24, USB3.0.25, USB3.0.26, USBPOW.11, USBPOW.12, USBPOW.13, USBPOW.14, USBPOW.15, USBPOW.16, USBPOW.17, USBPOW.18, USBPOW.19, USBPOW.20, USBPOW.21, USBPOW.22, USBPOW.25, USBPOW.26; also elsewhere on the board
unnamed 109: Fan.2; also elsewhere on the board
unnamed 136: USBPOW.23; also elsewhere on the board
unnamed 137: USBPOW.24; also elsewhere on the board
unnamed 138: USB3.0.12; also elsewhere on the board
unnamed 139: USB3.0.13; also elsewhere on the board
STICK_X: Stick.2; also elsewhere on the board
STICK_Y: Stick.4; also elsewhere on the board
USB2_UP_DM: USB3.0.9; also elsewhere on the board
USB2_UP_DP: USB3.0.8; also elsewhere on the board
USB2_UP_VBUS: USB3.0.11; also elsewhere on the board
USB3_UP_RX_N: USB3.0.6; also elsewhere on the board
USB3_UP_RX_P: USB3.0.5; also elsewhere on the board
USB3_UP_TX_N: USB3.0.3; also elsewhere on the board
USB3_UP_TX_P: USB3.0.2; also elsewhere on the board

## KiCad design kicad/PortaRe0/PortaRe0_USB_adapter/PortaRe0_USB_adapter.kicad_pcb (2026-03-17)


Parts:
J7: FPC_USB_3.1; FPC-24P-0.5mm
J8: FPC_USB_2.0; FPC-24P-0.5mm
USBC2: J_SBC_USB1; USB-C-SMD_TYPE-C-USB-3; LCSC Part C168690
USBC3: J_SBC_USB2; USB-C-SMD_TYPE-C-USB-3; LCSC Part C168690

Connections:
/CC1: J7.12, USBC2.A5
/CC1_2: J8.23, USBC3.A5
/CC2: J7.13, USBC2.B5
/CC2_2: J8.24, USBC3.B5
/GND_1: J7.1, J7.4, J7.7, J7.10, J7.14, J7.15, J7.16, J7.17, J7.18, J7.19, J7.20, J7.21, J7.22, J7.23, J7.24, J8.11, J8.12, J8.13, J8.14, J8.15, J8.16, J8.17, J8.18, J8.19, J8.20, J8.21, J8.22, USBC2.0, USBC2.A1, USBC2.A12, USBC2.B1, USBC2.B12, USBC3.0, USBC3.A1, USBC3.A12, USBC3.B1, USBC3.B12
/USB2_UP_DN: J7.9, USBC2.A7, USBC2.B6
/USB2_UP_DP: J7.8, USBC2.A6, USBC2.B7
/USB3_UP_RX_N1: J7.6, USBC2.A3, USBC2.B10
/USB3_UP_RX_P1: J7.5, USBC2.A2, USBC2.B11
/USB3_UP_TX_N1: J7.3, USBC2.A10, USBC2.B3
/USB3_UP_TX_P1: J7.2, USBC2.A11, USBC2.B2
/VBUS: J7.11, USBC2.A4, USBC2.A9, USBC2.B4, USBC2.B9
/VBUS_2: J8.1, J8.2, J8.3, J8.4, J8.5, J8.6, J8.7, J8.8, J8.9, J8.10, USBC3.A4, USBC3.A9, USBC3.B4, USBC3.B9



Board: 2 copper layers, 105.2 x 39.0 mm, 4 parts (4 on the bottom side), 13 nets.

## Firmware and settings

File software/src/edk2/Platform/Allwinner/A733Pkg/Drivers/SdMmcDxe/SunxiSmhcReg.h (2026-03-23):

/** @file
  Allwinner SMHC (SD/MMC Host Controller) register definitions.

  Compatible with A523/H618/A733 and related Allwinner SoCs.
**/

#ifndef SUNXI_SMHC_REG_H_
#define SUNXI_SMHC_REG_H_

// ---- SMHC hardware base addresses (A523/H618/A733) ----
#define SMHC0_BASE  0x04020000UL  // SD card (card_ctrl=0, 4-bit)
#define SMHC1_BASE  0x04021000UL  // SDIO/WiFi (not used here)
#define SMHC2_BASE  0x04022000UL  // eMMC (card_ctrl=2, 8-bit)

// ---- CCU (Clock Control Unit) ----
#define CCU_BASE              0x02001000UL
#define CCU_SMHC0_CLK_REG     0x0830
#define CCU_SMHC1_CLK_REG     0x0834
#define CCU_SMHC2_CLK_REG     0x0838
#define CCU_SMHC_BGR_REG      0x084C

// CCU_SMHC_CLK_REG bits
#define SMHC_CLK_GATING        (1U << 31)  // Clock gate enable
#define SMHC_CLK_SRC_HOSC      (0U << 24)  // Source: HOSC 24MHz
#define SMHC_CLK_SRC_PLL_P1_2X (1U << 24)  // Source: PLL_PERIPH1 2x
#define SMHC_CLK_N_SHIFT        8           // Factor N (2^N pre-divider)
#define SMHC_CLK_N_MASK        (3U << 8)
#define SMHC_CLK_M_SHIFT        0           // Factor M (M+1 post-divider)
#define SMHC_CLK_M_MASK        (0xF << 0)

// CCU_SMHC_BGR_REG bits
#define SMHC0_CLK_GATING       (1U << 0)
#define SMHC1_CLK_GATING       (1U << 1)
#define SMHC2_CLK_GATING       (1U << 2)
#define SMHC0_RST              (1U << 16)
#define SMHC1_RST              (1U << 17)
#define SMHC2_RST              (1U << 18)

// ---- SMHC Register Offsets ----
#define SMHC_GCTRL    0x000  // Global Control
#define SMHC_CLKCR    0x004  // Clock Control
#define SMHC_TMOUT    0x008  // Timeout
#define SMHC_CTYPE    0x00C  // Card Type (bus width)
#define SMHC_BLKSZ    0x010  // Block Size
#define SMHC_BYTCNT   0x014  // Byte Count
#define SMHC_CMD      0x018  // Command Register
#define SMHC_ARG      0x01C  // Command Argument
#define SMHC_RESP0    0x020  // Response word 0 (R[39:8])
#define SMHC_RESP1    0x024  // Response word 1 (R[71:40])
#define SMHC_RESP2    0x028  // Response word 2 (R[103:72])
#define SMHC_RESP3    0x02C  // Response word 3 (R[127:104])
#define SMHC_IMASK    0x030  // Interrupt Mask
#define SMHC_MINT     0x034  // Masked Interrupt Status
#define SMHC_RINT     0x038  // Raw Interrupt Status
#define SMHC_STATUS   0x03C  // Controller Status
#define SMHC_FTRGLVL  0x040  // FIFO Threshold Level
#define SMHC_FUNCSEL  0x044  // Function Select
#define SMHC_CBCR     0x048  // Command Byte Count Register
#define SMHC_BBCR     0x04C  // Buffer Byte Count Register
#define SMHC_DBGC     0x050  // Debug Control
#define SMHC_CSDC     0x054  // CRC Status Detect Control
#define SMHC_A12A     0x058  // Auto CMD12 Argument
#define SMHC_NTSR     0x05C  // New Timing Set Register
#define SMHC_HWRST    0x078  // eMMC Hardware Reset Register
#define SMHC_DMAC     0x080  // IDMAC Control Register
#define SMHC_DLBA     0x084  // DMA Link List Base Address
#define SMHC_IDST     0x088  // IDMAC Status
#define SMHC_IDIE     0x08C  // IDMAC Interrupt Enable
#define SMHC_FIFO     0x200  // FIFO Data Port

// ---- SMHC_GCTRL bits ----
#define GCTRL_SOFT_RST    (1U << 0)
#define GCTRL_FIFO_RST    (1U << 1)
#define GCTRL_DMA_RST     (1U << 2)
#define GCTRL_INT_EN      (1U << 4)
#define GCTRL_DMA_EN      (1U << 5)
#define GCTRL_DEBOUNCE_EN (1U << 8)
#define GCTRL_ACCESS_DONE_DIRECT (1U << 30)
#define GCTRL_HALT_FLOW   (1U << 31)  // FIFO access mode: 1=hold, 0=normal

// ---- SMHC_CLKCR bits ----
#define CLKCR_DIV_MASK    0xFF        // [7:0] clock divider
#define CLKCR_CARD_CLK_ON (1U << 16)  // card clock output enable
#define CLKCR_LOW_PWR     (1U << 17)  // low power mode (gate card clock when idle)

// ---- SMHC_CMD bits ----
#define CMD_IDX_MASK      0x3F        // [5:0] command index
#define CMD_RESP_EXP      (1U << 6)   // expect response
#define CMD_RESP_LONG     (1U << 7)   // long response (136-bit)
#define CMD_CHK_RESP_CRC  (1U << 8)   // check response CRC
#define CMD_DATA_EXP      (1U << 9)   // data expected
#define CMD_WRITE         (1U << 10)  // write (1) or read (0)
#define CMD_SEQ_SEND      (1U << 11)  // stream send
#define CMD_AUTO_STOP     (1U << 12)  // auto stop (CMD12) after data
#define CMD_WAIT_PRE      (1U << 13)  // wait for prev data done
#define CMD_ABORT_STOP    (1U << 14)  // abort/stop current data
#define CMD_SEND_INIT_SEQ (1U << 15)  // send init sequence (80 clocks)
#define CMD_UPCLK_ONLY    (1U << 21)  // update clock only (no command sent)
#define CMD_RD_CEATA      (1U << 22)
#define CMD_CCS_EXP       (1U << 23)
#define CMD_BOOT_MOD_MASK (3U << 24)
#define CMD_VOLT_SWITCH   (1U << 28)
#define CMD_USE_HWIN      (1U << 29)  // use hold register
#define CMD_START         (1U << 31)  // start command (poll until cleared)

// ---- SMHC_RINT / SMHC_MINT bits ----
#define RINT_RESP_ERR         (1U << 1)
#define RINT_CMD_DONE         (1U << 2)
#define RINT_DATA_OVER        (1U << 3)
#define RINT_TX_DATA_REQ      (1U << 4)  // TX FIFO needs data
#define RINT_RX_DATA_REQ      (1U << 5)  // RX FIFO has data
#define RINT_RESP_CRC_ERR     (1U << 6)
#define RINT_DATA_CRC_ERR     (1U << 7)
#define RINT_RESP_TIMEOUT     (1U << 8)
#define RINT_DATA_TIMEOUT     (1U << 9)
#define RINT_VOLT_CHANGE_DONE (1U << 10)
#define RINT_FIFO_RUN_ERR     (1U << 11)
#define RINT_HARD_WARE_LOCKED (1U << 12)
#define RINT_START_BIT_ERR    (1U << 13)
#define RINT_AUTO_CMD_DONE    (1U << 14)
#define RINT_END_BIT_ERR      (1U << 15)
#define RINT_SDIO_INT         (1U << 16)
#define RINT_CARD_INSERT      (1U << 30)
#define RINT_CARD_REMOVE      (1U << 31)

#define RINT_ERROR_BITS  (RINT_RESP_ERR | RINT_RESP_CRC_ERR | RINT_DATA_CRC_ERR | \
                          RINT_RESP_TIMEOUT | RINT_DATA_TIMEOUT | RINT_FIFO_RUN_ERR | \
                          RINT_HARD_WARE_LOCKED | RINT_START_BIT_ERR | RINT_END_BIT_ERR)

// ---- SMHC_STATUS bits ----
#define STATUS_RXWL_SHIFT    17         // [22:17] RX FIFO word count
#define STATUS_RXWL_MASK     (0x3FU << 17)
#define STATUS_TXWL_SHIFT    11         // [16:11] TX FIFO available words
#define STATUS_TXWL_MASK     (0x3FU << 11)
#define STATUS_FIFO_FULL     (1U << 3)
#define STATUS_FIFO_EMPTY    (1U << 2)
#define STATUS_CMD_FSM_BUSY  (1U << 13)
#define STATUS_CARD_DATA_BSY (1U << 9)
#define STATUS_DATA_FSM_BSY  (1U << 10)

// ---- SMHC_CTYPE (bus width) ----
#define CTYPE_1BIT    0x00000000U
#define CTYPE_4BIT    0x00000001U
#define CTYPE_8BIT    0x00010000U   // bit 16 = DDR 8-bit mode... actually:
// For sunxi SMHC: CTYPE[1:0]: 0=1-bit, 1=4-bit; CTYPE[16]: 1=8-bit
// (8-bit is bit 16 on most Allwinner SMHCs)

// ---- SMHC_NTSR (New Timing Set Register) ----
#define NTSR_MODE_SEL_NEW    (1U << 31)  // Use new timing mode

// ---- SMHC_FUNCSEL ----
#define FUNCSEL_CEATA_DEVICE  (1U << 1)
#define FUNCSEL_SEND_IRQ_RESP (1U << 0)
#define FUNCSEL_SDIO_IRQ_EN   (1U << 2)
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

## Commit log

2026-02-19 Initial commit: add project structure and BOM
    [cyberdeck_bom.xlsx]
2026-02-19 Add KiCad project
    [PortaRe0.kicad_pcb, PortaRe0.kicad_sch]
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2026-02-19 Add project docs and complete BQ25895 schematic
    - Add Claude/ folder (CONTEXT.md, PROGRESS.md, PROJECT_PLAN.md, chat_logs/)
    - Add KiCad hierarchical sheets (power, usb_hub, keyboard, audio)
    - Complete BQ25895 power sheet schematic
    - TS pin: REGN-R6(10kΩ)-TS-R7(10kΩ)-GND divider
    - BAT/SYS/PGND/PAD/SW/BTST/REGN/PMID/DSEL all connected
    - Decoupling caps on VBAT and VSYS
    [PortaRe0.kicad_sch, audio.kicad_sch, keyboard.kicad_sch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]
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2026-02-20 session06: TPS61023・AP2112K回路完成、VL812設計準備
    - Claude.md: セッション開始時に最新ログを必ず読むよう更新
    - PROGRESS.md: TPS61023・AP2112K完了に更新
    - chat_logs/2026-02-20_session06.txt: セッション06ログ追加
    - power.kicad_sch: TPS61023・AP2112K回路図追加
    [power.kicad_sch]
2026-02-20 session07: キーレイアウト確定・GPIO割り当て・power回路レビュー
    - キーレイアウト確定（66キー / 9×8マトリクス）、keyboard-layout.json追加
    - RP2040 GPIO割り当て確定（29本/30本）をPROJECT_PLANに追記
    - power回路レビュー（5V_SYS→パワーシンボル化、SCL/SDA/USB_DP/USB_DM→GlobalLabel）
    - .gitignoreに.claude/を追加
    [PortaRe0.kicad_sch, audio.kicad_sch, keyboard.kicad_sch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]
2026-02-20 session07: VL812 usb_hubシート完成・power回路修正
    - VL812 usb_hubシート完成
    - 電源ピン・デカップリングC配置
    - USB3.0 TX側ACカップリング・USB2.0直結
    - SPI Flash（W25Q32）接続・プルダウン
    - 水晶発振子（25MHz）追加
    - USBHOC1#/2# プルアップ追加（過電流誤検知防止）
    - power回路: SCL/SDA/USB_DP/USB_DM GlobalLabel追加
    - VL812データシート追加
    [power.kicad_sch, usb_hub.kicad_sch]
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2026-02-21 session08: RP2040 keyboardシート作業中（RP2040本体・QSPI Flash・クリスタル・GPIO完了）
    - RP2040本体配置・電源デカップリング完了
    - VREG_IN/VOUT/DVDD接続完了
    - クリスタル（Crystal_GND23 / 12MHz / 15pF×2）接続完了
    - QSPI Flash（W25Q32）接続完了（/CS 10kΩプルアップ・BOOTSEL 1kΩ引き出し）
    - RUN 10kΩプルアップ完了
    - SWD/SWCLK Global Label引き出し完了
    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
    [keyboard.kicad_sch]
2026-02-21 Update BOM: session07-08の確定内容を反映
    - RP2040用W25Q32（QSPI接続）を追加（VL812用と合計2個）
    - クリスタル（RP2040用）X322512MOB4SI C70565を追加
    - キースイッチ数を60→68個（66キー+ショルダー2個）に修正
    - ダイオード数を62→66個に修正
    - キルスイッチ・モーメンタリスイッチを明示
    - LED×4・LED電流制限抵抗の用途を詳細化
    - カテゴリ色分け・オートフィルタ付きxlsxに再構成
    [cyberdeck_bom.xlsx]
2026-02-21 Add SKRPABE010 C115360 to BOM and update counts
    - Alps SKRPABE010: C115360確定（JLCPCB在庫54355個確認済み）
    - キースイッチ数: 60→68個（66キー+ショルダー2個）
    - ダイオード数: Claude.md内を62→66個に修正
    [cyberdeck_bom.xlsx]
2026-02-21 Change analog stick to 3DS slide pad, add FPC connector
    - アナログスティック: PSP互換品 → 3DSスライドパッド（感触優先）
    - FPCコネクタ追加: AFC01-S06FCA-00 (C262655) / 6P 0.5mm Bottom Contact ZIF
    - BOM・Claude.md・PROJECT_PLAN.md 全更新
    - 秋月JT8P: キャップ非互換のため不採用
    [cyberdeck_bom.xlsx]
2026-02-21 Fix 3DS slide pad FPC connector: 6P/0.5mm -> 4P/1.0mm
    - FPCコネクタ修正: C262655(AFC01 6P/0.5mm) → C3170007(Molex 5034800440 4P/1.0mm)
    - 3DSスライドパッドは4ピン1.0mmピッチが正しい仕様
    - ピンアサイン確定: GND / X軸 / VCC / Y軸
    - VCC: 3.3V直結OK（内部ポテンショメータのため電圧スケールのみ変化）
    [cyberdeck_bom.xlsx]
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2026-02-21 Fix key count: 66 -> 63, fix keyboard-layout.json
    - KLEを正確にパースして確認: 63キーが正しい数
    - SKRPABE010: 68個→63個
    - 1N4148W: 66個→63個
    - keyboard-layout.json: 壊れていた外側[]を修正
    - matrix.md: 合計キー数を63に修正
    - BOM/Claude.md/PROJECT_PLAN.md全て更新
    [cyberdeck_bom.xlsx]
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2026-02-21 Complete keyboard sheet: analog stick, LED circuits
    - アナログスティック回路: Molex 5034800440 FPCコネクタ
    Pin1=GND / Pin2=GP27(X) / Pin3=+3V3 / Pin4=GP28(Y)
    デカップリング 100nF
    - LED回路 x3:
    +3V3 - 330Ω - LED_CHG(GP24) / LED_FULL(GP25) / LED_ACT(GP26)
    アクティブLow
    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
    [keyboard.kicad_sch]
2026-02-21 Fix dangling wires in keyboard sheet
    端の余り配線を修正
    [keyboard.kicad_sch]
2026-02-21 Update docs, add CSV to git, fix PROGRESS.md
    - README.md: 最新状態に全面更新（63キー/3DSスティック/C番号一覧追加）
    - Claude/PROGRESS.md: keyboardシート完成を反映・購入済みリスト更新・TBD整理
    - .gitignore: *.csv除外を解除（bom/cyberdeck_bom.csvをバージョン管理対象に）
    - bom/cyberdeck_bom.csv: 新規追加（別PCでの参照用）
    - kicad/usb_hub.kicad_sch: 変更分を取り込み
    [cyberdeck_bom.csv, usb_hub.kicad_sch]
2026-02-21 session09: audio.kicad_sch作業・各種確定事項まとめ
    - BOM整備: 全セッション確定部品を集約、CSV/xlsx更新
    - アナログスティック: 3DSスライドパッドに決定
    - FPCコネクタ: Molex 5034800440(C3170007) 4P/1.0mm ZIFに確定
    - VCC 1.8V問題: 3.3V直結でOK（内部はポテンショメータ）
    - キーマトリクス: 63キー確定、matrix.md・info.json作成
    - keyboard.kicad_sch完成（キーマトリクス/アナログスティック/LED）
    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
    [audio.kicad_sch]
2026-02-21 session10: audio sheet完成、USB命名規則統一、TESTEN修正
    - audio.kicad_sch: RP2040 #2追加、MAX98357A×2、PCM5102APWR、TPA6132A2RTER配線完了
    - PCM5102APWR/TPA6132A2RTERシンボル・フットプリント追加
    - I2S共有バス(BCLK/LRCLK/SDIN)でスピーカー・イヤホン共通接続
    - GPIO割り当て: GP0-2=I2S, GP3=SD_MODE, GP4=XSMT, GP5=HP_EN, GP6=HP_DET
    - USB命名規則統一: RP2040 #1→USB2_RP_DP/DM, RP2040 #2→USB2_RP_DP2/DM2
    - VL812 USBHP4にUSB2_RP_DP2/DM2追加
    - RP2040 #1/#2のTESTEN→GND修正
    - BQ25895 D+/D-はUSB_DP/DM(充電用USB-C)で確定
    [audio.kicad_sch, keyboard.kicad_sch, power.kicad_sch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]
2026-02-21 Fix: Geminiレビュー指摘事項の修正
    - audio.kicad_sch: TPA6132A2 HPVSSピンのGND直結を修正（1µFコンデンサ追加）
    - audio.kicad_sch: MAX98357A U8のSD_MODEに220kΩ直列抵抗追加（Right ch設定）
    - keyboard.kicad_sch: LED回路の向きと接続を修正
    - RP2040 #1/#2 TESTEN→GND修正済み確認
    [audio.kicad_sch, keyboard.kicad_sch]
2026-02-21 Add TPS2052BDR/USBLC6-2SC6ライブラリ、PROGRESS.md更新
    - TPS2052BDR (C130049) シンボル/フットプリント追加（USBパワースイッチ）
    - USBLC6-2SC6 (C7519) シンボル/フットプリント追加（USB ESD保護）
    - PROGRESS.md: C番号リスト追記
    - PROGRESS.md: GPIO割り当て記載修正（LED: GP21-23、RP2040 #2: GP0-6）
2026-02-21 Save: usb_hub.kicad_sch中間保存
    [usb_hub.kicad_sch]
2026-02-21 Fix: TPS2052B→TPS2042BDRに変更（Active-Low対応）
    - VL812の/UBHPEはActive-Low仕様のためTPS2042BDR(C138720)に変更
    - TPS2042BDRシンボル追加
    - PROGRESS.md: C番号リスト更新
2026-02-21 Docs: session11決定事項更新
    - TPS2042BDR/USBLC6-2SC6/TPS61023 #2構成確定
    - VL812 downstream割り当て確定（Port1=USB-A / Port2=USB-C / Port3=RP2040#1 / Port4=RP2040#2）
    - RP2040 #1 GP24=USB_VBUS_EN追加
    - RP2040 #2 GPIO割り当て詳細更新（GP4=XSMT / GP5=HP_EN / GP6=HP_DET）
    - 電源フロー更新（TPS61023 #1/#2分離）
    - BQ25895 SYSライン大電流注意事項追加
    - VBUSDET/EXTPWRON修正方針記載
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2026-02-22 usb_hub: TPS2042BDR/USBLC6-2SC6/VBUSDET/EXTPWRON実装
    - TPS2042BDR配置・配線（/USBHPE1/2B、/USBHOC1/2接続）
    - TPS61023 #2追加（HUB_5V生成 / EN=USB_VBUS_EN）
    - USBLC6-2SC6 × 2配置（Port1=USB-C / Port2=USB-A）
    - VL812 VBUSDET: 56kΩ+100kΩ分圧（USB2_UP_VBUSから）
    - VL812 EXTPWRON: 10kΩ→3V3_HUBプルアップに変更
    - Net Label命名: HUB_USBC_DP/DM / HUB_USBA_DP/DM
    - VL812水晶負荷コンデンサC44/C45 = 18pF設定
    - Port1/2割り当て修正（Port1=USB-C / Port2=USB-A）
    - Docs: Claude.md/PROGRESS.md更新
    [usb_hub.kicad_sch]
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2026-02-23 Docs: session15終了処理・PROGRESS/index更新・powerシート修正完了
    - powerシートGemini評価検証・修正完了
    - L1接続変更: +BATT → VSYS (NVDC正しいトポロジー)
    - D1極性修正・R3 10kΩ→330Ω
    - SW1保護: BAT54(C466635)をGP20→ENノード間に挿入
    - ENノード10µFラッチキャップ追加
    - SW_DET回路追加: SW1→10kΩ分圧→GP25
    - C5 100nF→4.7µF / C6 4.7µF→10µF / SYSキャップ+10µF
    - BAT54(C466635)シンボル/フットプリント追加
    - GP25割り当て: 予備→SW_DET
    [power.kicad_sch]
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2026-02-23 Docs: session18終了処理・PROGRESS/index更新・connectorsシート設計方針確定
    - J_HDMI_CTRL: 24pin FPC 0.5mm (C2856805) ライブラリ取得・配置方針確定
    - SBC接続: サブ基板→FPCに変更・スティフナーにMicro HDMIオス+USB-Cオス直付け方針
    - connectors.kicad_sch 追加
    [PortaRe0.kicad_sch, audio.kicad_sch, connectors.kicad_sch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]
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2026-02-25 KiCad: connectorsシート更新（J_HDMI_CTRL・J_SBC_USB1・J_SBC_USB2配置・配線）
    [connectors.kicad_sch, usb_hub.kicad_sch]
2026-02-25 Fix: connectorsシートファイル名大文字C統一（Linux case-sensitive対応）
    [Connectors.kicad_sch]
2026-02-25 Docs: session21終了処理・PROGRESS/index更新・connectorsシート完成・ERC対処
    - connectors シート完成（J_SBC_HDMI / J_FAN配置完了）
    - hdmi_adapter シート新設（別基板 / J_MICROHDMI Conn_02x08 + C2856805）
    - J_FAN: F16FB選定（16×16×4.5mm 5V）/ BSS138回路 / FAN_PWM GlobalLabel
    - 全シートERC実施・対処完了（VL812未接続ピン / SWD NC / DC10FB追加等）
    [Connectors.kicad_sch, PortaRe0.kicad_sch, audio.kicad_sch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]
2026-02-26 KiCad: usb_adapterシート新設・connectorsシート整理
    - usb_adapter.kicad_sch 新設（J_SBC_USB1/J_SBC_USB2を移動）
    - FPCテール直挿し方式採用（中間コネクタなし）
    - FPC 24pin ピン割り当て確定（差動ペア間GND配置）
    - connectorsシートにC2856805（ZIF）×2追加
    - .gitignore: kicad/PDF/ を除外に追加
    [Connectors.kicad_sch, PortaRe0.kicad_sch, hdmi_adapter.kicad_sch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]
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2026-02-26 KiCad/Docs: powerシートL1値2.2μH更新・README全面更新
    - power.kicad_sch: L1インダクタ値を2.2μHに更新（BQ25895 TI例参照）
    - README: バッテリー型番/容量修正・全シート完成状態に更新・部品C番号一覧追記
    [power.kicad_sch]
2026-02-26 Docs/KiCad: session24終了処理・チェックシート作成・回路修正
    - Claude/checklists/ 新規作成（IC設計レビュー用 01〜10）
    - BQ25895修正: C5(4.7nF→4.7µF) / CE(3V3→GND) / QON(GND→NC)
    - TPS61023修正: R_TOP(910kΩ→750kΩ, 5.1V) / SW2をVSYS直列に変更 / usb_hub SW4削除
    - AP2112K: バイパスキャップ1µF→10µF
    - PROGRESS.md・index.md更新
    [power.kicad_sch, usb_hub.kicad_sch]
2026-02-27 KiCad/Docs: チェックシート04-06完了・回路修正(session25)
    - VL812: W25Q32 /CS GNDプルダウン→3V3_HUBプルアップ修正
    - RP2040 #1/#2: クリスタルシンボル GND23→GND24 修正
    - RP2040 #1: GP24/GP25 接続追加
    - チェックシート04(VL812)/05(RP2040 kbd)/06(RP2040 audio)記入完了
    [audio.kicad_sch, keyboard.kicad_sch, power.kicad_sch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]
2026-02-27 Docs: session25終了処理・PROGRESS/index更新
    チェックシート04-07完了・VL812/RP2040回路修正記録
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2026-02-27 KiCad/Docs: audioシートバイパスキャップ追加・MAX98357Aチェックシート更新
    - audio.kicad_sch: MAX98357A (U9/U15) VDDバイパスキャップ C115/C116 (10µF) 追加
    - audio.kicad_sch: C99値 1µF→10µF、他コンデンサ値更新、GNDPWRシンボル移動
    - 07_MAX98357A_checklist.txt: ピン確認結果記入 (ok/? マーク)
    - CONTEXT.md: BOM更新・整合チェック行テキスト修正
    [audio.kicad_sch]
2026-02-27 KiCad/Docs: チェックシート09-10完了・回路修正(session27)
    - 09_TPA6132A2: 入力ピン接続逆転修正(INL-/INR-が信号入力)
    ACカップリング2.2µF / EMIフィルタ470Ω+2.2nF / G0=+3V3(0dB) / HPVDD→2.2µF
    - 10_TPS2042BDR_USBLC6: 全ピンOK・修正なし
    - チェックシート照合 全10IC完了 → Phase 3 PCBレイアウトへ
    - PROGRESS.md / index.md 更新
    [audio.kicad_sch]
2026-02-28 Docs/KiCad: session28終了処理・パッシブ部品C番号確定・インダクタ確定
    - passive_parts.txt 新規作成（抵抗15種・コンデンサ8種・インダクタ3種）
    - インダクタC番号確定: L1=C408335 / L2,L4=C3002557 / L3=C19274352
    - usb_hub 10pFキャップ10本削除（KiCad済み）
    - PROGRESS.md・index.md 更新
    [PortaRe0.csv, usb_hub.kicad_sch]
2026-02-28 KiCad: 未コミットの回路図変更を追加
    [Connectors.kicad_sch, power.kicad_sch]
2026-03-02 Docs/KiCad: session29終了処理・LED/スイッチ確定・audio/power修正
    [audio.kicad_sch, power.kicad_sch]
2026-03-02 KiCad/Docs: session30終了処理・フットプリント割り当て完了・コネクタ確定
    - フットプリント全割り当て完了（全シート）
    - 新規フットプリント追加: SKSCLBE010/SKRPABE010/クリスタル/インダクタ×3/JST PHコネクタ×2
    - コネクタ確定: バッテリー=B8B-PH-K-S(C157974) / SPK+FAN=B2B-PH-K-S(C131337)
    - J5(hdmi_adapter): PinHeader_2x08_P2.00mm_Vertical
    - Claude.md: ファン制御 RP2040 #1 GP26→BSS138→J6 に更新
    - passive_parts.txt: コネクタセクション追加
    [Connectors.kicad_sch, audio.kicad_sch, hdmi_adapter.kicad_sch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]
2026-03-04 Docs/KiCad: session31終了処理・PROGRESS/index更新
    - キルスイッチ確定: MSK12C02(C431540) EN制御方式・KiCad配線完了
    - ヘッドフォンジャック確定: PJ-307C(C16684) TH / 配線・pull-up完了
    - J4バッテリーコネクタ: S8B-PH-K-S-LF-SN(C157915) 水平型確定
    - BOM Y4フットプリント修正
    - 新規ライブラリ追加: MSK12C02/PJ-307C/S8B-PH-K-S他
    - Phase 2 回路設計 全シート完了
    [Connectors.kicad_sch, PortaRe0.csv, PortaRe0.kicad_sch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]
2026-03-04 Docs: session32終了処理・ドキュメント構成整理・session_close.py作成
    [PortaRe0.kicad_pcb, audio.kicad_sch, hdmi_adapter.kicad_sch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]
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2026-03-05 Docs: session33終了処理・J4コネクタ確定・pcb_layout_notes作成
    [PortaRe0.csv, PortaRe0.kicad_pcb]
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2026-03-07 Docs: session34終了処理・0402化確定・ディスプレイ調査・PCBレイアウト進行中
    [Connectors.kicad_sch, PortaRe0.csv, PortaRe0.kicad_pcb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]
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2026-03-08 Docs: session35終了処理・TPS61023 FB接続ミス確認・M.2クリアランス1.1mm
    [PortaRe0.kicad_pcb, usb_hub.kicad_sch]
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2026-03-11 Docs: session37終了処理・部品配置完了・ルーティング開始・FPC給電ピン修正
    [Connectors.kicad_sch, PortaRe0.kicad_pcb]
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2026-03-15 Docs: session39終了処理・MAX98357A I2S・BOOTSEL・M.2 PCIe配線完了
    [PortaRe0.kicad_pcb]
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
